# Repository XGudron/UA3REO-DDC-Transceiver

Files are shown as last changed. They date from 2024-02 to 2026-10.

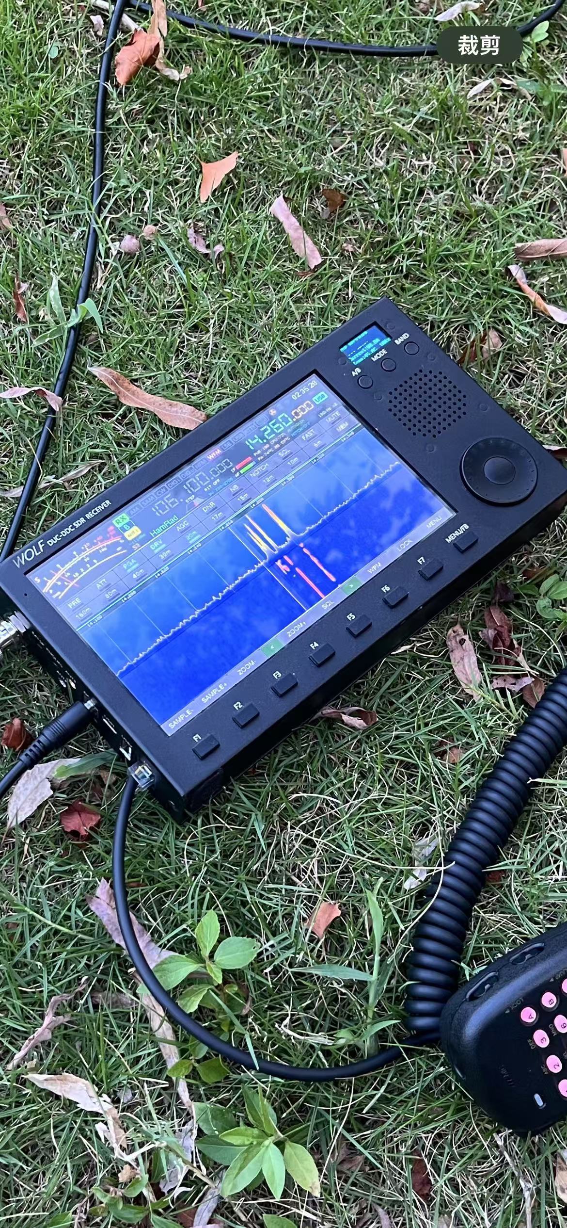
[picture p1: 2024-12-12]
Schematic/Wolf-DK102/Photos/20241206171248.jpg

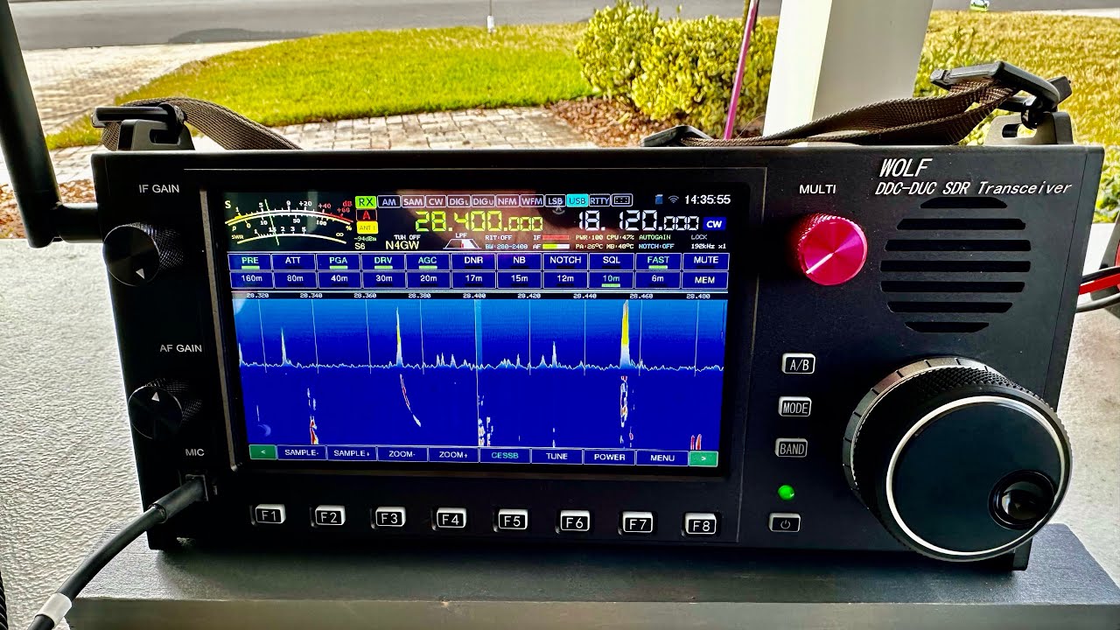
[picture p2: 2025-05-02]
Schematic/Wolf-BA7LJL/Photos/Wolf.jpg

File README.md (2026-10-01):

# Transceiver "Wolf"
DDC-DUC SDR Transceiver project https://ua3reo.ru/tag/transiver-ua3reo/

* Community telegram channel: https://t.me/TRX_Wolf
* На русском https://github.com/XGudron/UA3REO-DDC-Transceiver/blob/master/README.ru-RU.md

## Principle of operation

The RF signal is digitized by a high-speed ADC chip and fed to an FPGA processor. <br>
It performs DDC / DUC conversion (digital frequency shift down or up the spectrum) - by analogy with a direct conversion receiver. <br>
The I and Q quadrature signals from the conversions are fed to the STM32 microprocessor. <br>
It filters, (de) modulates and outputs audio to an audio codec / USB. It also handles the entire user interface. <br>
When transmitting, the process occurs in the opposite order, only at the end of the chain there is a DAC, which converts the digital signal back to analog RF. <br>

## Specifications TRX Wolf-2

* Receiving frequencies: 0 Mhz - 2700 Mhz, band filters for ham bands (23cm included)
* Transmission frequencies: 0 MHz - 2700 Mhz, amplifiers for ham bands (23cm included)
* TX power: 100W (HF), 50W+ (VHF/UHF), 15W+ (SHF)
* Two antenna inputs on HF, four for VHF/UHF/SHF/Wideband
* Automatic antenna tuner
* Modulation types (TX / RX): CW, LSB, USB, AM, FM, WFM, DIGI
* LNA, Preamplifier
* Adjustable attenuator 0-31dB
* Band pass filters
* ADC dynamic range (16 bit) ~100dB
* Supply voltage: 13.8V

## Specifications TRX Wolf-1

* Receiving frequencies: 0 MHz - 750 MHz with fading each 61.44 MHz (above 145 MHz - without input filters)
* Transmission frequencies: 0 MHz - 150 MHz with fading on 110 MHz
* TX power (QRP version): 7W+ (HF), 5W (VHF)
* TX power (QRP++ DB5AT version): 20W (HF), 7W (VHF)
* TX power (RU4PN/WF-100D version): 100W (HF), 50W+ (VHF)
* It is possible to install a VHF board from Wolf-2 to expand the VHF characteristics
* Two antenna inputs
* Modulation types (TX / RX): CW, LSB, USB, AM, FM, WFM, DIGI
* LNA, Preamplifier
* Adjustable attenuator 0-31dB
* Band pass filters
* ADC dynamic range (16 bit) ~100dB
* Supply voltage: 13.8V (overvoltage and polarity reversal protection)
* Consumption current when receiving: ~0.7A (3'2 QRP), 0.9A (7' BIG)
* Current consumption during transmission: ~2.5A+ (QRP), 15A+ (BIG)
* Support for different displays: RA8875/HX8357B/HX8357C/ST7789/ST7796S/ST7735S/ILI9341/ILI9481/ILI9486/ILI9488

## Transceiver Features

* Panorama (spectrum + waterfall) up to 384 kHz wide
* Panorama tweaks and themes
* Dual receiver (mixing A + B or A&B audio in stereo)
* Adjustable bandwidth: HPF from 0Hz to 2700Hz, LPF from 100Hz to 20kHz
* Integrated SWR/power meter
* SWR Graphs
* Spectrum analyzer
* Automatic and manual Notch filter
* Switchable AGC (AGC) with adjustable attack rate
* Range map, with the ability to automatically switch modes
* Digital Noise Reduction (DNR), Pulse Noise Reduction (NB)
* CAT virtual COM port (TS-2000 / FT-450 emulation, DTR - CW)
* USB operation (audio transmission, IQ, CAT, KEY, PTT)
* Self-control, CW gauss filter
* SSTV/RDS/CW decoder
* FT8/FT4/FT2 decoder/encoder
* RTTY/PSK31 decoder/encoder
* Sending a log of QSO and data to the log https://allqso.ru/ and https://www.wavelog.org/
* WSPR Beacon
* VOX / USB-VOX
* Equalizer TX/RX, reverber, various DSP compressors, etc.
* SSB/FM Scanner mode, fast switching between CW signals
* Support SDHC/SDSC/SDXC memory cards up to 16Gb
* WAV files radio recording and playback, broadcast recorded message
* AGC takes into account the characteristics of human hearing (K-Weighting)
* TCXO frequency stabilization (it is possible to use an external clock source, such as GPS)
* WiFi operation: Time synchronization, external WiFi services
* Tangent support Yaesu MH-48 and MH-36
* Hardware self-testing
* CTCSS subtones and 1750 kHz start tone for opening repeaters
* Assistance for visually impaired operators
* Digital Pre Distortion
* CW-trainer
* Support for external PTT-sequencer control via CAT and transceiver
* And other... (see menu)

### RF Parameters

Sensitivity at 10 dB SNR, LNA enabled:

* <150 MHz | -131 dBm | 63.0 nV
* 435 MHz | -121 dBm | 0.2 uV

Out-of-band emissions:

* 14 MHz -69 dBc
* 28 MHz -63 dBc
* 145 MHz -48 dBc -55 dBc

## Build

I ordered the boards in the Chinese service JLCPCB, they and their schemes are in the Scheme folder. <br>
After assembly, you need to flash FPGA and STM32 chips. <br>
If necessary, calibrate the transceiver through the appropriate menu <br>
WiFi module ESP-01 must have fresh firmware from Dropbox<br>

## Functional buttons

| Button | Short press | Long press |
|---|---|---|
| **A/B**, **XFC** | Select VFO A or B (XFC - while pressing) | Same |
| **A<>B**, **A / B** | Swap VFO A and B | Same |
| **B=A**, **A->B** | Copy active VFO to the other | Same |
| **SPLIT** | Toggle split | Same |
| **DOUBLE** | Toggle dual RX | Switch dual-RX mix: A&B stereo ↔ A+B |
| **POWER** | RF power window / menu | Toggle external PA mode |
| **CESSB** | Toggle CESSB | CESSB settings menu |
| **DPD** | Toggle digital pre-distortion | Same |
| **PRE** | Toggle LNA | Same |
| **ATT** | Toggle attenuator | Step ATT level (dB) |
| **NB** | Cycle NB: off → NB1 → NB2 → both | NB1/NB2 settings menu |
| **NOTCH** | Toggle auto notch | Manual notch |
| **DNR** | Cycle DNR type (0…3) | Same |
| **AGC** | Toggle AGC | Same |
| **FAST** | Toggle fast tuning | Same |
| **SQL** | Toggle squelch | Squelch level menu |
| **RIT** | Toggle RIT | XIT / Reset RIT |
| **XIT** | Toggle XIT | RIT / Reset XIT |
| **MONI** | Toggle self-hear | Self-hear settings for current mode |
| **VOX** | Toggle VOX | VOX settings |
| **SCAN** | Toggle scanner | Same |
| **AUTOGN** | Toggle auto RF gain | Same |
| **BANDMP** | Toggle band map | Same |
| **BAND− / BAND+** | Previous / next band | The same, but in reverse |
| **MODE− / MODE+** | Previous / next mode | The same, but in reverse |
| **FFT− / FFT+** | Narrower / wider panorama | Same |
| **HPF** | High-pass filter menu | Same |
| **BW** | RX filter bandwidth menu | Same |
| **LENS** | Toggle FFT zoom (lens) | Same |
| **FILT 1…3** | Load filter preset | Save current filters to preset |
| **BALANCE** | A/B audio balance menu | Same |
| **ANT** | Cycle TX/RX antenna | Same |
| **RXANT** | Toggle extra RX antenna (Wolf-2) | Same |
| **TUNE** | ATU enable | Tune / carrier |
| **ATU RST** | Reset ATU memory for band | Same |
| **SWR** | SWR analyzer for current band | Same |
| **REPIT** | Toggle repeater mode | Repeater offset menu |
| **BREAKIN** | Toggle CW break-in (key+PTT) | CW PTT type menu |
| **SNAP < / SNAP >** | Snap frequency to grid | Auto-snap on/off |
| **M>VFO / VFO>M** | Read memory channel (MEMO mode) | Same / write channel |
| **MEMORY** | Memory channels window | Same |
| **REC** | Start/stop SD recording | Same |
| **PLAY** | Play last recording | Transmit last recording on air |
| **FILES** | SD file manager | Same |
| **SERVICE** | Services menu | Save screenshot to SD |
| **MENU** | System menu | Close all / hidden menu |
| **LOCK** | Lock front panel | Same |
| **FT8** | FT8 service | Same |
| **WPM** | CW speed menu | Same |
| **PTT OFF** | Toggle TX inhibit | Same |
| **TX** | Soft PTT | Same |
| **ACCESS** | Speak frequency and mode (TTS) | Same |
| **EQ** | TX/RX equalizer window | Same |
| **SLEEP** | LCD sleep mode | Same |
| **DXCALL** | Correspondent / QSO info window | Same (touch models) |
| **CW KEYB** | CW/RTTY/PSK message broadcast window | Same |
| **MACROS 1…8** | Run CW/SSB/RTTY/PSK macro | Edit macro; long on Macro 1 — Auto CQ toggle |
| **NONE** | Not assigned | — |

Assignments are editable in *Settings → Front buttons*.

## Settings

### Operator

* **Accessibility** - Assistance to visually impaired operators, telegraphing current transceiver parameters into the speaker when switching
* **Callsign** - Operator callsign
* **Locator** - User QTH locator
* **Operator Name** - Operator name
* **QTH xxx** - Setting the Latitude\Longitude\Altitude of your location to calculate the passage of satellites
* **Timezone** - Time zone
* **Tropo Region** - Region for tropospheric forecast https://www.dxinfocentre.com/tropo.html 
* **URSI Code** - Ionogram URSI Code https://digisonde.com/index.html#stationmap-section

### TRX Settings

* **ANT type** - Select antenna type (TX/RX or RX only)
* **Band Map** - Band Map, automatically switches mode depending on the frequency
* **Beeper** - Beep on key press
* **Channel Mode** - Channel frequency mode (for LPD/PMR and etc.)
* **Custom Transverter** - Enable external transverter on non-ham band (just offset display frequency)
* **Debug Type** - Output of debug and service information to USB / UART ports
* **Debug Console** - Display console with system debug information (copy of what is sent to debug COM port)
* **Encoder Accelerate** - Accelerate encoder on fast rates
* **ENC2 Priority enbl** - Enables the encoder priority function, which is automatically switched to after 30 seconds of inactivity
* **ENC2 Priority** - Selection of the secondary encoder priority function
* **FAN Always on** - Forced activation of the fan (for heavy operating conditions)
* **Fine RIT Tune** - Fine or coarse tuning for RIT/XIT (encoder or resistor)
* **Freq Step xxx** - Frequency step by main encoder in each mode, Hz
* **FAST Step Multiplier** - Frequency step multiplier for FAST mode
* **ENC2 Step Mult** - Frequency step multiplier for ENC2 rotation (for CW/SSB)
* **Notch Step** - Frequency step of manual notch filter
* **Full Duplex** - Full duplex RX+TX mode
* **SPLIT type** - In DX mode - the TX frequency is controlled, in the CrossBand mode synchronously for two VFOs, for Free only the RX frequency changes
* **RIT Interval** - Offset range RIT (+ -)
* **XIT Interval** - Offset range XIT (+ -)
* **Lock in IQ Mode** - Lock TRX in IQ Mode for external program
* **Transverter XXcm** - Enable external ham band transverter support
* **Wolf Interface I2C** - Connect TRX to external I2C interface device (See STUFF folder for example)

### FILTERS Settings

* **Adaptive FM Filter** - Automatic adjustment of the width of the NFM filter relative to the strength of the received signal (VHF)
* **AM/FM/CW/SSB LPF Stages** - Adjusting the slopes of the LPF filters in different modes
* **CW LPF Pass** - LPF cutoff frequency when working in CW
* **CW Gauss filter** - Use a filter with a Gaussian distribution (for CW), accepts only the peak in the center of the BW
* **CW Gauss Q** - Quality of Gauss filter
* **DC Filter RX** - Enable DC corrector filter on receive path (cuts off the constant component and part of the low frequencies)
* **DC Filter TX** - Enable DC corrector filter on transmit path (cuts off the constant component and part of the low frequencies)
* **DeEmphasis FM, us** - Setting up a filter to reduce high-frequency noise when receiving NFM/WFM
* **DIGI LPF Pass** - LPF cutoff frequency when working in DIGI
* **FM LPF Pass** - LPF cutoff frequency when working in FM
* **SSB HPF Pass** - HPF cutoff frequency when operating in SSB
* **SSB LPF Pass** - LPF cutoff frequency when operating in SSB
* **NOTCH Filter width** - Cutting width of Manual Notch filter
* **RX Filter Margin** - Filter width relative to carrier signal frequencies

### RX Settings

* **ADC Dither** - Enable ADC dither for receiving weak signals
* **ADC Driver** - Turn on the preamplifier-ADC driver
* **ADC Preamp** - Turn on the preamplifier built into the ADC
* **ADC Randomizer** - Enables ADC digital line encryption
* **AGC Gain target, LKFS** - Maximum AGC gain (Maximum volume with AGC on)
* **AGC Threshold** - Enabling the AGC opening threshold
* **Att step, dB** - Attenuator tuning step
* **Attenuation, dB** - Current attenuation
* **Auto Snap** - Automatically track and snap to near signal frequency (CW mode)
* **AutoGainer** - Automatic ATT / PREAMP control depending on the signal level on the ADC
* **CODEC Gain** - Adjusting AF gain in audio codec
* **Dual RX** - Activating the dual receiver
* **Dual RX Balance** - Channels balance in dual RX modes
* **Dual RX Type** - Dual receiver signal mixing type: A+B, A&B, A Only, B Only
* **Dual RX IQ** - Specifies the source (VFO) of the IQ signal to send to the USB audio card in Dual RX mode
* **DNR xxx** - Digital squelch adjustment
* **Squelch** - Enable SSB/AM/CW/FM Squelch
* **FM Demodulator** - Algorithm of FM demodulator operation
* **FM Squelch level** - FM squelch level
* **IF Gain, dB** - IF gain
* **Noise Blanker** - Activating the Surge Suppressor
* **NB Threshold** - Threshold of Noise blanker
* **Free tune** - Allows you to move the reception frequency across the spectrum without changing the center frequency of the spectrum itself
* **Center After Idle** - Center the spectrum with Free Tune active after 20 seconds of inactivity
* **RX AUDIO Mode** - Audio lines control: Stereo\Left\Right
* **RX AGC Hold time** - Time before release of AGC gain in signal peaks, ms
* **RX AGC Hold limit** - Burst limit for AGC delay time
* **RX AGC Hold step up** - AGC Delay Time Step on Peaks
* **RX AGC Hold step down** - AGC Delay Falloff Step at Peaks
* **RX AGC Max gain** - Limit of AGC gain, dB
* **RX AGC Speed** - AGC (automatic signal level control) response speed for reception (more-faster)
* **TRX Samplerate** - Max FFT/samplerate on SSB/DIGI/etc modes
* **FM Samplerate** - Max FFT/samplerate on NFM/WFM mode
* **CW Samplerate** - Max FFT/samplerate on CW mode
* **VAD SQL Threshold** - VAD voice detector threshold (noise SQL for SSB mode and SCAN mode)
* **Volume step** - AF gain step by ENC2 (X1, Lite)
* **Volume** - AF gain
* **WFM Stereo** - select WFM stereo or mono decoder
* **WFM Stereo Modulation** - Stereo FM sub-carrier level

### TX Settings

* **ADC Shutdown** - Turn off the ADC while TX
* **AGC MaxGain** - Maximum AGC gain
* **AGC Speed** - TX compressor response speed for transmission (more-faster)
* **TX AGC Clipping** - Determines whether the AGC will sharply limit the signal gain during large amplitude spikes
* **TUNER Enabled** - Turning on the antenna tuner
* **TUNER Enbl per band** - Save tuner on/off state for each band independently
* **ATU Cap** - Tuner Capacitance Combination
* **ATU Enabled** - Turning on the automatic antenna tuner
* **ATU Ind** - Combination of tuner inductances
* **ATU T** - Tuner capacitive arm position
* **ATU Mem step, kHz** - Step of saving tuner values for frequencies into memory
* **ATU AutoRun** - Automatic ATU start at high SWR
* **CESSB** - Enable controlled-envelope single-sideband modulation
* **CESSB Compress, dB** - Signal pre-amplification level before compression in CESSB
* **CTCSS Frequency** - Transmit FM CTCSS sub-tone frequency
* **DRV Shutdown** - Turn off the DAC driver while RX
* **EXT PA mode** - Operating mode with external amplifier, separately installed RF Gain calibrations are used
* **EXT PTT in PA mode** - Send PTT signal to External connector only in "EXT PA mode"
* **INT ATU in PA mode** - Determines whether to enable the internal tuner in "EXT PA Mode"
* **EXT ATU in PA mode** - Determines whether to block the external PA while the external ATU is being tuned
* **Input Auto Switch** - Auto input switch (PTT - mix, CAT - USB)
* **Input Type** - Select audio input (microphone, line in, USB)
* **LINE Gain** - Line input codec gain
* **MIC Boost** - +20db hardware mic amplifier
* **MIC Gain** - Microphone gain
* **MIC DSP Type** - Type of DSP processing of the microphone path: None, Downward Expander, Upward/Downward Compressor, Limiter, Noise Gate
* **MIC DSP Threshold** - Threshold of selected microphone DSP processing
* **MIC DSP Ratio** - Level of slope for selected microphone DSP processing
* **MIC Reverber** - Microphone reverberator level
* **Power for each band** - Save power settings for each band individually
* **Power for each mode** - Save power settings for each mode individually
* **RF Power** - Transmission power, %
* **RF Power ENC3 step** - Power adjustment step by encoder (Wolf-2)
* **Pwr by main ENC** - Allow power change by main encoder in TX mode
* **Repeater Mode"** -  Operation mode via repeater
* **Repeater offset, kHz** -  Transmission frequency offset in repeater mode
* **Repeater tone** - Adds 1750Hz tone at the beginning of transmission to open the repeater (in FM mode)
* **SelfHear CW** - Self-control CW Gain
* **SelfHear on SSB** - Self-monitoring for SSB/AM modes, always active for DIGI/RTTY/LOOPBACK
* **SelfHear VOICE** - Self Hearing volume at voice modes relative to the overall transceiver volume
* **SelfHear DIGI** - Self Hearing volume at DIGI modes relative to the overall transceiver volume
* **SWR Hold Peaks** - Hold the power meter at signal power peaks
* **Tune Type** - TUNE operating mode (carrier, two signal tone, multi-tone, white noise)
* **TOT, min** - Protection of the transmitter from long-term operation, automatic shutdown after time has elapsed
* **TX Inhibit** - Prohibit switching to TX
* **Use Keyer for RTTY** - Enable use of CW key (or USB-COM line of keyer) for keying in RTTY mode
* **VOX** - TX Voice activation
* **VOX Threshold, dBFS** - VOX Threshold, dBFS
* **VOX Timeout, ms** - VOX transmission delay after silence, milliseconds
* **USB VOX** - Activating TX when transmitting sound to a USB audio card

### CW Settings

* **Adaptive Line Ench** - Adaptive Line Enhancer - extracts a weak CW tone out of noise; works in CW mode, most effective at low SNR
* **Auto CW Mode** - Automatic switching to CW mode when pressing the key, or only manipulation during transmission
* **DotToDash Rate** - Keyer dash to dot length rate
* **Debounce Rate** - The response threshold of the CW key anti-bounce system relative to the dot length
* **Edges smooth, ms** - Smoothing signal edges
* **Iambic Keyer** - Enable Iambic mode keyer
* **Iambic Type** - Type of Iambic keyer (A/B)
* **Key Invert** - Invert dash/dot on key
* **Key timeout** - Time before stopping the transmission mode after releasing the key
* **Keyer** - Automatic Key
* **Keyer Memory** - Keyer memory for one symbol for transmit
* **Keyer WPM** - Key Speed, WPM
* **Mode** - Sideband Type CW-LSB / CW-USB
* **CW PTT Type** - RX/TX switch type for CW: by key or external PTT (tangent, etc.)
* **Pitch** - Detuning the receiver generator from the transmit frequency
* **Stereo** - Splitting the CW bandwidth into headphone channels (audio panorama)
* **Self Hear** - Self-control CW (key press is heard)

### Macros

* **AutoCQ Macros 1** - Auto-call CQ macro CW/SSB/RTTY at specified interval
* **CW Macros x** - Setting up macros for CW transmission
* **CW Macros x name** - Setting the CW-macro name to be displayed in the interface
* **SSB Macros x name** - Setting the SSB-macro name to be displayed in the interface

Allowed insertions in macros:

* {MYCALL} - Operator callsign
* {DXCALL} - Correspondent callsign
* {MYNAME} - Operator name
* {MYLOC} - Operator locator
* {CLRDX} - Clear correspondent callsign

### Equalizer Settings

* **Add 2nd harmonics** - Artificial addition of 2nd order harmonics to the receiver's low-frequency signal to simulate the nonlinearity of the analog path
* **Add 3rd harmonics** - Artificial addition of 3rd order harmonics to the receiver's low-frequency signal to simulate the nonlinearity of the analog path
* **Add Asymmetry** - Artificial addition of asymmetry to the receiver's low-frequency signal to simulate the nonlinearity of the analog path
* **Pseudo stereo** - RX path pseudo-stereophony mode
* **RX EQ xxx** - Receiver equalizer levels
* **MIC EQ xxx** - Microphone equalizer levels
* **EQ Q xxx** - The quality factor of each equalizer channel

### SCREEN Settings

* **Language** - Select interface language
* **AF Monitor** - Display of the AF (audio) signal in frequency and time domains under the waterfall. Off - disabled, TX Only - during transmission, Always - continuously on RX and TX
* **AF Monitor Time** - Time-domain window length for AF Monitor
* **Bottom navi buttons** - Show bottom menu navigation buttons (for 7 inch displays)
* **Color Theme** - Select colors theme (0 - black, 1 - white, 2 - black with colored frequency)
* **Layout Theme** - Select interface theme (0 - default)
* **Dual FFT** - Splits the spectrum and waterfall into two windows: the top one shows VFO-A, the bottom one VFO-B (works with Dual RX enabled). Each window has its own BandMap, frequency labels and AGC indicator
* **FFT 3D Mode** - Enable FFT 3D mode (0 - disabled, 1 - lines, 2 - pixels)
* **FFT 3D Slides** - Number of 3D FFT slides to display spectrum history
* **FFT 3D X Offset** - Adjusting 3D FFT Perspective in X
* **FFT 3D Y Offset** - Adjusting 3D FFT Perspective in Y
* **FFT Automatic** - Automatic FFT scale
* **FFT Averaging** - FFT burst averaging level. Full - automatic selection of upper and lower boundaries, Half - auto lower and manual upper, No - manual setting of the range of spectrum levels. (Remember to select the correct FFT Scale Type so that your range will fit on the screen)
* **FFT BW Style** - FFT bandwidth style: high opacity, low opacity, lines
* **FFT BW Position** - Position of the receiving band on FFT/WTF (everywhere \ at the top \ at the top + lines \ top + bottom with time delay)
* **FFT Background** - Gradient FFT background
* **FFT Color** - FFT colors: 1(blue -> yellow -> red), 2(black -> yellow -> red), 3(black -> yellow -> green), 4(black -> red), 5(black -> green), 6(black -> blue), 7(black -> white)
* **FFT Compressor** - Enable FFT peak comressor
* **DX Cluster Type** - Selecting a Data Source for a DX Cluster (RBN, DXSummit, Telnet)
* **FFT DXCluster** - Show DXCluster info over FFT
* **FFT DXCluster Azimuth** - Add azimuth data to DX-cluster
* **FFT DXCluster Timeout** - Timeout of DX-cluster spots in minutes
* **TELNET Cluster Host** - Telnet server address for DX cluster
* **TELNET Cluster Port** - Telnet server port for DX cluster
* **Cluster Mask** - Cluster spot filtering by callsign mask: * - any count of characters, ? - any one character, numbers-letters - full match. For example "?A3R*"
* **WOLF Cluster** - Display Wolf TRX users on spectrum and send self data
* **WOLF Cluster Models** - Enables display of user transceiver models in the wolf cluster
* **FFT Enabled** - Enable waterfall and FFT
* **FFT Freq Grid** - FFT and waterfall grids: 1(no grid), 2(fft grid), 3(fft+wtf grids), 4(wtf grid)
* **FFT Height** - FFT and waterfall proportional height
* **FFT Hold Peaks** - Show peaks on FFT spectrum
* **FFT Lens** - Enable FFT lens mode (magnify center of spectrum)
* **FFT Manual Bottom, dBm** - Bottom FFT threshold in manual mode
* **FFT Manual Top, dBm** - Top FFT threshold in manual mode
* **FFT Measurements** - Display various spectrum measurements on the waterfall (noise spectral density, SNR, etc.)
* **FFT Scale Type** - Y-axis style on FFT between signal amplitude and dBm to fit more dynamic range on screen (Useful when manually adjusting FFT range).
* **FFT Sensitivity** - Top threshold of FFT sensitivity in automatic mode (30 - scale to strongest signal)
* **FFT Speed** - FFT and waterfall speed
* **FFT Style** - FFT style: 1(gradient), 2(fill), 3(dots), 4(contour), 5(gradient + contour)
* **FFT Window** - Select FFT window function
* **FFT dBm Grid** - FFT signal power grid
* **LCD Brightness** - Set LCD brightness (not all lcd support)
* **LCD Sleep Timeout** - Idle time before the screen brightness decreases, sec (0 - disabled)
* **S-Meter style** - Selecting layout of the analog S-Meter
* **S-Meter smooth** - Smoothing coefficient of the S-meter value
* **Show Sec VFO** - Show secondary VFO position on spectrum
* **WTF Color** - Waterfall colors: 1(blue -> yellow -> red), 2(black -> yellow -> red), 3(black -> yellow -> green), 4(black -> red), 5(black -> green), 6(black -> blue), 7(black -> white)
* **WTF Moving** - Mowe waterfall with frequency changing

### Decoders
* **CW Decoder** - Software CW receive decoder
* **CW Decoder Threshold** - CW receive decoder sensivity
* **CW Multi-Decoding** - Multiple signal decoding mode in the visible bandwidth
* **FTx Auto CQ** - Automatic transition to CQ mode after FT8/FT4/FT2 communication
* **FTx Auto Frequency** - When enabled (default), switches to the standard FT8/FT4/FT2 dial frequency for the current band on decoder start; when disabled, the decoder runs on the current transceiver frequency
* **FTx Freq** - Selected transmission frequency
* **FTx Correct time** - Allows you to adjust the time on the transceiver by calculating the average deviation from the FT8/FT4/FT2 decodes
* **PSK31 Freq** - Carrier center frequency for PSK decoder/encoder
* **RDS Decoder** - Enable RDS Decoder for WFM mode
* **RTTY Freq** - Central frequency of RTTY decoding
* **RTTY InvertBits** - RTTY invert 0 and 1 bits
* **RTTY Shift** - RTTY carrier shifts
* **RTTY Speed** - Speed of RTTY data
* **RTTY StopBits** - RTTY Stop bits
* **SSTV Decoder** - Launching SSTV decoder (PD 50/90/120/180, Scottie 1/2, Martin 1/2)

### WIFI Settings

* **WIFI Enabled** - Enable WiFi module (need restart after enable)
* **WIFI Network** - WiFi hotspot selection
* **WIFI Network Pass** - Set password for WiFi hotspot
* **WIFI NTP Server** - Selecting the NTP time synchronization server address
* **ALLQSO.RU Token/LogId** - Token and LogID from https://allqso.ru/ web-log
* **Wavelog** - Integration settings with https://www.wavelog.org/ web-log

### SD Card

* **File Manager** - Show SD Card file manager, support WAV playback and deleting files, listening and broadcasting recordings, as well as updating firmware from a memory card
* **Profile Names** - Custom profile labels (up to 3 characters) for export/import settings and calibration buttons
* **Export Settings** - Export settings and calibration data to SD card
* **Import Settings** - Import settings and calibration data from SD card
* **Format SD card** - Format media drive
* **Use FLASH as SD** - Use SPI FLASH as a small, slow SD card. Remember to format it before use. Not intended for audio recording.
* **USB SD Card Reader** - Enable USB SD Card reader

### Satellites

* **SAT Mode** - Enable satellite mode
* **Auto Doppler** - Automatically shifts the transceiver frequency based on the calculated Doppler effect
* **Calc Pass** - Calculate future satellite passes over QTH (Local time)
* **Download TLE** - Download current satellite data
* **EME Info** - Moon position and EME path parameters for your QTH (see [EME Info](#eme-info))
* **Select SAT** - Select a satellite from the downloaded TLE file

### EME Info

Information screen for Earth-Moon-Earth (EME) operation, similar to the Astronomical Data window in WSJT-X (but slightly simplified mathematically). Calculations use the current QTH coordinates (Operator settings) and the active VFO frequency; they do not depend on the satellite selected in **Select SAT**.

* **MoonAz** - Horizontal direction to the Moon at your location, in degrees
* **MoonEl** - Vertical angle of the Moon above the horizon at your location, in degrees
* **SelfDop (Self-Doppler Shift)** - Two-way Doppler shift of your own EME echo (TX → Moon → RX)
* **Width (Doppler Spread / Libration Fading)** - The spectral broadening (fuzziness) of your returned signal caused by lunar libration
* **Delay (Round-Trip Time)** - The exact time it took for your radio wave to travel from your antenna to the moon and back
* **Dec** - Topocentric declination of the moon, in degrees
* **SunAz** - Azimuth of the Sun at your location, in degrees
* **SunEl** - Elevation of the Sun above the horizon at your location, in degrees
* **Tsky** - Estimated sky background temperature in the direction of the moon, scaled to the operating frequency (shown from 5 MHz and above)
* **Dpol** - Spatial polarization offset, in degrees; difference between your station and the DX station when **DX Call** is set and recognized
* **Dist** - Topocentric distance from your station to the moon, in km
* **Dgrd** - Estimated signal degradation in dB relative to the best possible path (moon at perigee, cold sky)

The following fields are shown **only when DX Call is set** (correspondent callsign from the **DXCALL**):

* **DX Call** - Correspondent callsign used for DX path calculations
* **DX Loc** - Maidenhead locator derived from the DX station coordinates
* **DxAz** - Azimuth to the Moon at the DX station, in degrees
* **DxEl** - Elevation of the Moon at the DX station, in degrees
* **DxDop** - One-way Doppler shift at the DX station, in Hz
* **DxWid** - Limb-to-limb Doppler spread at the DX station, in Hz
* **MNR** - Maximum non-reciprocity of the EME path in dB due to spatial polarization

### Calibration [appears by long pressing the MENU button in the settings menu]

### Calibration Bands
* **ENABLE 2200m/60m/6m/4m/FM/2m/AIR/Marine Band/70cm** - Enable hidden bands
* **NOTX xxx** - Disable TX on selected bands

### Calibration Control
* **CAT Type** - Type of CAT subsystem (FT-450 / TS-2000)
* **CAT Transverters IF** - When using a transverter, send to CAT the IF frequency or the VFO frequency
* **COM CAT DTR/RTS** - Configuring the functions of the DTR/RTS control lines of the CAT port
* **Second COM Mode** - Select the operating mode of the secondary COM port (debugging, CAT, CW/RTTY DATA, ESP module brigde)
* **SEC COM DTR/RTS** - Configuring the functions of the DTR/RTS control lines of the Debug port
* **FAN Full start** - Temperature of the PA for starting the fan at full speed
* **FAN Medium start** - Temperature of the PA for starting the fan at medium speed
* **FAN Medium stop** - Temperature of the PA for stopping the fan
* **FAN MB ---** - STM32 Temperature fan enable settings
* **FAN Medium PWM** - Adjusting the duty cycle of a PWM fan in Medium mode
* **FAN Motherboard** - Starting the fan not only by the sensor, but also by the temperature of the STM32 processor
* **IF Gain MIN/MAX** - IF Gain adjusting limits
* **Inhibit VOX Button** - Disable the hardware VOX button
* **Min Voltage protect** - Minimum supply voltage threshold, below which the protection will be triggered and the transceiver will be switched off (INA226)
* **OTA Update** - Enable OTA firmware update over WiFi

### Calibration Hardware
* **RF-Unit Type** - RF-Unit Type (QRP / BIG)
* **ADC Driver Gain** - Setting the ADC driver gain (depending on the one installed on the board), dB
* **ADC Offset** - Additional virtual offset to ADC signal
* **ALC Port Enabled** - Activation of transceiver power control by an external amplifier via the ALC line: up to 1 volt - ALC is disabled and the power set in the transceiver is used. from 1.0v to 3.0v - power adjustment from 0 to 100%
* **ALC Inverted** - Invert ALC logic (3.0v - 0%, 1.0v - 100%)
* **BPF x** - Bandpass filter parameters
* **HPF START** - HPF filter parameters
* **LPF END** - LPF filter parameters
* **DAC Dither** - Adds TPDF dither noise (~±1 LSB) before the DAC quantizer, decorrelating quantization spurs into broadband noise
* **DAC Driver Mode** - DAC Driver OPA2673 bias mode (2 = 100% bias, 1 = 75% bias, 0 = 50% bias)
* **DAC Interpolation** - Using interpolation in the first DAC frequency zone (HF)
* **DAC Rounding** - Convergent (round-half-to-even) rounding of the DAC quantizer instead of truncation
* **EXT xxx** - External port control by band (EXT3, EXT2, EXT1, EXT0) - open drain
* **External ATT** - Connecting control for an external attenuator 3-6-12 dB (Wolf-2)
* **Encoder acceleration** - The encoder acceleration on faster rotation speeds
* **Encoder debounce** - Time of debouncing contacts of the main encoder
* **Encoder invert** - Invert the rotation of the main encoder
* **Encoder on falling** - The encoder is triggered only when level A falls
* **Encoder slow rate** - Deceleration rate of the main encoder
* **Encoder2 debounce** - Time of debouncing contacts of the additional encoder
* **Encoder2 invert** - Invert the rotation of the additional encoder
* **Encoder2 on fall** - Mode of operation of the secondary encoder (some encoders skip a step or make an extra one)
* **Flash GT911** - Starting the touchpad update procedure according to LCD screen resolution
* **INA226** - Activation and calibration of the INA226 voltage/current sensor on the I2C bus
* **Invert LCD PWM** - Inverting the PWM backlight of the RA8875 screen
* **KTY81 Calibration** - Calibration of the KTY81 sensor (setting the resistance of the divider arm)
* **LCD Rotate** - Rotate screen at 180 degrees
* **LPF Timeout** - Disable TX LPF after 3 minutes of switching to RX
* **MAX ChargePump, kHz** - Maximum PWM frequency for ChargePump circuit
* **Mute AF AMP on TX** - Turn off the transceiver's low frequency amplifier during transmission (if there is no self-monitoring)
* **RTC COARSE CALIBR** - Very coarse clock crystal calibration
* **RTC FINE CALIBR** - Clock crystal calibration, one division is 0.954 ppm
* **Sequencer support** - External sequencer support (output through line EXT_TUNE)
* **Swap AF & IF** - Swap AF Gain & IF Gain resistors
* **TCXO Frequency, kHz** - Frequency adjustment of the reference oscillator
* **VCXO Correction** - Correction for main generator frequency offset
* **Touchpad flip** - Flip the touchpad operation horizontally/vertically
* **Touchpad timeout** - Minimum time between taps (protection against false trigger), ms
* **Touchpad click threshold** - Minimum time for triggering a short click, ms
* **Touchpad click timeout** - Maximum time for triggering a short click, ms
* **Touchpad hold timeout** - Time before a long press is triggered, ms
* **Touchpad swipe threshold** - Minimum distance to trigger a swipe, px
* **Touchpad Offset X/Y** - Allows you to set an offset for the touchpad's click point (when working at an angle to the screen or due to hardware issues)
* **Tangent Type** - Select tangent type
* **Transverter Offset, MHz** - Offset frequency shown on the display (for custom transverters)
* **Transverter xxx IF, MHz** - Setting the IF frequency of the transverter
* **Transverter xxx RF, MHz** - Setting the RF frequency of the transceiver to match the IF
* **Transv only TX** - Use transverter only for TX
* **VBAT Rechargable** - Enable battery charging if installed instead of the non-rechargable battery
* **VHF Mixer Board** - Enable VHF board with RF mixer support
* **VHF Mixer IF, MHz** - Select IF frequency for VHF board mixer
* **VHF Mixer Current** - Selecting the mixer current level
* **VHF TCXO, kHz** - Select TCXO frequency for VHF board
* **VHF TCXO Correction** - Correction for VHF board TCXO generator frequency offset
* **VHF Path for HF Trsv"** - Enabling the VHF path on the motherboard when using transverters with HF IF (Wolf-2)

### Calibration RF Power
* **DAC Max Boost M1/2*** - Allows the DAC to reach maximum output power in two operating modes. Mode 2 is used in the 46-65 MHz range, Mode 1 in all other ranges. Use with caution and avoid overloading the W2 VHF board / HF drivers. Do not switch when in active TX
* **Power Control** - Specifies how the DAC signal level changes when adjusting the RF Power %: changing the power or changing the signal amplitude
* **Sigmoid coeff** - Slope of the power control curve in Power Control mode = Sigmoid
* **Use Power table** - Use the correction table to accurately set the % of the maximum amplifier power, taking into account its nonlinearity (table calibration is performed in the service menu "Auto calibration" -> "Calibrate PWR %")
* **MAX Power in TUNE** - Maximum RF power in Tune mode
* **SD TX Macros Level** - Signal gain coefficient when transmitting SSB macros (percent, 1 = 100%)
* **SD TX Record Level** - Signal gain coefficient when transmitting live recordings (percent, 1 = 100%)
* **SD Input Record Level** - The recording level of your own signal on the memory card during transmission / macros SSB recording (percent, 1 = 100%)
* **SSB Power addition** - Addition of RF power in SSB power, %
* **RF GAIN xxx** - Calibration of the maximum TX output power for each range (DAC Amplitude)
* **PA RF GAIN xxx** - Analogue of RF GAIN, but for operation with an external amplifier (EXT PA Mode)

### Calibration RX
* **ATT Compensation** - Compensates the S-meter value when the ATT is turned on
* **LNA Compensation** - Compensates the S-meter value when the LNA is turned on, dBm
* **CICCOMP Shift** - Bit shift after CIC compensator
* **S METER** - S-meter calibration  (LHF 160/80, MHF 40/30/20/17, HHF 15/12/10, 6M, VHF, SHF)
* **Swap USB IQ** - Swap USB IQ output

### Calibration TX
* **AM Modulation Index** - Set TX AM Modulation Scale
* **ATU Averaging** - The number of steps of averaging SWR values during measurements in the operation of an automatic tuner
* **FM Deviation Scale** - Set TX FM Deviation Scale
* **MAX PWR Meter** - Maximum RF power (for indication)
* **MAX RF Temp** - Maximum temperature of the PA before the protection operation
* **MAX SWR** - Maximum VSWR before protection operation
* **Max Current, Amp** - Current protection, turns off transmission when the threshold is reached
* **SWR FWD/BWD RATE** - Adjustment of the transformation ratio of the SWR meter (forward / return)
* **SWR ISO RATE** - Adjusting the compensation factor for poor isolation of a SWR meter when the forward wave leaks into the reverse
* **SWR Protector** - SWR protection mode selection: Off, low power, transmission off
* **TSignal Balance** - Sets the power balance between signals in Two signal tune mode
* **TX Start Delay** - Delay before the RF signal is applied (ms), so that the relay has time to trigger
* **TX End Delay** - Delay when switching from TX to RX (stopping the signal until the relay turns off)

### Calibration Reset
* **Settings reset** - Reset all settings to defaults
* **Calibrate reset** - Reset all calibrations to defaults
* **Personal reset** - Reset all personal and WiFi setitngs to defaults

### Memory Channels

* Changing names for transceiver memory channels

### Set Clock Time

* Clock setting

### DFU Mode

* Launch STM32 USB firmware update over DFU mode

### System info

* Show info about TRX

## Services

### Spectrum Analyzer

* **Spectrum START** - Start the spectrum analyzer
* **Begin, kHz** - Starting frequency of the analyzer with a step of 1 kHz
* **End, kHz** - End frequency of the analyzer in 1 kHz steps
* **Top, dBm** - Upper threshold of the graph
* **Bottom, dBm** - Lower threshold of the graph

### WSPR Beacon

* **WSPR Beacon START** - Start WSPR beacon
* **Freq offset** - Offset from center of WSPR band
* **WSPR Power, W** - Sets the target power
* **WSPR Skip Cycles** - Skipping cycles after each transmission session
* **WSPR Band xxx** - Select bands to WSPR beacon

### Efficiency

* **Cable Type** - Selecting the cable used in the antenna-feeder device
* **Cable Length** - Cable length from transceiver to antenna
* **Calc Efficiency** - Starting the efficiency calculation. To calculate, you need to turn off the tuner (to know the SWR of the antenna-feeder device) and apply the RF carrier

### DX Cluster 

* Show DX Cluster info by current band (from internet)

### WOLF Cluster 

Displays information about radio amateurs currently in the current band using "Wolf" transceivers (internet connection required)

### Propagation 

* **foF2** - Displaying the foF2 frequency map (from internet)
* **Propagation Data** - Show propagation statistics (from internet)
* **Tropo** - Show tropospheric forecast (from internet)
* **Ionogram** - * Displaying the ionogram for the selected URSI Code (from internet)
* **VOACAP Map** - HF propagation map for the current band and QTH (requires internet connection)

### DayNight Map 

* Displaying the day/night terminator on the map (from internet)

### SWR Analyzer

* Run SWR analyzer (Band SWR - on current band, HF SWR - on all HF bands, Custom SWR - in selected range)

### RDA Statistics 

* Print statistics from RDA award (from internet)

### FT2

* FT2 Receiver / transmitter (accelerated FT4, 3.75 s T/R)

### FT4

* FT4 Receiver / transmitter

### FT8

* FT8 Receiver / transmitter

### Locator Info

* Calculate distance and azimuth from QTH-locator

### Callsign Info

* Show callsign data

### Time Beacons

* List of beacons of the exact time (for adjusting the frequency of reception by carrier)

### Touchpad Test

* Touchpad test: Draws a canvas where you can test one- and two-finger taps

### Self Test

* Run hardware self diagnostic

### CW Trainer

* **Check sending skill** - Should transmission skills be checked after receiving each line?
* **CW Trainer Letters** - Letter reception training
* **CW Trainer Numbers** - Training in receiving numbers
* **CW Trainer Mixed** - Letter + number receiving training

### Auto calibration

* **Calibrate SWR** - Assistant in measuring SWR and power meter
* **Calibrate RF GAIN** - Assistant in adjusting RF Power output
* **Calibrate PWR %** - Assistant for setting up the correction table, for precise setting of the % output power taking into account the nonlinearity of the gain (for the Use Power table function/calibration)
* **ATU Runner** - Assistant for setting up an automatic tuner, runs through all enabled bands / sections and performs tuning
* **Pre-Distortion** - Digital pre-distortion settings

#### Pre-Distortion

* **DPD Enabled** - Activation of the digital pre-distortion system
* **DPD Calibration** - Starts DPD calibration for the current bend
* **DPD Reset** - Resets calibration coefficients for the current bend
* **Draw chart** - Display a graph of applied distortion in amplitude and phase

* The function is experimental, be sure to check your signal on the control receiver after calibration
* DPD is designed to create an artificially distorted signal that, after passing through the PA, compensates for its non-linearities. In this regard, the IMD3 and IMD5 of the final signal decrease.
* Calibration takes approximately 30 seconds
* Calibration can produce excellent results between attempts, it is always worth monitoring the result and repeating if the required parameters have not been achieved
* After resetting the coefficients, DPD has no effect, it is useful if you need to disable DPD for part of the bands, but not disable the entire system
* Do not allow high SWR and overload of the ADC during calibration. If necessary, use an attenuator and a feedback circuit from the PA output to the RX input
* If you change the PA settings (quiescent current, swing power), you must perform the calibration again
* Weak growth of IMD7 and higher orders is possible due to compensation of IMD3/5
* The result depends on the types of PA nonlinearity, on a high level of RF Gain calibrations, and on the quality of feedback (a 50db+ attenuator between the PA output and the RX input is preferable to capacitive coupling inside the transceiver)

### Web Skimmers 

* **Pskreporter** - View skimmers that have received your DIGI signal (requires internet connection)
* **ReverseBeacon** - View skimmers that have received your CW signal (requires internet connection)
* **WSPRnet** - View skimmers that have received your WSPR signal (requires internet connection)

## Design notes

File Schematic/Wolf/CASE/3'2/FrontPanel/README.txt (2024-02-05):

Original_by_BG6QBT.json - "оригинальный" файл для EasyEda от BG6QBT, с которого рисовалась панель. 
image.jpg - картинка с изображением панели
Остальные файлы, имена которых начинаются на Gerber - собственно, гербер-файлы для размещения заказов на изготовление.

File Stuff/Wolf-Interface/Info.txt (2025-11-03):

Интерфейс предназначен для создания пользовательских устройств,
имеющих высокую степень интеграции с трансивером "Волк" Интерфейс подключается к I2C шине трансивера вместо программатора STM32 (Линия SCK подключена к SWDIO, линия SDA к SWO)
В данном примере используется плата ESP32, подсоединенная к 21 ноге(сигнал SDA) и 22(сигнал SCK) со стороны ESP32

Со стороны трансивера требуется включение опции Menu->TRX Settings->Wolf Interface I2C

В данный момент поддерживается: 
1. Синхронизация основных параметров трансивера(частота, мода, TX / RX) 
2. Выполнение и получение ответа по любой поддерживаемой CAT комманде
3. Вывод сообщения на экран трансивера

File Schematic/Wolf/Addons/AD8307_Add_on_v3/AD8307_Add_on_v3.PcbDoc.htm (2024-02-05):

Altium Reporting Options

# File in Newer Format

Date | : | 04-Dec-20
Time | : | 18:56:06
Filename | : | C:\Tisho\MyProjects\SDR_Transciever\UA3REO-DDC\Tisho_Files\Boards\AD8307_Add_on_v2\AD8307_Add_on_v2.PcbDoc

Version | Warning
Release 10 | CAUTION - New Custom Grids and Guides were introduced. Be aware that your design might contain Custom Grids and Guides that cannot be read in previous versions.
Release 10 | CAUTION - New Structured Clusters were introduced. Be aware that your design might contain Structured Clusters that cannot be read in previous versions.
Release 10 | CAUTION - New PCB 3D Movie Manager was introduced. Be aware that your design might contain 3D PCB movie that cannot be read in previous versions.
Release 10 update 1 | CAUTION - New Clearance Rule subscopes targeting differential pairs were introduced. Be aware that your design might contain Clearance Rules using those subscopes that cannot be read in previous versions.
Release 10 update 15 | CAUTION - Support of Solder Mask and Paste Mask expansions for Tracks, Arcs, Fills and Regions was introduced. Be aware that your design might contain Solder Mask and Paste Mask expansions for these types of primitives that cannot be read in the version of Altium Designer you are currently using.
Release 12 | CAUTION - Air Gap Width previously controlled by Clearance rule is now controlled by Polygon Connect Style rule's newly introduced Air Gap Width (set to default value). Suggest reviewing each Polygon Connect Style rule's Air Gap Width attribute for correctness.
Release 13 | CAUTION - Silk To Solder Mask Clearance Rules are converted to Silkscreen Over Component Pads Rules.
Release 14 | CAUTION - The Differential Pairs Routing rule added support for control of the width. Be aware that these widths must be manually entered as Width rules in this version.
Release 15 | CAUTION - Support of separate solder masks for top & bottom of pads added.
Release 15.1 | CAUTION - Support Multi-line PCB Text added.
Release 16.0 | CAUTION - Pad/Via hole size tolerance value added.
Release 17.0 | CAUTION - Component parameters added.
Release 17.0 | CAUTION - Support of backdrilling
Release 17.1 | CAUTION - Support of waived violations
Release 17.1 | CAUTION - Support of object specific keepouts

This file was generated by a later version of the software

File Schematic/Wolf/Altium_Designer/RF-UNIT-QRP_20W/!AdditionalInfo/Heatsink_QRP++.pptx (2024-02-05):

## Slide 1

Used 2 heatsinks:
SK 81/100/SA (https://www.reichelt.de/kuehlkoerper-100-mm-alu-2-2-k-w-sk-81-100-sa-p227984.html?trstct=pos_0&nbc=1) – 100 x 100 mm, Alu, 2,2 K/W
SK 81/75/SA (https://www.reichelt.de/kuehlkoerper-75-mm-alu-2-5-k-w-sk-81-75-sa-p227987.html?&trstct=pos_0&nbc=1) – 100 x 75 mm, Alu, 2,5 K/W

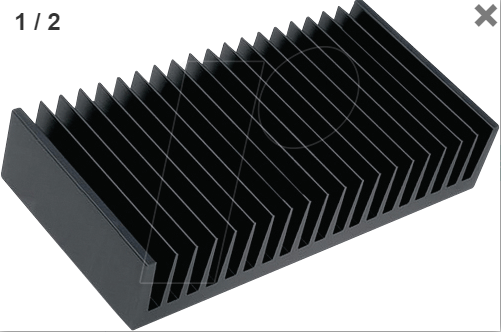
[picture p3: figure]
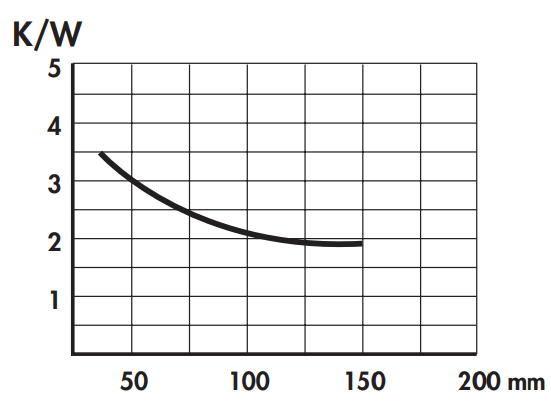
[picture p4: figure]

SK 81/100/SA drill dimensions

100

100

7x M3

9,5

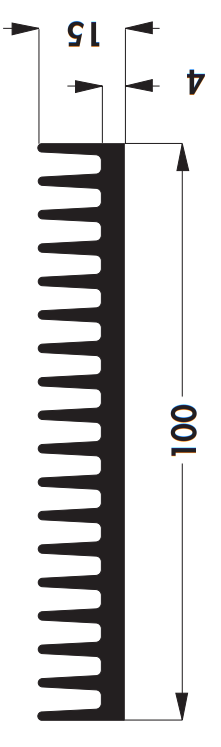
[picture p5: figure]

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
26,5

Dimensions 1

Dimensions 2

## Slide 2

SK 81/75/SA drill dimensions

75

9,5

10

10

100

9,5

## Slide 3

Bottom cover
(Dimensions 1)

11,1

17,6

17,6

103,2

11,1

97,6

117,6

190,2

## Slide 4

Bottom cover
(Dimensions 2)

115

103,2

9,5

62

190,2

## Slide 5

Copper block 1 (TIM)
- Size 39x30x10

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
2 x Ф 3,5

15,4

35

6,1

12

7

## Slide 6

Copper block 1 (TIM)
- Size 39x20x8

8

39

15,4

2 x Ф 3,5

35

6,1

20

12

7

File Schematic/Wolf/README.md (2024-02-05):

# Типы плат

* **MOTHERBOARD** - Универсальная материнская плата, под все вариации лицевой и ВЧ частей

* **FRONT-UNIT-7** - Основная версия 7 дюймовой платы TRX Wolf
* **FRONT-UNIT-7-RA9UCN** - Уменьшенная версия 7 дюймовой платы с кнопками "вниз"
* **FRONT-UNIT-4-IPS** - Версия для 4 дюймового дисплея
* **FRONT-UNIT-3.2, FRONT-UNIT-3.2-WIDE, FRONT-UNIT-3.5-RA9UCN, FRONT-UNIT-3.5** - Различные вариации под небольшой диплей, воспользуйтесь просмотрщиком Gerber файлов чтобы оценить размеры платы и расположение элементов управления

* **RF-UNIT-BIG-RU4PN+** - 100 ватт КВ + 80 ватт УКВ + Автоматический тюнер
* **RF-UNIT-QRP** - 7 ватт КВ + 5 ватт УКВ
* **RF-UNIT-QRP-RU4PN** - 15 ватт КВ + 7 ватт УКВ + Автоматический тюнер
* **RF-UNIT-QRP_20W** - 20 ватт КВ + 7 ватт УКВ
* **RF-UNIT-SPLIT** - Замена ВЧ платы, если хочется обеспечить комутацию своих УМ+ДПФ+ФНЧ+Тюнера, вместо предлагаемых. На Плате установлено МШУ, аттенюатор и коммутация

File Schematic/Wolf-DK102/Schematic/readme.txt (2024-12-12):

1、天调板还未设计，但是结构预留了空间
2、蓝牙板还未设计，但是主板预留了接口和空间

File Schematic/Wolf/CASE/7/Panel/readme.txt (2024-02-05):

Описание файлов:
верхняя планка волк7 - без разделения, для болього принтера (длина около 300 мм.)
верхняя планка волк7_1,2,3 - планка разделена на 3части для печати на маленьких принтерах(у меня 134х80)
аналогично:
рамка_низ_7 - целая рамка
рамка_низ_7_л - левая часть
рамка_низ_7_пр - правая часть

материал для печати: смола м58
Для установки панели в корпус Василия, необходимо вкорпусе спилить внутренние кромки 
слева, снизу, справа, примерно на 3 мм.

Основа панели - листовой алюминий 2 мм, программу для чпу с чертежами выложу позже.
Ось нижних кнопок - пруток 3мм (можно очищенный электрод)

Основной энкодер крепится штатно, на плату, тип штока - D

Высота кнопок передней панели должна быть 12 мм.

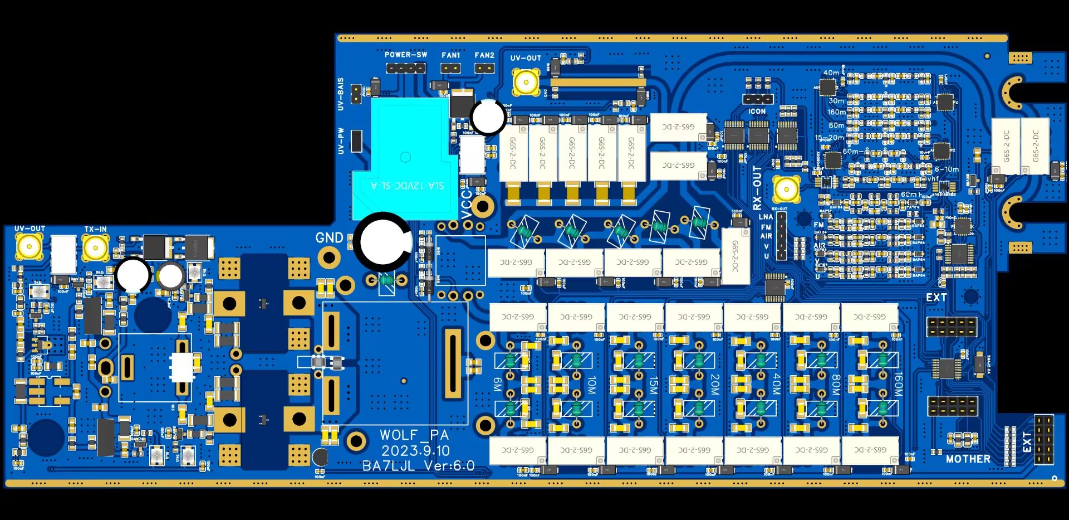
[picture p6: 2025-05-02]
Schematic/Wolf-BA7LJL/Photos/Wolf_Pa.jpg

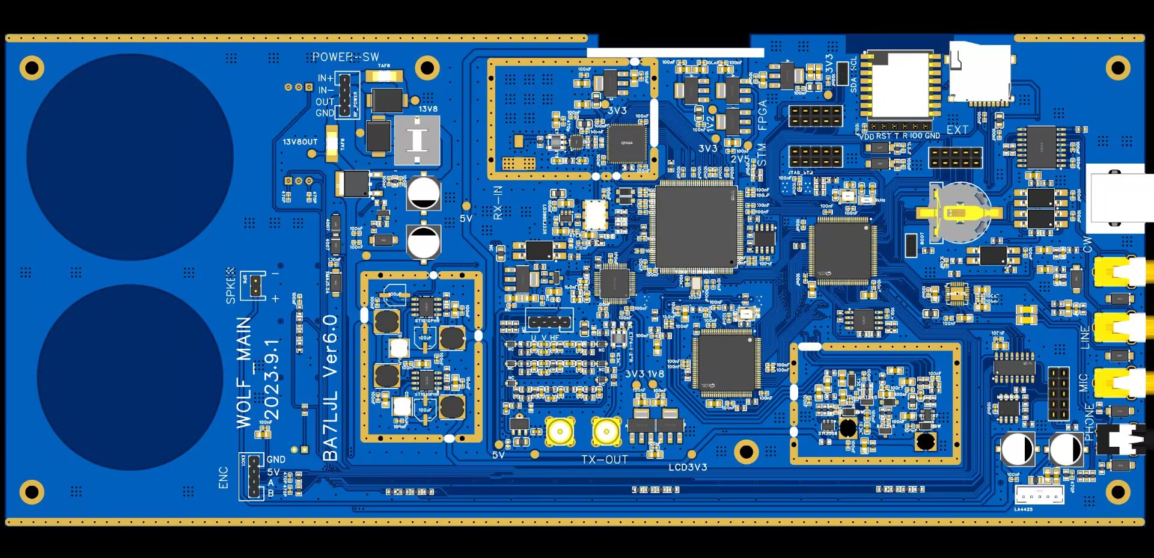
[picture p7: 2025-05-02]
Schematic/Wolf-BA7LJL/Photos/Wolf_Main.jpg

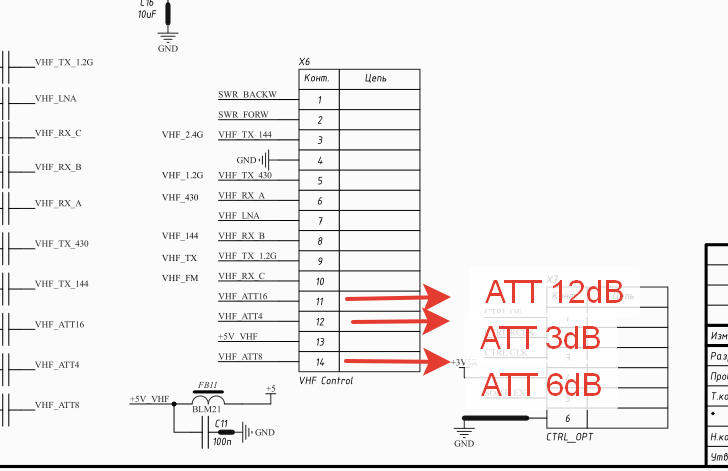
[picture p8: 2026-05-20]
Schematic/Wolf-2/Addons/ATT&Protector/wolf-2 connection.png

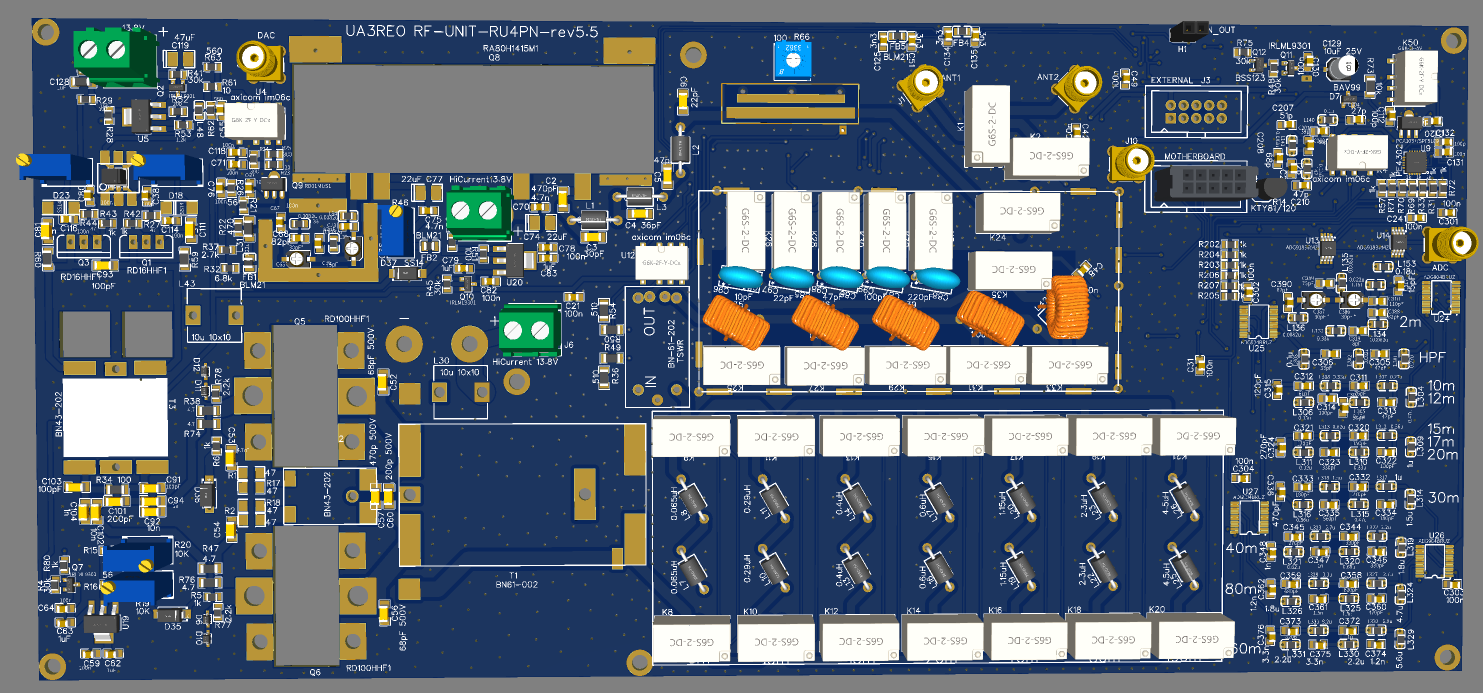
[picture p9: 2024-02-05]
Schematic/Wolf/Assembly/SCHEMATIC-RF-UNIT-BIG-RU4PN-rev5.5_UP.png

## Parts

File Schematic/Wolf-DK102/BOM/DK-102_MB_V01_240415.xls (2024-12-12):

序号 | 类型 | 型号/参数 | 位号 | 封装 | 单机数量
1 | 电容 | 100nF | C1,C3,C4,C5,C6,C7,C8,C9,C15,C16,C17,C21,C23,C26,C32,C33,C34,C38,C40,C44,C54,C55,C56,C57,C58,C59,C60,C108,C109,C110,C111,C112,C118,C121,C122,C123,C125,C127,C129,C139,C140,C149,C152,C157,C159,C161,C163,C167,C169,C170,C171,C173,C175,C177,C178,C179,C183,C190,C191,C193,C194,C195,C199,C201,C203,C204,C205,C207,C208,C209,C210,C211,C212,C233,C284,C285,C287,C291,C294,C295,C318,C320,C326,C329,C330,C331,C343,C345,C347,C348,C356,C357,C362,C363,C365,C961,C962,C969,C970 | C0603 | 99
2 | 电容 | 10uF/25V | C2,C10,C13,C14,C18,C19,C20,C22,C24,C27,C28,C29,C31,C41,C107,C116,C117,C124,C126,C128,C130,C138,C141,C151,C153,C154,C155,C156,C158,C160,C162,C164,C168,C172,C174,C176,C180,C181,C182,C188,C189,C192,C196,C213,C283,C288,C319,C321,C340,C346,C349,C353,C355,C360,C364,C366,C963,C964,C965,C966,C967,C968,C971,C344 | C0603 | 64
3 | 电容 | 220uF/16V | C11,C350,C361 | CASE-D | 3
4 | 电容 | 220uF | C35,C36 | CASE-B | 2
5 | 电容 | 100pF | C37,C39,C293 | C0603 | 3
6 | 电容 | 10nF | C42,C206,C341,C354 | C0603 | 4
7 | 电容 | 15pF | C113,C114,C115,C119,C120,C165,C166,C184,C185,C186,C187,C327,C328 | C0603 | 13
8 | 电容 | 1nF/16V | C150,C200,C202,C351,C352,C358,C359,C12 | C0603 | 8
9 | 电容 | 100uF/25V | C197,C286 | CASE-D | 2
10 | 电容 | 470pF | C292 | C0603 | 1
11 | 电容 | 3.3nF | C298,C317,C342 | C0603 | 3
12 | 电容 | NFM21PC104R1E3D | C316,C322,C323 | NFM21PC | 3
13 | 二极管 | 1N4148 | D1,D2,D9,D17,D18,D64,D65,D70,D76,D77 | SOD-523 | 10
14 | 二极管 | 1N5819 | D4,D10 | SOD-523 | 2
15 | 二极管 | BAT54S | D6,D7 | SOT23-3 | 2
16 | 二极管 | ST2045 | D72,D73,D74,D75,D78,D79,D80 | TO-277 | 7
17 | 稳压二极管 | 16V | D5 | SOD-123 | 1
18 | 稳压二极管 | 7.5V | D8 | SOD-123 | 1
19 | LED | LED,0603 | D23 | LED0603 | 1
20 | 保险丝 | S6125-F-10.0A | F1,F2 | S6125 | 2
21 | 保险丝 | BSMD1206-100-24V | F3 | 1206 | 1
22 | 连接器 | PJ-327A-5A | J4 | PJ-327A-D | 1
23 | 连接器 | PJ-242 | J8 | PJ-242 | 1
24 | 连接器 | 918-418K2023S40001 | J13 | TYPE_C | 1
25 | 连接器 | U.FL-R-SMT-1(80) | J14,J568,J569 | IPX | 3
26 | 连接器 | FPC，50PIN，0.5间距，抽屉式,上接 | J19 | FPC50X0_5-CT | 1
27 | 连接器 | FPC，6PIN，0.5间距，翻盖式，下接 | J20 | FPC6X0_5 | 1
28 | 连接器 | TF-115-BCP9 | J23 | TF-CARD | 1
29 | 电感 | 10uH/CXP0850-100-AG | L1 | CXP0850 | 1
30 | 电感 | SMMS0530-100M | L11,L12,L14,L16,L32,L34 | SMMS0530 | 6
31 | 电感 | SMMS0530-3R3M | L13,L15,L33 | SMMS0530 | 3
32 | 电感 | 10uH,4018 | L19 | 4018 | 1
33 | 电感 | 22uH,4018 | L21 | 4018 | 1
34 | 磁珠 | 100R@100MHz/2A | L9,L17,L18,L20,L22，L28,L31，L26,L27,L29,L30 | 603 | 11
35 | 三极管 | 2N3906 | Q1 | SOT23-3 | 1
36 | 三极管 | D882 | Q2 | SOT-89-3L | 1
37 | MOS | HSBB3115 | Q3,Q4,Q14 | PRPAK3X3 | 3
38 | MOS | 2N7002 | Q5,Q8,Q13,Q36,Q38,Q44,Q45,Q47 | SOT23-3 | 8
39 | MOS | FDN338P | Q7,Q37,Q39,Q46 | SOT23-3 | 4
40 | MOS | YJL3416A | Q9,Q10 | SOT23-3 | 2
41 | MOS | HSBB4052 | Q17,Q18,Q34,Q35 | PRPAK3X3 | 4
42 | 电阻 | 1k | R1,R2,R4,R6,R269,R271,R283,R10,R16,R29,R30,R31,R37,R85,R114,R115,R116,R117,R183,R321 | R0603 | 20
43 | 电阻 | 10K | R3,R8,R9,R15,R64,R66,R67,R68,R69,R71,R73,R76,R79,R80,R84,R90,R93,R102,R103,R278 | R0603 | 20
44 | 电阻 | 47K | R5,R26,R207,R213,R285,R286,R288,R289,R315,R316,R11,R13,R14,R17,R65,R107,R108,R109,R127,R132,R244,R245,R290,R291,R292,R296,R297,R307,R317,R318 | R0603 | 30
45 | 电阻 | 50.1K | R18,R266,R310 | R0603 | 3
46 | 电阻 | 18K | R19,R20,R89,R95,R308,R309 | R0603 | 6
47 | 电阻 | 0.01R/0.5W | R22,R282 | R0805 | 2
48 | 电阻 | 4.7K | R28,R81,R83,R87,R96,R105,R106,R110,R111,R112,R113,R123,R124,R125,R126,R128,R129,R135,R136,R137,R298,R299,R319,R320,R21 | R0603 | 25
49 | 电阻 | 22R | R32,R33,R34,R35,R249 | R0603 | 5
50 | 电阻 | 3M | R70,R82，R276 | R0603 | 3
51 | 电阻 | 39K | R74,R303,R311 | R0603 | 3
52 | 电阻 | 7.5K | R75,R312 | R0603 | 2
53 | 电阻 | 15K | R77,R94 | R0603 | 2
54 | 电阻 | 100K | R78,R88,R91,R97,R98,R99,R261,R262,R267,R268,R294,R295,R7 | R0603 | 13
55 | 电阻 | 2K | R86,R119,R120,R121,R122，R272 | R0603 | 6
56 | 电阻 | 200K | R92,R274,R284 | R0603 | 3
57 | 电阻 | 2R | R100,R101，R281 | R0603 | 3
58 | 电阻 | 0R | R118,R187,R188,R189,R211,R212,R215,R216,R217,R218,R23,R279,R280 | R0603 | 13
59 | 电阻 | 320K | R260,R293 | R0603 | 2
60 | 电阻 | 10M | R273 | R0603 | 1
61 | 电阻 | 86K | R313 | R0603 | 1
62 | 采样电阻 | HoLR2728D-4W-5mR-3% | R214,R275 | 2728D | 2
63 | 热敏电阻 | 47K-NTC | R208 | R0603 | 1
64 | 按键开关 | KEY_4P_6*6*10，贴片6*6按键，高10 | SW5,SW6,SW7,SW8,SW9,SW10,SW11,SW12 | 6X6-SMD-KEY | 8
65 | 滤波器 | ACM7060F-400F/SMD7060-400F | T4 | ACM7060F | 1
66 | IC | CM1041-DT | U1 | TSSOP16-4_4 | 1
67 | IC | IP6538AC | U2 | QFN32L_5X5 | 1
68 | IC | TPA626-VR-S | U3 | MSOP-10 | 1
69 | IC | WM8731 | U4 | SSOP-28-208MIL | 1
70 | IC | STM32F103C8T6 | U6 | LQFP48 | 1
71 | IC | RS2227XN | U8,U10,U222 | MSOP-10 | 3
72 | IC | ADUM4160 | U9 | SOIC-16-300MIL | 1
73 | IC | LM2940G-12V-AA3-R | U11 | SOT223 | 1
74 | IC | W25Q16 | U17 | SOIC8-208mil | 1
75 | IC | STM32H743VIT6 | U18 | TQFP100 | 1
76 | IC | ST1S10 | U19,U24,U220 | SOIC-8-EP | 3
77 | IC | MP1541 | U25 | SOT23-5 | 1
78 | IC | RA8875L3N | U26 | TQFP100 | 1
79 | IC | MP3202DJ | U27 | SOT23-6 | 1
80 | IC | MCP3008-I/SL | U30 | SO16 | 1
81 | IC | MCP6001UT-I/OT(MS) | U31,U32 | SOT23-5 | 2
82 | IC | 74LVC1G17GW-125 | U47,U216,U217,U221 | TSSOP-5 | 4
83 | IC | TPS82130SILR | U48,U50,U215 | TPS82130 | 3
84 | IC | NS4110B | U218,U219 | SOIC-8-EP | 2
85 | 晶体 | FC-135-32.768KHz | Y1 | FC-135 | 1
86 | 晶体 | 8MHz/SMD3225 | Y2,Y5 | SMD3225 | 2
87 | 晶体 | 20MHz/SMD3225 | Y3 | SMD3225 | 1
88 | 超级电容 | H414HGIV01E/3V | Y6 | H414HGIV01E | 1
89 | ESD器件 | ESD5B5CL | Z9,Z10,Z11,Z12,Z13,Z68,Z69,Z70,Z71,Z72,Z73,Z74,Z75,Z76,Z77,Z78,Z79,Z80 | SOD-523-ESD | 18
DIP
1 | 电容 | 220uF/35V | C960 | ECAP8X12 | 1
2 | 连接器 | 1251S-6P | J2,J17,J51,J58 | 1251S-6P | 4
3 | 连接器 | 1251S-4P | J3,J572,J573 | 1251S-4P | 3
4 | 驻极体话筒 | B4012AP422-003 | J6 | ZJT-D4 | 1
5 | 连接器 | 1251S-2P | J7,J10 | 1251S-2P | 2
6 | 连接器 | 1251S-10P | J12 | 1251S-10P | 1
7 | 连接器 | MCX-KWE | J15 | MCX-KWE | 1
8 | 连接器 | DC-042C-Z-2.5-A | J21 | DC-042C-Z-2.5-A | 1
9 | 连接器 | DS1133-S60BPX/RJ-12 | J22 | RJ-12 | 1
10 | 连接器 | USB-265-BRW | J47 | USB-265-BRW | 1
11 | 连接器 | 1251S-3P | J48 | 1251S-3P | 1
12 | 连接器 | SIP-3P | J50 | SIP-3P | 1
13 | 连接器 | XH-8A | J56 | SIP8X2_54 | 1
14 | 连接器 | 1251S-16P | J559 | 1251S-16P | 1
15 | 连接器 | PM127V-6P | J560,J561,J562,J563,J564,J565,J566,J570,J571 | PM127-6P | 9
16 | 热敏电阻 | 100k/ntc | R270 | SIP-2P | 1
17 | 按键开关 | TS-1093C-A145B3-D1，侧插，6*6*12 | SW13,SW14,SW15,SW24,SW26 | KEY6X6_M9.8x5.6 | 5
18 | 按键开关 | TS-1002-12026,KEY_4P_6*6*12 | SW22,SW23,SW25 | 260G-3 | 3
19 | 模块 | ESP-01 | U29 | ESP-01 | 1
20 | 液晶屏幕 | LCD_VS80480R70SS | U28 | LCD_VS80480R70SS | 1
21 | 屏蔽罩 | PB_24-15X21-25X3-4 | H9,H10 | PB_24-15X21-25X3-4 | 2
22 | 屏蔽罩 | PB_25-4X12-3X3-3 | H11 | PB_25-4X12-3X3-3 | 1
23 | 屏蔽罩 | PB_30-55X11-77X1-73 | H12 | PB_30-55X11-77X1-73 | 1

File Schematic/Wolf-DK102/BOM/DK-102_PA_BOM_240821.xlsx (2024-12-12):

序号 | 类型 | 型号/参数 | 位号 | 封装 | 单机数量
1 | 电容 | 10pF/200V | C40,C43 | C0603 | 2
2 | 电容 | 33pF/200V | C48,C77,C78 | C0603 | 3
3 | 电容 | 47pF/200V | C79,C80 | C0603 | 2
4 | 电容 | 68pF/200V | C75,C81,C82 | C0603 | 3
5 | 电容 | 100pF/200V | C50,C51,C54,C55,C83,C84 | C0603 | 6
6 | 电容 | 150pF/200V | C85,C86 | C0603 | 2
7 | 电容 | 180pF/200V | C58,C59 | C0603 | 2
8 | 电容 | 200pF/200V | C52,C56,C65 | C0603 | 3
9 | 电容 | 220pF/200V | C87,C88 | C0603 | 2
10 | 电容 | 390pF/200V | C60,C62,C63 | C0603 | 3
11 | 电容 | 680pF/200V | C64,C66,C67,C70,C71 | C0603 | 5
12 | 电容 | 1nF/200V | C68,C8,C89 | C0603 | 3
13 | 电容 | 2nF/200V | C72 | C0603 | 1
14 | 电容 | 10nF/25V | C2,C5,C76 | C0603 | 3
15 | 电容 | 100nF/200V | C1,C3,C6,C10,C4,C14,C17,C18,C20,C38,C39,C97,C9,C11,C12,C15,C16,C21,C22,C98 | C0603 | 20
16 | 电容 | 2.2uF/25V | C23,C90 | C0603 | 2
17 | 电容 | 22uF/16V | C13 | CASE-B | 1
18 | 电容 | 220uF/25V | C7,C37,C95,C96 | CASE-D | 4
19 | 二极管 | BAT46W | D1,D2,D4,D6,D7,D8,D9,D10,D11,D12,D13,D14,D71 | SOD-123 | 13
20 | 稳压二极管 | 8.3V | D15,D18 | SOD-123 | 2
21 | 稳压二极管 | 10V | D16,D17,D20 | SOD-123 | 3
22 | 稳压二极管 | 17V | D19 | SOD-123 | 1
23 | 二极管 | SS34 | D70 | SMA | 1
24 | 保险丝 | 1206-200/2A保险丝 | F3,F4 | 1206 | 2
25 | 连接器 | U.FL-R-SMT-1(80) | J5,J6,J14 | IPX | 3
26 | 继电器 | HFD4/12-SR | LS6,LS7,LS8,LS9,LS10,LS11,LS12,LS13 | G6K-2F-Y3VDC | 8
27 | 电感 | 39nH | L1,L3 | L0805 | 2
28 | 磁珠 | BEAD | L4,L5,L6,L7,L8 | L0603 | 5
29 | 电感 | 10nH | L30,L31 | L0805 | 2
30 | MOS | AFT09MS015NT1 | Q1,Q3 | AFT09MS015NT1 | 2
31 | MOS | RD01MUS1 | Q2,Q4 | SOT-89-3L | 2
32 | MOS | FDN338P | Q5 | SOT23-3 | 1
33 | MOS | HSBB3115 | Q14 | PRPAK3X3 | 1
34 | 三极管 | MMBT3904 | Q19 | SOT23-3 | 1
35 | MOS | 2N7002 | Q21,Q22 | SOT23-3 | 2
36 | 电阻 | 0R | R28,R30,R34 | R0603 | 3
37 | 电阻 | 20mR-1%/1W/1206 | R275 | 1206 | 1
38 | 电阻 | 4.7R/500mW | R4,R12 | R0805 | 2
39 | 电阻 | 10R | R6,R7,R13 | R0603 | 3
40 | 电阻 | 49.9R | R15,R18,R29,R33 | R0603 | 4
41 | 电阻 | 100R | R26 | R0603 | 1
42 | 电阻 | 220R/500mW | R2,R14,R81,R82 | R0805 | 4
43 | 电阻 | 560R | R9,R10,R31,R32 | R0603 | 4
44 | 电阻 | 620R | R27 | R0603 | 1
45 | 电阻 | 1K | R3,R11,R292 | R0603 | 3
46 | 电阻 | 2K | R1 | R0603 | 1
47 | 电阻 | 4.7K | R5,R8,R16,R19,R22,R288,R289,R290,R293,R295 | R0603 | 10
48 | 电阻 | 7.68K | R25,R87,R287 | R0603 | 3
49 | 电位器 | TC33X-2-502E | R84,R85,R86 | TC33X-2 | 3
50 | 巴伦 | TC1-1T+ | T6 | RF_TRANSFORMER | 1
51 | IC | LM1117S-ADJ | U2 | SOT223 | 1
52 | IC | MAX4373TEUA+ | U6 | MSOP-8 | 1
DIP
53 | 连接器 | BNC_DOSIN-801-0080 | ANT2 | BNC_DOSIN-801-0080 | 1
54 | 连接器 | 1251S-6P | J2 | 1251S-6P | 1
55 | 连接器 | 1251S-12P | J13 | 1251S-12P | 1
56 | 连接器 | MCX-KWE | J15 | MCX-KWE | 1
57 | 连接器 | MCX-KE | J16,J17 | MCX-KE | 2
58 | 磁环 | FT37-43/10uH | L2 | FT37-43_10uH | 1
59 | 空心电感 | 0.068uH | L15,L17 | T37-6_W | 2
60 | 磁环 | 0.3uH_T37-6 | L18,L19 | T37-6_W | 2
61 | 磁环 | 0.34uH_T37-6 | L20,L21 | T37-6_W | 2
62 | 磁环 | 0.5uH_T37-6 | L22,L23 | T37-6_W | 2
63 | 磁环 | 1.15uH_T37-6 | L24,L25 | T37-6_W | 2
64 | 磁环 | 2uH_T37-1 | L26,L27 | T37-6_W | 2
65 | 磁环 | 3.9uH_T37-2 | L28,L29 | T37-6_W | 2
66 | 磁芯 | BN43-202 | T3 | BN43-202 | 1
67 | 磁芯 | BN-61-202 | T5 | BN-61-202 | 1
68 | 磁芯 | BN43-2402/FT23-43 | T7 | BN43-2402 | 1
69 | 电位器 | 50K-16 | R79,R80 | B503-16 | 2
70 | IC | KTY81/120 | U1 | SOD-70-2 | 1

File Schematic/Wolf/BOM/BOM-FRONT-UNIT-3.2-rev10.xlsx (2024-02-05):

Comment | Description | Designator | Footprint | Quantity
0 | RES_0805 | R23, R24, R25 | RES_0805 | 3
1n | CAP_1206 | C5 | CAP_1206 | 1
1n4148w | Diode | D25, D27 | SOD3716X135N | 2
1uF | CAP_1206 | C3 | CAP_1206 | 1
3.3k | RES_0805 | R20, R21, R22 | RES_0805 | 3
4.7k | RES_0805 | R3, R4, R5, R6, R7, R8, R9, R10, R11, R12, R13, R14, R15, R16, R17, R18, R19, R29, R30, R31, R32, R33, R34, R35, R36 | RES_0805 | 25
8.2n | CAP_1206 | C11 | CAPC2013X94X50LL20T25 | 1
10n | CAP_0805 | C12, C13 | CAP_0805 | 2
22uF 10V | EEEFC_sizeB | C10 | EEEFC_sizeB | 1
30k | RES_0805 | R26, R27, R28 | RESC2013X60X40NL20T25 | 3
100n | CAP_0805 | C1, C2, C9 | CAP_0805 | 3
100n | CAP_1206 | C4 | CAP_1206 | 1
120p | CAP_1206 | C8 | CAP_1206 | 1
470p | CAP_1206 | C7 | CAP_1206 | 1
1000uF | CAP250RP | C6 | CAP250RP | 1
BNX016-01 | BNX016-01 | T1 | TRANSF_ICORE | 1
BSS123 | N-Channel Logic Level Enhancement Mode Field Effect Transistor, 1.7 V, -55 to 150 degC, 3-Pin SOT-23, RoHS, Tape and Reel | Q2 | FAIR-SOT23-3_V | 1
DM3AT-SF-PEJM5 | Connector | J2 | DM3ATSFPEJM5 | 1
ESP-01 ESP8266 | ESP-01 ESP8266 | ESP-8266 | ESP-01 ESP8266 | 1
FPC-45P-0.5mm | Connector | J7 | FH12S45S05SH60 | 1
ILI9481 480*320 3'2 | LCD-MODULE_3'2_480х320 | LCD-MODULE | LCD-MODULE-3.2-480-320 | 1
IRFR9024NPBF | IRFR9024NPBF, Транзистор, Р-канал 55В 11А | Q1 | ONSC-DPAK-3-369C-01_V | 1
JX2 | JX2 | ACCUM, IN, MOTHERBOARD, RF-UNIT | JX2 | 4
MCP3008-I/SL | MCP3008-I/SL | U1, U2, U3 | MCP3008-I/SL | 3
MF-MSMF110_16-2 | Fuse | F2 | FUSC4632X85N | 1
OPTICAL ENCODER | OPTICAL ENCODER | ENCODER_MAIN | 644456-4 | 1
PEC12 | PEC12 | ENC2 | PEC12 | 1
PJ-050B | PJ-050B | IN_2 | PJ-050B | 1
PTS645SK50LFS | PTS645SK50LFS | S1, S2, S3, S4, S5, S6, S7, S8, S9, S10, S11, S12, S13, S14, S15, S16, S17, S18, S19, S20, S21, S22, S23 | PTS645SK50LFS | 23
ptv09a-4225f-b102 | Adjustable Resistor PTV09 | R1, R2 | PTV09 | 2
RUEF400 | Fuse | F1 | RUEF400 | 1
SM6T15A | Diode | D28 | SMBJ36CATR | 1

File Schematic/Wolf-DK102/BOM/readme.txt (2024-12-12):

1、DK102_OLED_V01_240414板子比较简单，是手工焊接的，未出BOM表
2、DK-102_TUNING_V01_240414板子比较简单，是手工焊接的，未出BOM表

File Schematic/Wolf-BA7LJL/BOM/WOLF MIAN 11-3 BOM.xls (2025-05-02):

WOLF_MAIN BOM
 | 参数 | 封装 | 数量 | 备注
贴片电阻 | 0R | 0603 | 2
 | 2R2 |  | 1
 | 10R |  | 3
 | 22R |  | 4
 | 56R |  | 2
 | 100R |  | 11
 | 1K |  | 20
 | 2K2 |  | 4
 | 3K3 |  | 5
 | 4K7 |  | 9
 | 5K6 |  | 6
 | 6K8 |  | 1
 | 10K |  | 30
 | 15K |  | 1
 | 22K |  | 3
 | 47K |  | 6
 | 100K |  | 3
 | 10M |  | 1
贴片电容 | 104 | 0402 | 117
 | 104 | 0603 | 5
 | 6P | 0603 | 2
 | 10P | 0603 | 1
 | 22P | 0603 | 4
 | 470P | 0603 | 9
 | 272P | 0603 | 1
 | 103 | 0603 | 2
 | 1UF | 0603 | 4
 | 1UF | 0805 | 6
 | 22UF | 0805 | 40
 | 100UF | 5*5.4 | 1
 | 220UF | 8*8.3 | 4
贴片电感 | 330L | 0805 | 14
 | 10UH | CD43 | 2
 | 10UH | CD54 | 2
贴片二极管 | 4007 | 1206 | 2
 | 5819 | 1206 | 2
 | 7V5 | 1206 | 1
 | 16V | 1206 | 1
 | SS54 | SMB | 2
 | SMAJ5.0A | SMA | 9
晶振 | 8MHZ | 3225 | 1
 | 20MHZ | 3225 | 1
 | 19.2MHZ | 2510 | 1
 | 32.768K | 3215 | 1
 | 122.88MHZ | 7050 | 1
稳压 | 1117-1.2 | SOT223 | 1
 | 1117-1.8 | SOT223 | 1
 | 1117-2.5 | SOT223 | 1
 | 1117-3.3 | SOT223 | 4
 | LD3985M33 | SOT23-6 | 1
 | ST1S10 | SOP8 | 1
 | STI3508 | SOT23-6 | 1
 | STI9287 | SOT23-6 | 1
三极管 | J3Y | SOT23 | 1
 | BAT54 | SOT23 | 2
 | CMD100P30 | TO252 | 1
 | PC718 | SMD4 | 3
IC | ADUM4160 |  | 1
 | DAC5674 |  | 1
 | EP4CE22 |  | 1
 | LTC2208 |  | 1
 | LTC6400 |  | 1
 | M25P80 |  | 1
 | MCP3008 |  | 1
 | MCP6002 |  | 1
 | RA8875 |  | 1
 | STM32H743 |  | 1
 | W25Q16 |  | 1
 | WM8731 |  | 1
其他 | ESP07 | ESP8266 | 1
 | CR1220 | 纽扣电池 | 1
 | 1:4巴伦 |  | 2
 | 2410保险管座 |  | 2
 | TF-01 | 内存卡座 | 1
 | 0.5*50P | 下接 | 1
 | 0.5*6P | 上接 | 1
后焊 | 公针2P | 2.54 | 2 | 2,54MM
 | 公针6P | 2.54 | 1
 | 公针3P | 2.54 | 2
 | 牛角公座 | 2*5P | 3
 | 母针座2P |  | 1
 | 母针座4P |  | 2
 | 母弯座 | 2*5P | 1
 | MCX射频座 |  | 1
 | 贴片按键 | 6*6*8 | 12
 | 5MM绿灯 |  | 1
 | PJ3220 |  | 3
 | PJ3910 |  | 1
 | TYPE-B |  | 1
 | 编码器 | EC11 | 1
 | LA4425 |  | 1

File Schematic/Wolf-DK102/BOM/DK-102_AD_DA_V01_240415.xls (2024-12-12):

序号 | 类型 | 型号/参数 | 位号 | 封装 | 单机数量
1 | 电容 | 4.7uF | C3,C4,C46,C296,C297,C298,C312,C319,C320,C323,C325,C327,C329,C331,C333 | C0402 | 15
2 | 电容 | 100nF | C5,C6,C7,C9,C10,C16,C17,C18,C49,C51,C61,C63,C70,C77,C79,C81,C85,C86,C87,C88,C89,C90,C91,C92,C94,C95,C96,C97,C98,C99,C100,C101,C103,C104,C105,C106,C143,C147,C279,C280,C281,C282,C295,C299,C300,C301,C302,C303,C304,C305,C306,C307,C308,C309,C311,C318,C321,C324,C326,C328,C330,C332,C334 | C0402 | 63
3 | 电容 | 1uF | C8,C11,C12,C15,C48,C50,C52,C62,C64,C69,C71,C73,C78,C80,C84,C93,C102,C142,C144,C290,C317 | C0402 | 21
4 | 电容 | 100pF | C13,C66 | C0402 | 2
5 | 电容 | 470pF | C14,C76,C82,C289 | C0402 | 4
6 | 电容 | 8.2nF | C47 | C0402 | 1
7 | 电容 | 10nF | C53,C67,C68 | C0402 | 3
8 | 电容 | 680pF | C74,C83 | C0402 | 2
9 | 电容 | 7.5pF | C75 | C0402 | 1
10 | 电容 | 10uF/16V | C292,C293,C294 | C0603 | 3
11 | 电容 | 47nF | C313 | C0402 | 1
12 | 电容 | NFM21PC104R1E3D | C315,C316 | NFM21PC | 2
13 | 连接器 | U.FL-R-SMT-1(80) | J1,J15 | IPX | 2
14 | 连接器 | PJ-320A | J18 | PJ-320A | 1
15 | 磁珠 | 100R@100MHz/2A | L1,L6,L15,L17,L11,L12,L13,L14,L8,L10 | R0603 | 10
16 | 电感 | 47nH | L4,L5 | L0805 | 2
17 | 电阻 | 56R | R1 | R0402 | 1
18 | 电阻 | 1K | R2,R38,R47,R51,R55,R56 | R0402 | 6
19 | 电阻 | 47K | R21 | R0402 | 1
20 | 电阻 | 5.6K | R22 | R0402 | 1
21 | 电阻 | 100R | R23,R24,R26,R27,R39,R40 | R0402 | 6
22 | 电阻 | 330R | R41,R49 | R0402 | 2
23 | 电阻 | 22R | R42,R48,R50 | R0402 | 3
24 | 电阻 | 10K | R43,R44,R54,R57,R58,R59,R60,R61,R62,R63 | R0402 | 10
25 | 电阻 | 7.5K | R45,R52 | R0402 | 2
26 | 电阻 | 5.6R | R46,R53 | R0402 | 2
27 | 电阻 | 33R | R64,R65,R66,R67,R68 | R0402 | 5
28 | 电阻 | 3.3K | R69 | R0402 | 1
29 | 电阻 | 33.2K | R245,R246,R247,R248 | R0402 | 4
30 | 电阻 | 4.99R/0.5W | R250,R251 | 1210 | 2
31 | 巴伦 | CX2041NLT-1:1 | T6 | RF_TRANSFORMER | 1
32 | 巴伦 | CX2041NLT-1:2+2 | T7,T8 | RF_TRANSFORMER | 2
33 | IC | LTC2208CUP | U2 | QFN-64-EP_9X9 | 1
34 | IC | LTC6400IUD | U3 | QFN16_3X3 | 1
35 | 晶振 | TXCO_12.288Mhz,3.3V,单端输出 | U7 | SMD3225 | 1
36 | IC | DAC5674IPHP | U11 | HTQFP-48 | 1
37 | IC | ME6214C33M5G | U12,U6 | SOT-25 | 2
38 | IC | ME6214C18M5G | U13,U21 | SOT-25 | 2
39 | IC | OPA2673IRGVT | U14 | VQFN-16-EP | 1
40 | IC | W25Q16 | U15 | SOIC8-208mil | 1
41 | IC | EP4CE22E22C8N | U16 | TQFP-144 | 1
42 | IC | GM1200ARMZ-R7 | U22,U23,U24,U25 | MSOP10-EP | 4
43 | 晶振 | 122.88Mhz,3.3V,差分输出 | XG1 | SMD7050-6P | 1
44 | ESD | ESD5V | Z4,Z5,Z6,Z7,Z8,Z55,Z66 | E0603 | 7
DIP
1 | 连接器 | 1251S-16P | J8 | 1251S-16P | 1
2 | 连接器 | XH-8A | J9 | SIP8X2_54 | 1
3 | 连接器 | 1251S-6P | J16 | 1251S-6P | 1

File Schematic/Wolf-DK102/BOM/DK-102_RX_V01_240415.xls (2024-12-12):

序号 | 类型 | 型号/参数 | 位号 | 封装 | 单机数量
1 | 电容 | 8pF | C8,C11 | C0603 | 2
2 | 电容 | 12p | C70 | C0603 | 1
3 | 电容 | 15pF | C9 | C0603 | 1
4 | 电容 | 27p | C71 | C0603 | 1
5 | 电容 | 30pF | C6,C7 | C0603 | 2
6 | 电容 | 33pF | C16 | C0603 | 1
7 | 电容 | 39pF | C83,C68 | C0603 | 2
8 | 电容 | 47pF | C15,C21,C74 | C0603 | 3
9 | 电容 | 51p | C72 | C0603 | 1
10 | 电容 | 61pF | C19 | C0603 | 1
11 | 电容 | 68p | C69,C73 | C0603 | 2
12 | 电容 | 75pF | C13,C18 | C0603 | 2
13 | 电容 | 91pF | C12,C14 | C0603 | 2
14 | 电容 | 100pF | C22,C26,C54,C59,C62,C66 | C0603 | 6
15 | 电容 | 110p | C3,C5 | C0603 | 2
16 | 电容 | 120pF | C23,C25 | C0603 | 2
17 | 电容 | 150pF | C24 | C0603 | 1
18 | 电容 | 180pF | C30,C31 | C0603 | 2
19 | 电容 | 270pF | C28,C29,C35 | C0603 | 3
20 | 电容 | 330pF | C27,C34,C36 | C0603 | 3
21 | 电容 | 470pF | C33,C43 | C0603 | 2
22 | 电容 | 560pF | C32 | C0603 | 1
23 | 电容 | 680pF | C40 | C0603 | 1
24 | 电容 | 820pF | C42,C47 | C0603 | 2
25 | 电容 | 1nF | C37,C38,C46,C58 | C0603 | 4
26 | 电容 | 1.2nF | C45,C48 | C0603 | 2
27 | 电容 | 1.5nF | C44 | C0603 | 1
28 | 电容 | 3.3nF | C49,C50 | C0603 | 2
29 | 电容 | 10nF | C57,C82 | C0603 | 2
30 | 电容 | 100nF | C1,C2,C17,C20,C39,C41,C56,C60,C65,C84,C85,C86,C87,C88,C89 | C0603 | 15
31 | 电容 | 10uF/16V | C61 | C0603 | 1
32 | 二极管 | BAV99 | D1 | SOT23-3 | 1
33 | 二极管 | 1N4148 | D19,D20 | SOD-523 | 2
34 | 连接器 | U.FL-R-SMT-1(80) | J1,J7 | IPX | 2
35 | 继电器 | HFD4/12-SR | LS4,LS5 |  | 2
36 | 绕线电感 | 8.2nH | L8,L9,L10 | L0805 | 3
37 | 绕线电感 | 22nH | L1,L3 | L0805 | 2
38 | 绕线电感 | 82nH | L12,L46 | L0805 | 2
39 | 绕线电感 | 100nH | L13,L45 | L0805 | 2
40 | 绕线电感 | 150nH | L17,L18,L47 | L0805 | 3
41 | 绕线电感 | 180nH | L5 | L0805 | 1
42 | 绕线电感 | 220nH | L44 | L0805 | 1
43 | 绕线电感 | 270nH | L11,L14 | L0805 | 2
44 | 绕线电感 | 330nH | L4,L7,L15,L22,L23 | L0805 | 5
45 | 绕线电感 | 470nH | L16,L27 | L0805 | 2
46 | 绕线电感 | 560nH | L19,L28 | L0805 | 2
47 | 绕线电感 | 680nH | L32 | L0805 | 1
48 | 绕线电感 | 820nH | L20,L33 | L0805 | 2
49 | 绕线电感 | 1uH | L21,L24 | L0805 | 2
50 | 绕线电感 | 1.5uH | L25,L26,L37 | L0805 | 3
51 | 绕线电感 | 1.8uH | L31,L38 | L0805 | 2
52 | 绕线电感 | 2.2uH | L29,L42,L43 | L0805 | 3
53 | 绕线电感 | 2.7uH | L30,L34 | L0805 | 2
54 | 绕线电感 | 3.3uH | L35 | L0805 | 1
55 | 绕线电感 | 4.7uH | L36 | L0805 | 1
56 | 绕线电感 | 5.6uH | L41 | 1210 | 1
57 | 绕线电感 | 6.8uH | L39 | 1210 | 1
58 | 绕线电感 | 8.2uH | L40 | 1210 | 1
59 | MOS | FDN338P | Q2 | SOT23-3 | 1
60 | MOS | PGA-103+ | Q3 | SOT-89-3L | 1
61 | MOS | 2N7002 | Q4 | SOT23-3 | 1
62 | 电阻 | 10K | R1 | R0603 | 1
63 | 电阻 | 22R | R27 | R0603 | 1
64 | 电阻 | 30K | R28,R30 | R0603 | 2
65 | 电阻 | 1K | R31,R39,R40,R41,R42,R43,R44,R45 | R0603 | 8
66 | 电阻 | 8.2K | R32,R33,R34,R35,R36,R37,R38 | R0603 | 7
67 | 按键开关 | YTS1C0192ABG00 | SW2 | YTS1C0192ABG00 | 1
68 | IC | ADG918BRMZ | U1,U2 | MSOP8 | 2
69 | IC | ADG904BRUZ | U3,U4,U5,U6 | TSSOP-20 | 4
70 | IC | LM1117S-5.0 | U11 | SOT223 | 1
71 | IC | PE4302 | U15 | QFN20_4X4 | 1
72 | IC | STPIC6C595TTR | U17,U18,U19,U20,U21,U22 | TSSOP16-4_4 | 6
DIP
1 | 连接器 | 1251S-10P | J3 | 1251S-10P | 1
2 | 连接器 | 1251S-14P | J8 | 1251S-14P | 1
3 | 连接器 | 1251S-12P | J9 | 1251S-12P | 1

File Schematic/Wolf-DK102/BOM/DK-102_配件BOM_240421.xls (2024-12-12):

序号 | 品类 | 厂商 | 型号/描述 | 位号 | 单机数量
1 | 线缆 |  | 导线，5A,L= | MB板到PA板供电线 | 2
2 | 线缆 |  | 导线，5A,L= | 电池到MB板供电线缆 | 2
3 | 线缆 |  | 1.25间距，2PIN，单端，L=30 | MB板到扬声器 | 1
4 | 线缆 |  | 1.25间距，10PIN,两端反向，L=110 | MB板到RX板信号线缆 | 1
5 | 线缆 |  | 1.25间距，6PIN,两端反向,L=110 | MB板到PA板信号线缆 | 1
6 | 线缆 |  | 1.25间距，14PIN,两端反向，L=125 | RX板到TUNE板信号线 | 1
7 | 线缆 |  | 1.25间距，12PIN,两端反向，L=180 | RX板到PA板信号线缆 | 1
8 | 线缆 |  | 1.25间距，16PIN,两端反向，L=125 | MB板到ADC板信号线缆 | 1
9 | 线缆 |  | 1.25间距，4PIN，两端反向，L=40 | OLED板到MB板 | 1
10 | 线缆 |  | 1.25间距，4PIN，两端反向，L=40 | TUNING板到MB板 | 1
11 | 线缆 |  | 2.54间距，8PIN,两端反向，L=80 | MB板到ADC板电源线缆 | 1
12 | 线缆 |  | 6PIN，单端 | 调试线缆 | 1
13 | 线缆 |  | 两端MCX弯公头，RG174线，50欧，L=140 | PA板到TUNE板 | 2
14 | 线缆 |  | 两端IPEX插头1代，1.37线，50欧，L=85 | RX板到PA板射频信号线缆,发射 | 1
15 | 线缆 |  | 两端IPEX插头1代，1.37线，50欧，L=80 | ADC板到RX板射频信号线缆，解码 | 1
16 | 线缆 |  | 两端IPEX插头1代，1.37线，50欧，L=170 | PA板到RX板射频信号线缆，接收 | 1
17 | LCD屏幕 |  | VS80480R70,7寸，RGB，带电容触摸 |  | 1
18 | OLED屏幕 |  | 0.96寸，128*64,OLED |  | 1
19 | 电芯 |  | 18650，锂离子电池，3500mAh |  | 4
20 | 按键帽 |  | 硅胶，方形，尺寸5*9 |  | 13
21 | 按键帽 |  | 硅胶，圆形 |  | 3
22 | 扬声器 |  | 40厘米直径，2瓦 |  | 1
23 | 外壳 |  | 铝合金定制 |  | 1
24 | 螺丝 |  | M2，沉头，L=3 | 固定外壳 | 9
25 | 螺丝 |  | M2，沉头，L=3 | 固定PCB板 | 22
26 | 螺帽 |  | M2螺帽 | 固定喇叭、OLED亚克力板 | 10
27 | 铜柱 |  | M2，高3毫米 | 固定TUNING板,固定PA板,固定ADC板 | 11
28 | 胶水 |  | 卡夫特固态胶
29 | 双面胶 |  | 泡棉双面胶，宽：，厚：
30 | 充电器 |  | 16.8V/2A,CD Jack5525 |  | 1
31 | 手咪 |  |  |  | 1
32 | 编码器 |  |  |  | 1

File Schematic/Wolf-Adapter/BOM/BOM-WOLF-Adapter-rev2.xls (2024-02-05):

Comment | Description | Designator | Footprint | Quantity
"1.2Ghz" | RF | J8 | CON: SMA | 1
"5.6Ghz" | RF | J9 | CON: SMA | 1
"10Ghz" | RF | J10 | CON: SMA | 1
"144Mhz" | RF | J6 | CON: SMA | 1
"430Mhz" | RF | J7 | CON: SMA | 1
"OUTPUTS_1" |  | J3 | CON: PLD-10 | 1
"OUTPUTS_2" |  | J4 | CON: PLD-10 | 1
"PTT" |  | J5 | CON: PLD-10 | 1
"PTT" |  | X1 | CON: PLS-5 | 1
"TRX" |  | J1 | CON: PLD-10 | 1
"TRX_VHF" | RF | J2 | CON: SMA | 1
0.1u |  | C2, C4 | CH0805C | 2
1k |  | R1, R2, R3, R4 | CH0805R | 4
1N4148 |  | VD1, VD2, VD3, VD4, VD5, VD6, VD7, VD8, VD9, VD10, VD11, VD12, VD13, VD14, VD15, VD16, VD17, VD18, VD19, VD20 | 1N4148 | 20
10k |  | R6 | CH0805R | 1
10uF |  | C1, C3 | TANTAL_B | 2
30k |  | R5 | CH0805R | 1
74HC4514D |  | IC1 | 24-SOIC (W) | 1
100n |  | C5, C6, C7, C8, C9, C10, C11, C12, C13, C14 | CH0805C | 10
BSS123 |  | VT2 | SOT23_132 | 1
G6S-2-D?12 |  | K1, K2, K3, K4, K5, K6, K7, K8, K9, K10 | G6S-2-DC12 | 10
IRLML9301 |  | VT1 | SOT23_132 | 1
LM1117DT-5-5.0 |  | U1 | SOT223 | 1
ULN2803AFWG |  | IC2, IC3 | 18-SOIC (W) | 2

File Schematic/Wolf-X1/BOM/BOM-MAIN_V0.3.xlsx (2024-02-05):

Посадочное место | Номинал | Количество | Footprint
MicroSD1 | DM3AT-SF-PEJM5 | 1 | Micro SD - M
B1 батарейка | CR1220 | 1 | CR1220
C1 | 7.5p | 1 | CH0603C
C2, C3 | 22p | 2 | CH0603C
C4, C7, C30, C33, C38, C39, C40, C44, C45, C46, C47, C62, C63, C64, C66, C118, C154, C176, C177, C181, C182, C184, C190, C193 | 0.1u | 24 | CH0603C
C5, C6 | 2u2 | 2 | CH0603C
C8, C37, C85, C155, C157, C164 | 10u | 6 | CH0603C
C9, C10 | 6p | 2 | CH0603C
C11, C12, C13, C14, C15, C16, C17, C18, C19, C20, C21, C22, C23, C24, C25, C26, C27, C28, C29, C54, C55, C56, C67, C76, C79, C80, C82, C83, C84, C86, C88, C89, C90, C91, C92, C93, C94, C95, C96, C97, C98, C101, C102, C103, C105, C108, C110, C112, C114, C115, C116, C117, C120, C122, C123, C124, C125, C126, C127, C128, C129, C130, C131, C132, C133, C183, C187, C207, C208 | 0.1 | 69 | CH0603C
C31, C32, C178, C179, C180 | 10uF10V | 5 | TANTAL_A
C34, C36, C41, C42, C73, C74, C191, C195, C198 | 1u | 9 | CH0603C
C35, C77, C185, C189 | 470p | 4 | CH0603C
C43 | 10p | 1 | CH0603C
C48, C49, C99 | 1n | 3 | CH0603C
C50, C51, C52 | 1uF | 3 | CH0603C
C53, C57, C58 | 220uF | 3 | POLIMER-E
C59, C60, C61, C65 | 10uF10V | 4 | TANTAL_A
C68, C70, C71 | 1uF 10V | 3 | TANTAL_A
C69, C78 | 10n | 2 | CH0603C
C72, C140, C148 | 220p | 3 | CH0603C
C75 | 10uF 10V | 1 | TANTAL_A
C81, C111 | 8.2n | 2 | CH0603C
C87, C221 | 8p | 2 | CH0603C
C100, C107 | 10uF 10V | 2 | TANTAL_B
C104, C137, C153, C220 | 110p | 4 | CH0603C
C106, C212 | 15p | 2 | CH0603C
C109 | 4.7uF 47V | 1 | POLIMER-E
C113 | 22uF 10V | 1 | POLIMER-E
C119, C204 | 120p | 2 | CH0603C
C121, C145, C201, C211 | 100p | 4 | CH0603C
C134, C138, C142, C146, C150 | 180p | 5 | CH0603C
C135, C151 | 51p | 2 | CH0603C
C136, C152 | 390p | 2 | CH0603C
C139, C147 | 43p | 2 | CH0603C
C141, C149 | 91p | 2 | CH0603C
C143, C199 | 47p | 2 | CH0603C
C144 | 330p | 1 | CH0603C
C156, C165, C172, C202 | 33p | 4 | CH0603C
C158, C174 | 39p | 2 | CH0603C
C159, C168 | 20p | 2 | CH0603C
C160, C162, C166, C214 | 22uf | 4 | CH1206C
C161, C170 | 24p | 2 | CH0603C
C163 | 27p | 1 | CH0603C
C167, C169, C171 | 4.7uF | 3 | TANTAL_A
C173, C175, C192, C194 | 6.8n | 4 | CH0603C
C186 | 10n/none | 1 | CH0603C
C188 | 2.7n | 1 | CH0603C
C196, C197 | 680p | 2 | CH0603C
C200, C203 | 6.5-30pF | 2 | C_trimer
FB1, FB2, FB3 | Ferrite_Bead | 3 | CH0805L
FB4, FB5, L2 | BLM21 | 3 | CH0805L
J1 | BOOT | 1 | CON: PLS-2
J2, J4, J5 | PJ-307 | 3 | PJ-307
L1 | 22uH | 1 | 4020
L3, L44 | 330nH | 2 | L1210
L4, L43 | 22nH | 2 | L1210
L5 | 3.3uH | 1 | IND: CDRH74
L6 | 10uH | 1 | IND: CDRH74
L7, L11, L15 | 6.2uH | 3 | L1210
L8, L12, L16 | 2.2uH | 3 | L1210
L9, L13, L17 | 12uH | 3 | L1210
L10, L14, L18 | 3.3uH | 3 | L1210
L19, L24, L28 | 0.68uH | 3 | L1210
L20, L22, L23, L37 | 2.2uH | 4 | 4020
L21, L26, L30 | 1.2uH | 3 | L1210
L31 | 270nH | 1 | L1210
L32, L34, L36 | 8.2nH | 3 | L1210
L33 | 82nH | 1 | L1210
L35 | 100nH | 1 | L1210
L40, L42 | 180nH | 2 | L1210
L41 | 27nH | 1 | L1210
R1, R2, R3, R7, R11, R13, R14, R15, R16, R23, R24, R25, R33, R42, R65, R70, R73, R87, R88 | 10k | 19 | CH0603R
R4, R48 | 11k | 2 | CH0603R
R5, R6, R9, R51, R75, R77 | 22 | 6 | CH0603R
R8, R27, R28 | 3.3К | 3 | CH0603R
R10, R12, R32, R66, R67, R68, R69, R71, R74 | 1k | 9 | CH0603R
R17 | 1.5k | 1 | CH0603R
R18, R78 | 56 | 2 | CH0603R
R19, R20 | 10 | 2 | CH0603R
R21, R22, R54, R80, R81 | 100 | 5 | CH0603R
R26 | 680 | 1 | CH0603R
R29, R30, R31, R36, R55, R56 | 47K | 6 | CH0603R
R34, R35 | none | 2 | CH0603R
R37 | 5.6k | 1 | CH0603R
R38, R39 | 82 | 2 | CH0603R
R40, R41 | 130 | 2 | CH0603R
R43 | 120k +100k parallel | 1 | CH0603R
R44, R45, R46 | 30k | 3 | CH0603R
R47, R49 | 2K | 2 | CH0603R
R50, R53 | 0 | 2 | CH0603R
R52 | 18k | 1 | CH0603R
R57, R58 |  | 2 | CH0603R
R72 | 1k5 | 1 | CH0603R
R82, R83, R84 | 330 | 3 | CH0603R
R85, R86 | 5.6 | 2 | CH0603R
T1 | 1:4 ADT4-6T | 1 | TC4-1-ADT4-6
T2 | 1:1 T1-6T | 1 | TC4-1-ADT4-6
T3 | 1:1 ADT1-1 | 1 | TC4-1-ADT4-6
U1 | W25Q16 | 1 | SOIC-8-1
U2 | STM32H743 | 1 | 100-LQFP
U3 | M25P80 | 1 | SOIC-8-1
U4 | EP4CE22E22C8N | 1 | 144-QFN
U5, U13 | LM1085-3.3 | 2 | DPAK_132
U6 | LTC6400IUD | 1 | 16-QFN 3x3
U7 | LTC2208CUP | 1 | 64-QFN 9x9
U8 | PAM8406 | 1 | SOP-16
U9 | WM8731 | 1 | 28-SSOP
U10 | LD3985M33R | 1 | SOT23-5
U11 | ACS712-20 | 1 | 8-SOIC
U12, U18 | ADG918BRMZ | 2 | 8-MSOP (NO PAD)
U14 | ST1S10 | 1 | 8-SOIC (PAD)
U15, U16 | MCP6001UT | 2 | SOT23-5
U17 | USBLC6-2SC6 | 1 | SOT23-6-ASM
U19 | SC189CSKTRT | 1 | SOT23-5
U20 | PE4302 | 1 | 20-QFN (4x4)
U21, U22, U23, U24 | FST3253 | 4 | 16-SSOP
U25 | AMS1117-1.8 | 1 | SOT223
U26 | AMS1117-3.3 | 1 | SOT223
U27 | DAC5674IPHP | 1 | 48-TQFP
U28 | OPA2673IRGVT | 1 | 16-QFN 4x4 PAD17
U29, U30, U31 | SC189 | 3 | SOT23-5
D2 | BAV-99 | 1 | SOT23_132
VD1, VD2 | 1N4108 | 2 | 1N4148
VD3 | BZT52-C5V1 | 1 | SOD123
VT1 | BSS123 | 1 | SOT23_132
VT2 | IRFR9024NPBF | 1 | D2PAK_132
X1 | USB-B | 1 | CON: USB-B
X2 | PLS-5 | 1 | CON: PLS-5
X3, X4 | PLD-10 | 2 | CON: PLD-10
X5 | CWF-3 | 1 | CON: CWF-3
X6 | Разъем DC005 | 1 | CON: PJ-102AH
X7 | PLD-10 | 1 | CON: PLD-10
X9 | PLS-3 | 1 | CON: PLS-3
X10 | ENCODER_MAIN1 | 1 | CON: PLS-4
X12, X14 | U.FL-R-SMT U FL IPEX | 2 | CON: u.Fl
X13 | "PTT" | 1 | RJ25-6pin
XG1 | 12.288Mhz TCXO 3.3v TTL/CMOS (set other freq in fpga code) | 1 | OSC: 5032
XG2 | 122.88Mhz | 1 | OCS: GENA
Y1 | 8 мГц | 1 | OSC: Hz
Y2 | ABS 32.768khz | 1 | ABS-25

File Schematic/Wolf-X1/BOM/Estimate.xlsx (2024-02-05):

№ | Название | Количество | Цена | доставка | штук | Ссылка | Чип и дип | Общая цена | Доставка
MAIN |  |  |  |  |  |  |  | 346.32 | 39.12
 | DM3AT-SF-PEJM5 | 1 | 2.94 | 0.74 | 10 | Aliexpress (https://s.click.aliexpress.com/e/_9isgm1)
 | Индуктивность SMD 0630 3.3uH | 1 | 0.63 | 0.24 | 10 | Aliexpress (https://aliexpress.ru/item/4000557059726.html?item_id=4000557059726&sku_id=10000002922152209) |  | 385.44
 | Индуктивность SMD 0630 10uH | 1 | 0.63 | 0.24 | 10 | Aliexpress (https://aliexpress.ru/item/4000557059726.html?item_id=4000557059726&sku_id=10000002922152209)
 | Индуктивность SMD 0420 2,2uH | 4 | 1.60 | 1.29 | 10 | Aliexpress (https://aliexpress.ru/item/1005001648530241.html?spm=a2g2w.productlist.0.0.7b42d5be3thNsw) | ChipDip (https://www.chipdip.ru/product/ha72l-04202r2lftr?from=suggest_product)
 | Индуктивность SMD 0530 10uH | 1 | 0.70 | 0.18 | 10 | Aliexpress (https://aliexpress.ru/item/4001035691825.html?item_id=4001035691825&sku_id=10000013672787789)
 | SC189CSKTRT | 4 | 2.75 | 1.23 | 10 | Aliexpress (https://s.click.aliexpress.com/e/_97KRnB) | ChipDip (https://www.chipdip.ru/product0/8001051325?from=suggest_product)
 | LM1085-3.3 | 2 | 0.79 | 0.75 | 1 | Aliexpress (https://s.click.aliexpress.com/e/_A281Oz)
 | ST1S10PHR | 1 | 4.85 | 2.53 | 5 | Aliexpress (https://s.click.aliexpress.com/e/_9g82VX)
 | ACS712-20 | 1 | 4.36 | 2.53 | 5 | Aliexpress (https://s.click.aliexpress.com/e/_ADbq7F)
 | LD3985M33R | 1 | 0.94 |  | 10 | Aliexpress (https://s.click.aliexpress.com/e/_AMh9kh)
 | AMS1117-3.3 | 2 | 0.92 |  | 20 | Aliexpress (https://s.click.aliexpress.com/e/_AeJeaD)
 | AMS1117-1.8 | 1 | 1.18 |  | 20 | Aliexpress (https://s.click.aliexpress.com/e/_AeJeaD)
 | MCP6001UT | 2 | 1.96 |  | 10 | Aliexpress (https://s.click.aliexpress.com/e/_9ihxe9)
 | PE4302 | 1 | 2.31 | 0.65 | 5 | Aliexpress (https://s.click.aliexpress.com/e/_AfZ1iz)
 | NV7050SA 122.88Mhz | 1 | 5.00 | 3.79 | 1 | Aliexpress (https://s.click.aliexpress.com/e/_A5JA5P)
 | 12.288Mhz | 1 | 20.00 | 3.47 | 2 | Aliexpress (https://aliexpress.ru/item/4000577979227.html?sku_id=10000003324946109)
 | PAM8406DR | 1 | 3.00 | 0.74 | 10 | Aliexpress (https://s.click.aliexpress.com/e/_A8j981)
 | M25P80-VMW6G | 1 | 1.45 |  | 10 | Aliexpress (https://s.click.aliexpress.com/e/_A6hL4Z)
 | EP4CE22E22C8N | 1 | 59.85 | 2.11 | 1 | Aliexpress (https://s.click.aliexpress.com/e/_9iUwY9)
 | STM32H743VIT6 | 1 | 17.78 |  | 1 | Aliexpress (https://aliexpress.ru/item/1005003007981742.html?mp=1&sku_id=12000023197731242)
 | 25Q16BVSIG | 1 | 1.37 |  | 5 | Aliexpress (https://s.click.aliexpress.com/e/_AqCio9)
 | WM8731 | 1 | 4.68 | 2.53 | 2 | Aliexpress (https://s.click.aliexpress.com/e/_Akey6D)
 | LTC6400IUD | 1 | 2.85 | 1.24 | 1 | Aliexpress (https://s.click.aliexpress.com/e/_AseOOZ)
 | LTC2208CUP | 1 | 11.05 | 3.16 | 1 | Aliexpress (https://s.click.aliexpress.com/e/_ADIvIz)
 | OPA2673IRGVT | 1 | 4.95 |  | 5 | Aliexpress (https://s.click.aliexpress.com/e/_AAqwKp)
 | DAC5674IPHP | 1 | 14.00 | 3.04 | 1 | Aliexpress (https://s.click.aliexpress.com/e/_9y3KyN)
 | MC306 32,768 кГц | 1 | 1.08 | 0.41 | 10 | Aliexpress (https://aliexpress.ru/item/1994878414.html?sku_id=52635197667)
 | USBLC6-2SC6 | 1 | 1.01 |  | 10 | Aliexpress (https://s.click.aliexpress.com/e/_9xdO4z)
 | hc-49s 8 МГц | 1 | 1.14 | 0.20 | 20 | Aliexpress (https://s.click.aliexpress.com/e/_9QtdNT)
 | USB B типа «мама» | 1 | 1.01 | 0.37 | 10 | Aliexpress (https://s.click.aliexpress.com/e/_A1iVsh)
 | PJ-307 | 3 | 0.73 |  | 10 | Aliexpress (https://s.click.aliexpress.com/e/_AUoOZf)
 | ADG918BRMZ | 2 | 1.17 | 0.20 | 1 | Aliexpress (https://s.click.aliexpress.com/e/_989xMD)
 | FST3253MTCX | 4 | 1.68 |  | 5 | Aliexpress (https://s.click.aliexpress.com/e/_AFJSln)
 |  |  | 180.36 | 31.64
PA UNIT
 | STPIC6C595TTR | 1 | 2.42 | 0.74 | 5 | Aliexpress (https://aliexpress.ru/item/1005001359582377.html?sku_id=12000015804019376)
 | Реле | 4 | 2.73 |  | 5 | Aliexpress (https://aliexpress.ru/item/4000017778928.html?item_id=4000017778928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)
 | MCP3008-I/SL | 1 | 1.45 | 0.20 | 1 | Aliexpress (https://s.click.aliexpress.com/e/_9JQuQz)
 | RA08H1317M | 1 | 12.89 |  | 1 | Aliexpress (https://s.click.aliexpress.com/e/_A64gRR)
 | RJ12 6pin | 1 | 1.83 |  | 10 | Aliexpress (https://s.click.aliexpress.com/e/_AmN5bL)
 | PGA-103+ | 1 | 2.20 | 1.58 | 1 | Aliexpress (https://s.click.aliexpress.com/e/_9hNUwN)
 | AMS117-ADJ-8V | 1 | 0.99 |  | 20 | Aliexpress (https://s.click.aliexpress.com/e/_9x7Ew5)
 | AMS1117-5 | 1 | 0.99 |  | 20 | Aliexpress (https://s.click.aliexpress.com/e/_A60xMl)
 | Кнопки 4x4х3.5 мм | 7 | 1.67 | 0.74 | 50 | Aliexpress (https://s.click.aliexpress.com/e/_9HYNvf)
 | BN-43-302 | 1 | 0.80 |  | 1 | cqradio.ru (http://cqradio.ru/products/bn-43-302)
 | BN-43-202 | 1 | 0.94 |  | 1 | cqradio.ru (http://cqradio.ru/products/bn-43-202)
 | FT23-43 | 1 | 0.25 |  | 1 | cqradio.ru (http://cqradio.ru/products/ft-23-43)
 | T37-6 | 3 | 0.80 |  | 3 | cqradio.ru (http://cqradio.ru/products/t37-6)
 | RD16 | 2 | 8.00 |  | 2 | CihpDip (https://www.chipdip.ru/product/rd16hhf1-101?from=suggest_product)
 | RD01 | 2 | 1.95 |  | 5 | Aliexpress (https://s.click.aliexpress.com/e/_A4k9sN)
 |  |  | 39.91 | 3.26
Разное
 | Корпус | 1 | 10.38 |  | 1 | Aliexpress (https://s.click.aliexpress.com/e/_ADzTtP)
 | Динамики AIYIMA, 27 мм | 1 | 5.04 | 1.46 | 2 | Aliexpress (https://s.click.aliexpress.com/e/_A2uQWH)
 | Валкодер EC11 | 1 | 1.97 |  | 5 | Aliexpress (https://s.click.aliexpress.com/e/_A7EsjB)
 | Валкодер ENS1D-441-M00128 | 1 | 14.25 |  | 1 | Aliexpress (https://aliexpress.ru/item/1005003171237807.html?bizType=ProductDetail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)
 | Дисплей 1.8, 128x160 | 1 | 4.19 |  | 1 | Aliexpress (https://aliexpress.ru/item/32996979276.html?item_id=32996979276&sku_id=67278796295)
 | Тангента MH-48 | 1 | 10.15 |  | 1 | Aliexpress (https://aliexpress.ru/item/1005001706845338.html?sku_id=12000017235262329)
 | U.FL-R-SMT | 4 | 0.70 | 0.80 | 10 | Aliexpress (https://s.click.aliexpress.com/e/_AOLDKD)
 | Кабель 10см IPEX U.fl | 2 | 4.87 |  | 10 | Aliexpress (https://s.click.aliexpress.com/e/_ACJlXT)
 | UHF SO-239 | 1 | 0.48 | 0.63 | 1 | Aliexpress (https://s.click.aliexpress.com/e/_AUVL2p)
 | ESP8266 ESP-07 | 1 | 1.50 | 0.20 | 1 | Aliexpress (https://s.click.aliexpress.com/e/_A6cNcd)
 | Диоды LL4148 | 5 | 0.53 | 0.37 | 50 | Aliexpress (https://s.click.aliexpress.com/e/_AOTU3P)
 | Конденсаторы 100n |  | 15.71 |  | 4000 | Aliexpress (https://s.click.aliexpress.com/e/_A1oQBJ)
 | Диоды SS14 | 3 | 1.28 | 0.76 | 100 | Aliexpress (https://s.click.aliexpress.com/e/_9IueWH)
 | Набор плат + активация |  | 55.00 |  |  | Telegramm (https://t.me/Wolf_X1)
 |  |  | 126.05 | 4.22

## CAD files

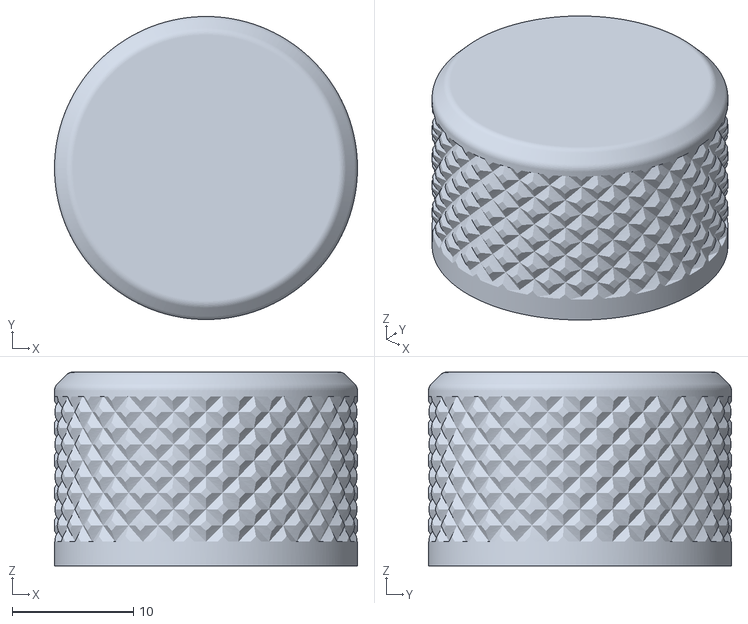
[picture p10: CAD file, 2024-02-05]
Schematic/Wolf-X1/Addons/20mm_Main_Encoder.stl
25.0 x 25.0 x 16.0

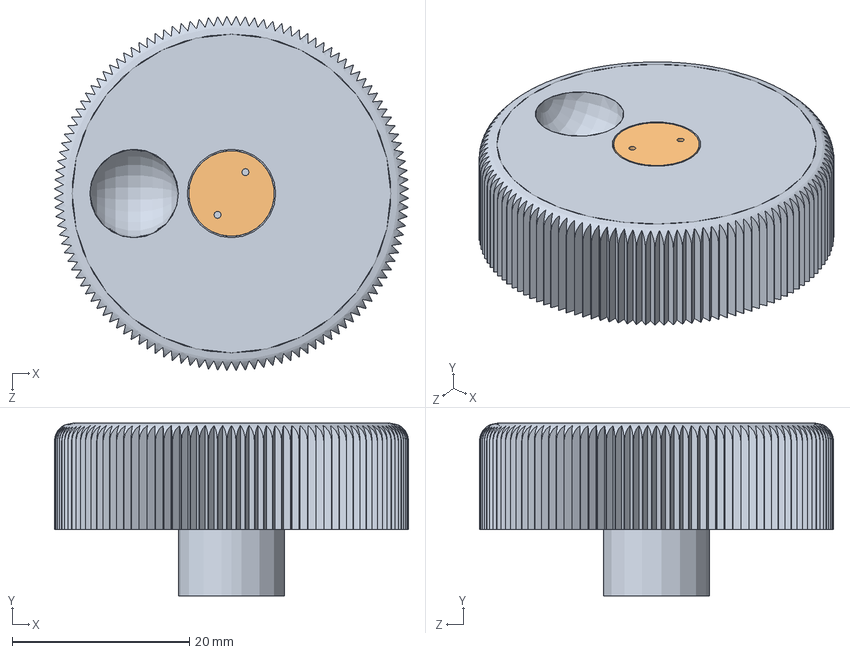
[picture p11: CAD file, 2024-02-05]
Schematic/Wolf/CASE/3'2/3DPrinter/case/shuttle_knob_construct.SLDASM
40.0 x 19.5 x 40.0 mm
shuttle_knob
shuttle_knob_cap

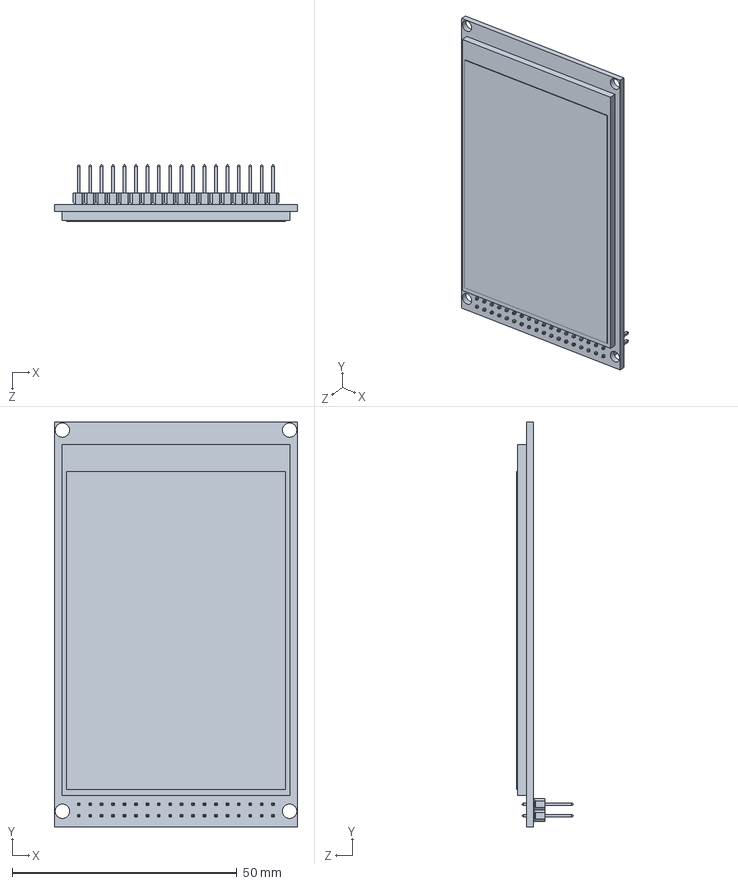
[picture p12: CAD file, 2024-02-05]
Schematic/Wolf/CASE/3'2/3DPrinter/Display480x320.SLDASM
54.1 x 90.0 x 12.6 mm

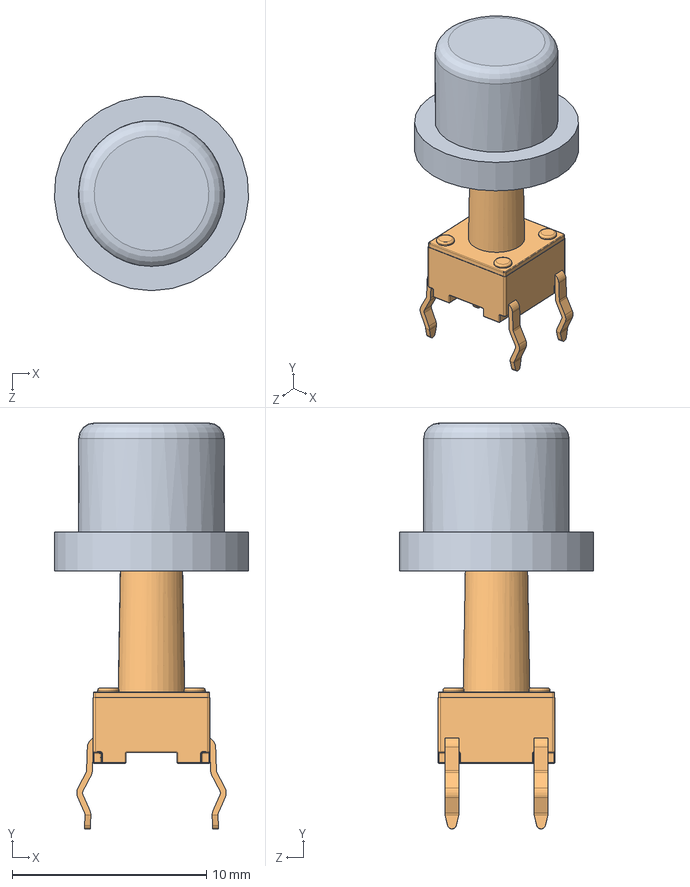
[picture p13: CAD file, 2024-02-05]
Schematic/Wolf/CASE/3'2/3DPrinter/case/button_construct.SLDASM
9.99 x 20.9 x 10.0 mm
button
tactileswitch-long

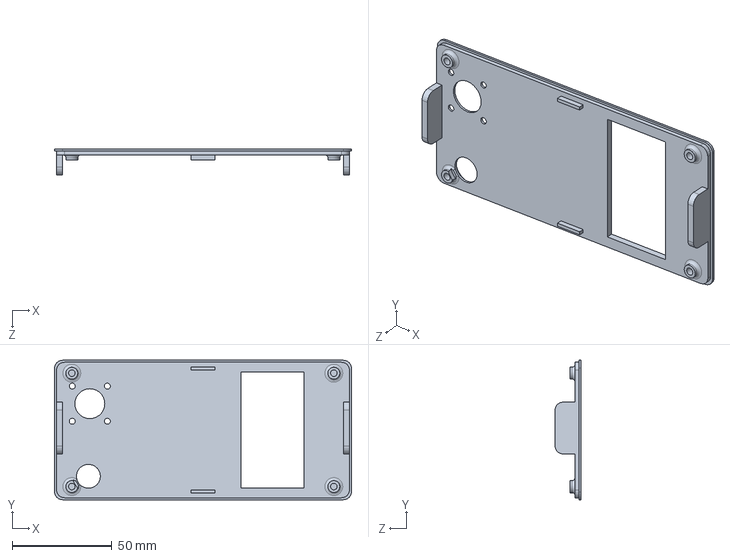
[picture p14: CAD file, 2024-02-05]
Schematic/Wolf-Lite/Case/Bot/BOT-LITE.SLDPRT
149.0 x 70.0 x 13.0 mm

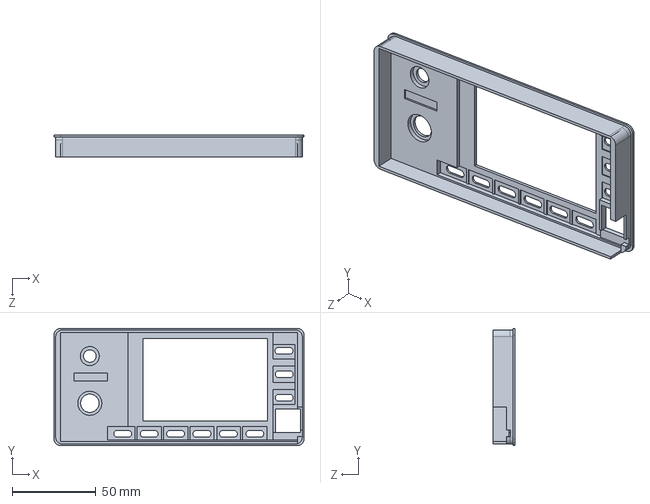
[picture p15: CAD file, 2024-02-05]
Schematic/Wolf-Lite/Case/Front/Front Lite V1.SLDPRT
149.0 x 70.0 x 13.0 mm

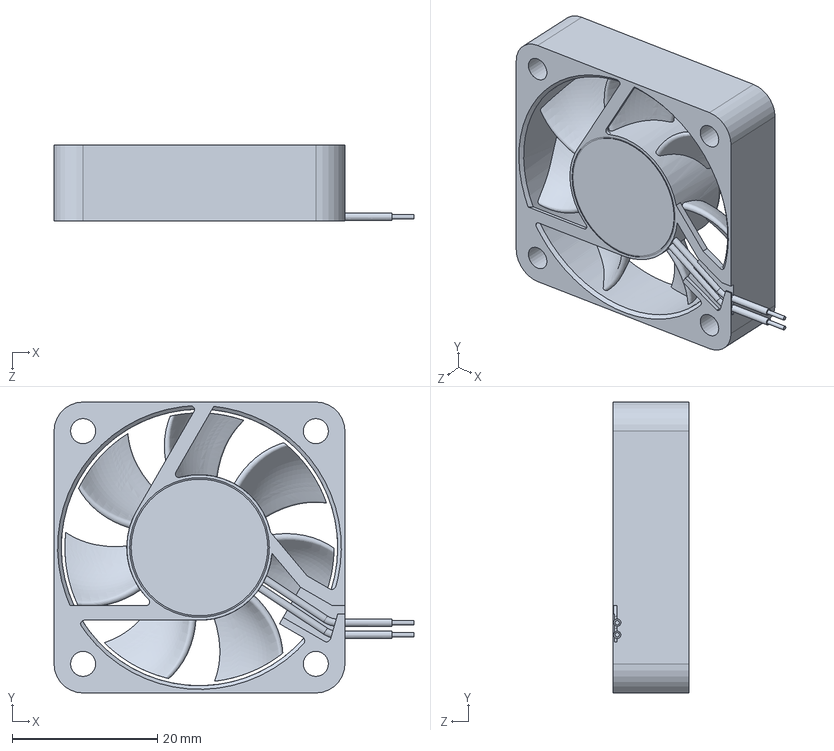
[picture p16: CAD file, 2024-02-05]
Schematic/Wolf/CASE/3'2/3DPrinter/40x40x10 DC Fan.SLDPRT
49.5 x 40.0 x 10.5 mm

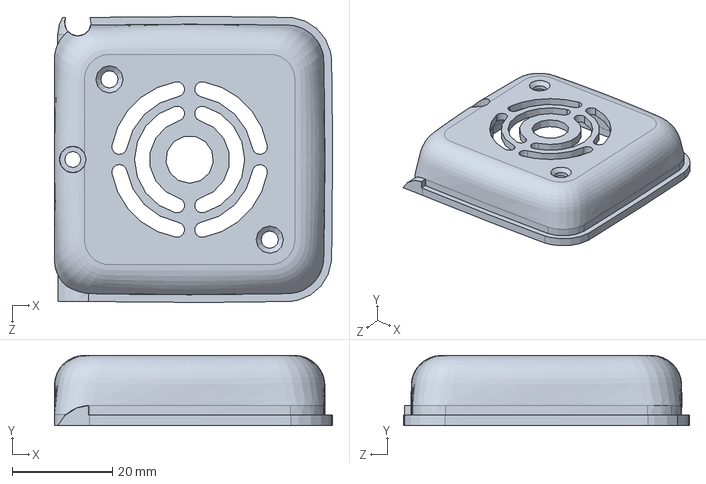
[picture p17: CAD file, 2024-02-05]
Schematic/Wolf/CASE/3'2/3DPrinter/case/case_cooller.SLDPRT
55.5 x 14.0 x 57.1 mm

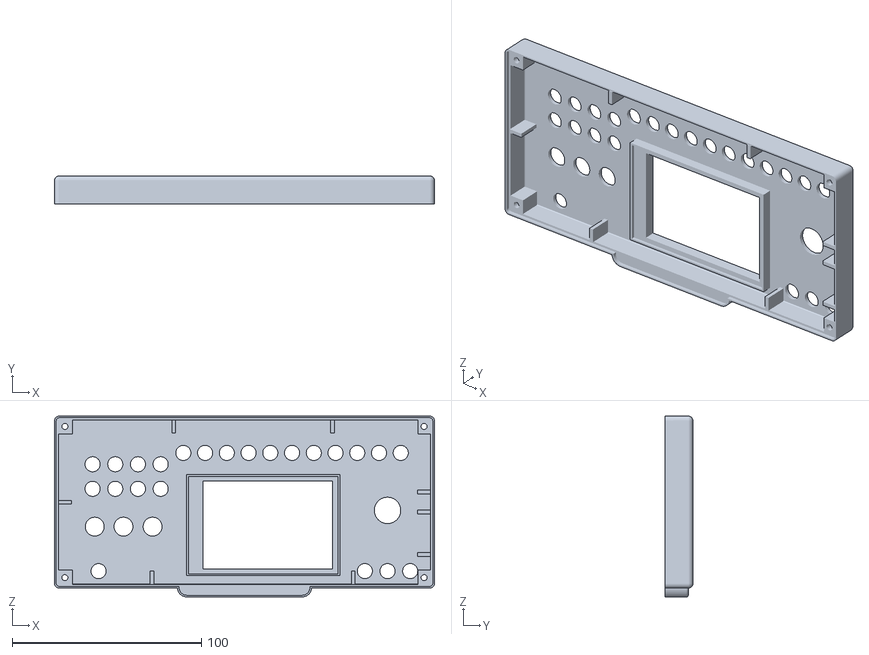
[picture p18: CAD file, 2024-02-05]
Schematic/Wolf/CASE/3'2/3DPrinter/STL/case_front.STL
201.0 x 14.8 x 95.7

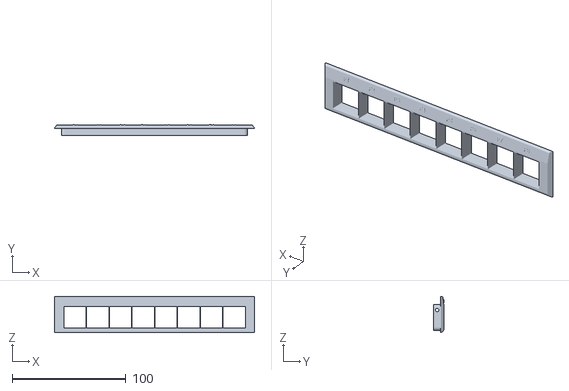
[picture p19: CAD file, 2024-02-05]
Schematic/Wolf/CASE/7/Panel/рамка_низ_7.stl
176.0 x 9.31 x 32.0

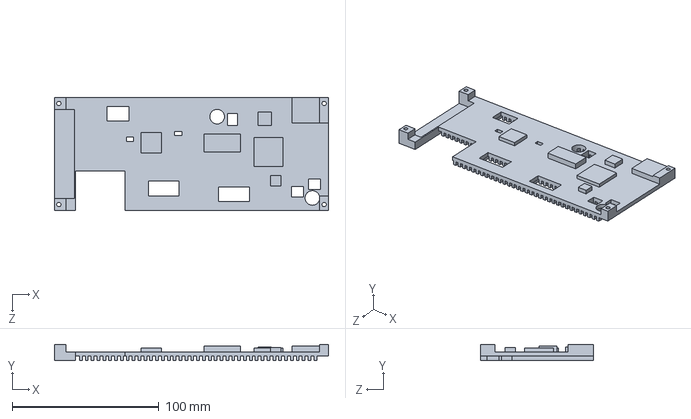
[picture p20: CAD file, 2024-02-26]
Schematic/Wolf/CASE/MotherboardHeatSink/HeatSink.SLDPRT
187.0 x 11.0 x 77.0 mm

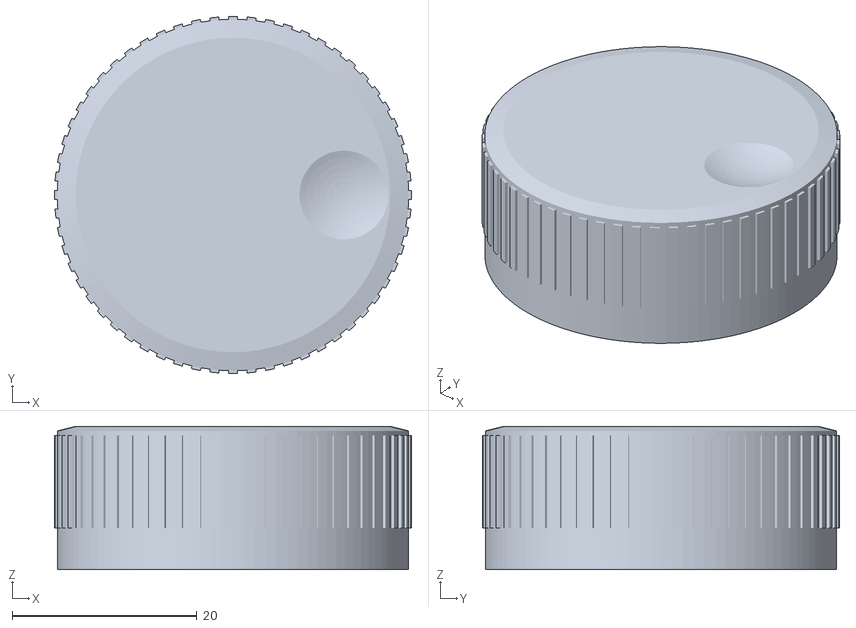
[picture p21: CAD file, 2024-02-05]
Schematic/Wolf/CASE/VFO/VFO_38mm.stl
38.6 x 38.6 x 15.5

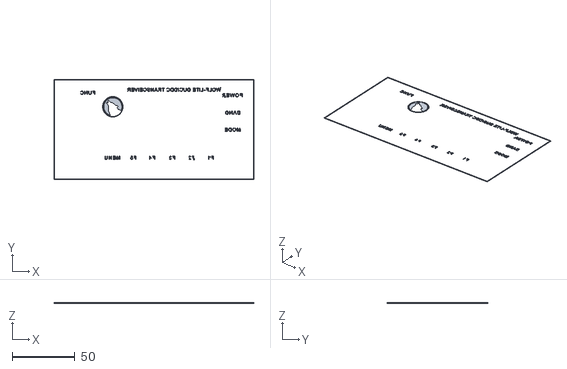
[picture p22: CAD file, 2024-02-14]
Schematic/Wolf-Lite/Case/Front3/Mirror_Wolf_txt_arial_2.9.stl
160.0 x 80.0 x 0.22

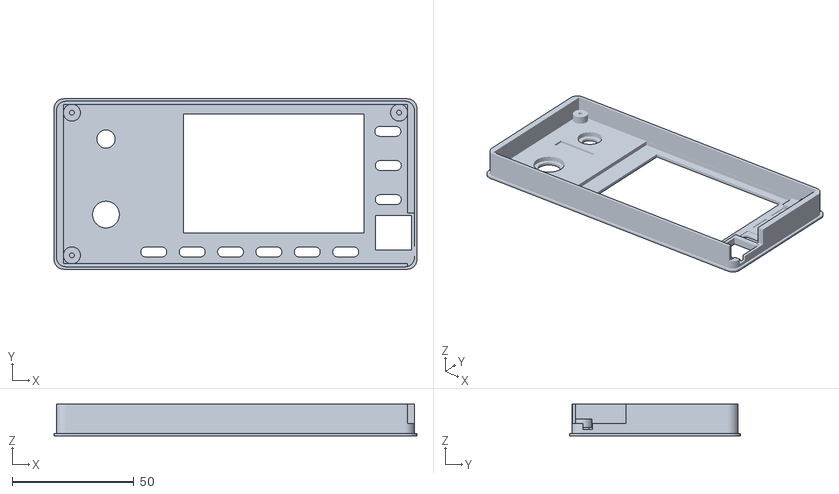
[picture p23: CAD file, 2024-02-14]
Schematic/Wolf-Lite/Case/Front4/Front Lite V1.1.STL
149.0 x 70.0 x 13.0

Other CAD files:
Schematic/Wolf/CASE/3'2/3DPrinter/KY-040 Rotary Encoder.SLDASM
Schematic/Wolf-Lite/Case/Front2/Front Lite V2.SLDPRT
Schematic/Wolf-Lite/Case/Front3/Front Lite V2.SLDPRT
Schematic/Wolf-Lite/Case/Front4/Front Lite V1.SLDPRT
Schematic/Wolf-Lite/Altium_Designer/Front-Unit/Wl-FRONT-EDM/16-SOIC_MCP3008-I_SL.x_t
Schematic/Wolf-Lite/Altium_Designer/Front-Unit/Wl-FRONT-EDM/BAT__CH224-2032_POWER_BAT.x_t
Schematic/Wolf-Lite/Altium_Designer/Front-Unit/Wl-FRONT-EDM/BUT__6x6_SMD_Tactile_switches.x_t
Schematic/Wolf-Lite/Altium_Designer/Front-Unit/Wl-FRONT-EDM/BUT__6x6_Tactile_switches.x_t
Schematic/Wolf-Lite/Altium_Designer/Front-Unit/Wl-FRONT-EDM/CH0805C_Capacitor.x_t
Schematic/Wolf-Lite/Altium_Designer/Front-Unit/Wl-FRONT-EDM/CH0805R_Resistor.x_t
Schematic/Wolf-Lite/Altium_Designer/Front-Unit/Wl-FRONT-EDM/CON__PLS-5_5-Connector.x_t
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

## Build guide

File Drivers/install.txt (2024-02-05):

This driver uses windows USB Virtual com port driver files
If it;s dont work, please update system drivers from https://my.st.com/content/my_st_com/en/products/development-tools/software-development-tools/stm32-software-development-tools/stm32-utilities/stsw-stm32102.html

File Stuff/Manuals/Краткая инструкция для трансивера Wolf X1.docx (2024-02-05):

# Краткая инструкция для трансивера Wolf X1

Телеграм канал сообщества: https://t.me/TRX_Wolf

Владельцы TRX Волк, разрешившие добавить себя на карту: https://www.google.com/maps/d/u/0/viewer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

## Принцип работы

ВЧ сигнал оцифровывается высокоскоростной микросхемой АЦП, и подаётся на FPGA процессор.

В нём происходит DDC/DUC преобразование (цифровое смещение частоты вниз или вверх по спектру) - по аналогии с приёмником прямого преобразования.

I и Q квадратурные сигналы, полученные в ходе преобразований, поступают на микропроцессор STM32.

В нём происходит фильтрация, (де)модуляция и вывод звука на аудио-кодек/USB. Также он обрабатывает весь пользовательский интерфейс.

При передаче процесс происходит в обратном порядке, только в конце цепочки стоит ЦАП, преобразующий цифровой сигнал обратно в аналоговый ВЧ.

## Технические характеристики

- Частоты приёма: 0 MHz - 750 MHz
- Частоты передачи: 0 MHz - 160 MHz
- Мощность TX: 15W (HF), 5-8W (VHF)
- Виды модуляции (TX/RX): CW, LSB, USB, AM, SAM, FM, WFM, DIGI
- МШУ(LNA) и Предусилитель
- Регулируемый аттенюатор на 0-31дБ
- Диапазонные полосовые фильтры
- Динамический диапазон АЦП (16 бит) ~100дБ
- Напряжение питания: 13.8в
- Потребляемый ток при приёме: ~0.5А
- Потребляемый ток при передаче: ~3.5А+

## Функции трансивера

- Панорама (спектр+водопад) шириной до 384 кГц
- Несколько видов оформления спектра
- Двойной приёмник (смешивание звука A+B или A&B в стерео)
- Регулируемая полоса пропускания: ФВЧ от 0гц до 600гц, ФНЧ от 100гц до 20кГц
- Встроенный КСВ/Power метр (КВ)
- Автоматический и ручной Notch фильтр
- Отключаемое АРУ (AGC) с регулируемой скоростью атаки
- Карта диапазонов, с возможностью автоматического переключения моды
- Цифровое уменьшение шумов (DNR), подавитель импульсных помех (NB)
- CAT виртуальный COM-порт (эмуляция FT-450)
- Работа по USB (передача звука, CAT, KEY, PTT)
- RDS/CW/RTTY декодер, самоконтроль, гаусс-фильтр
- Построение графиков КСВ по диапазонам
- Анализатор спектра
- Эквалайзер TX/RX, ревербератор
- SSB/FM Режим сканера
- Режим WSPR маяка
- Поддержка SDHC/SDSC/SDXC карт памяти до 16 Гб
- Цифровой магнитофон, проигрывание быстрого сообщения в эфир
- AGC учитывает особенности человеческого слуха (K-Weighting)
- TCXO стабилизация частоты
- Работа по WiFi: Синхронизация времени, виртуальный CAT-интерфейс (см. Scheme/WIFI-CAT-instruction.txt), WiFi сервисы
- Поддержка тангенты Yaesu MH-48
- Режим аппаратной самодиагностики
- Обновление прошивки по USB, SD, WiFi
- И другое (см. работу с меню)

## Органы управления

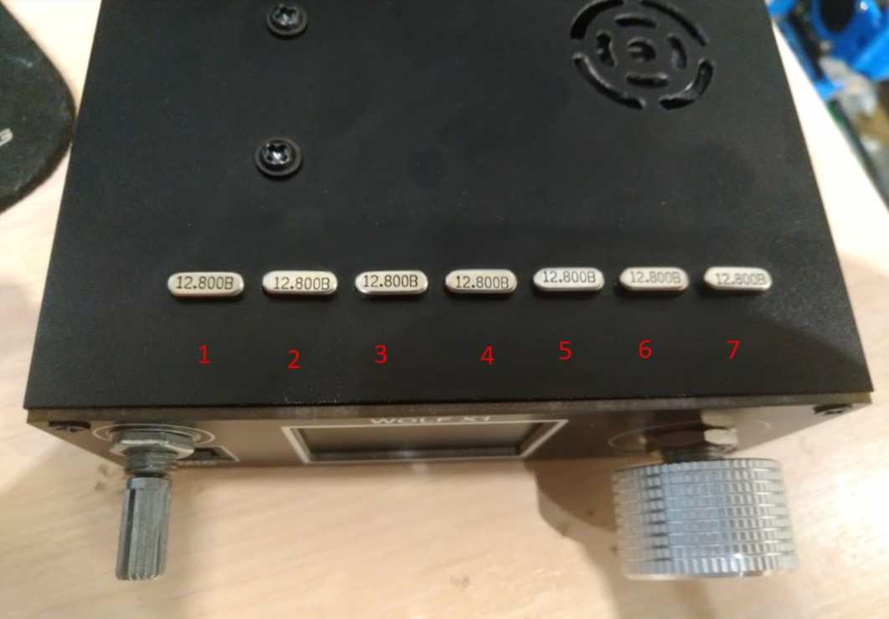
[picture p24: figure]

Назначение кнопок:

- 1 – включение/отключение
- 2,3,4,5 – функциональные кнопки, меняющие своё назначение в зависимости от режима
- 6 – PTT (на случай использования с внешней гарнитурой или при отсутствии тангенты)
- 7 – вход/выход в меню
- 1+2 (при включении) – переход в режим прошивки
- 1+7 (при включении) – сброс настроек на «по умолчанию»
- 1+5+7 (при включении) – сброс настроек и калибровки трансивера

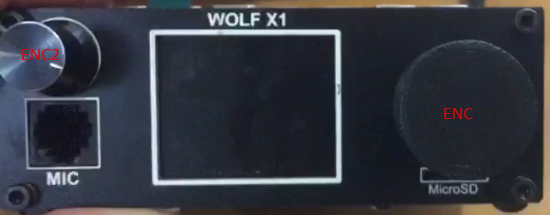
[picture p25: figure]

- MIC – разъём для тангенты Yaesu MH-48
- MicroSD – слот для SD карты
- ENC – основной энкодер для управления частотой трансивера
- ENC2 – второстепенный энкодер для выбора режима, регулировки параметров и навигации по меню.

Нажатие на энкодер меняет режим управления: выбор функциональных клавиш, быстрый переход по частоте, управление громкостью. Выбранный режим подсвечивается на экране, а дальнейшее вращение регулирует выбранный параметр или листает функциональные кнопки. Это основной орган управления параметрами трансивера.

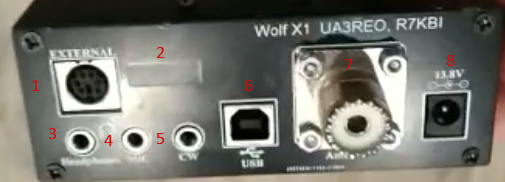
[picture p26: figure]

1. Разъём для управления периферией (УМ, ФНЧ, Тюнер)
2. Антенна WiFi (напечатана с обратной стороны)
3. Разъём для наушников
4. Разъём для микрофона
5. Разъём для телеграфного ключа
6. Разъём для подключения к компьютеру
7. Антенный разъём
8. Разъём питания

## Интерфейс трансивера

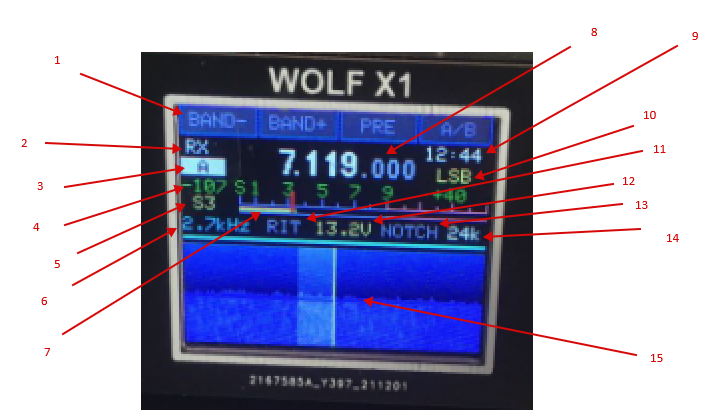
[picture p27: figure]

1. Выбранные функциональные клавиши и их статус (листаются с помощью ENC2)
2. Режим TX/RX
3. Текущий VFO (A или B), либо их смесь в режиме SO2R (A+B - оба VFO в двух звуковых каналах, A&B – VFO-A в левом наушнике, VFO-B в правом)
4. Уровень сигнала в dBm
5. Рапорт для оператора
6. Текущая полоса (раздельные для приёма и передачи)
7. S-метр уровня сигнала
8. Текущая частота
9. Текущее время (устанавливается вручную или синхронизируется по WiFi)
10. Текущая мода
11. Режимы RIT: CLAR – приём на текущем VFO, передача на втором SHIFT – отстройка приёмника (передатчик остаётся на выбранной частоте), при включении регулируется основным энкодером
12. Текущее напряжение/ток
13. Режим Notch-фильтра: выключен/авто/ручной
14. Выбранная ширина полосы
15. FFT(спектр) и водопад, над ним расположена цветовая линия, отображающая границы моды/диапазона

## Функциональные клавиши

Для выбора функциональных клавиш необходимо нажатием ENC2 добиться чтобы они зажглись, далее вращением ENC2 выбрать нужные функциональные кнопки. Их активация происходит нажатием на аппаратные кнопки сверху трансивера.

- BAND- - выбор бенда вниз
- BAND+ - выбор бенда вверх
- PRE – включение предусилителя для ВЧ бендов и УКВ
- A/B – переключение банков VFO
- MODE- - выбор группы моды (FM/SSB/CW и т.д.)
- MODE+ - выбор моды внутри группы (например NFM/WFM, LSB/USB)
- TUNE – режим настройки. В этом режиме выключена защита по КСВ и УМ отдаёт выставленную мощность, рекомендуется для запуска авто-тюнера. При обычной работе трансивер сбрасывает мощность при выходе за КСВ 3.
- POWER – выбор выходной мощности в %, не рекомендуется работа с постоянной несущей на полной мощности из-за перегрева элементов.
- NOTCH – короткое нажатие – включение автоматического нотч-фильтра, длинное - ручного
- ATT – включение аттенюатора
- DRV – включение драйвера АЦП по приёму (усилитель на +20дб)
- PGA – включение встроенного драйвера в АЦП
- AGC – включение АРУ
- IF – регулировка усиления по ПЧ (до АРУ, чтобы выставить шум на минимум, иначе АРУ начнёт его вытягивать)
- DNR1 – первый этап шумоподавителя, DNR2 – второй этап шумоподавителя (самый мощный, порог срабатывания регулируется в настройках, если переборщить – будет булькающий звук)
- FAST – режим ускоренной регулировки частоты основным ENC
- SQL – Squelch, отключение приёмника пока не появится голос или мощный сигнал
- BW – регулировка полосы приёма и передачи
- SCAN – сканирование диапазона в поисках сигнала
- SERV – переход в меню сервисов (описание ниже)
- WPM – регулировка скорости автоматического ключа
- SHIFT – короткое нажатие – включение расстройки по приёму, длительное – CLAR
- PLAY – воспроизведение записанного на SD карту CQ Message (записывается в сервисном меню)
- REC – запись эфира на SD карту
- SMPL- - уменьшение частоты семплирования и полосы обзора на водопаде
- SMPL+ - увеличение частоты семплирования и полосы обзора на водопаде
- ZOOM- - отдаление сигнала на водопаде
- ZOOM+ - приближение сигнала на водопаде ZOOM и SMPL можно использовать совместно. Для WFM не рекомендуется снижать частоту семплирования (полоса сигнала не будет попадать в приёмник полностью).
- VLT – переключение между отображением потребляемого напряжения/тока.
- AUTOGN – позволить трансиверу управлять ATT, DRV, PGA самому в зависимости от ситуации, блокирует управление этими функциями со стороны пользователя
- B=A – копирвоание информации в соседний VFO
- LOCK – блокировка управления трансивера

## Меню настроек

### TRX Settings

RF Power - Мощность передачи, %

Channel Mode - Канальный режим работы (для LPD/PMR и подобных)

Band Map - Карта диапазонов, автоматически переключает моду в зависимости от частоты

AutoGainer - Автоматическое управление ATT/PREAMP в зависимости от уровня сигнала на АЦП

RF Filters - Управление аппаратными фильтрами (LPF/HPF/BPF)

Two Signal tune - Двухсигнальный генератор в режиме TUNE (1+2кГц)

Shift Interval - Диапазон расстройки SHIFT (+-)

TRX Samplerate - Максимальная ширина панорамы в модах CW/SSB/NFM/DIGI и др.

FM Samplerate - Максимальная ширина панорамы в моде NFM/WFM

Freq Step - Шаг перестройки частоты основным энкодером

Freq Step FAST - Шаг перестройки частоты основным энкодером в режиме FAST

Freq Step ENC2 - Шаг перестройки частоты основным доп. энкодером

Freq Step ENC2 FAST - Шаг перестройки частоты основным доп. энкодером в режиме FAST

CW Freq Step divider - Делитель шага перестройки частоты для CW моды

Encoder Accelerate - Ускорение энкодера на больших оборотах

Att step, dB - Шаг перестройки аттенюатора

DEBUG Type - Вывод отладочной и служебной информации в USB/UART порты

Input Type - Выбор аудио входа (микрофон, линейный вход, USB)

Callsign - Позывной пользователя

Locator - QTH локатор пользователя

Transverter Enable - Включить управление внешним трансвертером

Transverter Offset, mHz - Смещение частоты внешнего трансвертера, мГц

### AUDIO Settings

IF Gain, dB - Усиление ПЧ

AGC Gain target, LKFS - Максимальное усиление AGC (максимальная громкость при включенном АРУ)

Mic Gain - Усиление микрофона

Mic Boost - +20db аппаратного усиления микрофона

DNR xxx - Подстройка цифрового шумоподавителя

SSB HPF Pass - Частота среза ФВЧ при работе в SSB

SSB LPF Pass - Частота среза ФНЧ при работе в SSB

CW LPF Pass - Частота среза ФНЧ при работе в CW

DIGI LPF Pass - Частота среза ФНЧ при работе в DIGI

FM LPF Pass - Частота среза ФНЧ при работе в FM

Squelch - SSB/FM Шумодав

FM Squelch level - Уровень шумодава FM

MIC EQ xxx - Уровни эквалайзера микрофона

MIC Reverber - Ревербератор микрофона

RX EQ xxx - Уровни эквалайзера приёмника

RX AGC Speed - Скорость срабатывания АРУ (автоматического регулятора уровня сигнала) на приём (больше-быстрее)

RX AGC Max gain - Максимальный уровень усиления при работе AРУ, дБ

RX AGC Hold time - Время перед отпусканием усиления АРУ в пиках сигнала, мс

TX Compressor Speed - Скорость срабатывания АРУ/компрессора на передачу (больше-быстрее)

TX Compressor MaxGain - Максимальное усиление для компрессора

Beeper - Звук нажатия клавиш

CTCSS Frequency - Частота передачи CTCSS субтона для FM

SelfHear Volume - Регулировка громкости самоконтроля относительно общей громкости трансивера

WFM Stereo - Выбор между моно и стерео декодером WFM

### CW Settings

CW Key timeout - Время до остановки режима передачи после отпускания ключа

CW Pitch - Отстройка генератора приёма от частоты передачи

CW Self Hear - Самоконтроль CW (слышно нажатие ключа)

CW Keyer - Автоматический ключ

CW Keyer WPM - Скорость ключа, WPM

CW Gauss filter - Использовать фильтр с распределением Гаусса (для CW), принимает только пик в центре полосы

CW DotToDash Rate - Соотношение длинны тире к точке

CW Iambic Keyer - Режим ямбического ключа

CW Key Invert - Инвертировать точку/тире на ключе

CW PTT Type - Режим перехода на передачу CW: от ключа или от сигнала PTT

### SCREEN Settings

FFT Zoom - Приближение спектра FFT

FFT Zoom CW - Приближение спектра FFT для CW моды

Color Theme - Выбор темы цветового оформления (0 - черная, 1 - белая, 2 - черная с цветными цифрами)

FFT Speed - Скорость отображения FFT и водопада

FFT Automatic - Автоматическая подстройка шкалы FFT

FFT Sensitivity - Верхний уровень чувствительности автоподстройки FFT (чем меньше - тем сигналы контрастней, 30 - выравнивание по сильнейшему сигналу)

FFT Manual Bottom, dBm - Нижний порог чувствительности FFT при ручной настройке

FFT Manual Top, dBm - Верхний порог чувствительности FFT при ручной настройке

FFT Height - Пропорциональная высота отображения FFT и водопада

FFT Style - Стиль FFT: 1(градиент), 2(заливка), 3(точки), 4(контур)

FFT Color - Цвета FFT и водопада: 1(синий -> желтый -> красный), 2(чёрный -> желтый -> красный), 3(чёрный -> желтый -> зеленый), 4(чёрный -> красный), 5(чёрный -> зеленый), 6(чёрный -> синий), 7(чёрный -> белый)

FFT Freq Grid - Сетка на FFT и водопаде: 1(нет сетки), 2(сетка на FFT), 3(сетка на FFT и водопаде), 4(сетка на водопаде)

FFT dBm Grid - Сетка мощности сигнала на FFT

FFT Background - Градиентный фон за спектром

FFT Lens - Режим линзы (увеличения центра спектра)

FFT Hold Peaks - Отображать пики сигнала на спектре

FFT 3D Mode - Режим 3D FFT 3D (0 - выкл, 1 - линии, 2 - пиксели)

FFT Enabled - Включение водопада и FFT

WTF Moving - Смещение водопада вместе с изменением частоты

FFT Compressor - Сжимать пики при перегрузке FFT

FFT Averaging - Уровень усреднения всплесков FFT

FFT Window - Выбор окна FFT (1-Dolph–Chebyshev 2-Blackman-Harris 3-Nutall 4-Blackman-Nutall 5-Hann 6-Hamming 7-No window)

FFT DXCluster - Отображать данные из кластера поверх спектра

FFT DXCluster Azimuth - Добавить данные об азимуте к DX-кластеру

FFT DXCluster Timeout - Таймаут отображаемых спотов из DX-кластера в минутах

Show Sec VFO - Отображать положение второго VFO на спектре

### Decoders

CW Decoder - Программный декодер CW приёма

RDS Decoder - Включить RDS декодер для WFM моды

RTTY Speed - Скорость данных для RTTY декодера

RTTY Shift - Разнос сигналов в полосе RTTY

RTTY Freq - Центральная частота декодирования RTTY

RTTY StopBits - RTTY стоп-биты

RTTY InvertBits - Инверсия битов RTTY

### ADC/DAC Settings

ADC Driver - Включение предусилителя-драйвера АЦП

ADC Preamp - Включение предусилителя, встроенного в АЦП

ADC Dither - Включение дизеринга АЦП для приёма слабых сигналов

ADC Randomizer - Включение шифрования цифровой линии АЦП

ADC Shutdown - Выключение АЦП

### WIFI Settings

WIFI Enabled - Включение WiFi модуля (нужен перезапуск)

WIFI Network - Выбор точки доступа WiFi

WIFI Network Pass - Установка пароля для точки доступа WiFi

WIFI Timezone - Временная зона (для обновления времени через интернет)

WIFI CAT Server - Сервер для приёма CAT команд по WIFI

WIFI Update ESP firmware - Запуск автообновления прошивки ESP-01 через интернет (если доступно)

### SD Card

USB SD Card Reader - Режим SD картридера по USB

Export Settings - Экспорт настроек и калибровок на SD карту

Import Settings - Импорт настроек и калибровок с SD карты

Format SD card - Форматирование SD карты

### Set Clock Time

Установка часов

### DFU Mode

Запуск DFU режима для обновления прошивки STM32 по USB

### OTA Update

Запуск обновления прошивка FPGA/STM32 через интернет

### System info

Вывод системной информации

## Сервисы (меню Services)

### Spectrum Analyzer

Spectrum START - Запуск спектрального анализатора

Begin, kHz - Стартовая частота анализатора с шагом в 1kHz

End, kHz - Конечная частота анализатора с шагом в 1kHz

Top, dBm - Верхний порог графика

Bottom, dBm - Нижний порог графика

### WSPR Beacon

WSPR Beacon START - Запуск маячка WSPR

Freq offset - Смещение относительно центра диапазона WSPR

WSPR Band xxx - Выбор диапазонов для работы маячка

### DX Cluster

Отображение данных по текущему диапазону из DX кластера (требуется подключение к интернету)

### SWR Analyser

Запуск анализатора КСВ (Band SWR - по диапазону, HF SWR - по всем КВ диапазонам, Custom SWR - в выбранных границах)

### RDA Statistics

Отображение статистики по диплому RDA (требуется подключение к интернету)

### File Manager

Запуск файлового менеджера по SD карте памяти, функции проигрывания и удаления файлов

### Record CQ message

Запись короткого сообщения для быстрой передачи в эфир кнопкой Play

### Self Test

Запуск системы аппаратной самодиагностики

## Calibration [появляется при долгом нажатии кнопки MENU в меню настроек]

Encoder invert - Инвертировать вращение основного энкодера

Encoder2 invert - Инвертировать вращение дополнительного энкодера

Encoder debounce - Время устранения дребезга контактов основного энкодера

Encoder2 debounce - Время устранения дребезга контактов дополнительного энкодера

Encoder slow rate - Коэффициент замедления основного энкодера

Encoder on falling - Энкодер срабатывает только на падение уровня A

Encoder acceleration - Ускорение энкодера при быстром вращении

RF-Unit Type - Тип RF-Unit платы (QRP / BIG)

Tangent Type - Выбор испольуземой тангенты

CICCOMP Shift - Битовое смещение после CIC компенсатора

TX CICCOMP Shift - Битовое смещение после TX CIC компенсатора

DAC Shift - Битовое смещение выхода на ЦАП

RF GAIN xxx - Калибровка максимальной выходной мощности на каждый диапазон. Калибровка RF GAIN 0-100% - 50% мощности драйвера, 101-200% - 75% мощности драйвера, 201-300% - 100% мощности драйвера.

S METER - Калибровка S-метра

ADC OFFSET - Калибровка смещения АЦП

LPF END - Параметры ФНЧ фильтра

BPF x - Параметры полосовых фильтров

HPF START - Параметры ФВЧ фильтра

MAX RF Power - Максимальная выходная мощность (для индикации)

SWR FWD/REF RATE - Подстройка коэффициента трансформации SWR-метра для падающей и отраженной волны

VCXO Correction - Подстройка частоты опорного генератора

FAN Medium start - Температура оконечного каскада для запуска вентилятора на средней скорости

FAN Medium stop - Температура оконечного каскада для остановки вентилятора

FAN Full start - Температура оконечного каскада для запуска вентилятора на полной скорости

MAX RF Temp - Максимальная температура оконечного каскада перед срабатыванием защиты

MAX SWR - Максимальное КСВ перед срабатыванием защиты

FM Deviation Scale - Усиление девиации в TX FM режиме

SSB Power addition - Прибавка к выходной мощности в режиме SSB, %

AM Modulation Index - Глубина модуляции TX AM

TUNE Max Power - Максимальная мощность в режиме настройки

RTC COARSE CALIBR - Грубая калибровка часового кварца, при больших отклонениях

RTC FINE CALIBR - Калибровка часового кварца, одно деление равняется 0.954 ppm

EXT xxx - Управление комбинациями порта External в зависмости от диапазона (EXT3, EXT2, EXT1, EXT0) - открытый коллектор

NOTX xxx - Запрет передачи на выбранных бендах

ENABLE xxx Band - Включение скрытых бендов

OTA Update - Включение обновления прошивки через WiFi

TX Start Delay - Задержка при переходе на TX для срабатывания реле

LCD Rotate - Повернуть экран на 180 градусов

# Пример настроек для компьютера

### Включение аудио-устройства

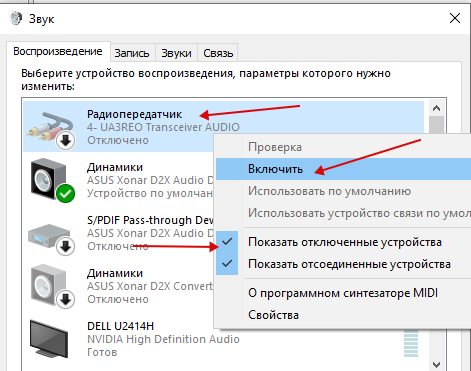
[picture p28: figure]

### N1MM

### JTDX

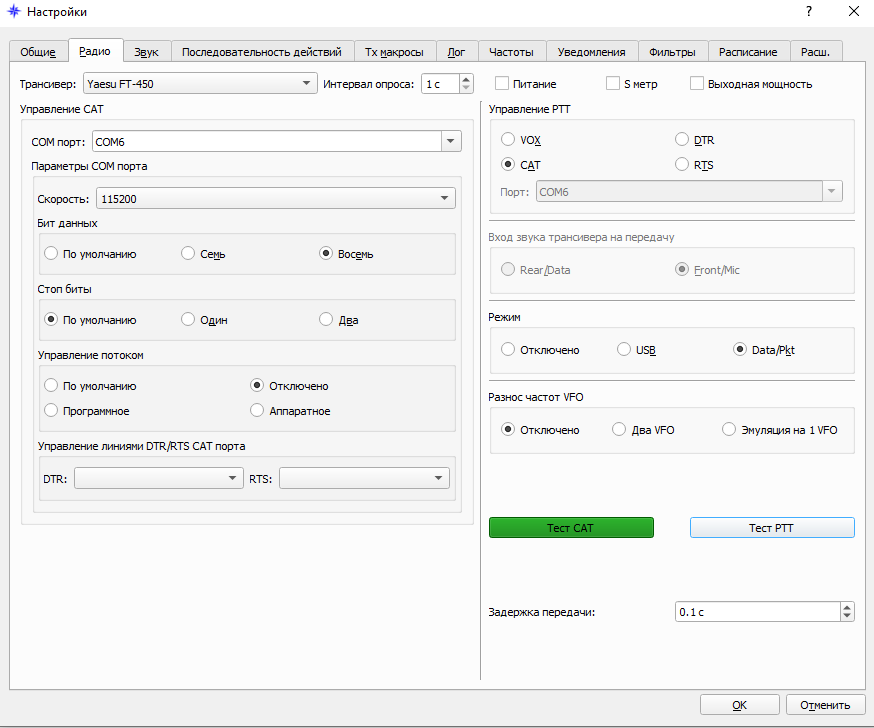
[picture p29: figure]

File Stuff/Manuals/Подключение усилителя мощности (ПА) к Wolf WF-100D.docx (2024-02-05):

Подключение усилителя мощности (ПА) к Wolf WF-100D

Для того чтобы усилитель мощности мог автоматически переключать выходные фильтры с изменением полосы в trx, требуется информация о выбранной в данный момент полосе. В WF-100D можно реализовать интерфейс, совместимый с trx YAESU (полоса представляет собой 4-битный BCD-код) - на разъеме X16 есть четыре сигнала (BAND1-BAND4), указывающих в коде BCD выбранный в данный момент диапазон. Кроме того, можно определить состояния каждого из этих сигналов в меню WF-100D.

Фрагмент диаграммы ОСНОВНОЙ платы, к которому относится описание, выглядит следующим образом:

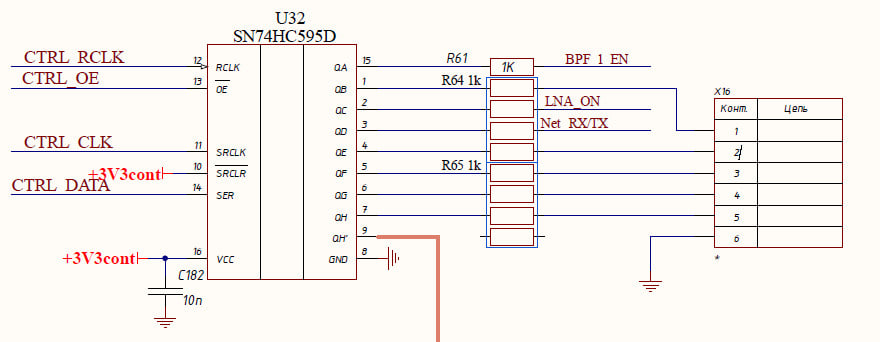
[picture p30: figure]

Сигналы BAND1-BAND4 на нем не описаны, но подаются на контакты 2-5 разъема X16.

К сожалению, после проверки выяснилось, что диаграмма не полностью соответствует компоновке треков на моей версии MAIN BOARD (WOLF-MAIN rev. 1.2). Эта схема выглядит следующим образом:

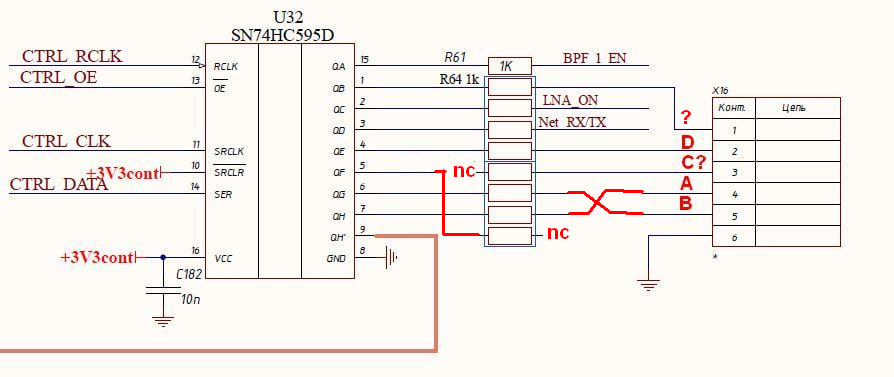
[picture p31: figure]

Сигнал C подключен к массиву резисторов, но другой конец резистора нигде не подключен. Сигнал от контакта 5 чипа U32 подается на последний резистор, другой конец которого нигде не подключен. Простейшим устранением этой ошибки является подключение подвесного контакта последнего резистора к контакту резистора, подключенному к контакту 3 разъема X16:

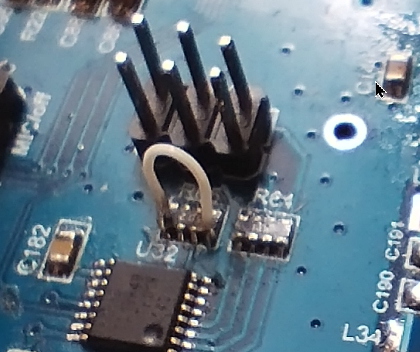
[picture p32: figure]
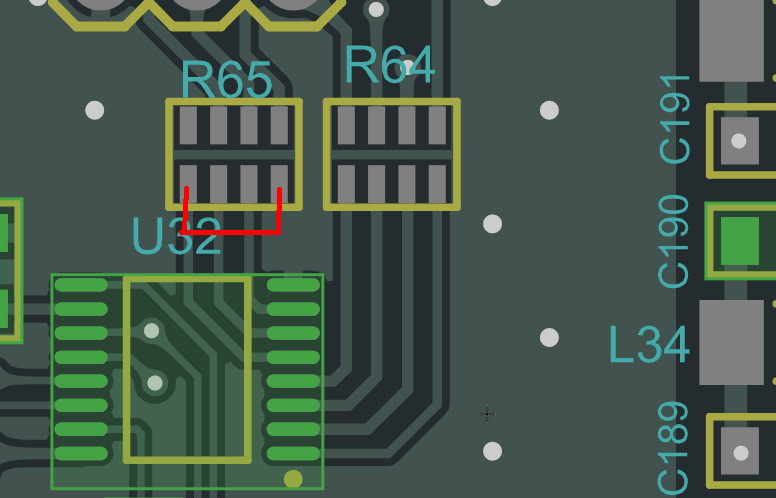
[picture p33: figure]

Для включения вещания усилителю мощности требуется сигнал PTT. Проще всего использовать сигнал PTT COM от платы IN/OUT, подключив дополнительный кабель к контактам реле:

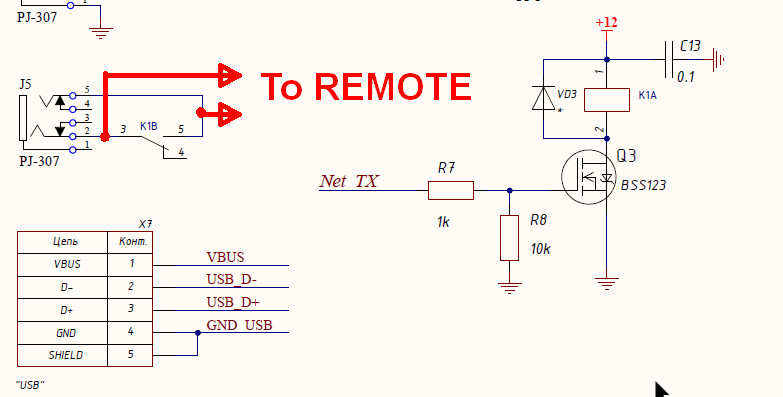
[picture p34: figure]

Опционально сигнал ALC может быть подключен к ПА для управления выходной мощностью.

Этот сигнал берется с пластины ПА. Вместо разъема X5 (EXTERNAL) только 2-контактный разъем припаян к разъему X5 в положении 9-10 (MB ALC и GND).

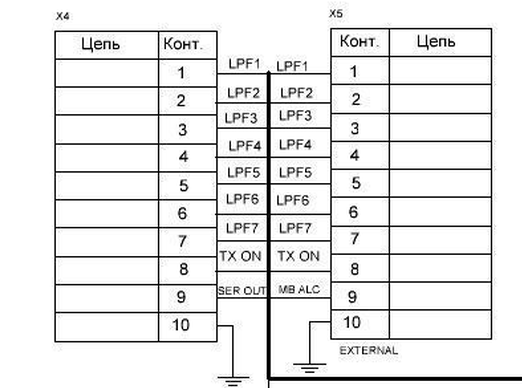
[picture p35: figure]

Эти 6 сигналов (BCD, ALC и PTT) подаются на плату REMOTE. Есть разъемы и четыре NPN-транзистора, потому что выходы BAND1-BAND4 должны быть выходами OC (Open Collector).

Схема платы REMOTE выглядит следующим образом:

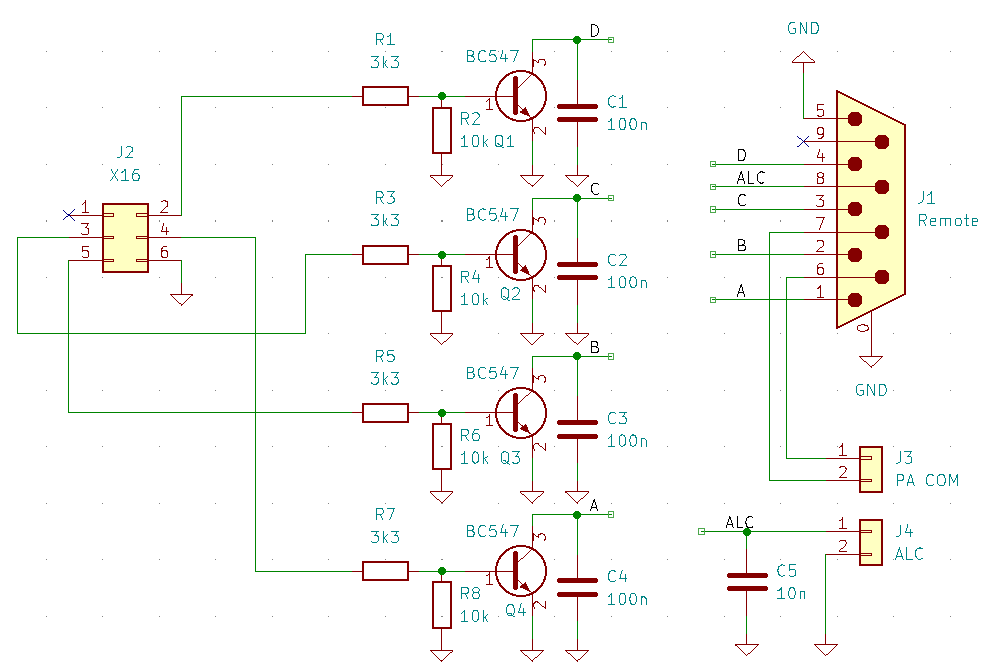
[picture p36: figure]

Разъем J2 X16 должен быть подключен к разъему X16 на основной плате, разъем J4 ALC к разъему X5 (контакты 9 и 10) на плате PA и разъему J3 PA COM к контактам реле K1 на плате IN/OUT.

Гнездо DB-9 привинчивается к задней стенке WF-100D.

ПХД выглядит следующим образом:

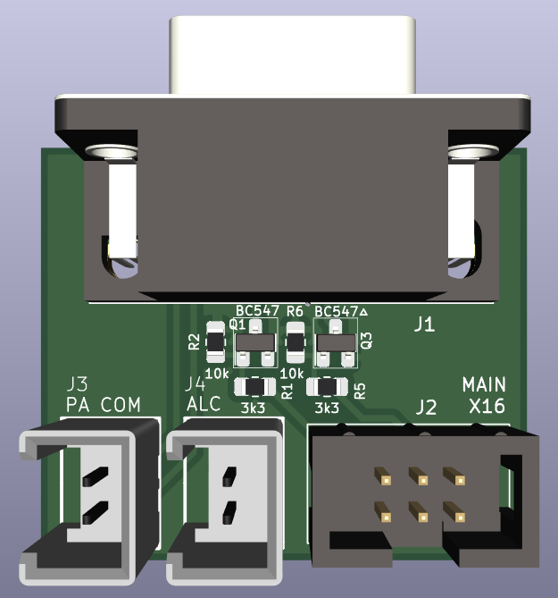
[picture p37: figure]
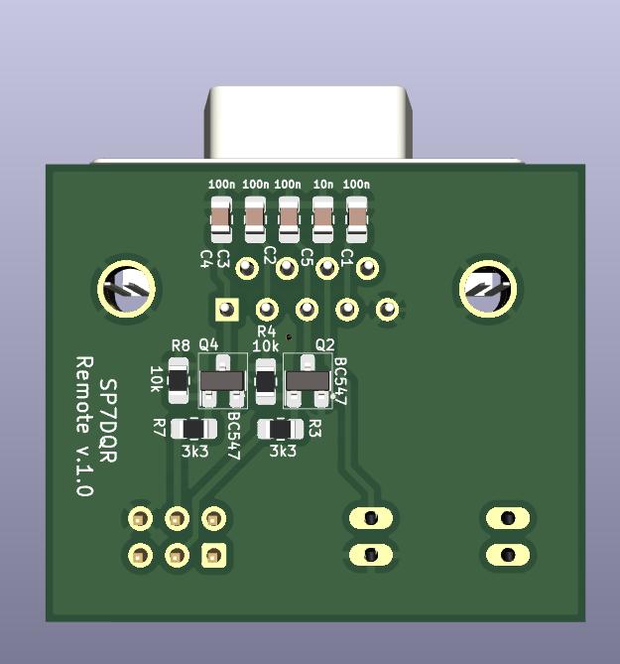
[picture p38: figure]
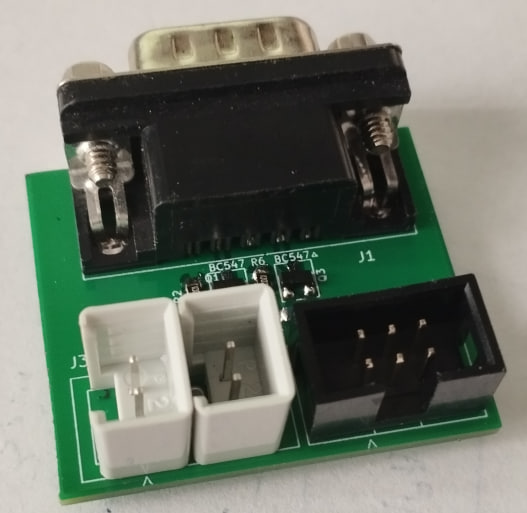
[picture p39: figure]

Файлы GERBER/PDF доступны бесплатно от автора – e-mail: sp7dqr@wp.pl.

Поскольку транзисторы в интерфейсе переворачивают сигнал для получения правильных выходных сигналов BCD, состояния каждой полосы должны быть переопределены в меню WF-100D, вводя их как отрицаемые состояния кодов YAESU (коды неиспользуемых полос не были изменены):

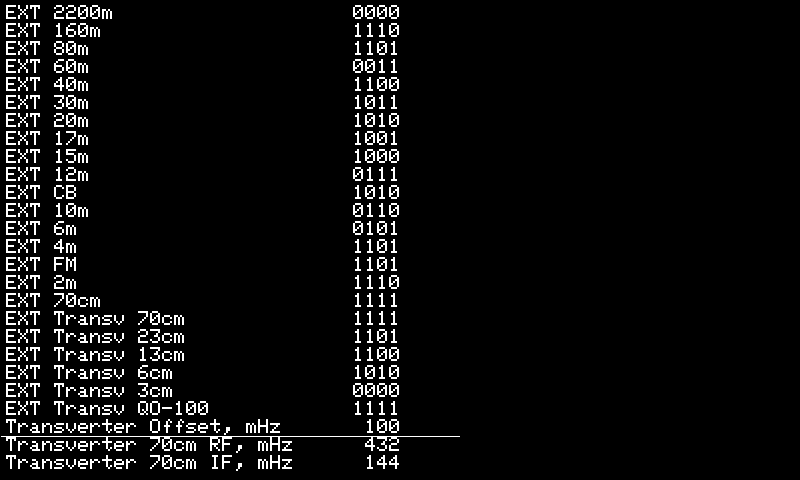
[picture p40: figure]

73, Marek SP7DQR (sp7dqr@wp.pl)

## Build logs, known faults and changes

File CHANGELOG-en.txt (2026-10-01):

----Version 16.2.0----
+FPGA: Accelerated STM-FPGA data bus
+FPGA: Added experimental DAC modes "DAC Dither" and "DAC Rounding" for spectrum measurements in different modes.
+STM32: Fixed an issue in the FM modulator, Tnx RA9YON
+STM32: Fixed DXCluster FFT operation in 3D FFT mode, Tnx RV9CT
+STM32: Wolf-2: Added "VHF Path for HF Trsv" calibration, allowing transverters with an HF IF to be connected to the motherboard's VHF signal path, Tnx RA3WSA
+STM32: Added NB buffer reset when changing bands, Tnx Andrey
+STM32: Added reset of AFMonitor buffers when starting a macro with disabled Break-In, Tnx SP7MFR
+STM32: CW Keyboard now works correctly with Break-In disabled, Tnx Vitaly
+STM32: Reset BandMap stop flag when changing VFO via A/B function key, Tnx Rudi
+STM32: Corrections in the operation of adjusting menu items on the main screen via ENC2, Tnx RC3RF
+STM32: Removed personal data from Settings export
+STM32: CW Keyboard can now operate in RTTY and PSK31 mode
+STM32: Repeater Mode automatically disables when changing mode, Tnx E72X
+STM32: The names and descriptions of calibrations that adjust recording and playback levels from an SD card have been tidied up, Tnx YC1SEI
+STM32: CW decoder improvements
+STM32: CW multidecoder improvements: decoder markers are retained and continue to operate when frequency tuning
+STM32: "DAC DRV Shutdown" is now enabled by default, the operating logic has been changed: the driver is turned on before the relay and quiescent currents are turned on (to minimize the surge in the antenna/amplifier)
+STM32: Optimization of CPU load during frequency tuning
+STM32: Updated "Screens of Death" to display more useful information for finding the causes of software errors
+STM32: VHF-Board: Eliminated LO leakage in TX path during reception
+STM32: Reduced hold latency on power meter peaks, Tnx Evgeniy
+STM32: Updated the logic for long pressing the "SQL" button, in FM + active noise suppression it switches ENC2 to SQL mode, in others it opens the FM/VAD Squelch adjustment in the menu, Tnx R1CDZ
+STM32: Improvements to the "CW Keyboard" feature, added the ability to send a message without closing the window, Tnx BI4JWL
+STM32: Removed "DRV" menu, replaced with "QUICK" menu with quick access to various useful functions, Tnx R3TKS
+STM32: AFMonitor always works when the equalizer window is open, Tnx R7KBI
+STM32: Decoder line active during CW Keyboard operation
+STM32: Added a new type of DNR for CW mode Adaptive Line Enhancer (ALE), helps to improve signal strength at low SNR
+STM32: Enabling USB SD Card Reader no longer blocks the transceiver (but blocks the SD card from the firmware)
+STM32: N1MM when working in RRTY does not switch the transceiver to DIGI if it is already in RTTY mode, Tnx RM0A
+STM32: Added the ability to log ADIF communication on the SD card and network log to the "DX Call" window, Tnx RX3PX,R6UA
+STM32: Added the ability to use SPI FLASH as a small slow SD card, Tnx UT8EU
+STM32: Added "Dual FFT" mode - with Dual RX active, the spectrum and waterfall are split into two windows with independent display of VFO-A and VFO-B. Experimental, may be unstable
+STM32: Fixed issues with closing the SWR analyzer, Tnx RK6ZH

----Version 16.1.0----
+STM32: Added "DC Filter RX" and "DC Filter TX" settings to the Filters menu - enable/disable the DC corrector (cuts off the constant component and part of the low frequencies), Tnx YC1SEI
+STM32: Pressing the "Files" function button again closes the file manager, Tnx SP7MFR
+STM32: Correction of ATU operation at borderline C/I values
+STM32: Added "FTx Auto Frequency" setting, which allows you to control the FT8 decoder mode - automatically switch to a standard frequency or stay on the selected one, Tnx EA5GSA
+STM32: Improved RDS decoder performance, Tnx DL1EGQ
+STM32: Fixed marker display on FFT, Tnx SP7MFR
+STM32: CAT subsystem improvements, Tnx DJ7NT
+STM32: Slightly faster settings import
+STM32: Wolf-2/Mini: When in the menu, once an item is active, you can long-press the "F" button on the front panel. This will allow you to adjust the parameter using ENC2 directly from the main screen. Tnx R7KBI, RC3RF
+STM32: New customizable "CW KEYB" function key, allowing you to quickly type and transmit any text message via telegraph without using macros
+STM32: AF Monitor now continues to display the signal during SD recording playback (PLAY), Tnx Vitaly

----Version 16.0.1----
+STM32: Rollback of problematic SD card optimizations
+STM32: Fix for character truncation issues on FFT markers, Tnx SP7MFR
+STM32: Fixed IF Gain adjustment when Fine RIT is disabled, Tnx R3TKS
+STM32: When the Secondary COM Mode is set to ESP, Mute is enabled and the tooltip is displayed, Tnx RV9CT

----Version 16.0.0----
+STM32: AF Monitor performance improvements and optimizations
+STM32: RDS decoder improvements
+STM32: FTx decoder speed optimization
+STM32: Improved AF Monitor frequency spectrum smoothing
+STM32: AF Monitor can now be enabled when 3D FFT is active, Tnx RV9CT
+STM32: Added "AF Monitor Time" setting - sets the length of the AF Monitor time domain window, Tnx EA5GSA
+STM32: Improved Doppler shift correction when working in "Sat Mode"
+STM32: Secondary encoder mode is stored in memory channels, Tnx Oleksandr
+STM32: Added "Inhibit VOX Button" calibration - disables the hardware VOX button, Tnx RZ3RZ
+STM32: Added experimental support for FT2 mode, requires very precise timing settings to work, Tnx WC1J
+STM32: Added a customizable "PLAY" function button that enables playback or transmission (long press) of the last recorded file on air, Tnx R7KBI, YC1SEI
+STM32: Experimental DPD enabled for lower end transceiver models (be sure to use an external attenuator for calibration)
+STM32: README files describe all types of functional buttons of the transceiver
+STM32: Experimental improvements to the CESSB algorithm
+STM32: Wolf-2PRO: Inverted Mute signal, Tnx SP5TAA
+STM32: Screenshots are now saved in JPG format instead of BMP (minor loss of quality but smaller file size)
+STM32: A JPEG file viewer (for screenshots and some other regular photos) has been added to FileManager.
+STM32: Accelerated downloading and display of images in WiFi services (DayNight/Propagation)
+STM32: Various optimizations in SD card operation
+STM32: A/B button is blocked when FTx decoder is running, Tnx A L
+STM32: Minor AGC fixes in Dual RX mode
+STM32: Bug fixes, Tnx YC1SEI
+STM32: Added submenu SD Card -> Profile Names - custom names of profiles for exporting/importing settings from SD, Tnx UT8EU
+STM32: CAT subsystem improvements, Tnx UT8EU
+STM32: Experimental mode for adjusting RIT/XIT by encoder: now the step is tied to the step of the main encoder / FAST mode, Tnx SP7MFR
+STM32: Wolf-1 with "Fine RIT Tune" turned off, IF adjustment does not begin immediately after RIT is turned off, but only after rotation starts, Tnx R3TKS
+STM32: Improved formatting of the "Sattelites" -> "Calc pass" window output
+STM32: Added menu item "EME Info" displaying basic information on lunar communications + extended information when DXCall is specified
+STM32: Added "VOACAP Map" propagation calculation service, which draws a map of probable signal levels (where you can be heard) for the current frequency/time
+STM32: Wolf-2PRO: Initial support for FSC-BT1035 via SC16IS750 converter (prototype only)
+ESP: More accurate NTP clock sync (new ESP FW required)
+ESP: Fixed intermittent data loss when downloading large amounts of data (day/night and other maps), Tnx WC1J

----Version 15.5.2----
+STM32: The S-meter/SWR calibration range of 6-20 MHz is divided into two sub-ranges: 6-12 and 12-20 MHz
+STM32: Fixed problem with turning on Split DX when VFO-B is active, Tnx SP7MFR
+STM32: Fixed an issue with AF Monitor freezing on some themes with high FFT Height, Tnx DL1EGQ
+STM32: Minor bug fixes, Tnx SP7MFR, Oleksandr

----Version 15.5.1----
+STM32: Fixed issues with NB2, Tnx SP7MFR
+STM32: Fixed issues with exiting the menu via function keys, Tnx UB4RGZ
+STM32: AF Monitor disables if it doesn't fit in the waterfall (large FFT Height), Tnx R5ZX

----Version 15.5.0----
+STM32: Major improvements to the DNR3 noise suppressor, by DL2FW
+STM32: Various CAT fixes, by DJ7NT
+STM32: Wolf-2-PRO: Improved hardware support for the front, interface, motherboard, and DFT boards (currently in debug)
+STM32: Wolf-110D: Improved hardware support for the HF amplifier board (currently in debug)
+STM32: Wolf-Mini: Added support for boards with dual encoders
+STM32: Experimental code optimizations and fixes
+STM32: Minor WFM/SWFM/RDS optimizations, Tnx Oleksandr, SP7MFR
+STM32: Fixed issue with exiting RTTY/PSK mode (frequency offset remained), Tnx Andrey
+STM32: Increased the default "RX AGC CW Speed" value, Tnx UT8EU
+STM32: Fixed frequency display in the FT8 decoder on VHF bands, Tnx SP7MFR
+STM32: DX Split no longer disables when cursor goes out of range, Tnx SP7MFR
+STM32: Added active VOX indication
+STM32: Added "Invert LCD PWM" calibration for inverting the screen PWM operation (necessary for some types of backlight drivers), Tnx BI4JWL
+STM32: Improved AutoCQ performance with Break-In disabled, Tnx SP7MFR
+STM32: Improved distance calculation system to a correspondent in FT8, Tnx BI4JWL
+STM32: Improved CW decoder performance in QSB conditions
+STM32: Wolf-2: Experimental improvement of peak power detector in SSB in normal mode and with "SWR Hold Peaks" active
+STM32: The keywords "CQ", "599", "5NN" are highlighted in the CW multidecoder screen output, Tnx E72X
+STM32: Added prototype of the "AF Monitor" function: display of the low-frequency signal in the frequency and time domain, Tnx R3TKS
+STM32: Improved sensitivity of RTTY decoder, as well as operation in QSB conditions
+STM32: Updated default settings for Noise Blanker + experimental improvements to lightning suppression algorithms

----Version 15.4.0----
+STM32: Fixed clicking sounds when using NB / DOUBLE, Tnx SP7MFR, RV9CT
+STM32: Improved CW decoder performance during transmission and in the simulator, Tnx R3XG
+STM32: Optimized CPU load from the multi-decoder CW
+STM32: Wolf-2: Improved SWR meter performance in transverter mode with Wideband RX / 144 TX on the VHF board
+STM32: Disabled simultaneous use of Snap and FFT Lens, Tnx SP7MFR
+STM32: Improved screen font smoothing
+STM32: Minor CW decoder improvements
+STM32: Callsign database fixes, Tnx SP7MFR
+STM32: Improved self-testing when "Auto CW Mode" is active, Tnx SP7MFR

----Version 15.3.0----
+STM32: Corrections + updates in the callsign prefix database, Tnx Oleksandr
+STM32: SNAP function improvements, Tnx SP7MFR, Anatoly
+STM32: Decoder improvements, Tnx Anatoly, RT3W
+STM32: VHF board wideband switching improvements, Tnx Vitaly
+STM32: FPGA bus stability improvements
+STM32: During FT8 decoding, the codec and AF amplifier are muted, Tnx RT3W
+STM32: When the transceiver is turned on, the active filter preset is correctly highlighted, Tnx EA5GSA
+STM32: The "Mute AF AMP on TX" function additionally mute the codec, not just the power amplifier, Tnx R3TKS
+STM32: Corrections to the names of some menu items

----Version 15.2.0----
+HARDW: Added Wolf-1-5D front panel schematics, board author RA6UAC
+HARDW: VHF board updated to v4.1, taking into account minor improvements after the launch of v4.0, author R7KBI
+STM32: The DAC has been set to maximum output power on all bands (with maximum RF Gain). The input attenuator on the W2 VHF board has been updated to prevent accidental damage, Tnx PY2MDA
+STM32: Added 70cm and 23cm bands to the SWR/Power autocalibration + minor interface fixes
+STM32: Added "Use Power Table" function/calibration, allowing the use of a correction table to accurately set the % of maximum power, taking into account gain nonlinearity.
+STM32: Added "Auto calibration" -> "Calibrate PWR %" service function for calibrating the correction table when adjusting the % power (for "Use Power Table" functionality)
+STM32: FT4 saving to log should work, Tnx UB4RGZ
+STM32: Improved Snap / Auto Snap functionality, Tnx Anatoly
+STM32: Fixed rare issue with opening pop-up windows with hardware buttons, Tnx SP7MFR
+STM32: On VHF bands (without a transverter with HF IF) TUN OFF is always displayed on the display, Tnx SP7MFR
+STM32: Added backup storage of calibrations in SPI FLASH, so that, if compatible, it would be possible to update to subsequent versions without resetting them
+STM32: The screen displays the error "PLL" when the RFFC2071 PLL loses synchronization
+STM32: Added a small visual highlighting of the current CW-LSB / CW-USB mode on the receive bandwidth, Tnx BD6MM
+STM32: Long press on the BreakIn button opens the CW PTT Type menu, Tnx SP7MFR
+STM32: Added "ATU Runner" service - an assistant in setting up an automatic tuner, runs through all enabled bands / sections and performs tuning

----Version 15.1.0----
+FPGA: Fixed signal loss on 384kHz without an antenna/driver, Tnx SP7MFR
+STM32: Added protection against loss of PLL lock in RFFC2071 during operation
+STM32: Tuner enable prohibition takes into account enabled transverter and Ext PA Mode, Tnx Dispatcher, R1CDZ
+STM32: Fixes in FT8 interface, Tnx R9HCZ

----Version 15.0.0----
+FPGA: Experimental DDC/DUC changes aimed at improving overload performance, reducing internal noise, and stabilizing bus timings
+FPGA: During the experiment, the STM32 will work with both FPGA versions 14 and 15, but the S-meter will need to be recalibrated
+HARDW: Wolf-2: A schematic for an external attenuator and input stage protection, Tnx RM0A, has been published in the repository folder "Schematic/Wolf-2/Addons/ATT&Protector"
+HARDW: Updated the values on the W2-VHF V4 board schematic, added setup instructions
+STM32: Added support for the 5-inch version of the Wolf-1 front panel from RA6UAC
+STM32: Improved support for the WF-110D from R6WAM
+STM32: Wolf-2: Added "External" calibration ATT", allowing you to connect an external 3-6-12dB attenuator to the vacated control connector of the old VHF board, Tnx RM0A
+STM32: Added PSK31 decoder/encoder, by DJ7NT
+STM32: Added integration with Wavelog via WiFi, by DJ7NT
+STM32: If there is a QSO in the Wavelog, the cluster spot is highlighted in color, by DJ7NT
+STM32: Improvements and fixes to the CAT and WiFi subsystems, by DJ7NT
+STM32: Fixed a bug where FT4 was mistakenly written as FT4 instead of MFSK/FT4, by DJ7NT
+STM32: Wolf-1/Mini: Added secondary encoder function for fast output power adjustment, Author DJ7NT
+STM32: Start of work on experimental DNR3 (not yet completed), by DL2FW
+STM32: Added "Mute AF AMP on TX" calibration for forced disabling of the low frequency amplifier during transmission (if self-test is not active), Tnx R7KBI
+STM32: Improvements to the shutdown process: now the ADC/low frequency amplifier/screen/drivers/codec/WiFi/etc are disabled until the power is turned off
+STM32: RIT/XIT/SPLIT are disabled when the transceiver is powered off, Tnx R7KBI
+STM32: Fixed the setup behavior "NOTX 23cm", Tnx Vitaly
+STM32: Shifted the "SelfHear DIGI" adjustment range
+STM32: Increased the thickness of the AGC indicator on the FFT, Tnx RD3ZE
+STM32: The menu no longer closes when tapping an area of the screen free of buttons, Tnx Dimazavr
+STM32: If space allows on the CN+ theme, the "CB" band is displayed in the band line, Tnx Dimazavr
+STM32: Added an experimental "Sigmoid" mode for the "Power Control" calibration (and the "Sigmoid coeff" item for adjusting for PA nonlinearity), Tnx DL9VS
+STM32: The tuner mute button is inactive on VHF bands, Tnx Vitaly
+STM32: Improved error correction for measurements via MCP3008
+STM32: Fixed incorrect font anti-aliasing in CW Trainer, Tnx R4PHD
+STM32: In auto-calibration mode, SWR/Power values are reset when switching bands, Tnx R1CDZ
+STM32: Minor optimization of settings import/export code
+STM32: Improvements to the "FFT dBm Grid" function, Tnx R1BLT
+STM32: Added VFO-B, RTTY, PSK markers to the 3D FFT, Tnx Dire Wolf
+STM32: Added "FFT 3D Slides", "FFT 3D X Offset", and "FFT 3D Y Offset" settings to control the 3D FFT appearance
+STM32: The currently active filter settings preset is highlighted in color in the lower function panel, Tnx EA5GSA
+STM32: The audio response to IF Gain changes has been softened.
+STM32: Fixed occasional errors during communication between the FPGA and STM32.
+STM32: If the SWR becomes 3 or more during WSPR beacon operation, the ATU is automatically enabled (the transmit slot is skipped). Tnx Vitaly
+STM32: Added the "WOLF Cluster Models" setting, which enables the display of user transceiver models in the wolf cluster. Tnx RV9CT
+STM32: Swiping on the screen with Free Tune mode enabled moves the sweep band, not the receive band (as with pressing). Tnx EA5GSA
+STM32: The "SWR Analyzer" service draws a graph of the measured power in addition to the SWR (the service uses power calibration in Tune mode). Tnx UT8EU
+STM32: When playing a CW macro with When Break-In is disabled, a TX Start Delay is emulated to avoid character loss, Tnx SP7MFR
+STM32: In FT8/FT4, the country and approximate distance to the correspondent are displayed, Tnx PY2MDA, Vitaly
+STM32: Added the "Touchpad Test" service to check touchpad operation
+STM32: Added "Touchpad Offset X" / "Touchpad Offset Y" calibrations, allowing you to set the offset for the touchpad click point (when working at an angle to the screen or due to hardware issues)
+STM32: Added the ability to reset the settings/calibration parameter to the default value; only user-changed values are highlighted
+STM32: Added "DeEmphasis NFM, us" and "DeEmphasis WFM, us" settings for adjusting filters that reduce high-frequency noise in NFM/WFM
+STM32: Fixed an issue with jittery markers Callsigns on the spectrum, Tnx R3TKS
+STM32: Fixes for interrupting the AutoCQ cycle with PTT, Tnx EA5GSA
+STM32: All transceiver operator settings have been moved to a separate menu
+STM32: Improved compatibility with 5MContest, Tnx R3YA
+STM32: To prevent accidental pressing, the TUN button is inverted: a short power supply turns off the tuner, a long one turns on the tuning
+STM32: Wolf-Mini: Microwave gigahertz digit moved to the left, Tnx R6DLC
+STM32: SelfHear function button renamed to MONI, Tnx RM0A
+STM32: Slightly improved FT8 performance with non-standard callsigns requiring hashed transmission, Tnx R4PHD
+STM32: Wolf-2: Added "FAN Always on HF" / "FAN Always on VHF" settings to force fan operation (for heavy operating conditions)

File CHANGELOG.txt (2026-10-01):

----Version 16.2.0----
+FPGA: Ускоренная шина обмена STM-FPGA
+FPGA: Добавлены экспериментальные режимы ЦАП "DAC Dither", "DAC Rounding" для замеров спектра в разных режимах
+STM32: Исправлена проблема в FM-модуляторе, Tnx RA9YON
+STM32: Исправлена работа FFT DXCluster в 3D FFT, Tnx RV9CT
+STM32: Wolf-2: Добавлена калибровка "VHF Path for HF Trsv", позволяющие включать трансвертеры с КВ ПЧ в УКВ тракт материнской платы, Tnx RA3WSA
+STM32: Добавлен сброс буферов NB при смене диапазона, Tnx Андрей
+STM32: Добавлен сброс буферов AFMonitor при старте макроса с отключенным Break-In, Tnx SP7MFR
+STM32: CW Keyboard теперь корректно работает с отключенным Break-In, Tnx Vitaly
+STM32: Сброс флага остановки работы BandMap при смене VFO через функциональную кнопку A/B, Tnx Rudi
+STM32: Исправления в работе регулировки пунктов меню на главном экране через ENC2, Tnx RC3RF
+STM32: Убраны персональные данные/настройки из экспорта Settings
+STM32: CW Keyboard теперь может работать в режиме RTTY и PSK31
+STM32: Repeater Mode автоматически отключается при смене моды, Tnx E72X
+STM32: Приведены в порядок названия и описания калибровок, настраивающих уровни записи и воспроизведения с SD карты, Tnx YC1SEI
+STM32: Доработки CW-декодера
+STM32: Доработки CW-мультидекодера: при перестройке частоты маркеры декодов сохраняются и продолжают работу
+STM32: "DAC DRV Shutdown" теперь включен по умолчанию, изменена логика работы: драйвер включается до включения реле и токов покоя (для минимизации выброса в антенну/УМ)
+STM32: Оптимизации нагрузки на CPU при перестройке частоты
+STM32: Обновлены "Экраны смерти", теперь выводится больше полезной информации для поиска причин ошибок ПО
+STM32: VHF-Board: Устранена утечка LO в TX тракт во время приёма
+STM32: Уменьшена задержка на пиках мощемера, Tnx Евгений
+STM32: Обновлена логика долгого нажатия на кнопку "SQL", в FM + активном шумоподавителе переводит ENC2 в режим SQL, в остальных открывает регулировку FM/VAD Squelch в меню, Tnx R1CDZ
+STM32: Доработки "CW Keyboard", добавлена возможность отправки сообщения без закрытия окна, Tnx BI4JWL
+STM32: Удалено меню "DRV", вместо него добавлено меню "QUICK" с быстрым доступом до разных полезных функций, Tnx R3TKS
+STM32: AFMonitor всегда работает при открытии окна эквалайзера, Tnx R7KBI
+STM32: Строка декодера активна во время работы CW Keyboard
+STM32: Добавлен новый вид DNR для CW моды Adaptive Line Enhancer (ALE), позволяет помочь вытянуть сигнал при низком SNR
+STM32: Включение USB SD Card Reader теперь не блокирует работу трансивера (но блокирует работу с SD картой из прошивки)
+STM32: N1MM при работе в RRTY не переключает трансивер в DIGI, если он уже на RTTY моде, Tnx RM0A
+STM32: В окно "DX Call" добавлена возможность залогировать связь в ADIF на SD карте и сетевой лог, Tnx RX3PX, R6UA
+STM32: Добавлена возможность использовать SPI FLASH как небольшую медленную SD-карту, Tnx UT8EU
+STM32: Добавлен режим "Dual FFT" - при активном Dual RX спектр и водопад разделяются на два окна с независимым отображением VFO-A и VFO-B. Экспериментальный, может работать нестабильно
+STM32: Исправлены проблемы с закрытием SWR-анализатора, Tnx RK6ZH

----Version 16.1.0----
+STM32: Добавлены настройки "DC Filter RX" и "DC Filter TX" в меню Filters — включение/отключение DC-корректора (срезают постоянную составляющую и часть НЧ частот), Tnx YC1SEI
+STM32: Повторное нажатие на функциональную кнопку ""Files" закрывает файл-менеджер, Tnx SP7MFR
+STM32: Исправление работы ATU на пограничных значениях C/I
+STM32: Добавлена настройка "FTx Auto Frequency", позволяющая управлять режимом FT8 декодера - автоматически переходить на стандартную частоту или оставаться на выбранной, Tnx EA5GSA
+STM32: Улучшена работа RDS-декодера, Tnx DL1EGQ
+STM32: Исправление отображения маркеров на FFT, Tnx SP7MFR
+STM32: Доработки CAT подсистемы, Tnx DJ7NT
+STM32: Небольшое ускорение импорта настроек
+STM32: Wolf-2/Mini: При нахождении в меню, выбрав активным какой-то пункт, можно долго нажать кнопку "F" на лицевой панели. После этого будет доступна регулировка параметра с помощью ENC2 прямо из главного экрана, Tnx R7KBI, RC3RF
+STM32: Новая настраиваемая функциональная кнопка "CW KEYB", позволяющая оперативно набрать и передать любое текстовое сообщение телеграфом без использования макросов
+STM32: AF Monitor продолжает отображать сигнал при воспроизведении записи с SD (PLAY), Tnx Vitaly

----Version 16.0.1----
+STM32: Откат проблемных оптимизаций работы SD карты
+STM32: Исправление проблем с обрезанием символов на маркерах FFT, Tnx SP7MFR
+STM32: Исправлена регулировка IF Gain при отключенном Fine RIT, Tnx R3TKS
+STM32: При активном Secondary COM Mode равным ESP, включается Mute и отображается тултип, Tnx RV9CT

----Version 16.0.0----
+STM32: Доработки и оптимизация скорости работы AF Monitor
+STM32: Доработки RDS декодера
+STM32: Оптимизация скорости работы FTx декодера
+STM32: Доработка сглаживания частотного спектра AF Monitor
+STM32: AF Monitor теперь можно включить при активном 3D FFT, Tnx RV9CT
+STM32: Добавлена настройка "AF Monitor Time" - устанавливается длина окна временной области AF Monitor, Tnx EA5GSA
+STM32: Улучшена работа коррекции Допплеровского сдвига при работе в "Sat Mode"
+STM32: Режим вторичного энкодера сохраняется в каналах памяти, Tnx Oleksandr
+STM32: Добавлена калибровка "Inhibit VOX Button" - полностью отключает аппаратную кнопку VOX, Tnx RZ3RZ
+STM32: Добавлена экспериментальная поддержка моды FT2, требует очень точную настройку времени для работы, Tnx WC1J
+STM32: Добавлена настраиваемая функциональная кнопка "PLAY", включающая воспроизведение или передачу (долгое нажатие) последнего записанного файла в эфир, Tnx R7KBI, YC1SEI
+STM32: Экспериментальный DPD включен для младших моделей трансивера (обязательно используйте внешний аттенюатор для калибровки)
+STM32: В README файлах описаны все виды функциональных кнопок трансивера
+STM32: Экспериментальные доработки алгоритма CESSB
+STM32: Wolf-2PRO: Инвертирован сигнал Mute, Tnx SP5TAA
+STM32: Скриншоты теперь сохраняются в JPG, а не BMP формат (небольшая потеря качества, но меньше размер)
+STM32: В FileManager добавлен просмоторщик JPEG файлов (скриншотов и некоторых других обычных фото)
+STM32: Ускорено скачивание и отображение изображений в WiFi-сервисах (DayNight/Propagation)
+STM32: Различные оптимизации в работе SD карты
+STM32: Заблокирована кнопка A/B при работающем FTx декодере, Tnx А L
+STM32: Небольшие исправления AGC в режиме Dual RX
+STM32: Исправление ошибок, Tnx YC1SEI
+STM32: Добавлено подменю SD Card -> Profile Names — пользовательские имена профилей экспорта/импорта настроек с SD, Tnx UT8EU
+STM32: Доработки CAT подсистемы, Tnx UT8EU
+STM32: Экспериментальный режим регулировки RIT/XIT энкодером: теперь шаг привязан к шагу основного экодера / режима FAST, Tnx SP7MFR
+STM32: Wolf-1 при выключенном "Fine RIT Tune" регулировка ПЧ начинается не сразу после отключения RIT, а только после начала вращения, Tnx R3TKS
+STM32: Улучшено форматирование вывода "Sattelites" -> "Calc pass" окна
+STM32: Добавлен пункт меню "EME Info", отображающий базовую информацию по лунной связи + расширенная информация при заданном DXCall
+STM32: Добавлен сервис расчёта прохождения "VOACAP Map", рисующий карту вероятных уровней сигнала (где вас слышат) для текущей частоты/времени
+STM32: Wolf-2PRO: Начальная поддержка FSC-BT1035 через SC16IS750 преобразователь (пока прототип)
+ESP: Более точная синхронизация часов по NTP (требуется перепрошивка ESP)
+ESP: Исправлена плавающая потеря данных при скачивании больших объёмов данных (day/night и др. карты), Tnx WC1J

----Version 15.5.2----
+STM32: Диапазон калибровки S-метра/КСВ 6-20 МГц разделён на два поддиапазона: 6-12 и 12-20 МГц 
+STM32: Исправлена проблема с включением Split DX при активном VFO-B, Tnx SP7MFR
+STM32: Исправлена проблема с зависанием AF Monitor на некоторых темах оформления с высоким FFT Height, Tnx DL1EGQ
+STM32: Исправление мелких ошибок и проблем, Tnx SP7MFR, Oleksandr

----Version 15.5.1----
+STM32: Исправление проблем с NB2, Tnx SP7MFR
+STM32: Исправление проблем с выходом из меню через функциональные кнопки, Tnx UB4RGZ
+STM32: AF Monitor отключается, если не умещается на водопаде (большой FFT Height), Tnx R5ZX

----Version 15.5.0----
+STM32: Большие доработки шумоподавителя DNR3, Автор DL2FW
+STM32: Различные исправления работы CAT, Автор DJ7NT
+STM32: Wolf-2-PRO: Улучшена аппаратная поддержка лицевой, интерфейсной, материнской и ДПФ плат (пока на стадии отладки)
+STM32: Wolf-110D: Улучшена аппаратная поддержка платы КВ усилителя (пока на стадии отладки)
+STM32: Wolf-Mini: Добавлена поддержка плат с двойными энкодерами
+STM32: Экспериментальные оптимизации и исправления кода
+STM32: Небольшие оптимизации WFM/SWFM/RDS, Tnx Oleksandr, SP7MFR
+STM32: Исправлена проблема с выходом из RTTY/PSK моды (оставалось смещение по частоте), Tnx Андрей
+STM32: Увеличено значение "RX AGC CW Speed" по умолчанию, Tnx UT8EU
+STM32: Исправлено отображение частоты в FT8-декодере на УКВ бендах, Tnx SP7MFR
+STM32: DX Split больше не отключается при выходе курсора за границы диапазона, Tnx SP7MFR
+STM32: Добавлена индикация активного VOX
+STM32: Добавлена калибровка "Invert LCD PWM" для инвертирования работы ШИМ экрана (необходимо для некоторых видов драйверов подсветки), Tnx BI4JWL
+STM32: Улучшена работа AutoCQ с отключенным Break-In, Tnx SP7MFR
+STM32: Улучшена система расчёта дистанции до корреспондента в FT8, Tnx BI4JWL
+STM32: Улучшена работа CW-декодера в условиях QSB
+STM32: Wolf-2: Экспериментальное улучшение пик-детектора мощности в SSB в обычном режиме и при активном "SWR Hold Peaks"
+STM32: В экранном выводе CW мультидекодера подсвечиваются ключевые слова "CQ", "599", "5NN", Tnx E72X
+STM32: Добавлен прототип функции "AF Monitor": отображение НЧ сигнала в частотной и временной области, Tnx R3TKS
+STM32: Улучшение чувствительности RTTY декодера, а также работы в условиях QSB
+STM32: Обновлены настройки по умолчанию для Noise Blanker + экспериментальные улучшения алгоритмов для подавления грозовых разрядов

----Version 15.4.0----
+STM32: Исправлены щелчки при работе NB / DOUBLE, Tnx SP7MFR, RV9CT
+STM32: Улучшена работа декодера CW при передаче и в тренажере, Tnx R3XG
+STM32: Оптимизация нагрузки на CPU от мульти-декодера CW
+STM32: Wolf-2: Улучшена работа КСВ-метра в трансвертерном режиме при Wideband RX / 144 TX на УКВ плате
+STM32: Запрещено одновременное использование Snap и FFT Lens, Tnx SP7MFR
+STM32: Улучшено сглаживание экранных шрифтов
+STM32: Небольшие доработки CW декодера
+STM32: Исправления в базе данных позывных, Tnx SP7MFR
+STM32: Улучшение работы самоконтроля при активном "Auto CW Mode", Tnx SP7MFR

----Version 15.3.0----
+STM32: Исправления + обновления базы данных префиксов позывных, Tnx Oleksandr
+STM32: Доработки функции SNAP, Tnx SP7MFR, Анатолий
+STM32: Доработки декодеров, Tnx Анатолий, RT3W
+STM32: Улучшение Wideband коммутации УКВ платы, Tnx Vitaly
+STM32: Улучшение стабильности работы шины FPGA
+STM32: Во время декода FT8 кодек и УНЧ отключаются, Tnx RT3W
+STM32: При включении трансивера правильно подсвечивается активный пресет фильтра, Tnx EA5GSA
+STM32: Функция "Mute AF AMP on TX" дополнительно глушит кодек, а не только УНЧ, Tnx R3TKS
+STM32: Исправления названий некоторых пунктов меню

----Version 15.2.0----
+HARDW: Добавлены схемы лицевой панели Wolf-1-5D, автор плат RA6UAC
+HARDW: Обновлена УКВ плата до версии v4.1, учтены небольшие доработки после запуска v4.0, автор R7KBI
+STM32: ЦАП выведен в режим максимальной выходной мощности (при максимальном RF Gain). Обновлено значение аттенюатора по входу на W2 VHF плате чтобы случайно не сжечь, Tnx PY2MDA
+STM32: В автокалибровку КСВ/Мощности добавлены диапазоны 70см и 23см + небольшие исправления интерфейса
+STM32: Добавлена функция/калибровка "Use Power table", позволяющая использовать таблицу поправок для точной установки % от максимальной мощности с учётом нелинейности усиления
+STM32: Добавлена функция сервиса "Auto calibration" -> "Calibrate PWR %" для калибровки таблицы поправок при регулировке % мощности (для работы "Use Power table")
+STM32: Должно заработать корректное сохранение FT4 в лог, Tnx UB4RGZ
+STM32: Улучшена работа функции Snap / Auto Snap, Tnx Анатолий
+STM32: Исправлена редкая проблема при открытии всплывающих окон аппаратными кнопками, Tnx SP7MFR
+STM32: На УКВ бендах (без трансвертера c КВ ПЧ) всегда отображается TUN OFF На дисплее, Tnx SP7MFR
+STM32: Добавлено резервное хранение калибровок в SPI FLASH, чтобы по возможности и совместимости можно было обновляться на последующие версии без их сброса
+STM32: На экране отображается ошибка "PLL" при потери синхронизации ФАПЧ RFFC2071
+STM32: Добавлено небольшое визуальное выделение текущего режима CW-LSB / CW-USB на полосе приёма, Tnx BD6MM
+STM32: Долгое нажатие на кнопку BreakIn открывает меню CW PTT Type, Tnx SP7MFR
+STM32: Добавлен сервис "ATU Runner" - помощник в настройке автоматического тюнера, пробегает по всем включенным бендам / участкам и производит настройку

----Version 15.1.0----
+FPGA: Исправлено пропадание сигнала на обзоре 384кгц без антенны, Tnx SP7MFR
+STM32: Добавлена защита от потери захвата ФАПЧ в RFFC2071 в ходе работы
+STM32: В запрете включения тюнера учитывается включенный трансвертер и Ext PA Mode, Tnx Dispatcher, R1CDZ
+STM32: Исправления в интерфейсе FT8, Tnx R9HCZ

----Version 15.0.0----
+FPGA: Экспериментальные изменения DDC/DUC, направленные на улучшение работы при перегрузках, уменьшения внутренних шумов, стабилизации таймингов шин
+FPGA: На время эксперимента STM32 будет работать и с 14 и с 15 версиями FPGA, но потребуется перекалибровка S-метра
+HARDW: Wolf-2: В папку репозитория "Schematic/Wolf-2/Addons/ATT&Protector" опубликована схема внешнего аттенюатора и защиты входного каскада, Tnx RM0A
+HARDW: Обновлены номиналы на схеме W2-VHF V4 платы, добавлена инструкция по настройке
+STM32: Добавлена поддержка 5 дюймовой версии лицевой панели Wolf-1 от RA6UAC
+STM32: Доработки поддержки WF-110D от R6WAM
+STM32: Wolf-2: Добавлена калибровка "External ATT", позволяющая подключить внешний аттенюатор 3-6-12дБ в освободившийся разъём управления старой УКВ платы, Tnx RM0A
+STM32: Добавлен PSK31 декодер/энкодер, автор DJ7NT
+STM32: Добавлена интеграция с Wavelog по WiFi, автор DJ7NT
+STM32: Если есть связь в логе Wavelog, то спот кластера подсвечивается цветом, автор DJ7NT
+STM32: Доработки и исправления CAT и WiFi-подсистем, автор DJ7NT
+STM32: Исправлена ошибка, из-за которой FT4 ошибочно записывался как FT4 вместо MFSK/FT4, Автор DJ7NT
+STM32: Wolf-1/Mini: добавлена функция вторичного энкодера для быстрой регулировки выходной мощности, Автор DJ7NT
+STM32: Начало работ над экспериментальным DNR3 (пока не завершен), Автор DL2FW
+STM32: Добавлена калибровка "Mute AF AMP on TX" для принудительного отключения УНЧ во время передачи (если не активен самоконтроль), Tnx R7KBI
+STM32: Доработки процесса выключения, теперь АЦП/УНЧ/экран/драйверы/кодек/WiFi/etc отключаются до выключения питания
+STM32: RIT/XIT/SPLIT отключаются при выключении питания трансивера, Tnx R7KBI
+STM32: Исправлена работа настройки "NOTX 23cm", Tnx Vitaly
+STM32: Сдвинут диапазон регулировки "SelfHear DIGI"
+STM32: Увеличена толщина индикатора АРУ на FFT, Tnx RD3ZE
+STM32: Меню больше не закрывается по тапу на свободную от кнопок область экрана, Tnx Dimazavr
+STM32: Если позволяет место на CN+ теме, то выводится "CB" бенд в строчке с диапазонами, Tnx Dimazavr
+STM32: Добавлен экспериментальный режим "Sigmoid" для калибровки "Power Control" (и пункт "Sigmoid coeff" для подстройки под нелинейность PA), Tnx DL9VS
+STM32: Кнопка отключения тюнера не активна на УКВ бендах, Tnx Vitaly
+STM32: Улучшена коррекция ошибок при измерениях через MCP3008
+STM32: Исправлено некорректное сглаживание шрифта в CW Trainer, Tnx R4PHD
+STM32: В режима автокалибровки мощности, значения SWR/Power/Питания сбрасываются при переключении диапазонов, Tnx R1CDZ
+STM32: Небольшая оптимизация кода импорта/экспорта настроек
+STM32: Доработки функции "FFT dBm Grid", Tnx R1BLT
+STM32: На 3D FFT добавлены маркеры VFO-B, RTTY, PSK, Tnx Dire Wolf
+STM32: Добавлены настройки "FFT 3D Slides", "FFT 3D X Offset" и "FFT 3D Y Offset" для управления внешним видом 3D FFT
+STM32: Текущий активный пресет настроек фильтров подсвечивается цветом в нижней функциональной панели, Tnx EA5GSA
+STM32: Звуковая реакция на изменение IF Gain стала более мягкой
+STM32: Устранены периодические ошибки при обмене между FPGA и STM32
+STM32: Если во время работы WSPR маяка КСВ становится 3 и более, то автоматически включается ATU (слот передачи пропускается), Tnx Vitaly
+STM32: Добавлена настройка "WOLF Cluster Models", включающая отображение моделей трансиверов пользователей в волк-кластере, Tnx RV9CT
+STM32: Свайп по экрану при включенном режиме Free Tune перемещает полосу обзора, а не полосу приёма (как при нажатии), Tnx EA5GSA
+STM32: Сервис "SWR Analyzer" рисует график измеренной мощности в дополнение к КСВ (для работы сервиса используется калибровка мощности в режиме Tune), Tnx UT8EU
+STM32: При проигрывании CW макроса с отключенным Break-In эмулируется задержка TX Start Delay чтобы не терять символы, Tnx SP7MFR
+STM32: В FT8/FT4 отображается страна и примерное расстояние до корреспондента, Tnx PY2MDA, Vitaly
+STM32: Добавлен сервис "Touchpad Test" для проверки работы тачпада
+STM32: Добавлены калибровки "Touchpad Offset X" / "Touchpad Offset Y", позволяющие задать смещение для точки нажатия на тачпад (при работе под углом к экрану или аппаратными проблемами)
+STM32: Добавлена возможность сброса параметра настроек/калибровок до значения по умолчанию, подсвечиваются только изменённые пользователем значения
+STM32: Добавлены настройки "DeEmphasis NFM, us" и "DeEmphasis WFM, us" для настройки фильтров, которые уменьшают уровень высокочастотных шумов в NFM/WFM
+STM32: Исправления проблемы с дрожащими маркерами позывных на спектре, Tnx R3TKS
+STM32: Исправления прерывания цикла AutoCQ с помощью PTT, Tnx EA5GSA
+STM32: Все настройки касающиеся оператора трансивера, вынесены в отдельное меню
+STM32: Улучшена совместимость с 5MContest, Tnx R3YA
+STM32: Для предотвращения случайных нажатий кнопка TUNE инвертирована: короткое питание выключает тюнер, долгое - включение настройки
+STM32: Wolf-Mini: Разряд гигагерц СВЧ диапазонов перенесён влево, Tnx R6DLC
+STM32: Функциональная кнопка SelfHear переименована в MONI, Tnx RM0A
+STM32: Немного улучшена работа FT8 с нестандартными позывными, требующими передачи в хешированном виде, Tnx R4PHD
+STM32: Wolf-2: Добавлены настройки "FAN Always on HF" / "FAN Always on VHF" для принудительной активации работы вентилятора (для тяжелых условий работы)

----Version 14.7.3----
+STM32: Исправлено зависание после импорта настроек, Tnx Евгений

----Version 14.7.2----
+STM32: Wolf-1: Значение сопротивления шунта INA226 по умолчанию выставлено в 2.5 мОм, Tnx RV9CT
+STM32: Wolf-Mini: Добавлен выбор DAC Driver Mode как в старших моделях
+STM32: Оптимизация кода отключения трансивера
+STM32: Исправления в CN переводе калибровок, Tnx BI3TYE
+STM32: Исправлена работа 3D FFT, Tnx RV9CT

----Version 14.7.1----
+STM32: Улучшен процесс инициализации VHF платы
+STM32: Исправлена работа 3D FFT, Tnx RV9CT

----Version 14.7.0----
+STM32: Исправление работы функции "EXT ATU in PA mode", Tnx SP7MFR
+STM32: Wolf-Mini: EXT PTT сигнал теперь корректно работает с "EXT PA Mode"
+STM32: Wolf-2: Теперь корректно работает отключение бендов 2м, 70см и 23см через калибровки, Tnx Oleksandr
+STM32: Добавлен новый тип отладки "ADC", в котором в консоль выводятся сырые данные с периферийных АЦП трансивера, Tnx R3TLI
+STM32: Небольшие оптимизации скорости работы
+STM32: Доработки ямбического режима B, Tnx Dire Wolf, R5ZX, RC3KR
+STM32: Активные CW/RTTY макросы отмечаются цветом в нижней панели кнопок, аналогично отмечается AutoCQ макрос при активации, Tnx EA5GSA, SP7MFR
+STM32: Максимальный интервал между AutoCQ макросов увеличен до 10 секунд, Tnx EA5GSA
+STM32: В CW-тренажер интегрирован вывод CW-декодера с отключенным Break-In (работает после окончания передачи тренировочных символов), Tnx R4PHD
+STM32: В CW-тренажер интегрирован режим "Check sending skill", позволяющий проверять навыки передачи у оператора после каждой строки, Tnx R4PHD
+STM32: Wolf-Mini: Обновлено нижнее меню чтобы лучше соответствовать расположению кнопок на лицевой панели, Tnx RN9RQ
+STM32: Добавлена настройка "VBAT Rechargable", позволяющая установить аккумулятор ML1220 / ML2032 вместо батарейки (в версиях, где подключение происходит напрямую к STM32, а не через диоды), Tnx R7KBI
+STM32: Улучшена защита от дребезга CW

----Version 14.6.0----
+HARDW: VHF-Board-v4: Реле заменены на высокочастотные UM1-12W-K и V23079, Автор R7KBI
+HARDW: VHF-Board-v4: Новые направленные ответвители, Автор R7KBI
+HARDW: VHF-Board-v4: GPIO расширитель PCF8575 заменён на PCA9555 и обновлены подтяжки его выходов, чтобы избежать ложных активаций УКВ цепей при включении трансивера (изменения без обратной совместимости), Автор R7KBI
+HARDW: VHF-Board-v4: Обновлены подстроечные резисторы для избежания автогенерации, Автор R7KBI
+HARDW: VHF-Board-v4: Добавлен разъём для подключения минуса питания, Автор R7KBI
+HARDW: VHF-Board-v4: Добавлена возможность установки ПАВ фильтра на вход УМ 144MHz модуля, Автор R7KBI
+STM32: Обновления для RU перевода, Tnx R3XG
+STM32: Исправления в CN теме оформления, Tnx SP7MFR
+STM32: Wolf-2: Теперь TX AMP сигнал блокируется в зависимости от EXT PA Mode аналогично линии EXT PTT, Tnx R1CDZ
+STM32: Wolf-2: Добавлено меню и интерфейс для отладки экспериментального Digital Pre Distortion (подробнее в Readme файле)
+STM32: Добавлена настройка "FTx Correct time", позволяющая корректировать время на трансивере за счёт расчёта среднего отклонения от декодов FT8
+STM32: Обновлены правила расчёта временных слотов FT4
+STM32: Мощность в "EXT PA Mode" и без него запоминается отдельно, Tnx R3TJL
+STM32: Настройка "VAD Threshold" переименована в "VAD SQL Threshold" для уменьшения разночтений функции
+STM32: Добавлена возможность фильтрации спотов кластера по маске позывного, Tnx RT3W
+STM32: Настройки ATU для "EXT PA Mode" разделены на Internal и External ATU. Первый блокирует внутренний тюнер в режиме PA, второй блокирует внешний PA во время настройки внешнего ATU, Tnx SP7MFR
+STM32: Wolf-2: Улучшен механизм прошивки ESP через USB порт трансивера без использования USB-TTL, обновлена инструкция, Tnx UT8EU
+STM32: Wolf-2: Обновлён механизм опроса нажатий кнопок лицевой панели
+STM32: Добавлена индикация активности на втором приёмнике, если включены режимы Double + SQL, то при появлении сигнала подсвечивается активный VFO, Tnx RV9XG

----Version 14.5.0----
+STM32: Добавлена поддержка TCXO 12.880 и 5.000 MHz, Tnx Roman, RU1QX
+STM32: Улучшена работа выхода SPKOUT на платах с кодеками NAU8822, Tnx R7KBI
+STM32: При выходе из FT8 возвращается первоначальное состояние SQL, Tnx R4PHD
+STM32: Исправлена работа СВЧ трансвертеров при установке ПЧ в 50мгц и ниже диапазоне, Tnx RA6KE
+STM32: Оптимизация работы CW мульти-декодера, Tnx RA6KE
+STM32: Вернул настройку порога срабатывания анти-дребезга CW ключа "Debounce Rate"
+STM32: Запись своего голоса во время передачи теперь корректно работает в AM/FM, Tnx RA6KE
+STM32: Исправления ошибок в теме Large, CN, Tnx Александр, SP7MFR
+STM32: Для СВЧ диапазонов выделена отдельная калибровка предела шкалы измерителя мощности, Tnx RT5D
+STM32: Wolf-100D: Добавлена настраиваемая функциональная кнопка TUNE, Tnx Евгений
+STM32: Линия EXT-Tune блокируется если включен PA Mode, но выключен ATU in PA mode, Tnx SP7MFR
+STM32: Добавлена функция "USB VOX", переводящая трансивер в TX при передаче аудио в USB-аудио карту, Tnx RA9YON
+STM32: Запуск авто-калибровки мощности по диапазонам происходит по нажатию на ENC2, а не сразу при перелистывании, Tnx R1CDZ
+STM32: В строке статуса репитерного режима отображается текущее смещение, а при нажатии тачпадом он отключается, Tnx E72X
+STM32: В FT8/FT4 заблокирован нижний ряд кнопок, Tnx R3TJL
+STM32: В FT8 добавлена кнопка "Log", записывающая текущую связь в лог и останавливающая обмен, Tnx WC1J
+STM32: Улучшения работы интерфейса File Manager во время записи/воспроизведения, Tnx EA5GSA

----Version 14.4.0----
+STM32: Добавлены настройки "Add 2nd harmonics", "Add 3rd harmonics", "Add Asymmetry" для добавления различных гармонических искажений в НЧ сигнал динамика (эмуляция аналоговых трактов)
+STM32: Обновление RU перевода, Tnx R3XG
+STM32: Обновление CN перевода, Tnx BH7FFB
+STM32: Уменьшен интервал обновления AllQSO спота до 10 секунд, Tnx R4PHD
+STM32: Серьёзно переработана работа CW-ключа, Tnx R5ZX
+STM32: Добавлен режим отладки "CW" для отслеживания проблем с электронным ключом, Tnx R5ZX
+STM32: Улучшена поддержка Logger32 в режиме эмуляции FT-450, Tnx SP7MFR
+STM32: Если версия FPGA не корректна, она подсвечивается красным в System Info, Tnx BD6MM
+STM32: Добавлена CAT-команда #[text] для ввода текста с клавиатуры в пунктах меню и меню корреспондента, Tnx R3TLI
+STM32: Доработки CAT-команд DN UP PB, Tnx R3TLI
+STM32: Исправлена проблема с сигналом EXT_Tune при передаче в FT8, Tnx Harry Weinfurt
+STM32: Из интерфейса FT8 убрана отладочная информация про "Beacon State", Tnx WC1J
+STM32: Добавлена память ключа в режиме Iambic, Tnx R5ZX
+STM32: Добавлена настройка "WSPR Skip Cycles", позволяющая задать пропуск циклов после окончания каждого сеанса передачи WSPR маяка, Tnx ES1RCG
+STM32: Добавлен скроллинг для экранной консоли отладки (для 7 дюймовых версий)
+STM32: Добавлена поддержка TCXO на 41.600МГц, Tnx Сергей Нефёдов
+STM32: Улучшение работы DNR (обновите Threshold / IF Gain настройки под себя для лучшего эффекта), Tnx WC1J
+STM32: При выключенном BreakIn работает CW-декодер ключа оператора, Tnx R4PHD
+STM32: Добавлена настройка "TX Inhibit" и настраиваемая функциональная кнопка "PTT OFF" для включения запрета перехода на передачу, Tnx RA9YON
+STM32: Доработка функции "CAT Transverters IF", Tnx R6DLC

----Version 14.3.0----
+STM32: Работы по Русификации интерфейса, Tnx RA3XCS
+STM32: Новый шрифт для CN перевода, Tnx @buwv7
+STM32: Обновления для CAT в режиме эмуляции FT-450, Tnx Serg
+STM32: Mute теперь не влияет на AUDIO-выход USB, Tnx RU3KV
+STM32: Исправлена работа CW Multi-декодера во время передачи, Tnx BI4JWL
+STM32: Wolf-100D: Исправлена работа сигнала EXT PTT для режима EXT PA Mode, Tnx SP7MFR
+STM32: Настройка "TX AGC Clipping" разделена на SSB и AMFM группы, Tnx UR5MBQ
+STM32: Для Large темы оформления выведен статус ATU, Tnx SP7MFR
+STM32: Добавлена калибровка "CAT Transverters IF", позволяющая передавать по CAT частоту ПЧ трансвертера, а не частоту VFO, Tnx R6DLC
+STM32: Долгое нажатие на функциональную кнопку "REPIT" открывает меню настройки смещения, Tnx E72X
+STM32: При активном репитерном режиме отображается статус и направление смещения на главном экране, Tnx E72X
+STM32: Добавлена калибровка "SD TX Record level", регулирующая уровень записи собственного сигнала на карту памяти во время передачи / записи макроса, Tnx R6DLC
+STM32: Wolf-2: Исправлена ошибка Self Test тюнера, если выбран УКВ диапазон, Tnx RT5D
+OTHER: Написан dll-модуль WolfIntf.dll, для связки трансивера Волк с ПО Afreet CW(RTTY) Skimmer Server (48кГц IQ + CAT через OmniRig)

----Version 14.2.0----
+STM32: Включение небольшой индуктивности ATU по умолчанию на 24/28МГц пока ограничена только версией прошивки для Wolf-2
+STM32: Уровень самопрослушки DIGI теперь можно убрать до нуля, Tnx RC3RF, R3TJL
+STM32: Пункты меню FFT Automatic и FFT Manual перемещены в зону одного листа экрана настройки, Tnx R5ZX
+STM32: Добавлен экспериментальный режим "CW Multi-Decoding", позволяющий декодировать до 10 сигналов CW в полосе обзора одновременно
+STM32: Добавлена возможность выбора адреса NTP-сервера, Tnx R3TKS
+STM32: В FT8 выводится сокращенный локатор, а не полный, Tnx R3TJL
+STM32: Пункты "Repeater offset" изменяются с шагом 10кГц вторичным энкодером и с шагом 1кГц основным
+STM32: Выбранный "Repeater offset" сохраняется в каналы памяти, Tnx PY2MDA
+STM32: Добавлена укрупнённая тема оформления "Large" для людей с плохим зрением, Tnx RU3RQ
+STM32: Начало работы над локализацией текстов на разные языки, добавлены Русские шрифты и частичный перевод
+STM32: Добавлен перевод на Китайский язык, Tnx BH7FFB, BD6MM
+STM32: В WSPR маяке используются антенны, сохранённые для диапазонов, Tnx RU4PN
+STM32: Улучшен алгоритм включения обхода ATU, Tnx R7KBI

----Version 14.1.0----
+FPGA: Исправление ошибок, Tnx WC1J
+STM32: Wolf-2: Долгое нажатие на кнопку ANT включает дополнительную приёмную антенну RXANT, Tnx RM0A
+STM32: Добавлена настройка "ATU AutoRun", позволяющая автоматически включать ATU при КСВ > 1.5, Tnx UA3RU
+STM32: Настройка "Input Auto Switch" теперь может работать совместно с "Sequencer support", Tnx RU3RQ
+STM32: Доработки Wolf Interface, Tnx R3TLI
+STM32: Подключение Wolf Interface теперь осуществляется через разъём программатора STM32. Линия SCL подключена к SWDIO, линия SDA к SWO, Tnx R3TLI
+STM32: Исправлена проблема с самоконтролем CW при активном CW-декодере
+STM32: При включении PA Mode подсвечивается текущая мощность и режим, Tnx R1CDZ
+STM32: Поправка показаний УКВ С-метра в баллах теперь работает от 30Мгц, а не от 60Мгц, Tnx R1CDZ
+STM32: Wolf-2: На вывод микросхемы U2-Drain 7 выведен сигнал активности тюнера для реализации обхода ATU, Tnx R3TAR
+STM32: Уровень самопрослушивания DIGI и VOICE отвязан от текущего общего уровня громкости по аналогии с CW-самоконтролем, Tnx RM0A
+STM32: По умолчанию, на диапазонах >24Мгц включается небольшая индуктивность для компенсации реактивности тюнера. Для применения требуется выполнить полный сброс, Tnx R3TJL, Dire Wolf
+STM32: Улучшено сохранение пресетов фильтров через функциональные кнопки, Tnx R3TJL
+STM32: Калибровка "Linear Pwr Control" переименована в "Power Control" с выбором вариантов управления уровнем сигнала с ЦАП: регулировка мощности или амплитуды
+STM32: Разделены RX эквалайзеры SSB, AM и NFM, Tnx Dispatcher
+STM32: Статус AGC теперь сохраняется по модам, а не по бендам, Tnx RN9RQ

----Version 14.0.0----
+FPGA: Устранён ВЧ выброс после завершения передачи, Tnx Oleksandr, BH7FFB
+STM32: Исправлена периодическая проблема расчёта координат при переключении спутников
+STM32: Доработки алгоритмов ATU для улучшения работы в НЧ бендах, Tnx R3RM, RY7Z
+STM32: Во время настройки ATU показания мощности ограничены значением "Max Power Tune" из-за некорректных измерений на больших КСВ, Tnx R3TAR
+STM32: При возможности ATU первым делом пытается подстроить текущие значения, а не начинать цикл с нуля
+STM32: Secondary COM RTS линия в калибровках отключена по умолчанию
+STM32: Добавлены калибровки, позволяющие скомпенсировать плохую изоляцию КСВ-метра, приводящую к затеканию прямой волны в датчик обратной волны
+STM32: Добавлена настройка "SWR Hold Peaks", позволяющая задерживать измеритель мощности на максимальных значениях, Tnx Oleksandr
+STM32: Wolf-1: Доработки для "Transverter only TX" режима, Tnx R9MDA
+STM32: Добавлена возможность отключать любой КВ диапазон через калибровки, Tnx RA6KE
+STM32: Ускорено нарастание мощности Tune-несущей при активном EXT PA Mode и калибровках RF Gain, значительно меньших чем без PA mode, Tnx SP7MFR
+STM32: Добавлена настройка "RTTY Filter Margin", регулирующая ширину RX фильтра в RTTY моде относительно частот несущих, Tnx RM0A
+STM32: Устранён щелчок в динамике при переходе TX->RX в CW, Tnx R3TJL
+STM32: "CW Memory debounce" уменьшен до 80мс по умолчанию, не забываем об установке конденсаторов на линии ключа если их нет на материнской плате, Tnx R3TJL
+STM32: Исправлено сохранение калибровок при закрытии меню через долгое нажатие кнопки, Tnx R8QBE
+STM32: На экраны меню калибровки мощности/КСВ выведены плитки с текущими показаниями датчиков, Tnx R3TLI
+STM32: Кнопка "EQ" не подсвечивается в модах, где эквалайзер не применяется
+STM32: Исправлена работа функциональной кнопки "Balance", Tnx SP7MFR

----Version 13.7.1----
+STM32: Исправление ошибок с зеркальным приёмом и BreakIn, Tnx SP7MFR

----Version 13.7.0----
+STM32: RX эквалайзер теперь не участвует в формировании звука самоконтроля с отключенным Break-In, Tnx SP7MFR
+STM32: Wolf-1: вернул функцию NONE для настраиваемых кнопок, Tnx PY2MDA
+STM32: Увеличено количество точек доступа WiFi, доступных для выбора в меню, Tnx SP7MFR
+STM32: Добавлена настройка "Use Keyer for RTTY", позволяющая ключевать RTTY из MMTTY и подобных программ через CW COM-порт без участия аудио-входа, Tnx RM0A
+STM32: Добавлен самоконтроль в FM моде, Tnx UR5MBQ
+STM32: Управление Dual RX продублировано в главное меню
+STM32: Добавлены режимы "A Only" и "B Only" для Dual RX Type, которые позволяют слышать только один VFO, но не останавливать двойной приёмник
+STM32: Добавлена настройка "Dual RX IQ", указывающая источник (VFO) IQ сигнала для отправки в USB аудио-карту в режиме Dual RX. Позволяет настроить мониторинг IQ на фиксированной частоте, не перестраиваясь от основного VFO, Tnx RU3RQ
+STM32: Улучшена проверка контрольной суммы в сохраненных настройках, что могло приводить к ошибкам чтения
+STM32: Добавлены кнопки отключения NR/NB в диалоговые окна, старые кнопки теперь только включают, но не отключают
+STM32: Небольшие диалоговые окна открываются прямо в месте нажатия
+STM32: Wolf-Mini: Убраны дублирующие кнопки SMPL из списка преднастроенных функциональных кнопок
+STM32: Частота передачи FT8/FT4 теперь сохраняется в настройках и может быть изменена в меню (а не только во время работы декодера), Tnx BI2QDM
+STM32: Калибровки по умолчанию для EXT-порта приведены в соответствие с Band-Data, Tnx RM0A
+STM32: На кнопке закрытия в меню отображается название текущего подраздела, Tnx RM0A

----Version 13.6.1----
+STM32: Добавлен экспорт настройки Tropo Region на SD-карту, Tnx I2NOY
+STM32: Удалён сброс RIT/XIT при отключении, сброс на долгое нажатие кнопки остался, Tnx SP7MFR
+STM32: Добавлена настройка "Enbl ATU in PA mode", определяющая, включать ли тюнер в режиме "EXT PA Mode", Tnx SP7MFR
+STM32: Wolf-Mini: Добавлена настраиваемая функциональная клавиша "Double" и возможность включения второго приёмника (для 22K FPGA), Tnx Dispatcher
+STM32: Исправление мелких ошибок

----Version 13.6.0----
+FPGA: Улучшен процесс инициализации RX цепей
+STM32: Снижен ток на шине FPGA-STM для уменьшения внутренних помех
+STM32: Удалены малоэффективные оконные функции FFT
+STM32: Wolf-1-RU4PN-Board: Выведен сигнал EXT_PTT на микросхему U3-Drain6 (для корректной работы в паре с "EXT PTT in PA mode"), Tnx R3DID
+STM32: Функциональная кнопка "Power" подсвечивается зеленым при активном "EXT PA Mode", долгое нажатие переключает режимы, Tnx SP7MFR
+STM32: Wolf-1: При выключении RIX/XIT значение расстройки сбрасывается в ноль, Tnx RZ6HHF

----Version 13.5.0----
+FPGA: Обновлена прошивка до 13.4.0-7, исправлены ошибки, Tnx SP7MFR
+STM32: Улучшения в работе WiFi, Tnx SP7MFR
+STM32: Обновлено окно выбора NB, Tnx SP7MFR
+STM32: Добавлено окно выбора DNR, Tnx SP7MFR
+STM32: Калибровка ВЧ мощности вынесена в отдельное подменю
+STM32: Добавлена настройка "EXT PA mode" - включает режим работы с внешним усилителем, в этом режиме применяется другой комплект калибровок RF Gain, Tnx RV9CT, SP7MFR
+STM32: Добавлена настройка "EXT PTT in PA mode" при активации сигнал EXT PTT подаётся только при включении "EXT PA mode"
+STM32: Управление "EXT PA mode" добавлено на окно выбора мощности
+STM32: В сервис автоматической калибровки мощности добавлено отображение последнего КСВ, напряжения, тока (при наличии INA226), Tnx R1CDZ
+STM32: В настройку "DX Cluster Type" добавлен тип "TELNET" для соединения с внешним или локальным DX-кластером для отображения спотов, Tnx RU3RQ
+STM32: Улучшено округление частоты при активной акселерации энкодера, Tnx Oleksandr
+STM32: Улучшена работа FT8 с корреспондентами, имеющими длинные позывные и постфиксы /P или подобные, Tnx DG3VG, R3TAR
+STM32: Исправлено обновление S-метра при закрытии окон в интерфейсе, Tnx UR5MBQ
+STM32: Wolf-Mini: Добавлены часы в интерфейс главного экрана, Tnx UR5VLC
+STM32: Wolf-Mini: Исправлено переключение на Line вход кодека, Tnx Dispatcher
+STM32: Разделены настройки микрофонного эквалайзера для AM и для FM, Tnx Dispatcher
+STM32: Добавлена индикация активного CAT соединения, Tnx RM0A
+STM32: Добавлена настройка "Accessibility" для операторов с нарушением зрения, включается телеграфирование текущего бенда и моды в динамик при переключении, Tnx Oleksandr
+STM32: Wolf-2/Mini: При активной "Accessibility" нажатие на аппаратную кнопку Func запускает телеграфирование текущей частоты и моды в динамик
+STM32: Wolf-1: Добавлена настраиваемая функциональная кнопка "ACCESS", которая запускает телеграфирование текущей частоты и моды в динамик

----Version 13.4.0----
+FPGA: Улучшена линейность АЧХ передачи в полосе сигнала
+FPGA: Различные оптимизации кода
+STM32: Для калибровки "Second COM Mode" добавлен новый режим "ESP", который транслирует обмен между COM портом и ESP модулем. В этом режиме возможна прошивка ESP без USB-TTL (не забываем замыкать Flash перемычку на ESP), Tnx Linoob
+STM32: Переход на новую версию прошивки WiFi ESP модуля с поддержкой TLS (Обновлена инструкция в Dropbox)
+STM32: Небольшая оптимизация скорости загрузки изображений в сервисах WiFi
+STM32: Самопрослушивание CW без перехода на передачу теперь работает на оба звуковых канала, Tnx SP7MFR
+STM32: Добавлен новый раздел сервисов "Web Skimmers", где будут находиться сервисы онлайн отслеживания скиммеров, принявших сигнал оператора, Tnx RT3W
+STM32: Добавлен сервис отображения спотов оператора от скиммеров с WSPRnet
+STM32: Добавлен сервис отображения спотов оператора от скиммеров с RBN (ReverseBeacon)
+STM32: Добавлен сервис отображения спотов оператора от скиммеров с Pskreporter
+STM32: Удалён NB1, вместо него остались NB2 и NB3 (названы 1 и 2 соответственно). Обновлены пороги срабатывания по умолчанию, Tnx SP7MFR
+STM32: Для управления Noise Blanker сделано отдельно окно
+STM32: Реализовано затенение иконок моды на неактивном VFO в CN темах, Tnx Oleksandr
+STM32: После приёма SSTV изображения оно автоматически сохраняется на SD карту
+STM32: Улучшения в RDS декодере
+STM32: Устранение мелких ошибок

----Version 13.3.0----
+STM32: Wolf-1: Добавлена программная поддержка платы W2-VHF для работы на VHF/UHF/SHF диапазонах с первой версии трансивера. Подключается к I2C шине (J8) и J11 (ENX)
+STM32: Различные оптимизации кода
+STM32: Wolf-2: Оптимизация инициализации RFFC2071, Tnx UT8EU
+STM32: Добавлен экспериментальный подавитель импульсных помех NB3, нужно опробовать с разными типами помех и разными настройками Threshold
+STM32: Уменьшены переходные процессы TX/RX на FFT при Scale Type dBm, Tnx Юрий
+STM32: Отключение BreakIn теперь корректно работает совместно с Auto CW Mode, Tnx SP7MFR
+STM32: Добавлена настройка "Pwr by main ENC", позволяющая регулировать мощность ВЧ основным энкодером во время передачи, Tnx R3TKS
+STM32: Настройка "Second COM Mode" вернулась назад в калибровки, Tnx UT8EU
+STM32: Кнопки выбора моды неактивного VFO затенена (кроме CN тем), Tnx Oleksandr
+STM32: Для улучшения динамики, ADC PGA отключен по умолчанию и в AutoGainer, Tnx R1BLT
+STM32: Улучшено подавление приёма шпуров от мощных внеполосных сигналов на спектре шириной менее 48кГц
+STM32: Добавлена настройка "ENC2 Priority enbl", управляющая автоматическим переключением режима функционального энкодера по таймауту, Tnx R1BFJ
+STM32: Исправлен сброс S-метра при нажатии на кнопку DRV, Tnx R1CDZ

----Version 13.2.0----
+STM32: Wolf-1: Добавлена поддержка кнопок тангенты MH48, Автор RA3RBE
+STM32: Добавлены CW настройки "Memory size" и "Memory debounce, ms" для регулировки памяти электронного ключа
+STM32: Оптимизация производительности WFM на 384кГц полосе
+STM32: Исправления в отображении Self Test, Tnx SP7MFR
+STM32: Wolf-1: Исправления в работе ENC2 в окне EQ, Tnx Oleksandr
+STM32: VOX теперь не срабатывает в CW, Tnx UZ5DM
+STM32: Wolf-2: Энкодер регулировки фильтра автоматически переключается в режим LPF, если регулировку HPF не позволяет мода, Tnx UZ5DM
+STM32: Self Test тюнера корректно отрабатывает, даже если он изначально выключен, Tnx R1CDZ
+STM32: Исправлено восстановление настроек при выходе из SSTV декодера, Tnx SP7MFR
+STM32: Увеличена точность и количество попыток настройки ATU, Tnx UZ5DM
+STM32: Добавлена калибровка "ADC Driver Gain", позволяющая выбрать тип установленного драйвера АЦП для компенсации S-метра (фактическое усиление), Tnx RM0A
+STM32: При нулевом "ADC Driver Gain" (работа без драйвера) кнопка DRV заменяется на управление PGA, Tnx RM0A
+STM32: Увеличен шрифт КСВ и мощности на теме оформления "7 segment", Tnx RM0A
+STM32: Воспроизведение CW останавливается при начале ручной манипуляции ключом или через CAT, Tnx UX2CT
+STM32: Долгое нажатие на "SelfHR" открывает различные настройки в зависимости от моды, Tnx UZ5DM
+STM32: В настраиваемые функциональные кнопки добавлена функция A/B как альтернатива XFC, Tnx UR5MBQ
+STM32: Wolf-1: Регулировка мощности основным энкодером теперь возможна только в режиме Tune, Tnx PA3CMP
+STM32: Уменьшена полоса и скорость отклика ФАПЧ демодулятора SAM, Tnx RU4PN
+STM32: Улучшен обмен аудио данными TX по USB
+STM32: Wolf-2: Исправлено отключение УКВ PLL Lock светодиода после перехода на передачу
+STM32: Регулировка мощности WSPR маяка вынесена в отдельную настройку, Tnx Vitaly
+STM32: Добавлена настройка "LPF Timeout", управляющая отключением ФНЧ спустя время после перехода TX->RX, Tnx Dire Wolf
+STM32: Долгое нажатие на экранную кнопку DRV открывает окно управления ADC DRV, ADC PGA и AutoGainer
+STM32: В окно выбора моды добавлены кнопки вызова WSPR и окно ввода корреспондента макросов
+STM32: Добавлена настройка "ENC2 Priority" для выбора приоритетной функции вторичного энкодера, на которую происходит автоматическое переключение после 30сек бездействия, Tnx RV9CT
+STM32: При ключевании CW без перехода в TX (без Keyer PTT) происходит самоконтроль ключа в режиме RX
+STM32: Добавлена настраиваемая функциональная кнопка "Break In", которая переключает тип настройки CW PTT Type, Tnx R5ZX
+STM32: Добавлена настройка "FFT Measurements", отображающая на водопаде различные измерения спектра (спектральная плотность шума, SNR и прочее)

----Version 13.1.0----
+STM32: Улучшения в работе FFT Lens
+STM32: Улучшение работы RDS при 384кГц обзоре
+STM32: Добавлена настройка "AutoCQ Macros 1", позволяющая настроить авто-вызов CQ макроса CW/SSB/RTTY с заданным интервалом долгим нажатием на кнопку, Tnx UZ5DM, R4PCB
+STM32: Устранено подвисание при возникновении ошибки импорта с SD карты, Tnx R1BLT
+STM32: Увеличена максимальная длина имени макросов, Tnx SP7MFR
+STM32: Добавлена возможность управления аттенюатором с помощью функционального энкодера (при неактивном AutoGainer, шаг задаётся настройкой Att step), Tnx R1BLT
+STM32: Wolf-2: Включен светодиод Lock для RFFC2071, Tnx RU4PN
+STM32: При включении SSTV декодера автоматически отключается DNR и NB, Tnx SP7MFR
+STM32: Исправление разных ошибок

----Version 13.0.0----
+STM32: WOLF-2-Pro: Поддержка регуляции подсветки кнопок и экрана
+STM32: Небольшие доработки CW декодера
+STM32: Доработки импорта макросов из файла настроек
+STM32: При входе во встроенные FT4/FT8 автоматически отключаются DNR/NB/SQL/Notch, Tnx SP7MFR
+STM32: Добавлен выбор активной полосы в окне эквалайзера с помощью функционального энкодера, Tnx Oleksandr
+STM32: Autogainer автоматически отключает ADC PGA на мощных сигналах, Tnx UR5MBQ
+STM32: Исправлен порядок значений в настройке Freq Step FM, Tnx SP7MFR
+STM32: Исправлена регулировка параметра "Transv 6cm IF kHz", Tnx RA6KE
+STM32: Исправлена отображение ошибки при некорректной версии прошивки ESP, Tnx BD6MM
+STM32: Wolf-Mini: Открыта настройка "Transv only TX" из старших версий (не проверялась), Tnx R6DLC
+STM32: Уменьшен передаваемый рапорт во встроенном FT8, Tnx RX3PX
+STM32: Доработки микрофонного АРУ
+STM32: Wolf-1: Кнопка XFC реализована по аналогии с Wolf-2, Tnx R3RM
+STM32: Улучшения в работе FFT Lens, Tnx Oleksandr
+STM32: При выходе из SSTV декодера трансивер возвращается в ранее выбранную моду, Tnx SP7MFR
+STM32: Добавлен быстрый запуск FT4/FT8/SSTV декодеров через окно выбора моды, Tnx DL1EGQ
+STM32: Wolf-2: Добавлена калибровка уровня тока смесителей УКВ платы, Tnx OE1BKP, Sergey Klimov
+STM32: Долгое нажатие на VOX и CESSB теперь открывает их настройки, Tnx SP7MFR
+STM32: Функция Mute теперь не влияет на встроенный FT8/FT4 декодер, Tnx RA6UAC
+STM32: Автоматическая подстановка позывного корреспондента в RTTY по шаблонам декода CQ -call- -call- и TEST -call- call- (аналогично CW)
+STM32: Wolf-Mini: Убраны пункты меню "ANT 1/2 Type", Tnx R7KBI
+STM32: Чуть лучше распределены цвета на водопаде FT8
+STM32: Wolf-Mini: Исправлена ошибка в подаче тока покоя на КВ усилитель во время работы на УКВ, Tnx 4K6Z
+STM32: Увеличен масштаб оси Y в SWR анализаторе, Tnx R1CDZ
+STM32: Добавлена настройка "Repeater tone", добавляющая тон 1750Гц в начало FM передачи для открытия репитера, Tnx F5IWR
+STM32: Калибровка "Second COM Mode" перенесена в настройки для быстрого доступа
+STM32: Добавлен новый режим работы "Second COM Mode" "DATA", выводящий в COM-порт результат декода CW и RTTY
+STM32: При отправке текста в DATA COM-порт в модах CW и RTTY происходит передача его в эфир
+STM32: Добавлена возможность подстройки по частоте во время декодирования SSTV, Tnx DL1EGQ

----Version 12.5.1----
+STM32: Обновлены настройки по умолчанию
+STM32: Меню установки времени теперь работает от вторичного энкодера
+STM32: Исправлена проблема с отображением маркеров частот на спектре, Tnx SP7MFR
+STM32: Исправлена проблема c Stereo FM, Tnx SP7MFR
+STM32: Уменьшено предусиление FT8 декодера
+STM32: Исправлена работа FT8 энкодера при работе с хешированными позывными, Tnx RX3PX
+STM32: Исправления в процессе импорта настроек, Tnx Papandupolo
+STM32: Улучшения работы макросов
+STM32: Улучшена работа VOX, Tnx R9OAD

----Version 12.5.0----
+HARDW: Wolf-BA7LJL: Добавлены схемы и фотографии трансивера модификации BA7LJL
+HARDW: Wolf-DK102: Добавлена инструкция по сборке платы антенного тюнера, Tnx BH7FFB
+STM32: WOLF-100D: Возвращена настраиваемая функциональная кнопка "BANDMP", Tnx SP7MFR
+STM32: WOLF-Mini: Исправлено отображение герц а СВЧ бендах, Tnx RT5D
+STM32: WOLF-Mini: Исправлена проблема, когда RDS могло прикрывать функциональные кнопки, Tnx UR5VLC
+STM32: Исправлена работа DNR, когда включен режим Double на одинаковых бендах, Tnx SP7MFR
+STM32: Исправлена работа при переключении VFO с активным DX Split, Tnx SP7MFR
+STM32: Исправлено сохранение выбранного спутника, Tnx RT3W
+STM32: Добавлен RTTY энкодер, работает на макросах CW по тем же кнопкам

----Version 12.4.0----
+STM32: Переделано окно получения информации о позывном корреспондента (короткое нажатие по позывному на главном экране)
+STM32: Добавлена функциональная кнопка "DXCALL" для ввода позывного корреспондента
+STM32: Маркер введённого корреспондента отображается на спектре
+STM32: Персональная информация (Callsign, QTH, WiFi, Макросы) вынесена в отдельную область EEPROM и будет реже сбрасываться при дальнейшем обновлении прошивок
+STM32: Максимальное количество знаков в CW макросах увеличено до 100 символов
+STM32: Количество макросов CW/SSB расширено до 8
+STM32: Обновлены CW макросы по умолчанию, Tnx RM0A
+STM32: Обновлен алгоритм ввода текста с экранной клавиатуры в текстовых пунктах меню
+STM32: Добавлена настройка для ввода имени оператора
+STM32: Добавлена возможность использовать вставки в CW-макросах, куда подставляется позывной оператора, корреспондента и т.п. подробности о видах вставок в README
+STM32: CW декодер может распознавать последовательности CQ -call- -call- и TEST -call- call-, автоматически подставляя позывной корреспондента
+STM32: Смещена позиция надписи "Stereo FM" при активном dBm Grid отображении спектра, Tnx EA7HOG
+STM32: Split DX автоматически отключается при смене бенда
+STM32: Добавлена калибровка "Swap AF & IF", позволяющая поменять ручки регулировки AF/IF местами, Tnx RU4PN
+STM32: Wolf-Mini: Исправления в оформлении FT8, Tnx RA6UAC
+STM32: Добавлен экспериментальный декодер FT4 + обновления в FT8
+STM32: Точность настройки трансвертеров расширена до kHz, Tnx Andrey Nikolaev
+STM32: Wolf-2: Добавлена настраиваемая функциональная кнопка "RXANT", позволяющая подключить дополнительную приёмную антенну с управлением от сигнала U23-7 регистра, Tnx RM0A
+STM32: Немного сглажены переходные процессы звука при переключении RX/TX, Tnx RM0A
+STM32: Увеличена чувствительность SSTV декодера, добавлена автокорректировка частоты в небольших пределах
+STM32: Обновлены встроенные Amateur Radio Country Files
+STM32: Расширен список поддерживаемых SD карт, Tnx RM0A
+STM32: Добавлен вывод герц частоты VFO-A на СВЧ бендах (CN темы и Wolf-Mini), Tnx RT5D

----Version 12.3.0----
+STM32: Исправление подгрузки TLE файла, Tnx RT3W
+STM32: Исправление ошибки выхода из FT8 с активным Free Tune, Tnx UZ5DM
+STM32: Исправление ошибок сохранения в EEPROM, Tnx SP7MFR
+STM32: Добавлен SSTV-декодер для мод PD 50/90/120/180, Scottie 1/2, Martin 1/2 (пока без сохранения на SD)
+STM32: Wolf-2: Bluetooth модуль не отключается при отключении Mute, Tnx R9FDL
+STM32: Wolf-Mini: Кнопка Band теперь не активна в меню, Tnx Dispatcher
+STM32: Увеличен порядок полосового фильтра для WFM моды на 384кГц полосе, Tnx Dispatcher
+STM32: Добавлено отображение КСВ/Мощности по CAT, Tnx R5ZX
+STM32: Добавлен тип отладки "SD" для поиска проблем в работе карт памяти
+STM32: Wolf-Mini: Исправлена работа с трансвертерами, Tnx RT5D
+STM32: Wolf-DK102: Обновление настроек и калибровок по умолчанию
+STM32: Wolf-DK102: Обновлена инструкция по сборке и эксплуатации на Русском языке, Tnx BH7FFB
+STM32: Добавлена функция "Lock in IQ Mode" для блокировки трансивера на IQ моде (для работы с HDSDR и подобным ПО), Tnx SP7MFR
+STM32: Добавлена возможность переключения CW-L/CW-U аппаратной кнопкой моды, Tnx UZ5DM
+STM32: Добавлены иконки мод AM-L/AM-U в CN тему оформления, Tnx SP7MFR
+STM32: Улучшена память электронного CW ключа
+STM32: Wolf-2: Добавлена возможность регулировки шага перестройки мощности энкодером на лицевой панели, Tnx RM0A
+STM32: Wolf-2: Аппаратная кнопка A/B теперь работает как A<>B (свап частот между VFO), Tnx RM0A

----Version 12.2.0----
+HARDW: Wolf-2-VHF-v3f: Исправления в схеме: изменены драйверы усилителей, питание 1.2G, номиналы фильтров 433MHz. Плата осталась прежней, Thx UN7JMM, Sergey Klimov
+HARDW: Wolf-DK102: Добавлена инструкция по сборке, Tnx BH7FFB
+STM32: Wolf-DK102: Добавлена отдельная прошивка с предустановленными настройками, улучшена инициализация аудио-кодека
+STM32: Добавлена возможность отображения названий станций на водопаде из файла на SD карте. Пример файла station_names.txt размещён в папке Stuff. Автор BD6MM
+STM32: Wolf-2: Улучшен процесс инициализации УКВ платы
+STM32: Wolf-2: Запрещен переход по диапазонам во время передачи с помощью кнопок на лицевой панели, Tnx RM0A
+STM32: Коэффициент сглаживания значений с-метра вынесен в настройку "S-Meter smooth", Tnx R1BLT
+STM32: DNR Threshold снижен по умолчанию
+STM32: Wolf-Mini: В настраиваемые функциональные кнопки добавлен Autograiner, Tnx R3TKS
+STM32: Улучшена отзывчивость второстепенных энкодеров, увеличен Debounce по умолчанию
+STM32: Добавлены калибровки "SD Recording power" и "SD Macros power" для регулировки коэффициента мощности воспроизведения с SD карты в эфир
+STM32: Исправлено переключение диапазонов при активной FFT Lens
+STM32: FT8 логи сохраняются раздельно по указанному в настройках позывному, Tnx UN7LAS
+STM32: Добавлена калибровка "Min Voltage protect", экстренно выключающая трансивер при низком значении питающего напряжения на INA226, Tnx p m
+STM32: Улучшена поддержка CAT команд и работа Ham Radio Deluxe
+STM32: Консоль отладки перемещена в меню TRX, рядом с выбором типа отладочной информации
+STM32: Добавлена пагинация для выборка спутника по TLE файлу
+STM32: Добавлена возможность запретить передачу на одну из антенн, выбрав её исключительно для RX, Tnx RM0A

----Version 12.1.0----
+STM32: Исправлена проблема с CAT PTT в JTDX и подобных программах, Tnx Сергей
+STM32: Исправлена проблема при использовании Free Tune + Split DX, Tnx SP7MFR
+STM32: Исправлена проблема при использовании Split DX за пределами диапазонов (не срабатывала блокировка передачи), Tnx SP7MFR
+STM32: Исправлено отображение полоски сигнала АЦП после перехода с трансвертерного диапазона, Tnx RT3W
+STM32: Улучшена работа сдвиговых регистров, Tnx R1CDZ
+STM32: W-Mini: оптимизировано обновление экрана при работе AutoGainer, Tnx RV9CT
+STM32: W-Mini: исправлено сохранение IF Gain по бендам, Tnx Dispatcher

----Version 12.0.0----
+FPGA: Попытка устранить периодические проблемы с фантомными сигналами (пока только 22к версия, временно будет работать и 11.1.0 в случае проблем)
+FPGA: В System Info теперь отображаются MIN/MAX значения на входе ЦАП во время передачи, Tnx R6DLC
+STM32: Добавлена экспериментальная поддержка внешнего интерфейсного устройства на базе ESP32, программируемого под нужды пользователя (см папку Stuff для информации)
+STM32: При отключенном Autogainer отображается уровень сигнала на входе АЦП (CN темы), Tnx Dire Wolf
+STM32: Улучшение алгоритма импорта настроек, Tnx SP7MFR
+STM32: Увеличен порядок фильтров IQ потока для 384кГц обзора, Tnx SP7MFR
+STM32: Добавлен DC-фильтр для SAM демодулятора, Tnx Jaz
+STM32: Доработки FM демодулятора "Diff" типа
+STM32: Wolf-1: В настраиваемые функциональные кнопки добавлена функция "TX", Tnx UT8EU
+STM32: Перемещена кнопка "EQ" на главной панели, Tnx R1BLT
+STM32: Улучшена работа CW макросов при задержке передачи, Tnx SP7MFR
+STM32: Wolf-Lite: Остановлено развитие кодовой базы из-за закончившейся ROM, далее только выпуск баг-фиксов к стабильному релизу
+STM32: Новый алгоритм шумоподавления DNR, в настройках задаются 2 порога срабатывания под предпочтения пользователя для быстрого переключения между режимами
+STM32: Экранные диапазонные кнопки в CN темах теперь работают аналогично аппаратным (короткое нажатие прыгает по ячейкам памяти, долгое - записывает в память), Tnx RT3W
+STM32: Ячейки памяти диапазонов сохраняют не только частоту, но и моду, Tnx UT8EU
+STM32: Добавлены предзаписанные пары ячеек памяти для основных диапазонов (SSB+CW)
+STM32: Wolf-Mini: Удалена опция "FUNC" с вторичного энкодера, Tnx R7KBI
+STM32: Wolf-Mini: Во время регулировки SSB HPF вторичным энкодером отображается текущее значение полосы фильтра, Tnx R7KBI
+STM32: Wolf-Mini: Улучшена система синхронизации параметров кодека NAU8822 по I2C, Tnx R7KBI
+STM32: Улучшен механизм определения перегрузки АЦП
+STM32: Усилена вычисляемая контрольная сумма, которая защищает настройки и калибровки от случайного повреждения
+STM32: Добавлена поддержка формата моно-16 бит для USB аудио-устройства, Tnx RN3KK, R3TLI
+STM32: Улучшение поддержки части CAT-команд, Tnx RN3KK
+STM32: В списке WiFi сетей выводится RSSI сигнала каждой из точек доступа, Tnx R7KBI
+STM32: Реализована поддержка удалёнки через Bi4Remote, https://t.me/bi4remote_team https://habr.com/ru/articles/797625/ , Tnx RN3KK, R3TLI
+STM32: Улучшена работа TOT в CW, Tnx SP7MFR
+STM32: Макросы выделены в отдельное меню
+STM32: Долгое нажатие на макрос в нижнем меню открывает страницу его редактирования
+STM32: Добавлено 5 макросов SSB, активируется на те же кнопки, что и макросы CW но в голосовых модах, им можно прописать свои имена на кнопках, Tnx RT3W
+STM32: Увеличено ускорение перестройки частоты при быстром вращении энкодера и активной настройке "TRX Settings -> Encoder Accelerate" (само ускорение настраивается в калибровках под энкодер), Tnx R1BLT

----Version 11.5.0----
+STM32: Улучшение работы связки CAT+CW+Секвенсор
+STM32: Улучшение работы CW самоконтроля, Tnx UT8EU
+STM32: Обновлено название классической 7 дюймовой версии первого волка на странице System Info, Tnx Андрей
+STM32: Вращение энкодера не портит изображение в консоли отладки, Tnx R8CDB
+STM32: Исправлена проверка Self Test -> FPGA Clocks во время передачи, Tnx R5ZX

----Version 11.4.0----
+STM32: Исправлено звучание WFM при активном стерео-режиме, но отсутствии приёма стерео дорожки, Tnx SP7MFR, UA9YHI, R1BFJ, PY2MDA
+STM32: В AM-демодулятор добавлен DC фильтр для предотвращения перегрузки, Tnx Jaz, R3TKS
+STM32: DX-кластер корректно возвращает пустой список, если запрашивается информация по бенду, который кластер не поддерживает (например 70см с RBN), Tnx RT3W
+STM32: Уменьшены переходные щелчки звука при переключении TX-RX, Tnx Геннадий
+STM32: Для экспериментов возвращена калибровка "ADC Offset", Tnx Геннадий
+STM32: Уменьшены артефакты на спектре при переключении TX-RX, Tnx SP7MFR
+STM32: Self Test теперь проводится на текущем выбранном диапазоне, а не только 14\144мГц, Tnx RU3KV
+STM32: Обновлены цвета отладочной консоли, Tnx RU3KV
+STM32: Добавлено напоминание о необходимости точной калибровки по приборам после проведения авто-калибровки
+STM32: Увеличено время отображения тултипа о доступном обновлении прошивки, Tnx UN7LAS, R8CDB
+STM32: В сервис "Self Test" добавлена страница проверки тюнера, Tnx DG3VG

----Version 11.3.2----
+STM32: Wolf-2: Улучшена работа УКВ смесителя в QO-100, Tnx E72W
+STM32: Wolf-2: На УКВ плате отключаются неиспользуемые смесители при переходе RX/TX что должно немного уменьшить лишний шум
+STM32: Улучшена работа ключа в режиме поддержки внешнего секвенсора
+STM32: Wolf-1: добавлена поддержка калибровки "TX End Delay", Tnx R6TW

----Version 11.3.1----
+STM32: Переставлены пункты в меню TX, чтобы КСВ было рядом с настройками тюнера, Tnx SP7MFR
+STM32: Исправлена работа АРУ и передача в Wolf-Lite, Tnx RL6MR, Андрей

----Version 11.3.0----
+STM32: Исправление работы CW и макросов в режиме поддержки внешнего секвенсора, Tnx RT3W
+STM32: На странице System Info теперь отображается ревизия процессора
+STM32: В калибровках названия LHF/MHF/HHF заменены на границы в мегагерцах, Tnx R1BLT
+STM32: При регулировке пункта калибровок "Tr QO100 RX If kHz" вторичным энкодером, шаг регулировки становится по 1 МГц, Tnx RT3W
+STM32: В меню добавлена регулировка добротности каждого из каналов эквалайзера
+STM32: Добавлена настройка "TX AGC Clipping", определяющая, будет ли АРУ резко ограничивать усиление сигнала при больших всплесках амплитуды
+STM32: В CN темах долгое нажатие на иконку CW моды главного VFO приводит к переключению режимов CW-LSB/CW-USB, Tnx SP7MFR
+STM32: Улучшена работа FFT Lens, Tnx SP7MFR
+STM32: Добавлено отображение статуса использования трансвертера, Tnx RT3W
+STM32: Добавлена функциональная кнопка "Sleep", переключающая режим отключения экрана по таймауту, Tnx SP7MFR
+STM32: В меню сервисов добавлен пункт "Debug Console", который отображает отладочную информацию на экран (копия того, что выводится в отладочный COM-порт), Tnx RU4PN
+STM32: Долгое нажатие на кнопку MENU полностью закрывает меню независимо от открытого подменю, Tnx SP7MFR
+STM32: Обновлены параметры Autogainer
+STM32: Устранены паразитные моргания фона водопада
+STM32: Исправлена работа встроенного FT8 с включенной поддержкой секвенсора
+STM32: Исправлен выход из FT8 во время передачи, Tnx RT3W
+STM32: При отключении Channel Mode автоматически отключается Split (включается для каналов с разносом частот), Tnx R9FDL
+STM32: В моде RTTY частота VFO отображается по частоте верхней несущей сигнала (RTTY Freq + половина RTTY Shift), Tnx UT8EU
+STM32: Устранена проблема с TOT Time в макросах, Tnx RT3W, R3YA, UA9YHI
+STM32: Добавлена калибровка "TX End Delay", позволяющая задать задержку между переходом TX->RX и переключением реле, Tnx R6TW
+STM32: Добавлен сервис "Efficiency", позволяющий примерно рассчитать эффективность антенно-фидерного устройства и каскадов TX, Tnx R4HID, R7KBI

----Version 11.2.2----
+STM32: Исправления работы SD карты

----Version 11.2.1----
+STM32: Исправлены отсутствующие знаки * на пользователях волк-кластера, Tnx SP7MFR
+STM32: Чтобы предотвратить зависания, WFM Stereo активируется только на частоте дискретизации 192кГц, Tnx RT3W

----Version 11.2.0----
+HARDW: Wolf-2: Добавлена блок-диаграмма лицевой панели, автор OH2GZK
+HARDW: Wolf-2-VHF-v3e: добавлены дополнительные фильтрующие конденсаторы по питанию модулей и изменены номиналы текущих
+STM32: Настройка ADC Randomizer включена по умолчанию
+STM32: В настройки добавлен режим псевдо-стерефонии в наушниках (не активен в DIGI модах). Для Wolf-Lite реализована упрощённая версия
+STM32: Добавлена возможность указать, какой отчёт о используемой мощности передатчика отправит WSPR маяк, Tnx ES1RCG
+STM32: Wolf-7Inch: Долгое нажатие на функциональные клавиши XIT, RIT отклонение сбрасывается до нуля, Tnx SP7MFR
+STM32: Исправление ошибки с сохранением частоты на бенде, Tnx SP7MFR
+STM32: После отключения от WiFi точки удаляются имя сети и IP из меню, Tnx And
+STM32: Исправлено воспроизведение файлов в эфир при выключенной SSB AGC, Tnx UZ5DM
+STM32: Добавлена функция "CW Mode",  позволяющая выбрать тип боковой полосы LSB/USB при прослушивании телеграфа
+STM32: Добавлена функция "CW Stereo", позволяющая разделить полосу пропускания телеграфа по каналам наушников (аудио-панорама)
+STM32: На бендмапе отмечается 5 последних частот, на которых пользователь провёл более 30 секунд времени (для упрощения отслеживания сработанных станций)

----Version 11.1.1----
+STM32: Wolf-Lite: Исправлена ошибка в SelfTest "RF Gain ERROR", Tnx RA3RBE
+STM32: Добавлен выход из FT8 по функциональной кнопке, Tnx R3WCU
+STM32: Wolf-2: Для УКВ платы обновлено ПЧ по умолчанию, проведено ускорение расчёта частоты гетеродина
+STM32: Wolf-Lite: Добавлен расчет контрольной суммы EEPROM, BKPSRAM и WiFi для Lite, Tnx RA3RBE
+STM32: Wolf-KT100S: Обновление конфигурации ФНЧ
+STM32: Исправление мелких ошибок в CAT, WiFi, защитах

----Version 11.1.0----
+FPGA: Улучшено качество сигнала на передачу, Tnx R6DLC
+FPGA: Wolf-Mini: EP4CE10 не вмещает в себя последние изменения, реализована урезанная версия, рекомендуется обновление до CE22
+STM32: Увеличена максимальная цифровая раскачка для полной реализации ДД ЦАП, обновлены калибровки по умолчанию, требуется перекалибровка RF Gain.
+STM32: В самопроверку добавлен пункт "RF Gain", показывает ошибку, если в калибровках по основным диапазонам установлены RF Gain <30 или >90, что ухудшает ДД ЦАП из-за снижения разрядности. Рекомендуется гасить мощность снижая усиление в драйвере УМ.
+STM32: Исправление включения 1.25м бенда, Tnx RA3RBE
+STM32: Улучшена отрисовка стрелок на аналоговом с-метре, улучшено сглаживание и устранены моргания
+STM32: RTTY InvertBits по умолчанию установлен в YES, Tnx UZ5DM
+STM32: Обновлены системные библиотеки
+STM32: Доработки пагинации файл-менеджера
+STM32: Добавлен вывод спектра в LCD Test, Tnx RA3RBE
+STM32: Wolf-Lite: Улучшена цветопередача за счет цветовой коррекции,  Tnx RA3RBE
+STM32: Wolf-Lite: Улучшен протокол работы с ESP32, устранение обрывов связи с WiFi,  Tnx RA3RBE
+STM32: Wolf-Lite: Начиная в версии 11.1 и дальше для работы с модулем WiFi требуется прошивка ESP32 vers 2.0, (см. DropBox)  Tnx RA3RBE
+STM32: Расширены границы регулировок MIC Gain и DotToDash Rate
+STM32: Тип Iambic Type по умолчанию установлен в режим "B"
+STM32: Wolf-Mini: В меню RX добавлено управление выходом SPKOUT кодека NAU8822, Tnx R7KBI
+STM32: Исправлено отображение даты при расчёте прохождений спутников, Tnx UA9YHI
+STM32: Для меню QTH Lon/Lat/Alt по умолчанию выбрана строчная раскладка клавиатуры, Tnx UA9YHI
+STM32: В DIGI модах разрешено включение Noise Blanker
+STM32: Wolf-Mini: На кнопку тангенты "*" выведена функция запуска передачи CQ Message в эфир, Tnx R3TKS
+STM32: В окне эквалайзера теперь отображается тип эквалайзера из меню, а не текущая мода
+STM32: Оптимизация шины обмена с FPGA
+STM32: Для моды CW выделен отдельный RX эквалайзер
+STM32: Wolf-7Inch: Увеличено усреднение показателя dBm, Tnx R1BLT

----Version 11.0.1----
+HARDW: В GitHub добавлена инструкция по удаленному управлению трансивером через сеть
+STM32: Перемещены пункты в меню TX, чтобы индикация SWR была на том же экране, что и тюнер, Tnx UT8EU

----Version 11.0.0----
+HARDW: Опубликована техническая информация по проекту Wolf-DK102 (ультратонкий, 7 дюймовый), Автор BH7FFB
+STM32: Исправлены периодические щелчки по приёму, Tnx UZ5DM
+STM32: Улучшения алгоритмов Digital Pre-Distortion (требует дополнительного тестирования и спрятана в настраиваемые функциональные кнопки)
+STM32: Уменьшены переходные процессы на FFT при переходе RX/TX c настройкой FFT Averaging > 10, Tnx UZ5DM
+STM32: Параметр TX Settings -> ADC Shutdown теперь по умолчанию NO, это уменьшает проблемы при переходе RX/TX (включайте обратно при работе от аккумулятора и сохранении энергии)
+STM32: Разрешена работа Notch-фильтра в SAM модах
+STM32: Улучшена работа FFT Lens при совместном использовании с Free Tune, Tnx SP7MFR
+STM32: Исправления тача XFC в меню, Tnx R3RM, R8QAM
+STM32: В автокалибровку добавлена настройка LHF/HHF КСВ-метра и поддержка встроенного секвенсора
+STM32: Улучшена авто-калибровка на версиях с малой мощностью, Tnx RX3PX
+STM32: В настраиваемые функциональные кнопки добавлено управление FFT Lens и окно EQ, Tnx SP7MFR
+STM32: Добавлена регулировка выбранной полосы в окне EQ с помощью основного энкодера, Tnx R4HID
+STM32: Добавлено несколько типов FM-демодуляторов на выбор в меню, Tnx E72W
+STM32: Добавлена возможность выбора, сохранять включение тюнера для каждого бенда независимо или единым выключателем, Tnx SP7MFR
+STM32: Текущий режим вторичного энкодера запоминается для каждой моды отдельно (CW/FM/остальные), Tnx UZ5DM
+STM32: Wolf-Lite: доработки WiFi, Tnx RA3RBE

----Version 10.3.0----
+STM32: Улучшено подавление боковой полосы при передаче (SSB)
+STM32: Более точно отградуирован аналоговый S-метр
+STM32: Улучшено переключение и сохранение истории режимов функционального энкодера, Tnx RA3RBE
+STM32: Wolf-2-Pro: Реализована регулировка подсветки клавиш передней панели
+STM32: Длительное нажатие на SELFHR открывает установку уровня самопрослушивания, Tnx RA9YON
+STM32: Добавлен второй банк настроек эквалайзера RX/TX для возможности быстрого переключения, Tnx E72X, RA9YON
+STM32: Wolf-2: Добавлена функциональная кнопка XFC для оперативного переключения VFO A/B на время нажатия кнопки, Tnx R3RM
+STM32: В 7 дюймовых версиях добавлено окно управления эквалайзером с тачпад управлением
+STM32: Параметры смещения частоты в репитерном режиме разделены по диапазонам 10м/2м/1.25м/70см+, Tnx E72X
+STM32: Значение IF Gain теперь не влияет на уровни сырого USB-IQ потока
+STM32: Настройка TX AGC разделена на модам AM+FM и SSB
+STM32: Wolf-Mini: в интерфейсе выведена температура CPU, Tnx DL1EGQ
+STM32: Wolf-Mini: добавлена индикация записи эфира на SD карту, Tnx DL1EGQ
+STM32: Wolf-Mini: улучшено отображение файл-менеджера
+STM32: В Loop моде теперь можно настраивать телеграфный ключ без выхода на передачу, а не только проверять микрофон, Tnx Vladimir
+STM32: Wolf-Lite: Добавлены функции WiFi - время, DX и WOLF кластеры (с модулем ESP32-C3)
+STM32: Добавлена возможность настройки полосы обзора спектра для DIGI мод отдельно от SSB, Tnx UZ5DM
+STM32: Исправление ошибок, Tnx UZ5DM, SP7MFR, R7KBI, BD6MM, RA9YON, R1BFJ

----Version 10.2.2----
+STM32: Доработка анти-алиазинга экранных шрифтов
+STM32: Добавлены значения по умолчанию для эквалайзера TX
+STM32: Исправление различных ошибок

----Version 10.2.0----
+STM32: Добавлен CW Trainer. UA3REO/RA3RBE (in collaboration)
+STM32: Добавлены CAT TS-2000 команды BU (BND UP), BD (BND DWN), IC (CPU ID), GC (AGС control), Tnx RA3RBE, UZ5DM
+STM32: Добавлены CAT TS-2000 команды TX0, TX1, RA, SM, RM1, RM4, RG(чтение), AG(чтение), Tnx UZ5DM
+STM32: Исправления в README файлах, Tnx rmdlv
+STM32: Переработан механизм обмена данными с FPGA, снижена нагрузка на CPU
+STM32: Запрет включения Double + 384кГц полосы одновременно
+STM32: Остановка поддержки 3'5 версий трансивера и проекта Wolf-X1
+STM32: Для Wolf-1 ВЧ плата по умолчанию выставлена на тип RU4PN
+STM32: Предел регулировки SSB LPF фильтра увеличен до 9кГц (в меню), Tnx YC1SEI
+STM32: При выходе из FT8 не возвращаемся в меню, а закрываем его полностью, Tnx RA6UAC
+STM32: В меню "System info" отображается аппаратная версия трансивера, Tnx DJ0AK
+STM32: Wolf-2: Короткое нажатие на энкодер "Power" устанавливает мощность на 100%, длительное - на 0%
+STM32: Разделены настройки включения обдува при повышении температуры УМ и STM32
+STM32: Добавлена регулировка добротности фильтра Гаусса (CW), Tnx R1BLT
+STM32: Параметры SampleRate (полоса обзора) сохраняются по бендам, Tnx R6DLC
+STM32: Включение тюнера сохраняется по бендам, Tnx UZ5DM
+STM32: Звук самоконтроля дополнительно отправляется в USB, Tnx UA3RF
+STM32: Скорректирована скорость работы электронного ключа, Tnx UZ5DM
+STM32: Доработка логики работы кнопки Backspace на экранной клавиатуре
+STM32: Настройки эквалайзера вынесены в отдельное меню
+STM32: W-Lite: Добавление "FUNC" в меню второго енкодера, Tnx RA3RBE
+STM32: Эквалайзеры переделаны на 10 полосные, изменились частоты регулировки, Tnx YC1SEI
+STM32: При нажатии на Tune при отключенной выходной мощности (0%), включается перебор тюнера (ATU) исходя из громкости приёма, Tnx R6WAM
+STM32: Исправление ошибок, Tnx R4HID, R8OAE, UT8EU

----Version 10.1.0----
+STM32: Доработки функции TOT для DIGI/CAT PTT/COM PTT, Tnx SP7MFR, R6DWD
+STM32: Исправление проблемы при переключении бенда в SPLIT, Tnx SP7MFR
+STM32: WF-100D: В режиме УКВ + "Transv only TX" активен УКВ усилитель независимо от частоты ПЧ (не проверено), Tnx R6DLC
+STM32: Разделена регулировка громкости самоконтроля Голосовых и DIGI мод, Tnx SP7MFR
+STM32: Пункты сброса в калибровках спрятаны в подменю, Tnx R6DLC
+STM32: В меню калибровок добавлена функция сброса сохраненных значений настройки авто-тюнера
+STM32: В настраиваемые функциональные кнопки добавлена возможность включения самоконтроля SSB, Tnx SP7MFR
+STM32: Обновлен цвет стрелки КСВ на шкале R3TKS, Tnx UZ5DM
+STM32: Добавлены CAT TS-2000 команды KS и KY для установки WPM ключа и ключевания сообщений по CAT, Tnx RU4PN
+STM32: Добавлены CAT TS-2000 команды FS(Fast Step), LK(Lock), SC(Sсan), AN(Antenna), PC(RF Power), AC(Tune), MT(Mute), Tnx RA3RBE
+STM32: Добавлена калибровка компенсации LNA по КВ бендам (LHF/MHF/HHF), Tnx R1BLT
+STM32: Добавлена возможность включения DSP обработки тракта микрофона: Downward Expander, Upward/Downward Compressor, Limiter, Noise Gate, Tnx E72X
+STM32: Цвета маркеров на водопаде привязаны к выбранной теме оформления, Tnx E72X
+STM32: Небольшие доработки качества звучания CESSB, также параметр CESSB Compress теперь может принимать отрицательные значения
+STM32: Увеличена глубина модуляции "по умолчанию" для AM моды
+STM32: На 3дБ снижена базовая прибавка к усилению ПЧ в CW, Tnx SP7MFR
+STM32: Wolf-1/KT-100S: При зажатой F2 трансивер входит в DFU при включении
+STM32: Убраны раздельные регулировки SampleRate / Zoom, теперь просто единые кнопки регулировки ширины спектра FFT- FFT+ от 3кГц до 384кГц
+STM32: Добавлена мода DSB, использует настройки от моды AM, но не передаёт несущую
+STM32: Объединены настройки Auto CW Mode и CW In SSB в единый пункт
+STM32: Исправлена ошибка при большом количестве спотов кластера на спектре, Tnx R8OAE
+STM32: Wolf-2: Расширен список поддерживаемых TCXO генераторов УКВ платы
+STM32: Wolf-Mini: Поддержка Mute линии для УНЧ, Tnx R7KBI

----Version 10.0.0----
+FPGA: Измерения тракта и борьба с внеполосными излучениями, Tnx R6WAM, UR8IP, R1BLT
+STM32: Если позволяет обзор, то в режиме Split DX и FreeTune полоса передачи будет отрисована в том же месте, где маркер, Tnx UR7CQ
+STM32: Mic Noise Gate теперь может работать с отключенным TX AGC
+STM32: Доработки обработки RDS/SFM
+STM32: Добавлена настройка "TOT", защищающая от длительной передачи, Tnx SP7MFR
+STM32: Добавлена калибровка "SWR Protector", выбор режима защиты усилителя по КСВ: выключена, сброс мощности, отключение передачи
+STM32: Wolf-Mini: Доработан код инициализации кодека NAU8822
+STM32: Реализована многоуровневого подменю с корректным возвратом в предыдущее меню
+STM32: Меню калибровок разделено на несколько подменю, Tnx UT8EU
+STM32: Wolf-2/100D/7Inch: Добавлена калибровка "Transv only TX", при которой трансвертер используется только на передачу (пока не проверено), Tnx R6DLC
+STM32: Добавлена поддержка CAT-команды "FR", Tnx SP3JDZ
+STM32: В сервис "Self Test" добавлена проверка на межконтактное замыкание линий АЦП (красный цвет - не проверено\нет сигнала, желтый - есть сигнал, но пока не прошла проверка на замыкание с соседями, зеленый - всё ок)
+STM32: Увеличен размер EP0 пакетов USB-CDC до 64 байт (STM32H743 версии), Tnx UA1ARN
+STM32: Добавлена настройка "S-Meter style" для выбора внешнего вида аналогового S-метра, а также новый стиль, Tnx R3TKS
+STM32: Калибровка DAC Driver Mode теперь по умолчанию "0" (50% тока покоя драйвера ЦАП)
+STM32: Добавлена калибровка "DAC Interpolation", позволяющая отключить интерполяцию в ЦАП для КВ диапазона
+STM32: Добавлена настройка "SelfHear SSB", позволяющая вывести на кодек сформированный сигнал TX в ходе работы в SSB/AM моде (аналогично моде Loopback)
+STM32: Исправление проблем со звуком в WFM при большом количестве отладочной информации в COM-порте, Tnx SP7MFR
+STM32: Исправление проблемы с переходом на частоту через окно "MEM" в режиме Free Tune, Tnx UZ5DM
+STM32: Добавлена калибровка "Max Current, Amp" - защита по току, отключает передачу по достижению порога (на версиях где есть датчик INA226)
+STM32: CESSB выключен по умолчанию
+STM32: Добавлены настраиваемые функциональные кнопки "Filt", которые позволяют оперативно сохранять и загружать предустановленные настройки фильтров, Tnx R3TJL

----Version 9.9.0----
+STM32: Реализация поддержки трансивера WF-110D, Автор R6WAM
+STM32: Исправлено отображение даты в Sat Calc pass
+STM32: Доработки АРУ (рекомендуется сбросить настройки на по-умолчанию), Tnx RU4PN
+STM32: Удален WiFi CAT Server, AGC Spectral
+STM32: Переименованы USB аудио устройства Audio/IQ (требуется удалить старые устройства Windows для обновления), Tnx UT8EU
+STM32: Доработки CW декодера, Автор RA3RBE
+STM32: Если WFM RDS передает данные о поддержке Stereo FM режима, то выводится соответствующая надпись
+STM32: Добавлено окно выбора антенны RX/TX
+STM32: Добавлена настраиваемая функциональная кнопка "Balance", открывающая настройку "A/B Balance", Tnx SP7MFR
+STM32: Добавлена поддержка CAT команды "PB" для передачи\остановки CQ Message, Tnx RU3RQ
+STM32: Добавлена настраиваемая функциональная кнопка "ATU RST", сбрасывающая параметры ATU для текущей частоты, Tnx R7KBI, SP7MFR
+STM32: Добавлен дополнительный проход ATU в случае, если антенна не согласовалась в первом
+STM32: Добавлена калибровка "SEC COM Mode" для выбора режима работы вторичного COM-порта (отладка или второй CAT порт)
+STM32: Для калибровки "FAN Medium PWM" разрешено значение в 100% (отключает ШИМ если идут помехи на НЧ)
+STM32: Добавлена поддержка 1.25м бенда и трансвертеров (не рекомендуется импорт старых настроек\калибровок из-за смещения сетки бендов)
+STM32: Отображение статуса, если WiFi занят другим процессом во время открытия сервисов
+STM32: W-Mini: уменьшено усиление в режиме Mic Boost, Tnx R7KBI
+STM32: W-Mini: Добавлена настраиваемая функциональная кнопка "PTT", переводящая трансивер на передачу без использования тангенты, Tnx R7KBI
+STM32: Исправление бага с тачпадом в меню "Set Clock Time", Tnx awesome possum
+STM32: Калибровка КСВ метра HF поделена на 3 поддиапазона (LHF 160/80, MHF 40/30/20/17, HHF 15/12/10) по аналогии с S-метром, Tnx UT8EU
+STM32: Wolf-2: Если в настройках отключены все УКВ беды, трансвертеры и УКВ плата, то кнопка лицевой панели "VHF" переходит на 6м диапазон, Tnx UR7CQ

----Version 9.8.0----
+STM32: Добавлена настройка "DRV Shutdown", позволяющая (не)отключать драйвер ЦАП по время приёма, устраняет всплеск мощности при переходе на передачу
+STM32: Исправлено сохранение моды по бендам, Tnx SP7MFR
+STM32: Переход на частоту из кластера меняет моду даже с выключенным BandMap, Tnx SP7MFR
+STM32: Защита по КСВ не отключается в режиме Tune для УКВ бендов
+STM32: Указана поддержка дисплеев ILI9488, Tnx RX3QVC
+STM32: Значок "REC" моргает во время записи, Tnx R2AJI
+STM32: Уменьшено моргание даты во время ошибок, Tnx R2AJI
+STM32: Увеличена частота PLL RA8875
+STM32: В режиме FreeTune + DX-Split полосы RX и TX стараются уместиться на экране, сдвигая центр спектра, Tnx SP7MFR
+STM32: Вернул калибровку "ATU Averaging" для снижения скорости перебора тюнера, Tnx RC3RF
+STM32: Добавлена возможность точной коррекции частоты TCXO генератора УКВ платы
+STM32: Добавлена настройка "CW Samplerate" для выбора частоты дискретизации спектра для CW моды, Tnx Mr Wheatmushi
+STM32: Добавлен сервис отображения карты foF2 частот, Tnx EA7HOG
+STM32: Добавлена возможность расчёта времени предстоящих прохождений выбранного спутника
+STM32: Для "SAT Mode" добавлена возможность отслеживания положения солнца и луны
+STM32: В режиме "SAT Mode" выводится расчетный доплеровский сдвиг (кроме луны)
+STM32: Wolf-2: Улучшена стабильность установки частоты на новой УКВ плате + теперь она включена в калибровках по умолчанию
+STM32: Добавлена функция "Auto Doppler", автоматически смещающая частоту трансивера исходя из расcчитанного эффекта Доплера
+STM32: Добавлена инструкция по сопряжению TRX Wolf и CW Skimmer + DXLog

----Version 9.7.0----
+HARDW: Wolf-2: Релиз новой УКВ платы 85-2700МГц, Tnx R7KBI, RU4PN
+STM32: Wolf-2: Доработка поддержки новой УКВ платы, обновлено описание в Readme файле
+STM32: W-Lite, W-Mini: Включение полной клавиатуры тангенты.  Автор RA3RBE 
+STM32: W-X1: Включение полной клавиатуры тангенты. Автор RA3RBE. Tnx RV9CT
+STM32: W-X1: По умолчанию режим второго энкодера - регулировка громкости. Автор RA3RBE
+STM32: Wolf-2: Добавлена поддержка внешнего секвенсора для управления МШУ\УМ. Сигнал Ext-Tune в этом режиме активирует секвенсор. Активируется калибровкой "Sequencer support"
+STM32: Для Wolf-1 и Wolf-2 отключена возможность прошивки STM32 с SD карты, чтобы позволить дальше увеличивать функционал и ресурсы прошивки до размера в 2Мб
+STM32: W-Mini: Исправление ошибки в инициализации кодека, включен правый канал УНЧ. Включена подсветка клавиши NOTCH в карусели, увеличена скорость перестройки валкодером по-умолчанию. Автор RA3RBE
+STM32: W-Lite: Исправление ошибки в выводе цветовых схем.  Автор RA3RBE 
+STM32: Калибровка S-метра разделена на Low-HF, Mid-HF, High-HF, 6M, FM, 2M, 70cm, 23cm бенды
+STM32: Добавлена калибровка КСВ метра 70см,23см,6см,3см,1.2см
+STM32: W-Mini: Доработка меню, чтобы выбор Bluetooth срабатывал сразу, без перезагрузки трансивера. Автор RA3RBE
+STM32: Добавлена поддержка тангенты Kenwood MC-43S
+STM32: W-Mini: Вывод на экран цифровой информации в SWR Analyser. Автор RA3RBE
+STM32: Настройка TX Settings -> ADC Shutdown отключает АЦП во время передачи (по умолчанию), если не отключать то уменьшаются щелчки и перегрузка АРУ при переходе RX/TX
+STM32: Настройка CW Settings -> Key timeout теперь регулируется от нулевого значения, менее 20мс и без отключенного ADC Shutdown использовать не рекомендуется. Tnx R7GP
+STM32: Самоконтроль проигрываемого CQ Message в моде NFM выводится в кодек до модулятора\обработки, Tnx R3TJL
+STM32: В настраиваемые функциональные кнопки добавлен вариант "Band SWR", при нажатии вызывающий соответствующий сервис из меню
+STM32: Подменю Services -> DX/Wolf Cluster теперь позволяет переходить к выбранному в списке споту. Автор RA3RBE, Tnx SP7SP, R7KBI
+STM32: Сохранение скриншотов теперь корректно работает при открытых окнах (бенда, памяти и т.п.), Tnx R2AJI
+STM32: Исправлено отображение спотов из Wolf-кластера при включенном отображении азимута к споту
+STM32: Исправлена работа WFM на СВЧ бендах
+STM32: Добавлен адаптивный NFM фильтр, который автоматически регулирует полосу относительно силы принимаемого сигнала (УКВ), Tnx R6DLC
+STM32: Добавлен 9кГц шаг для АМ моды, Tnx R1BLT

----Version 9.6.0----
+HARDW: В github добавлен чертеж радиатора на всю материнскую плату TRX Wolf. Он предназначен для станка с ЧПУ. Конструктор чертежа Максим Мельников, Tnx RX3PX
+STM32: Доработки CAT подсистемы, Автор DD8BA
+STM32: W-Lite, W-Mini: Добавлена индикация аварийной батарейки на экран. Автор RA3RBE
+STM32: W-Mini: По умолчанию режим второго энкодера - регулировка громкости. Автор RA3RBE
+STM32: W-Mini: При нажатии на второй энкодер включается режим MUTE. Автор RA3RBE
+STM32: Исправлена работа MIC Noise Gate, Tnx R6DLC
+STM32: Во время передачи на индикаторе АРУ (на спектре) отображается текущий уровень микрофонного сигнала относительно максимального уровня (с учётом MIC Gain / Boost)
+STM32: Стрелка аналогового S-метра в CW моде возвращается медленней, чем поднимается, Tnx UR7CQ
+STM32: Исправления в работе FFT Lens, Tnx Sergo K, SP7MFR
+STM32: Упростил алгоритм работы меню записи CQ сообщений, Tnx Vitaliy, R2DUS
+STM32: В меню пропадает пункт OTA, если он выключен в калибровках, Tnx R3TJL
+STM32: Увеличена точность подстройки ATU
+STM32: Tune в режиме одиночной несущей больше не ограничен уровнем текущей мощности, ограничен только калибровкой "MAX Power in TUNE" (кроме 0% мощности - это полный запрет), Tnx SP7MFR
+STM32: W-Mini: Исправлена прошивка STM32 с SD карты, Tnx RA3RBE, RV9CT
+STM32: В режимы генератора сигналов (Tune Type) добавлен двухтональный режим 0.7кГц + 3.8кГц, и однотональный 1кГц
+STM32: Скорректирована работа с-метра а модах AM/FM, Tnx R1BLT
+STM32: Исправлено сохранение настройки "ATU Mem step, kHz" на SD карту, Tnx SP7MFR
+STM32: Исправление отображения низких мощностей TX на аналоговом с-метре, Tnx UZ5DM
+STM32: Нижний ряд кнопок на 7 дюймовых версиях увеличен на 10 пикселей в высоту, Tnx Евгений
+STM32: При ответе на FT8 CQ вызов проигрывается звуковой сигнал, Tnx UN7LAS

----Version 9.5.0----
+HARDW: W-Lite: Выложены новые 3D модели лицевой панели. Автор RA3RBE, UA3RAW
+STM32: W-Lite: Откорректированы значения матрицы напряжений тангенты. Автор RA3RBE, Tnx UN7FHS
+STM32: Разнос по умолчанию для DX Split в CW моде установлен в 1кГц, Tnx SP7MFR
+STM32: Исправление свайпа по водопаду в режиме DX Split и отключенном Free Tune, Tnx SP7MFR
+STM32: Для Wolf-2 и ВЧ платы RU4PN добавлена возможность переключения 6м фильтра под другой бенд: 30м, 17м, 12м, CB, Tnx RX3PX
+STM32: Добавлена автоматическая синхронизация моды и частоты трансивера с онлайн-журналом allqso.ru (если включен в настройках), Tnx RU4PN
+STM32: Доработки S-метра в моде AM, Tnx R1BLT
+STM32: Исправление проблемы с пропаданием звука в WFM, Tnx Adi
+STM32: AutoGainer отключает PGA при больших уровнях сигнала, Tnx UR7CQ
+STM32: Wolf-2: Энкодер регулировки полосы фильтра переключается между LPF/HPF по нажатию, а не удержанием
+STM32: Wolf-2: Добавлен выбор частоты TCXO генератора УКВ платы
+STM32: Доработка АРУ передающего тракта, Tnx RU4PN
+STM32: W-Mini: Добавлена матричная обработка клавиш тангенты. Автор RA3RBE
+STM32: Настройка "MAX PWR on Meter" разделена на КВ и УКВ, Tnx RV6AMF
+STM32: Кнопка "Files" выходит из меню файлов при повторном нажатии, Tnx SP7MFR
+STM32: Доработки автотюнера, Tnx RU4PN, R7KBI
+STM32: Смена частот двухтонального генератора на 700 + 1700, Tnx RX3PX, R1BLT, Dire Wolf
+STM32: Добавлен режим генератора белого шума, переключение режимов Tune происходит настройкой параметра "Tune Type", Tnx Dire Wolf
+STM32: Исправлена работы функции "CW In SSB" совместно с "SPLIT", Tnx SP7MFR

----Version 9.4.0----
+HARDW: Стандартизирована распиновка разъёма External для всех версий TRX, схема подключения находится в файле Stuff/Manuals/External.png. Автор R3TJL
+STM32: Добавлена регулировка громкости самопрослушивания в CW. Автор RA3RBE, Tnx SP7MFR
+STM32: Удалена опция отключения самопрослушивания в связи с возможностью плавной регулировки громкости.  Автор RA3RBE
+STM32: Изменен порядок регулировок в меню CW. Автор RA3RBE
+STM32: Исправление вывода даты в меню настроек. Автор RA3RBE
+STM32: Добавлено выключение режима MUTE вращение регулятора громкости. Выключение этого режима клавишей не отменяется. Автор RA3RBE, Tnx UR7CQ
+STM32: Wolf-2: Добавлена поддержка новой экспериментальной УКВ платы 85-2700МГц (Включается калибровкой VHF Mixer Board, ПЧ выбирается через VHF Mixer IF)
+STM32: Вернул свайп по водопаду в режиме Center, но инвертировал в Free Tune, Tnx R3TJL
+STM32: Wolf-2: Кнопка VHF переключает активные УКВ бенды, а не только 2м, Tnx Adi
+STM32: Исправлена проблема с зашкаливанием S-метра, Tnx SP7MFR
+STM32: W-Lite: Добавлена матричная обработка клавиш тангенты. Автор RA3RBE
+STM32: В режиме Double всегда отображается второй VFO на водопаде (без необходимости активации Show Sec VFO), Tnx SP7MFR
+STM32: На спектре отображаются границы Manual Notch фильтра, Tnx EA7HOG
+STM32: Обновлён шаг по умолчанию для WFM
+STM32: Добавлена калибровка "FAN Motherboard", включающая вентилятор не только на превышение температуры RF-платы, но и на температуру STM32, Tnx SP7MFR
+STM32: Настройка "Bottom navi buttons" теперь выбирает позицию расположения навигационных кнопок (выкл\центр\по краям), Tnx R3TJL
+STM32: Новая настройка "SPLIT type", в режиме DX - идёт управление частотой DX, в режиме CrossBand синхронно для двух VFO, для Free меняется только частота RX, Tnx UR7CQ
+STM32: Исправлена работа CW макросов при выключенном CW Keyer, Tnx SP7MFR
+STM32: Добавлена кнопка выхода в FT8 декодере, Tnx EA5GSA
+STM32: W-Lite: Добавлен антидребезг в клавиши тангенты.  Автор RA3RBE

----Version 9.3.1----
+HARDW: W-Lite: Исправление типов диодов в схеме MotherBoard. Автор R7KBI
+STM32: W-Lite: Исправлена регулировка скорости водопада. Автор RA3RBE
+STM32: Для CW моды добавил дополнительное предусиление в ПЧ, Tnx RU4PN
+STM32: Обдув в режиме Full теперь работает до установленной температуры, а не до Medium stop, Tnx RU4PN
+STM32: Частота по умолчанию для 2м бенда установлена в 145.500, Tnx R7KBI
+STM32: При активном Free Tune, переключение Zoom/Samples перемещает спектр в центр полосы приёма, Tnx UR7CQ
+STM32: W-Mini: добавлены дополнительные настраиваемые функциональные кнопки (FT8/VOX/...), Tnx R6DLC
+STM32: Исправлена работа функциональной кнопки MEMORY, Tnx SP7MFR
+STM32: Добавлена настройка "Center After Idle", центрирующая спектр Free Tune во время бездействия более 20 секунд, Tnx R7KBI
+STM32: Изменение положения навигационных кнопок на 8-ми кнопочной версии, Tnx SP7MFR
+STM32: В сервис Self Test добавлена палитра для проверки подключения шины LCD панелей
+STM32: Устранение различных ошибок
+STM32: W-Lite: Добавлена настройка экрана (Mirror) при первом старте программы. Автор RA3RBE
+STM32: Обновлены системные библиотеки

----Version 9.3.0----
+HARDW: Wolf-Motherboard-rev34: Исправления в посадочных местах, переход на USB Type-C, разъём для подключения I2C периферии и прочие исправления. Автор R7KBI
+HARDW: Wolf-Front-Unit-7-rev6: Исправления в посадочных местах. Автор R7KBI
+OTA: Сервер обновлений и сервисов переведён в Нидерланды
+STM32: W-Mini: Добавлена поддержка УКВ платы, Tnx R7KBI
+STM32: W-Mini: Автоматический выбор соответствующей функциональной страницы кнопок при активации режима MEMO / моды CW, Tnx R7KBI
+STM32: Добавлена регулировка ручного Notch-фильтра, Tnx EA7HOG
+STM32: Добавлена поддержка бенда 630м и трансвертеров 1.2см
+STM32: Вывод текущей даты на 7 дюймовых дисплеях, Tnx R1BLT
+STM32: Добавлена "запятая" в окно ручного ввода частоты, Tnx R4HID
+STM32: Устранение ошибок, Tnx R1BLT
+STM32: W-Lite: Включено декодирование CW сигнала
+STM32: W-Lite: Включены настройки трансвертеров
+STM32: При активации SPLIT принудительно отображается второй VFO на водопаде, Tnx UR7CQ, UT8EU
+STM32: При активации SPLIT свайп\тап по водопаду перемещает вторичный VFO, а не основной, Tnx UR7CQ
+STM32: Функция MEMORY добавлена в нижний ряд настраиваемых кнопок (через меню), Tnx SP7MFR

----Version 9.2.1----
+STM32: Устранение ошибок, Tnx Martin AD, SP7MFR

----Version 9.2.0----
+HARDW: Wolf-2: Обновлена плата УКВ, Автор RU4PN
+HARDW: W-Lite: Исправлена шелкография у стабилизаторов на материнской плате, Tnx Андрей Сергеев
+STM32: Долгое нажатие на водопад переключает режимы Free Tune / Center Tune. Автор BD6MM
+STM32: Улучшена поддержка некоторых видов SD карт, Tnx UN7LAS
+STM32: Обновлены параметры "Repeater offset, kHz" по умолчанию, Tnx SP7MFR
+STM32: Уменьшен уровень передачи записанного WAV файла, Tnx UZ5DM
+STM32: Доработки процесса OTA и прошивки с SD, Tnx RV9CT, SQ7BCN
+STM32: FFT Automatic теперь принимает 3 значения: Full - автоматический выбор верхней и нижней границ, Half - авто нижний и ручной верхний, No - ручное выставление диапазона уровней спектра. (Не забывайте выбрать нужный FFT Scale Type, чтобы диапазон уместился на экране). Tnx R1BLT
+STM32: ENC2 теперь корректно работает на AM/NFM/WFM модах, обновлены настройки по умолчанию, Tnx R3TKS
+STM32: Прописаны моды по умолчанию за границами бендов, Tnx RU4PN
+STM32: W-Lite: Добавлено управление 6м ФНЧ, Tnx UN7FHS
+STM32: Для 9-ти кнопочных версий (WF-100D / Wolf-2) перемещены кнопки пролистывания к центральной, чтобы надписи соответствовали расположению кнопок, Tnx SP7MFR
+STM32: Устранение ошибок, Tnx R4FZ, SP7MFR, R4HID, RU4PN

----Version 9.1.0----
+HARDW: Motherboard: Обновлён номинал резистора R10 в обвязке аудио-кодека, выбирается по необходимому усилению микрофона, Tnx R3TKS
+STM32: W-Mini: Перестроен интерфейс главного экрана. Иконки режимов работы выстроены в один ряд, увеличено место под основную частоту. Автор RA3RBE
+STM32: W-Mini: Ниже основной частоты выведена частота второго VFO. Автор RA3RBE
+STM32: W-Mini: Добавлен режим каналов. В меню установлены 20 каналов, можно менять им имена, не более 6 букв. Автор RA3RBE
+STM32: W-Mini: Изменен режим SCAN. В режиме MEMO сканирование идет по заполненным каналам памяти. Автор RA3RBE
+STM32: W-Mini: Добавлена иконка работы WiFi. Автор RA3RBE
+STM32: W-Mini: Множество мелких изменений. Автор RA3RBE
+STM32: W-Lite: Открыта регулировка RF GAIN на 6 м. Автор RA3RBE
+STM32: Обновлены настройки АРУ по умолчанию (аккуратней с импортом старых), Tnx R3RM, RU4PN
+STM32: Разделены настройки "AGC Gain target" для CW и SSB, Tnx R3RM
+STM32: Добавлена настройка HPF фильтра для DIGI мод, Tnx SP3JDZ
+STM32: Repiter mode теперь сохраняется в память частот, Tnx SP7MFR
+STM32: Переработаны настройки шага перестройки частоты: Для каждой моды выставляется свой базовый шаг, и настраивается множитель для FAST и ENC2 шагов
+STM32: Добавлена возможность настроить индивидуальный шаг перестройки для DIGI мод, Tnx SP7MFR
+STM32: Устранение ошибок, Tnx Serg, R4HID

----Version 9.0.1----
+STM32: Исправлена ошибка "Line length error", Tnx SP7MFR
+STM32: Добавлен кГц разряд при сохранении в память частоты >100МГц, Tnx SP7MFR
+STM32: Добавлена настройка "ATU Mem step, kHz", регулирующая шаг ячеек памяти автотюнера, Tnx R7KBI
+STM32: Исправлена ошибка с полным пропадаем звука в WFM

----Version 9.0.0----
+FPGA: W-Mini: Добавлены прошивки с поддержкой новых плат
+STM32: W-Lite: Добавлены команды САТ интерфейса DN,UP. Автор RA3RBE
+STM32: Начало разработки Satellite Mode (режима работы через спутники). Реализовано скачивание TLE, выбор спутника и отображение элевации\азимута для текущего QTH
+STM32: Исправлена работа команды САТ интерфейса NR, Thanks Кшисек SP7MFR. Автор RA3RBE
+STM32: Оптимизация скорости работы математических функций
+STM32: В режиме FT8 добавлена регулировка мощности основным энкодером при ТХ, Tnx RU4PN
+STM32: Wolf-2: Увеличена точность определения нажатия на кнопки лицевой панели
+STM32: Wolf-2: Добавлена возможность регулировки полосы фильтра в модах DIGI отдельным энкодером
+STM32: Ручной ввод частоты вынесен в отдельную кнопку
+STM32: По умолчанию, при сохранении частоты в память, в название канала пишется частота, далее можно отредактировать имя через меню
+STM32: Wolf-Mini: Добавлена регулировка IF Gain второстепенным энкодером
+STM32: Для каждого канала памяти индивидуально сохраняется настройка CTCSS, Tnx SP7MFR+SP7GRV
+STM32: Вернул старый CW декодер, но с исправлениями проблем, Tnx BD6MM
+STM32: Улучшена защита от проглатывания первой точки в CW, Tnx BD6MM, Serg
+STM32: Переработан код электронного ключа для более точной генерации символов, Tnx BD6MM
+STM32: Добавлена настройка CW "Edges smooth, ms", отвечающая за сглаживание фронтов сигнала
+STM32: При выходе из FT8 декодера трансивер возвращается в предыдущую частоту\моду, Tnx UN7LAS
+STM32: Устранение ошибок, Tnx UZ5DM, R1BLT, EA7HOG, BD6MM

----Version 8.6.4----
+STM32: W-Lite: Добавлены команды САТ интерфейса NB,NR,NT,PA,RA. Автор RA3RBE
+STM32: W-Lite: Расширена область приема АМ вниз до 100кгц, Автор RA3RBE
+STM32: Вернули настройку Encoder2 on fall, настраивающую режим работы ENC2
+STM32: Переделан механизм анти-дребезга энкодера (аккуратнее с импортом старых калибровок ENC2, могут не подойти)
+STM32: Вернул регулировку уровня предусиления перед сжатием сигнала "CESSB Compress"
+STM32: Добавлена поддержка трансвертеров на 144мгц, Tnx R6DLC
+STM32: Устранение ошибок, Tnx R6DLC, RA9N

----Version 8.6.3----
+STM32: W-Lite: Подвинул индикатор полосы пропускания и подпись под ним, Автор RA3RBE
+STM32: Устранение ошибок, Tnx R3RM, R7KBI

----Version 8.6.0----
+STM32: W-Lite: Расширил место под АТТ, Автор RA3RBE
+STM32: W-Lite: Перестановки в карусели, Автор RA3RBE
+STM32: W-Lite: Убрал клавишу IF и вместо нее сделал CESSB, Автор RA3RBE
+STM32: W-Lite: Ограничил перестройку "по кругу" IF GAIN, Автор RA3RBE
+STM32: W-Lite: Вернул в карусель клавиши BAND+, BAND- и NB, Автор RA3RBE
+STM32: W-Lite: на спектре выводятся маркеры сохраненных частот, маяков, смещение от несущей в SAM
+STM32: W-Mini: Добавлен "пиксель" в правой части экрана, отображающий статус WiFi соединения, Tnx R7KBI
+STM32: W-Mini: управление NB выведено в нижнюю карусель функциональных кнопок, Tnx R7KBI
+STM32: Переработка Noise Blanker, Tnx R3RM, RA3RBE
+STM32: Переделаны функции-обработчики сигналов с энкодеров, Tnx RA3RBE
+STM32: Добавлена настройка VCXO Correction для точной подстройки отклонения частоты генератора от эталонного
+STM32: Добавлена поддержка 12.8МГц TCXO, Tnx R1BLT
+STM32: Разделены настройки Mic Gain для AM и FM
+STM32: На спектре выводятся маркеры сохраненных в память частот, Tnx Martin AD
+STM32: Добавлена настройка "FFT BW Position" для регулировки положения отрисовки полосы приёма на FFT\WTF
+STM32: Добавлен режим "Delay" для "FFT BW Position" (отрисовка с временной задержкой), Tnx R1BLT
+STM32: ATU теперь хранит настройки с шагом в 50кГц для каждой антенны, Tnx UT8EU
+STM32: Увеличено количество каналов памяти на 7 дюймовках, Tnx SP7MFR
+STM32: Оптимизация работы CW декодера
+STM32: Добавлена настройка "A/B Balance", регулирующая баланс каналов в режимах двойного приёмника A+B и A&B, Tnx SP7MFR
+STM32: Если режим вторичного энкодера переключен на "MEM", и есть сохранённые частоты в память, то функция SCAN ведётся по ним, Tnx EA7HOG
+STM32: Отключена компрессия в CESSB, оставил только контроль огибающей квадратуры
+STM32: Устранение ошибок, Tnx RV9CT, UN7FHS, SP7MFR, UZ5DM, BD6MM, R7KBI, Adi, Vit

----Version 8.5.1----
+STM32: Устранение ошибок

----Version 8.5.0----
+HARDW: Доработки по плате тюнера Wolf-2, Tnx RU4PN
+STM32: Доработки по работе основного энкодера в системном меню, Tnx RA3RBE
+STM32: Уменьшен шаг калибровки шунта INA226, Tnx R5ZX
+STM32: Добавлена поддержка плат с 4 антенными выходами, Tnx R2AJI
+STM32: Изменён цвет подсветки при отображении второго VFO на спектре, Tnx SP7MFR
+STM32: Добавлены узкополосные SSB фильтры, Tnx SP7MFR
+STM32: Для RTTY декодера устанавливается узкая полоса фильтра, Tnx EA7HOG
+STM32: Добавлено меню редактирования названий каналов памяти, Tnx Martin AD
+STM32: Записи эфира складываются в отдельную директорию Recordings, Tnx Martin AD
+STM32: W-Lite: Убраны квадраты вокруг индикаторов режимов как не несущие полезной нагрузки, только загромождающие экран, Автор RA3RBE
+STM32: W-Lite: Индикаторы распределены равномерно по сторонам экрана визуально разгружая центр экрана, Автор RA3RBE
+STM32: W-Lite: Выведена на экран частота второго VFO, Автор RA3RBE
+STM32: W-Lite: Режимы второго энкодера выделены на экране белой рамочкой, Автор RA3RBE
+STM32: W-Lite: Удалена клавиша "LOCK", блокировка трансивера осуществляется нажатием на кнопку второго энкодера, Автор RA3RBE
+STM32: W-Lite: Скорость работы основного энкодера уменьшается в 10 раз при переходе в меню. Это удобно при наборе имени и прочего, Автор RA3RBE
+STM32: W-Lite: Добавлены 20 ячеек памяти. Можно запоминать в них текущую частоту, читать частоту из памяти и присваивать ее основной частоте, Автор RA3RBE
+STM32: W-Lite: Можно стирать содержимое ячейки, если повторно записать в нее ту же самую частоту, Автор RA3RBE
+STM32: W-Lite: Режим работы с памятью выбирается нажатием на кнопку второго энкодера до появления надписи "Memory". Перебирать каналы можно вращением второго энкодера. Запись в память и извлечение из нее осуществляется кнопками в нижней прокрутке "Mem->Fr" и "Fr->Mem", Автор RA3RBE
+STM32: W-Lite: Добавлен индикатор “SPLIT” в режиме SPLIT, при смене диапазона режим SPLIT выключается, Автор RA3RBE
+STM32: W-Lite: Добавлен индикатор “MUTE” при долгом нажатии на клавишу MUTE, Автор RA3RBE
+STM32: W-Lite: При длительном нажатии на клавишу AGC сделан переход в пункт меню AGC MAX GAIN, Автор RA3RBE
+STM32: W-Lite: Уточнены константы работы с тангентой MH-48, Автор RA3RBE
+STM32: Добавлен режим "CW In SSB", позволяющий на передачу работать телеграфом, возвращаясь обратно в SSB на приём, Tnx SP7MFR
+STM32: Режимы SAM-LSB и SAM-USB вынесены в отдельные моды, Tnx R1BLT
+STM32: Устранение ошибок, Tnx RA3RBE, R3TKS, UR8IP, SP7MFR, Papandupolo, UR5VLC, Виталий

----Version 8.4.2----
+STM32: Устранение ошибок, Tnx R3RM, SP7MFR, RA3RBE, R7KBI

----Version 8.4.0----
+STM32: В калибровках реализован выбор сопротивления шунта цепи INA226 датчика
+STM32: Поддержка нескольких наборов калибровок для импорта\экспорта, Tnx UT8EU
+STM32: AGC Threshold отключается при активном DNR
+STM32: Разнесены настройки Mic Gain для AM/FM и SSB мод, Tnx R6DLC
+STM32: В калибровки добавлена RF-плата "NONE", выбранная по умолчанию, Tnx Vit
+STM32: Добавлена калибровка скорости вентилятора в Medium режиме, Tnx RU4PN
+STM32: Добавлено отображение других пользователей трансивера Волк на спектре через WiFi. Настройка называется "Wolf Cluster", Tnx RV9XG
+STM32: Добавлена калибровка для компенсации аттенюатора на с-метре, Tnx R1BLT
+STM32: Добавлена настройка шага регулировки ручного Notch-фильтра, Tnx EA7HOG
+STM32: Добавлен режим Free Tune, позволяющий перемещать полосу приёма по спектру не меняя центральную частоту самого спектра, Tnx R7KBI
+STM32: При отключении тюнера отображается соответствующая надпись на CN/CN+ темах, Tnx SP7MFR
+STM32: Добавлен выбор режима работы SAM демодулятора: Stereo\LSB\USB, Tnx R1BLT
+STM32: Добавлена возможность переименовывания названий CW макросов на функциональных кнопках, Tnx UZ5DM
+STM32: На CN/CN+ темах выводится текущий WPM в CW моде, Tnx R9IT
+STM32: На CN/CN+ добавлена возможность открыть окно выбора моды VFO-A, Tnx F4EXB
+STM32: Доработки оформления системного меню, Tnx BD6MM
+STM32: Во время записи\воспроизведения файла в файл-менеджере отображается время, Tnx BD6MM
+STM32: Добавлена функция Auto CW, переключающая моду на CW при работе ключом, Tnx SP7MFR
+STM32: Разделены настройки фильтров VFO-A и VFO-B, Tnx SP7MFR
+STM32: Wolf-Lite: Поддержка стилей FFT контур и градиент+контур, Tnx RA3RBE
+STM32: Wolf-Lite: Различные оптимизации, Tnx RA3RBE
+STM32: Устранение ошибок, Tnx RC3RF, R1BLT, R3RM, RA3RBE, Alex, Гена, R7KBI

----Version 8.3.1----
+STM32: Бенды 6м\FM\2м теперь отключаемы через калибровки
+STM32: Wolf-2 Кнопка TX переключает между TX/RX, а не включает TX только во время нажатия, Tnx UT8EU
+STM32: Добавлена настройка "RX AUDIO Mode", позволяет управлять линиями аудио: стерео, только левый канал, только правый, Tnx RU4PN
+STM32: Добавлена калибровка датчика INA226 по напряжению, Tnx RU4PN
+STM32: Добавлена калибровка переворота тачпада по вертикали, Tnx UT8EU
+STM32: Добавлена настройка "AGC Threshold", включающая порог открытия АРУ, Tnx R7KBI
+STM32: Устранение ошибок, Tnx RU4PN, Дмитрий, R5ZX, Alex
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

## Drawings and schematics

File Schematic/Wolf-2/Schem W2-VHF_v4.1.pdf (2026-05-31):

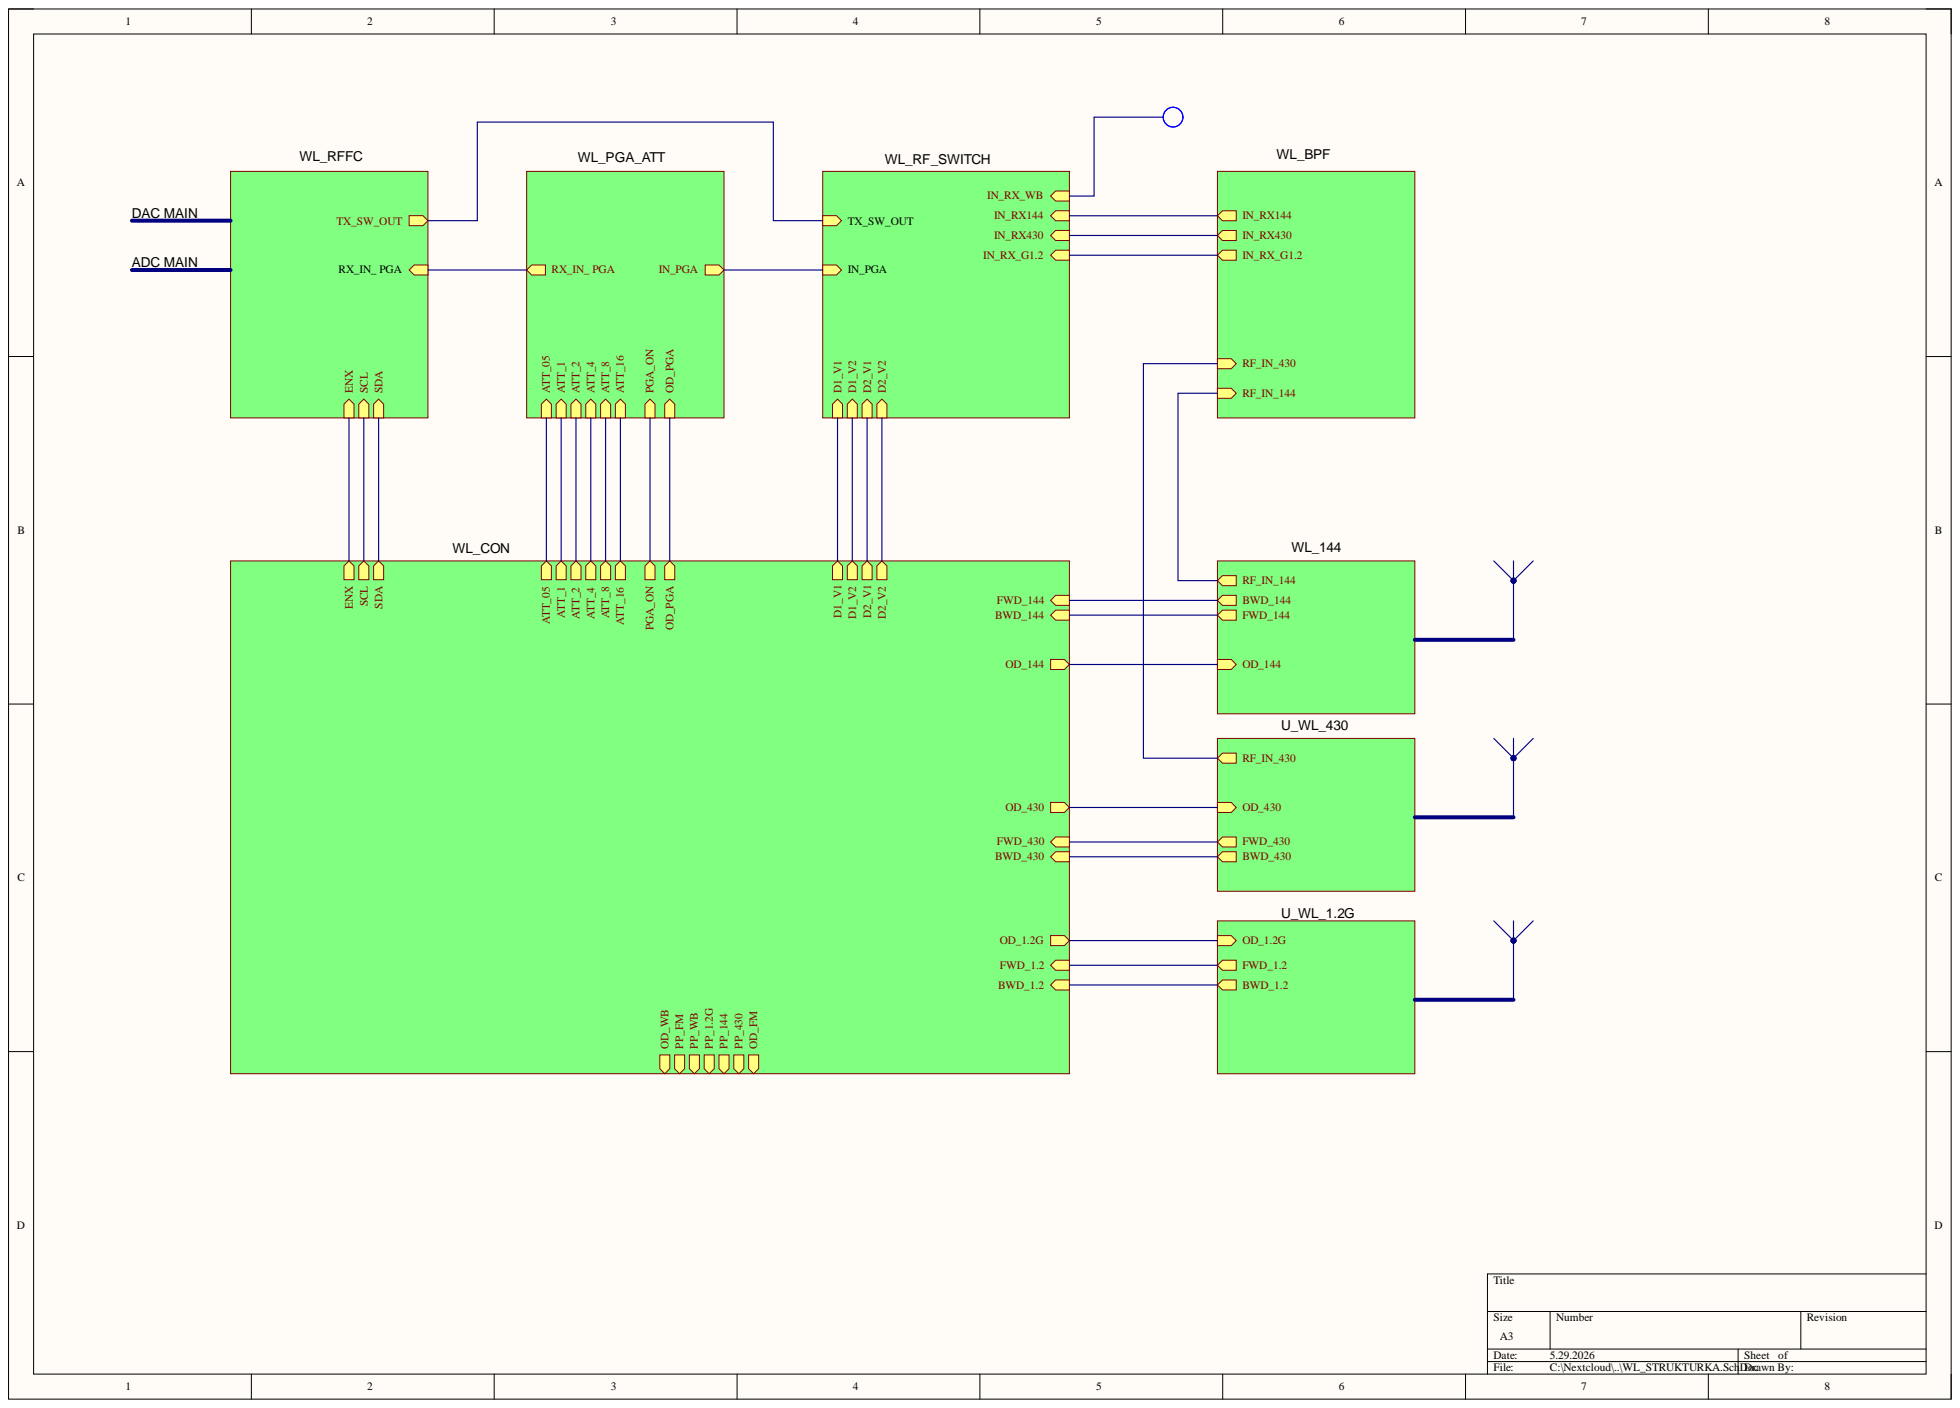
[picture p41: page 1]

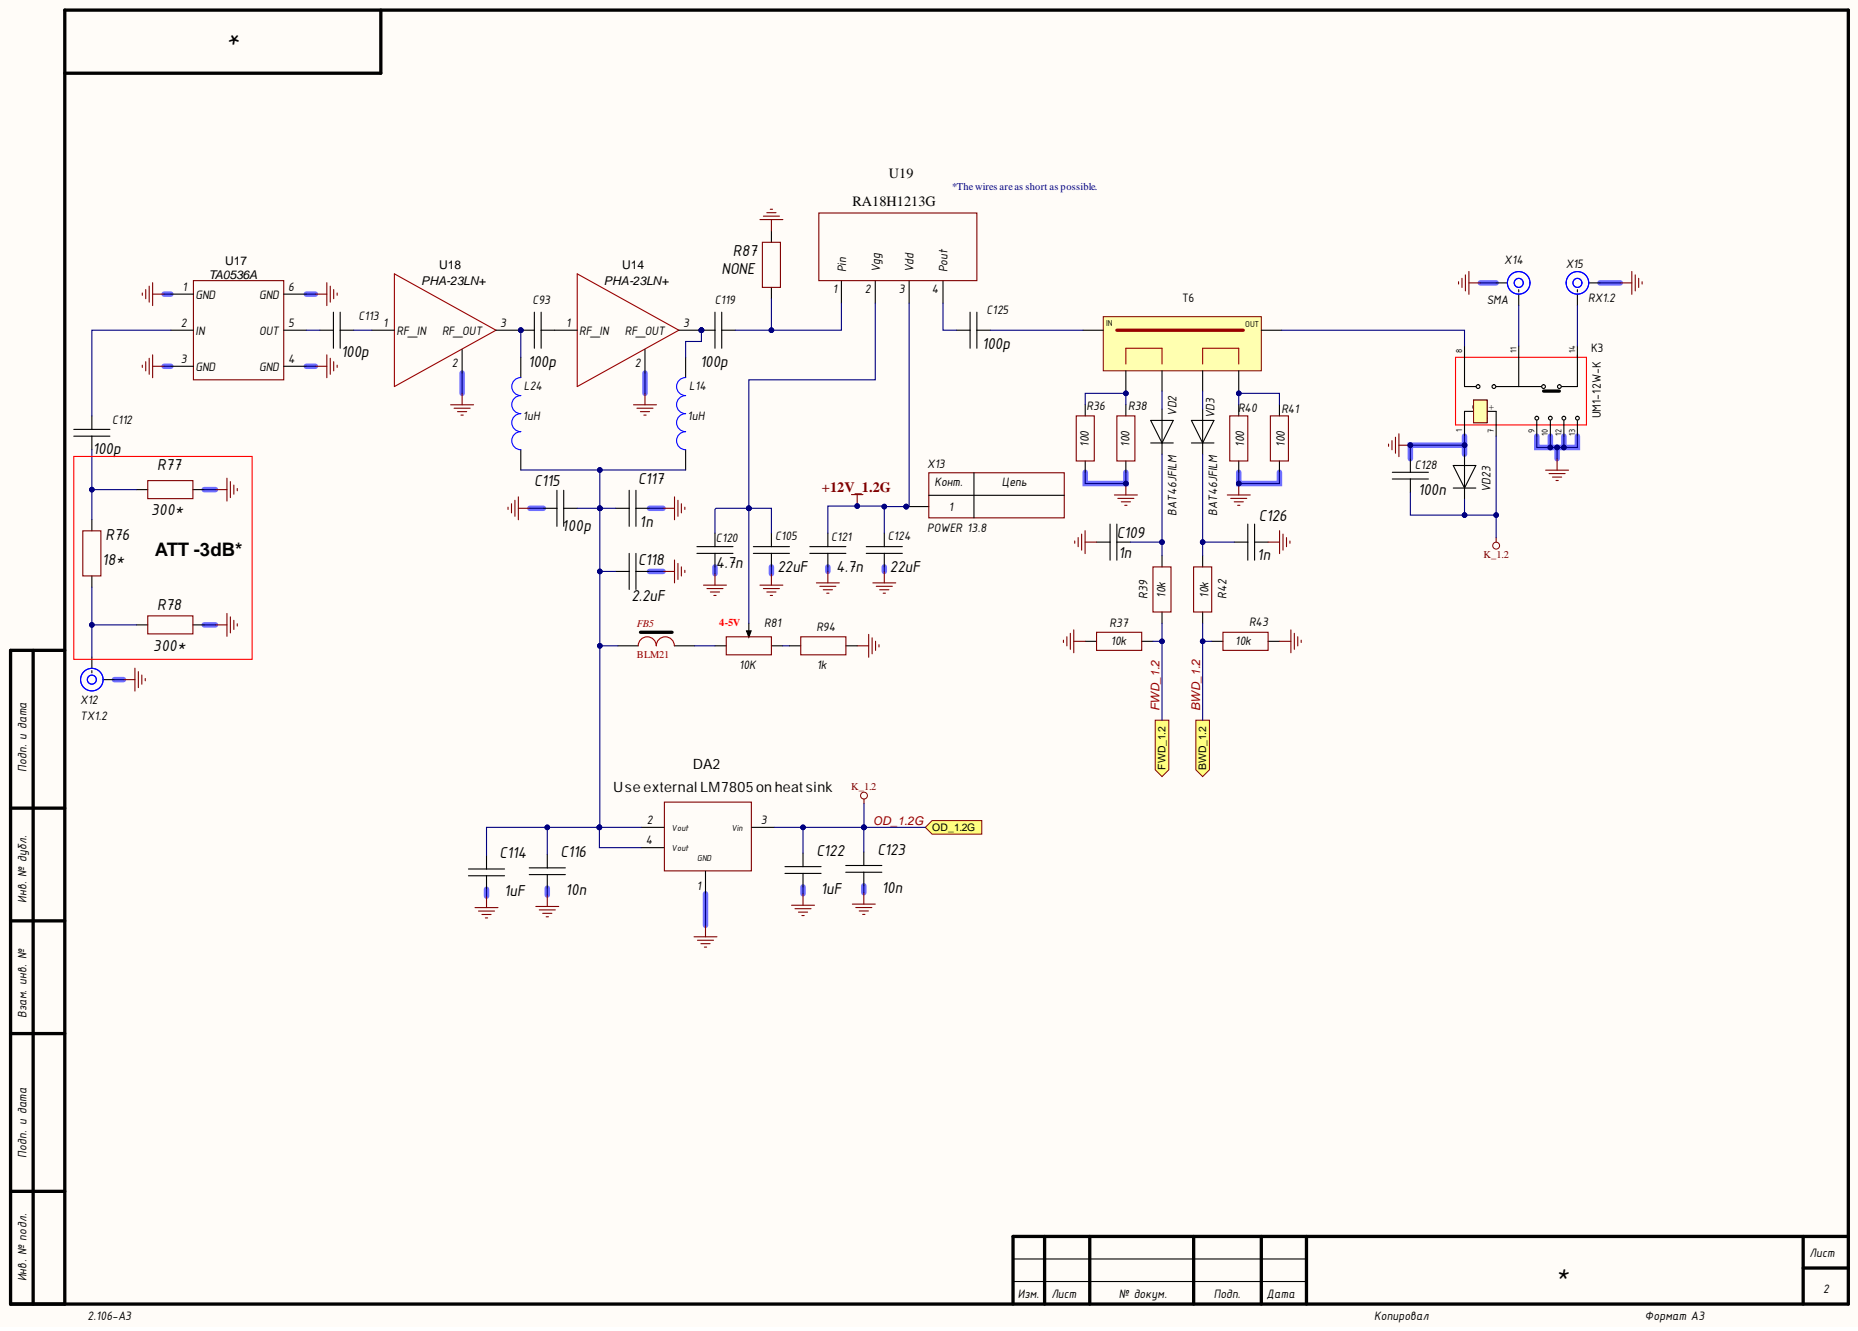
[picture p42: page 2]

*Thewires are asshort as possible.

Инв. № подл. Инв. № дубл. Подп. и дата Взам. инв. № Подп. и дата

Use external LM7805 on heat sink

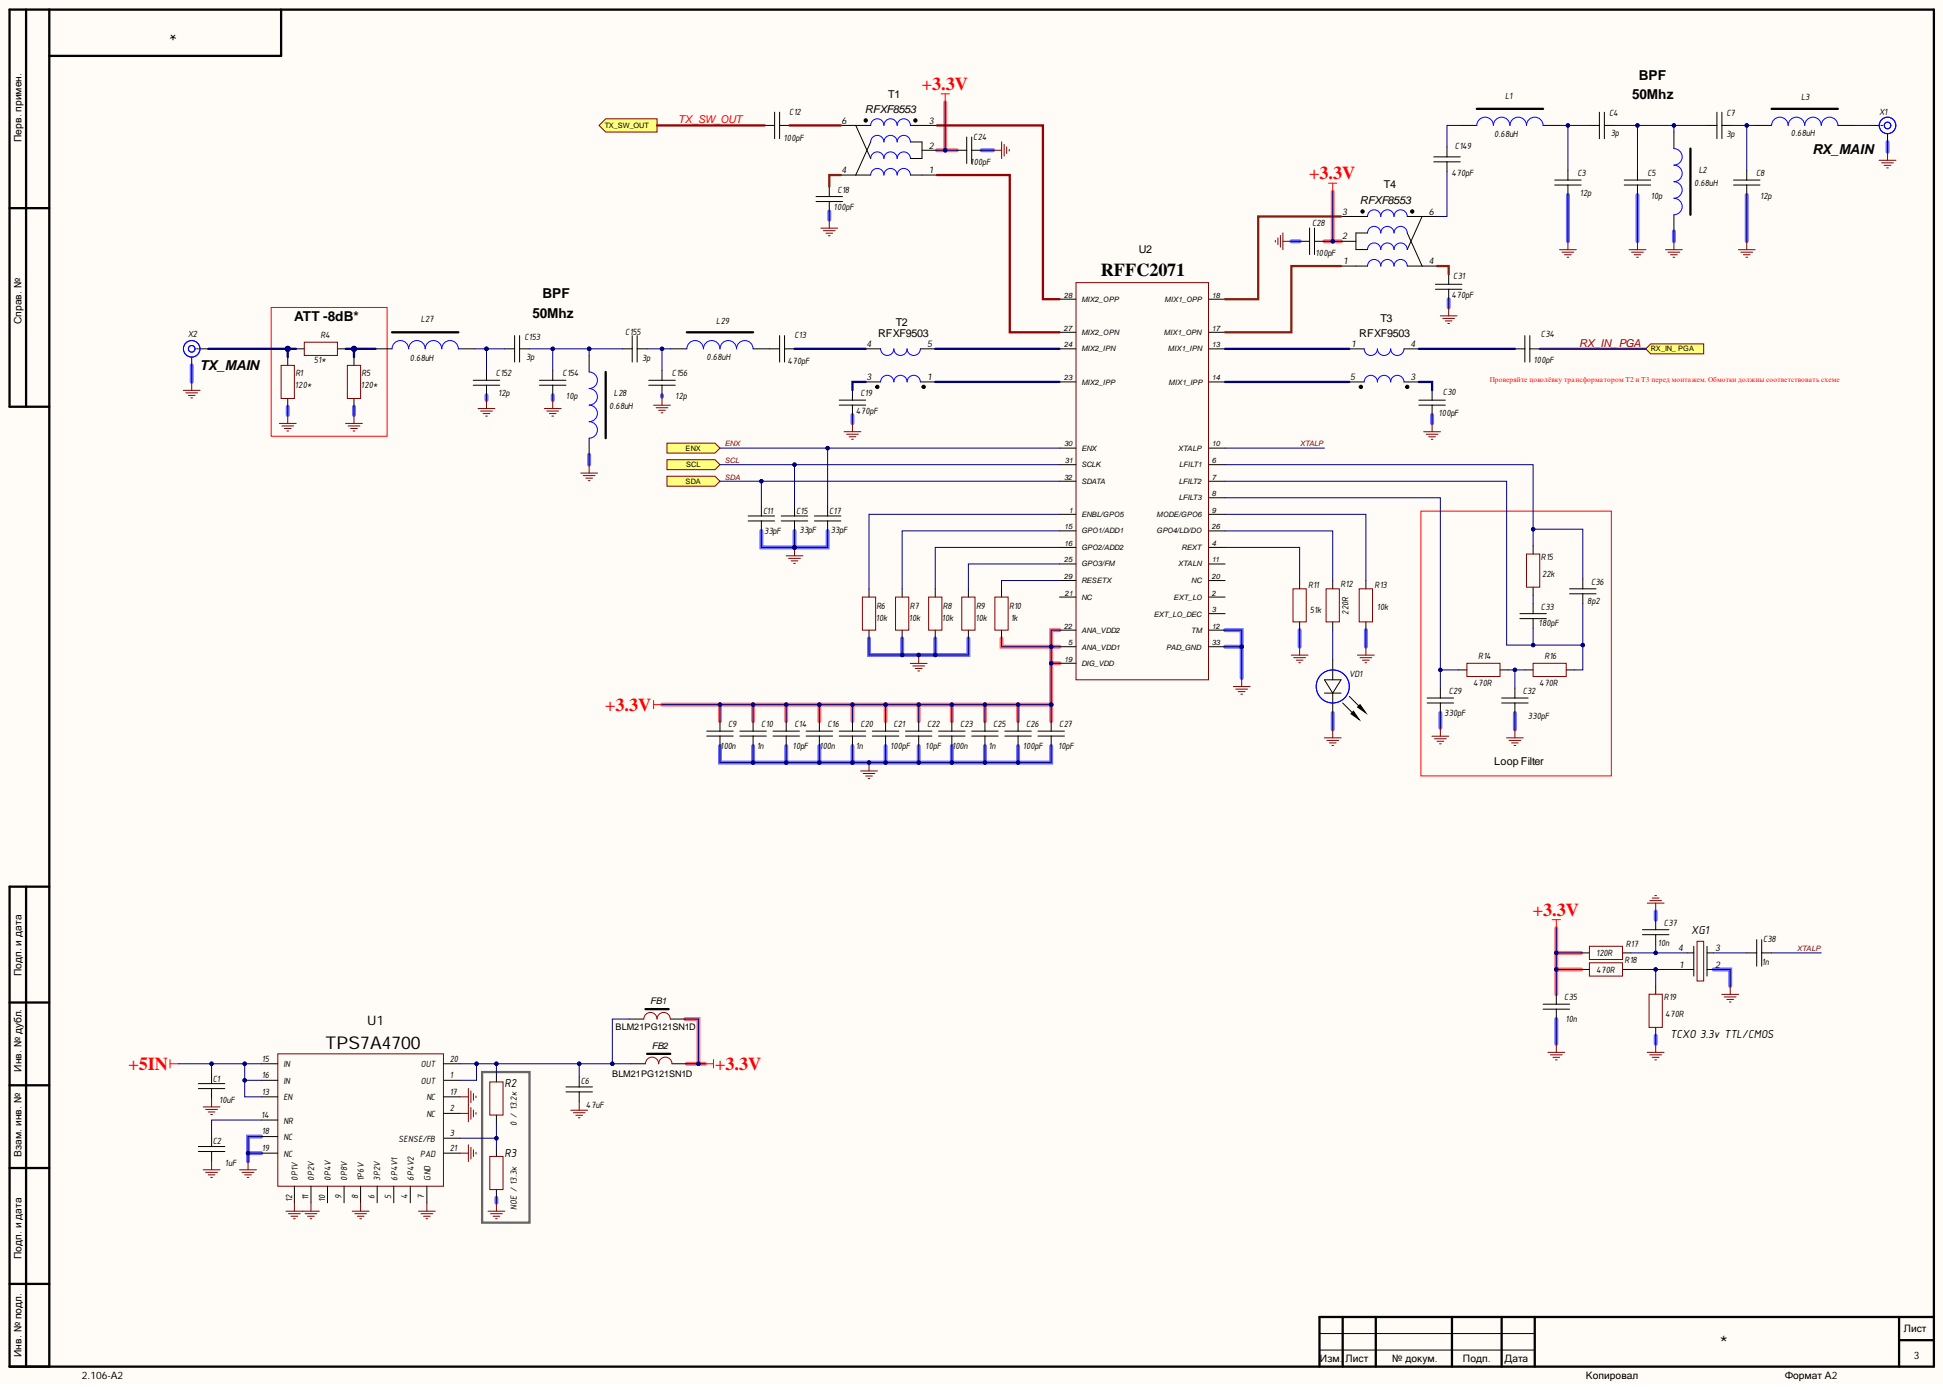
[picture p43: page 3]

Инв. № подл. Инв. № дубл. Подп. и дата Взам. инв. № Подп. и дата Перв. примен. Справ. №

Проверяйте цоколёвку трансформатором T2 и T3 перед монтажем. Обмотки должны соответствовать схеме

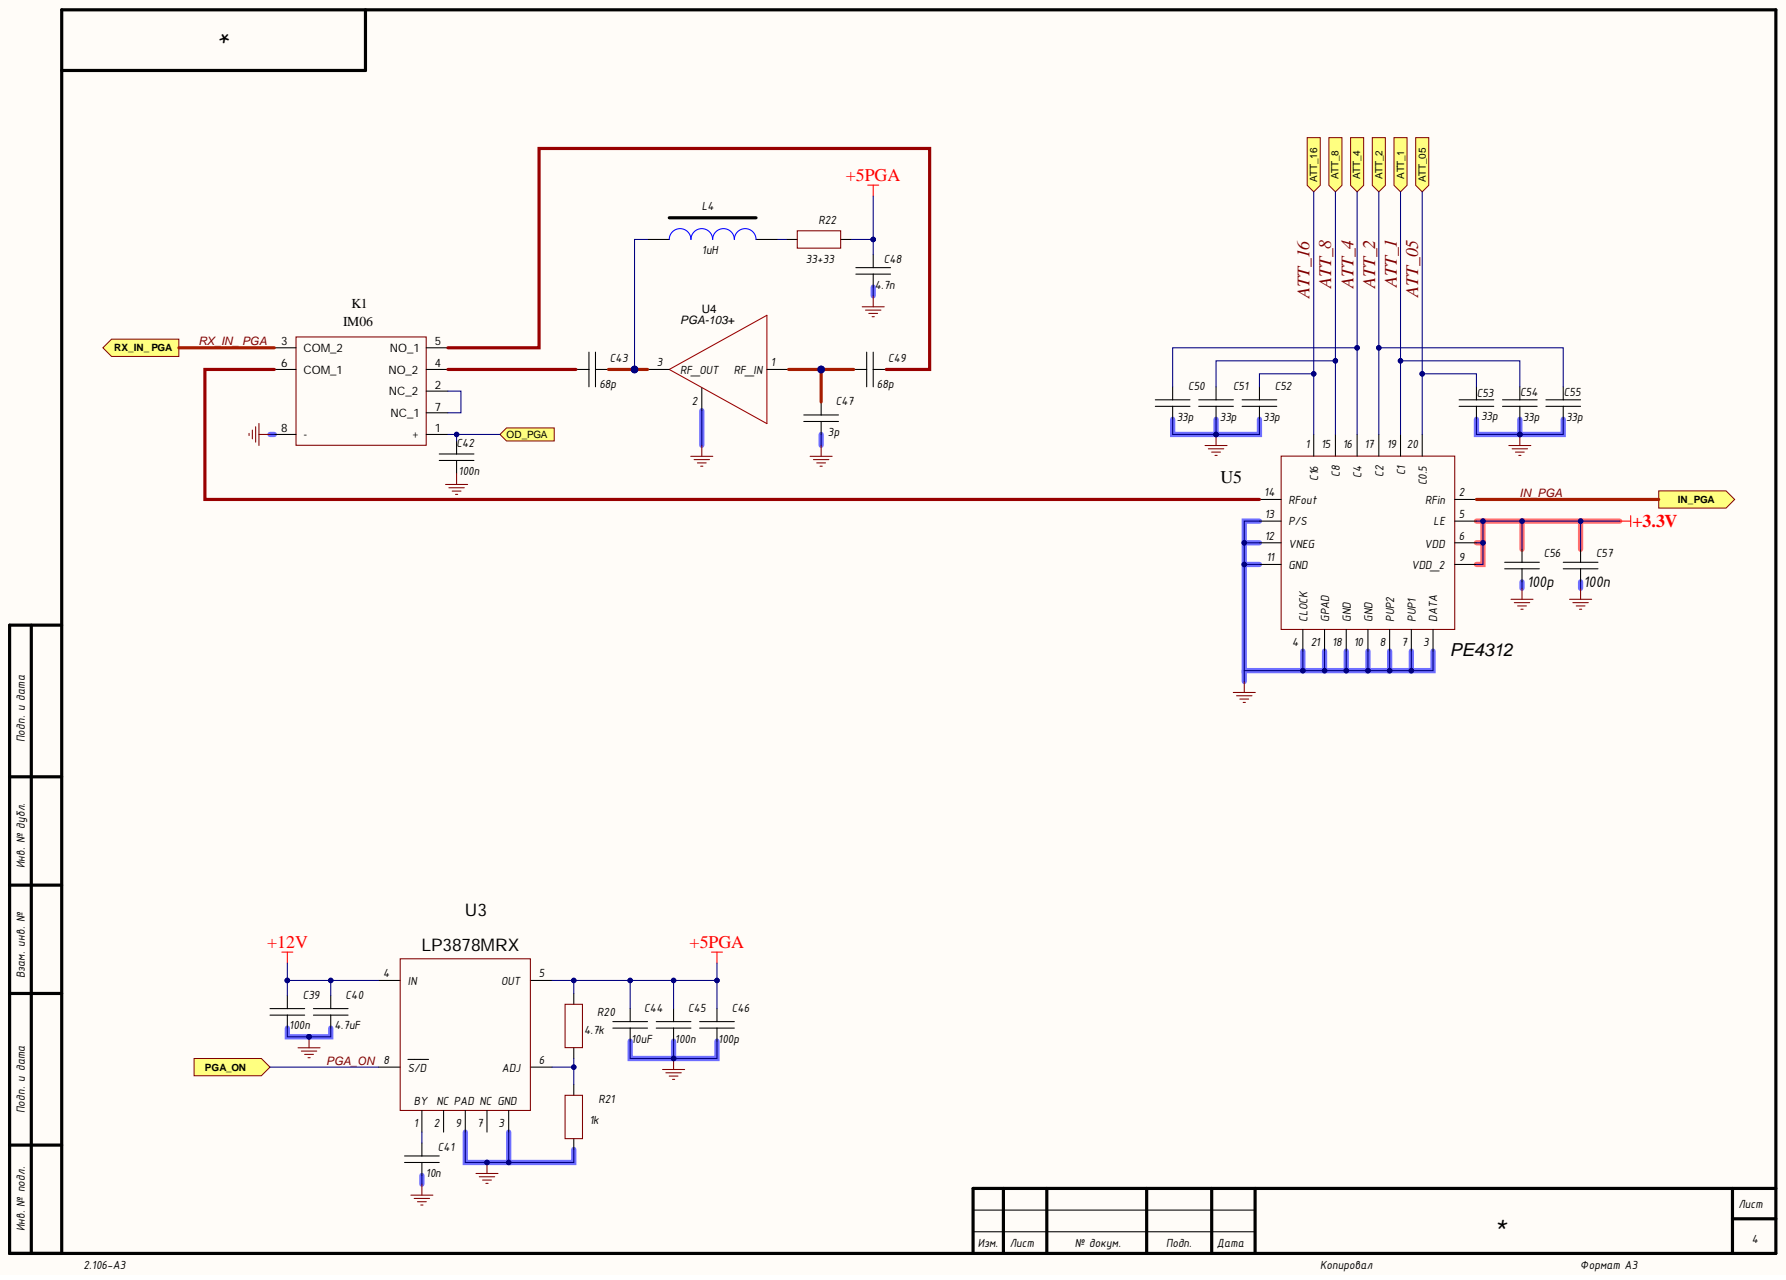
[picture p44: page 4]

Инв. № подл. Инв. № дубл. Подп. и дата Взам. инв. № Подп. и дата

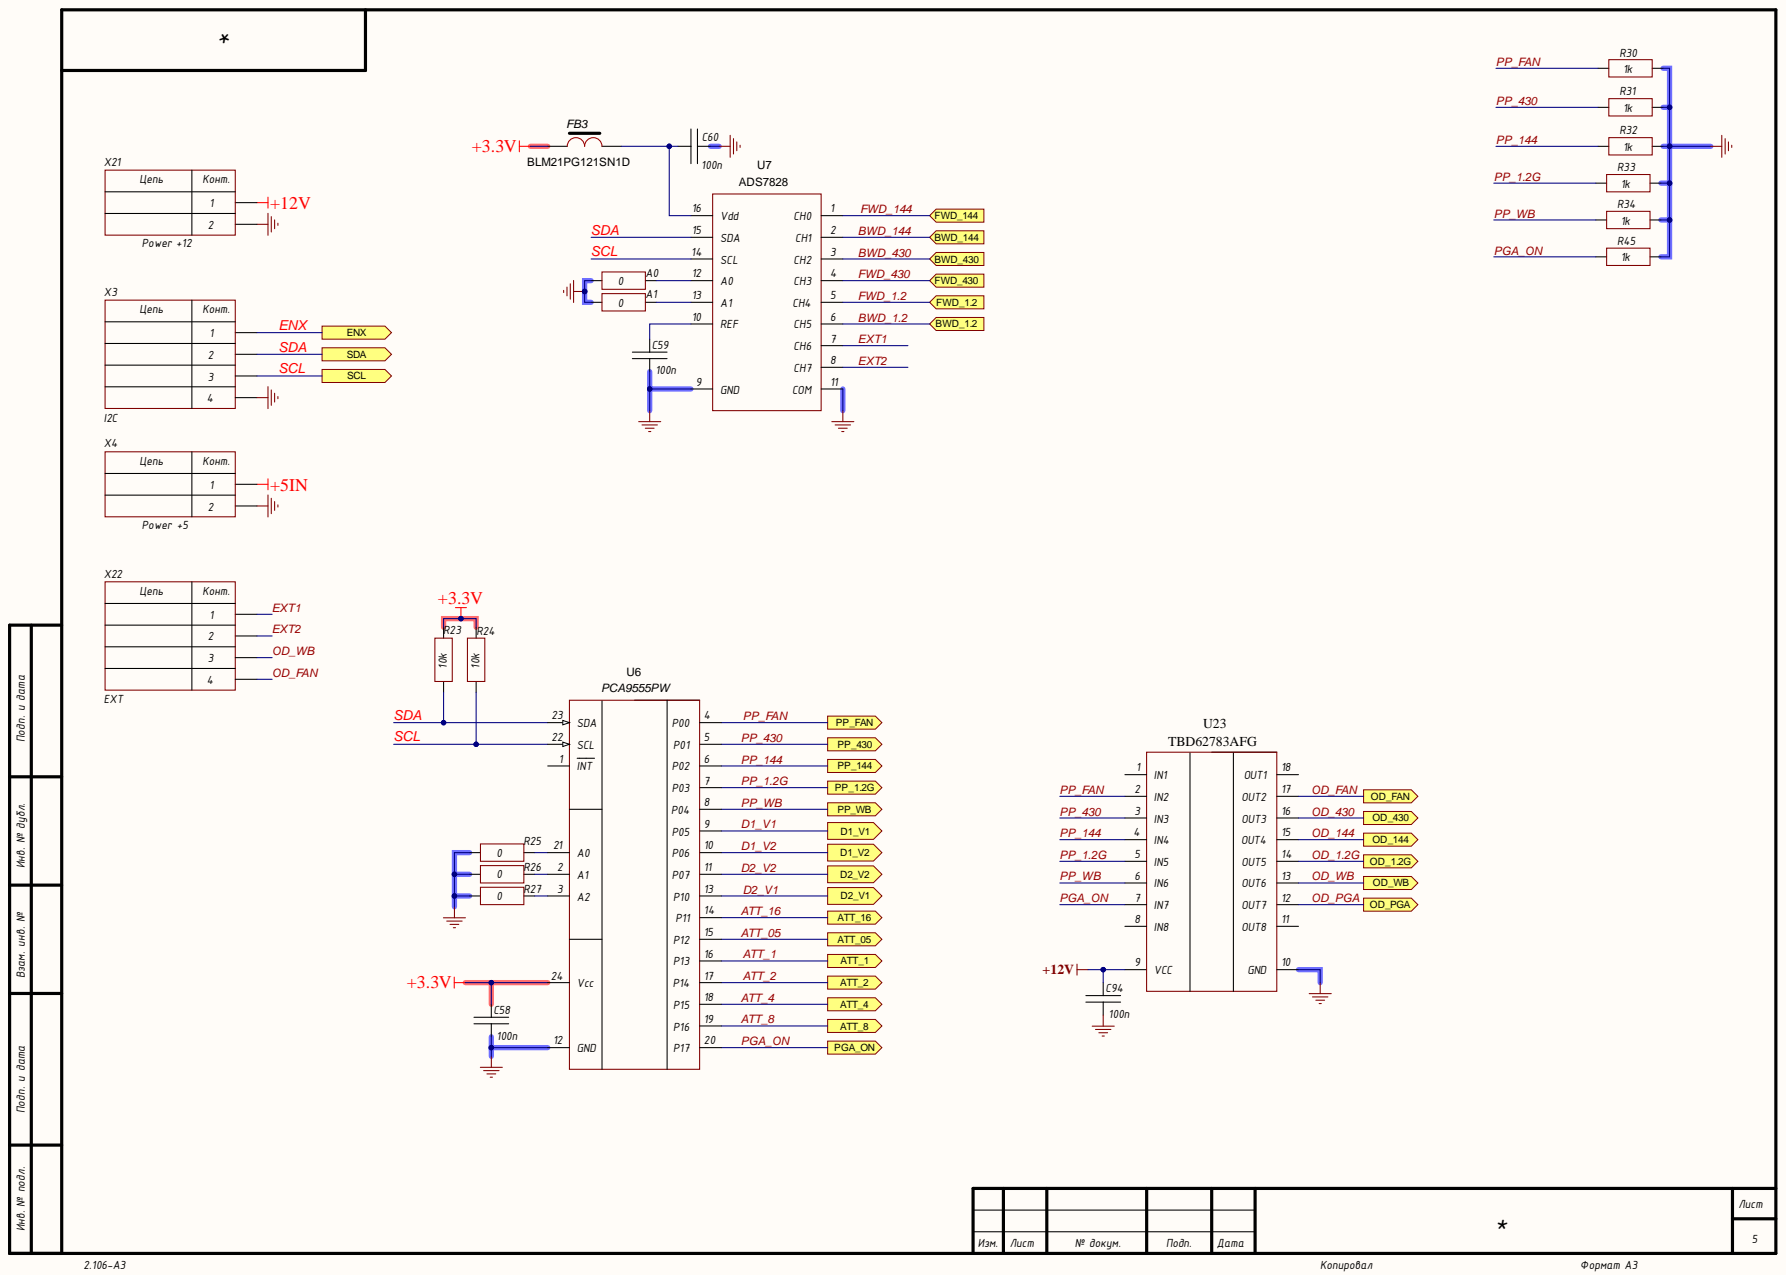
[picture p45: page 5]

Цеп ь | Конт .

Инв. № подл. Инв. № дубл. Подп. и дата Взам. инв. № Подп. и дата

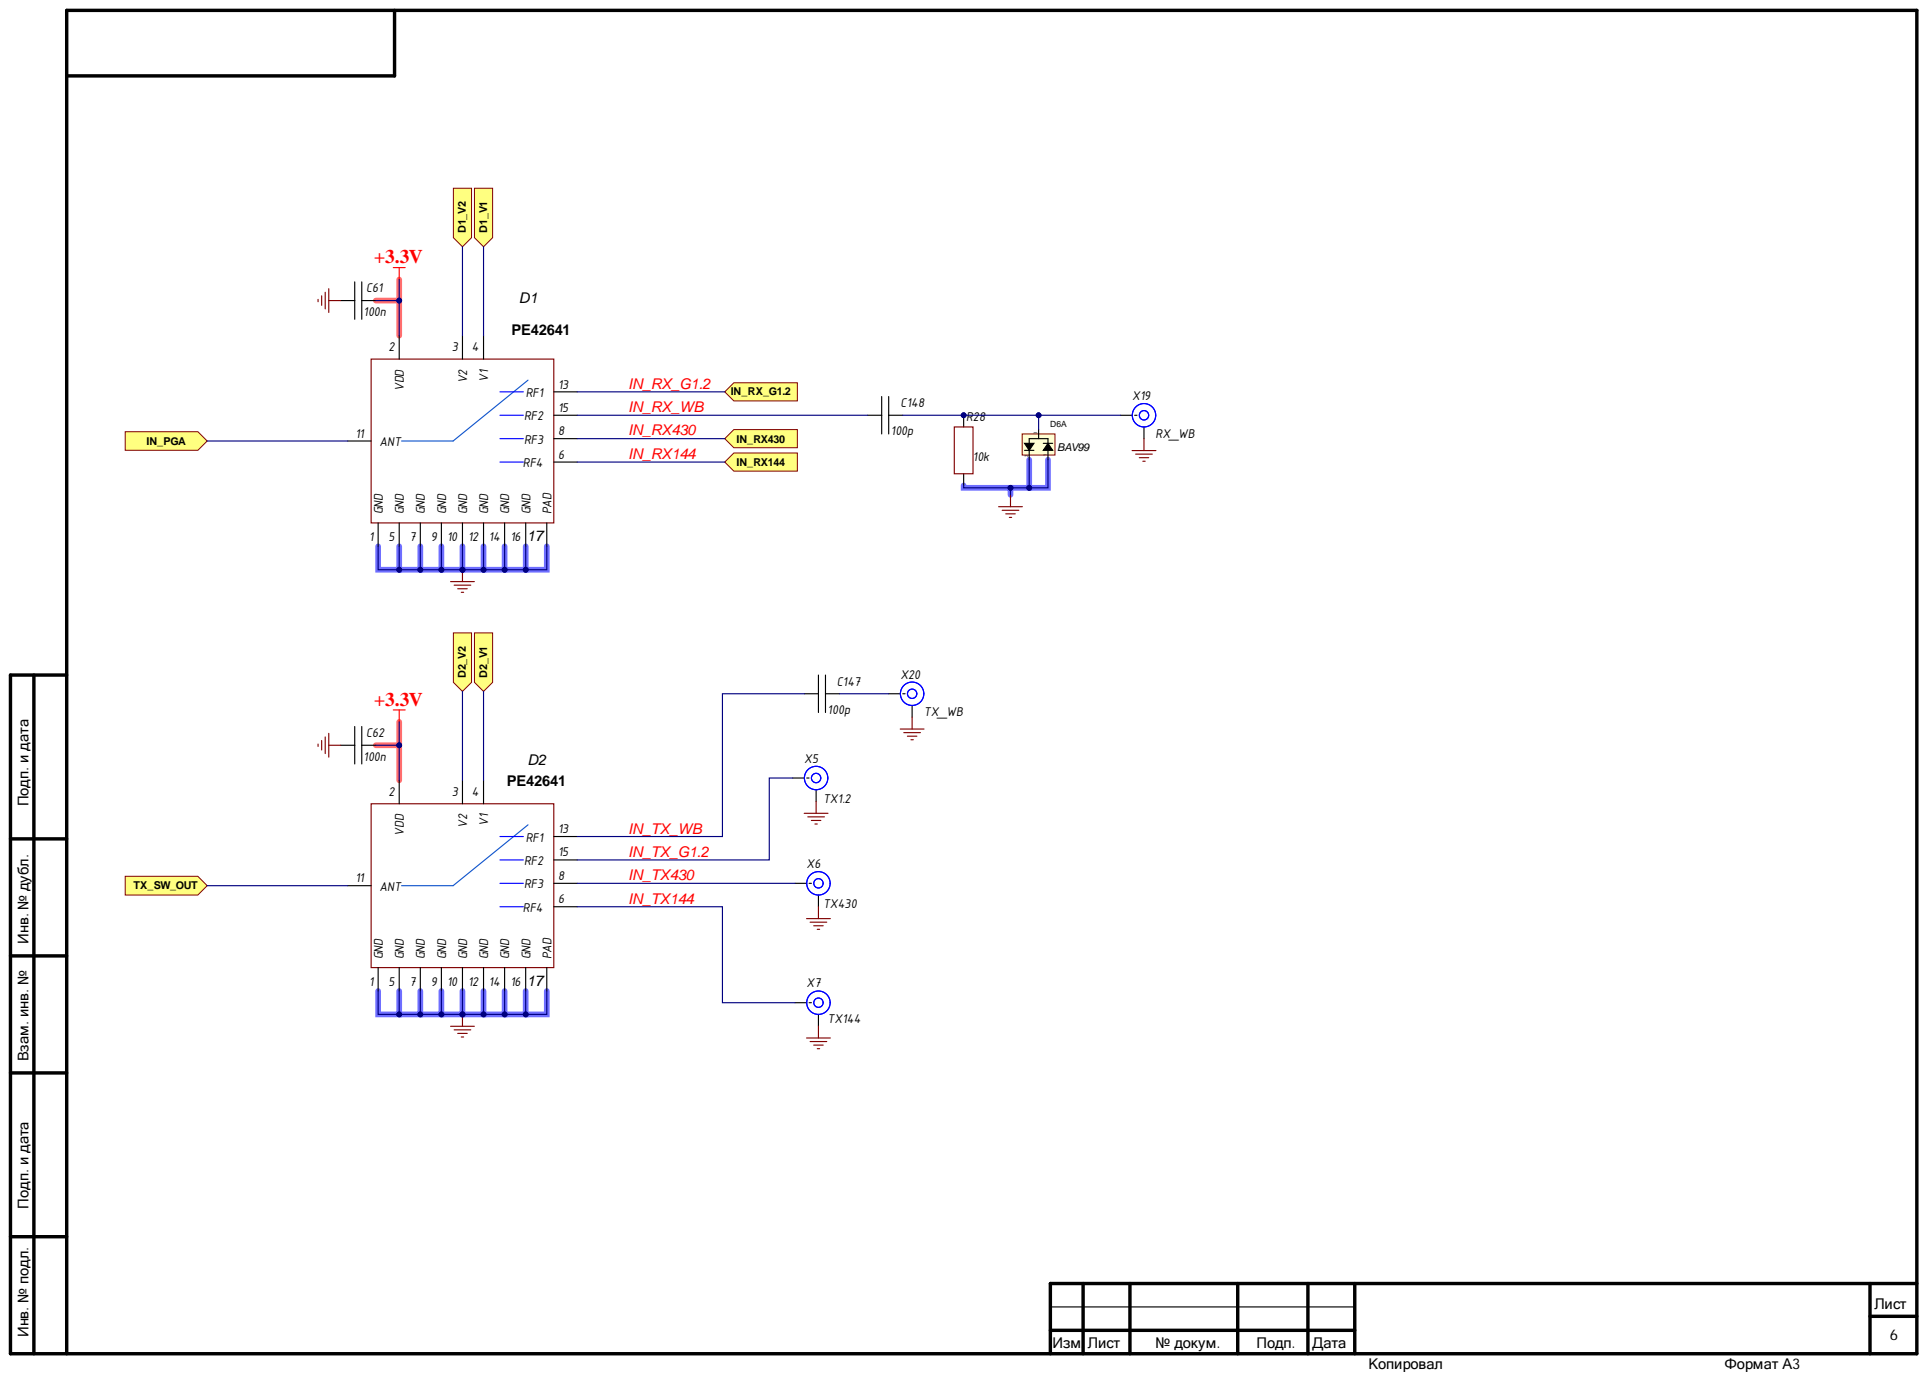
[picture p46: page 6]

Инв. № подл. Подп. и дата Инв. № дубл. Подп. и дата Взам. инв. №

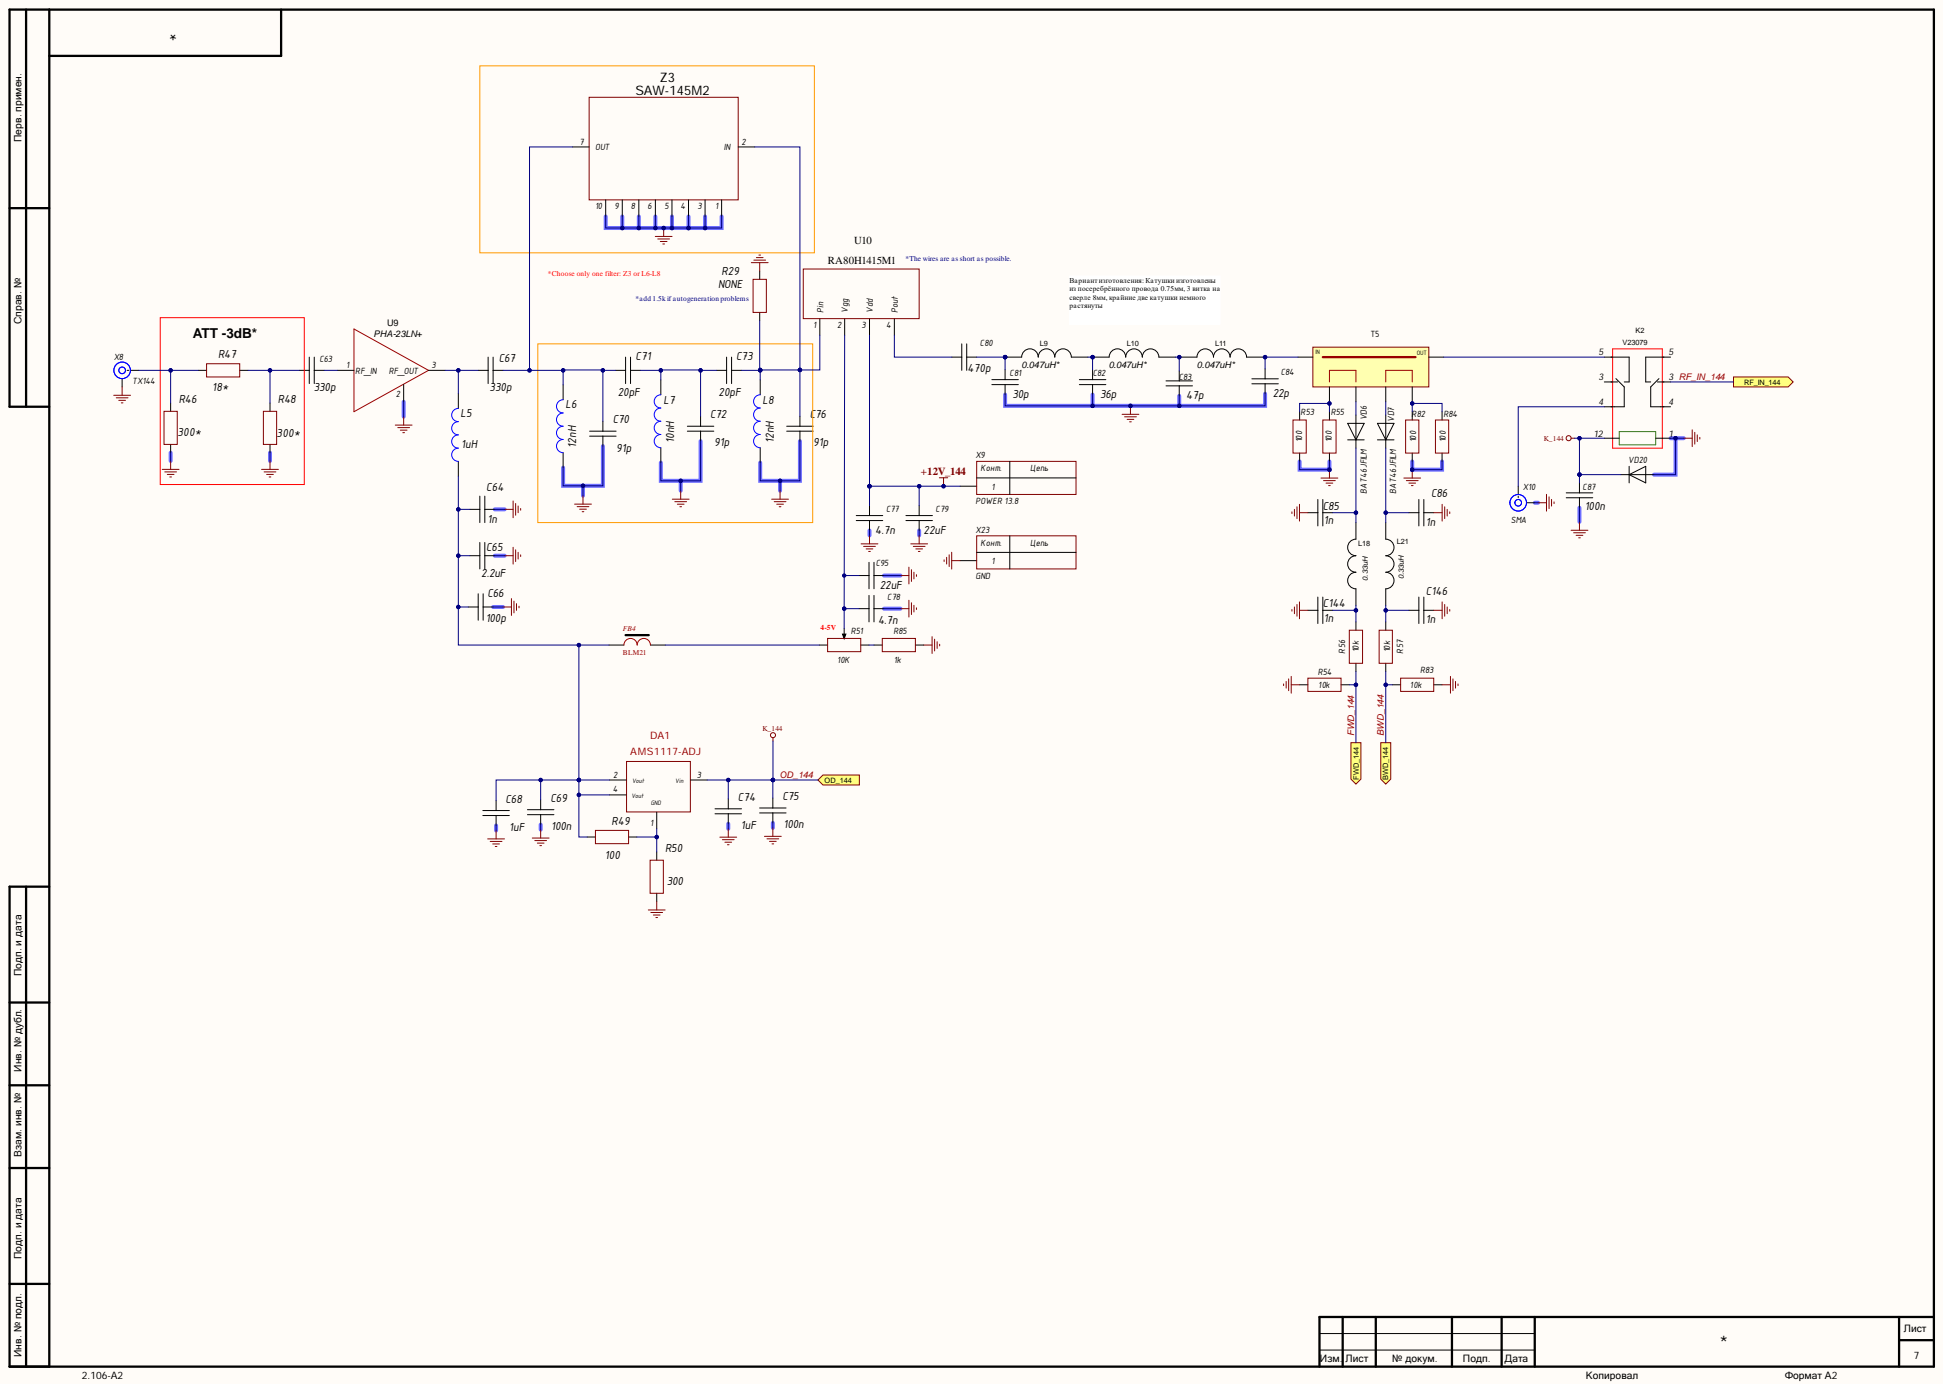
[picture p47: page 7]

Инв. № подл. Инв. № дубл. Подп. и дата Взам. инв. № Подп. и дата Перв. примен. Справ. №

*The wires are as short as possible.

*add 1.5k if autogeneration problems

из посеребрённого провода 0.75мм, 3 витка на
сверле 8мм, крайние две катушки немного
растянуты

Конт. | Цепь

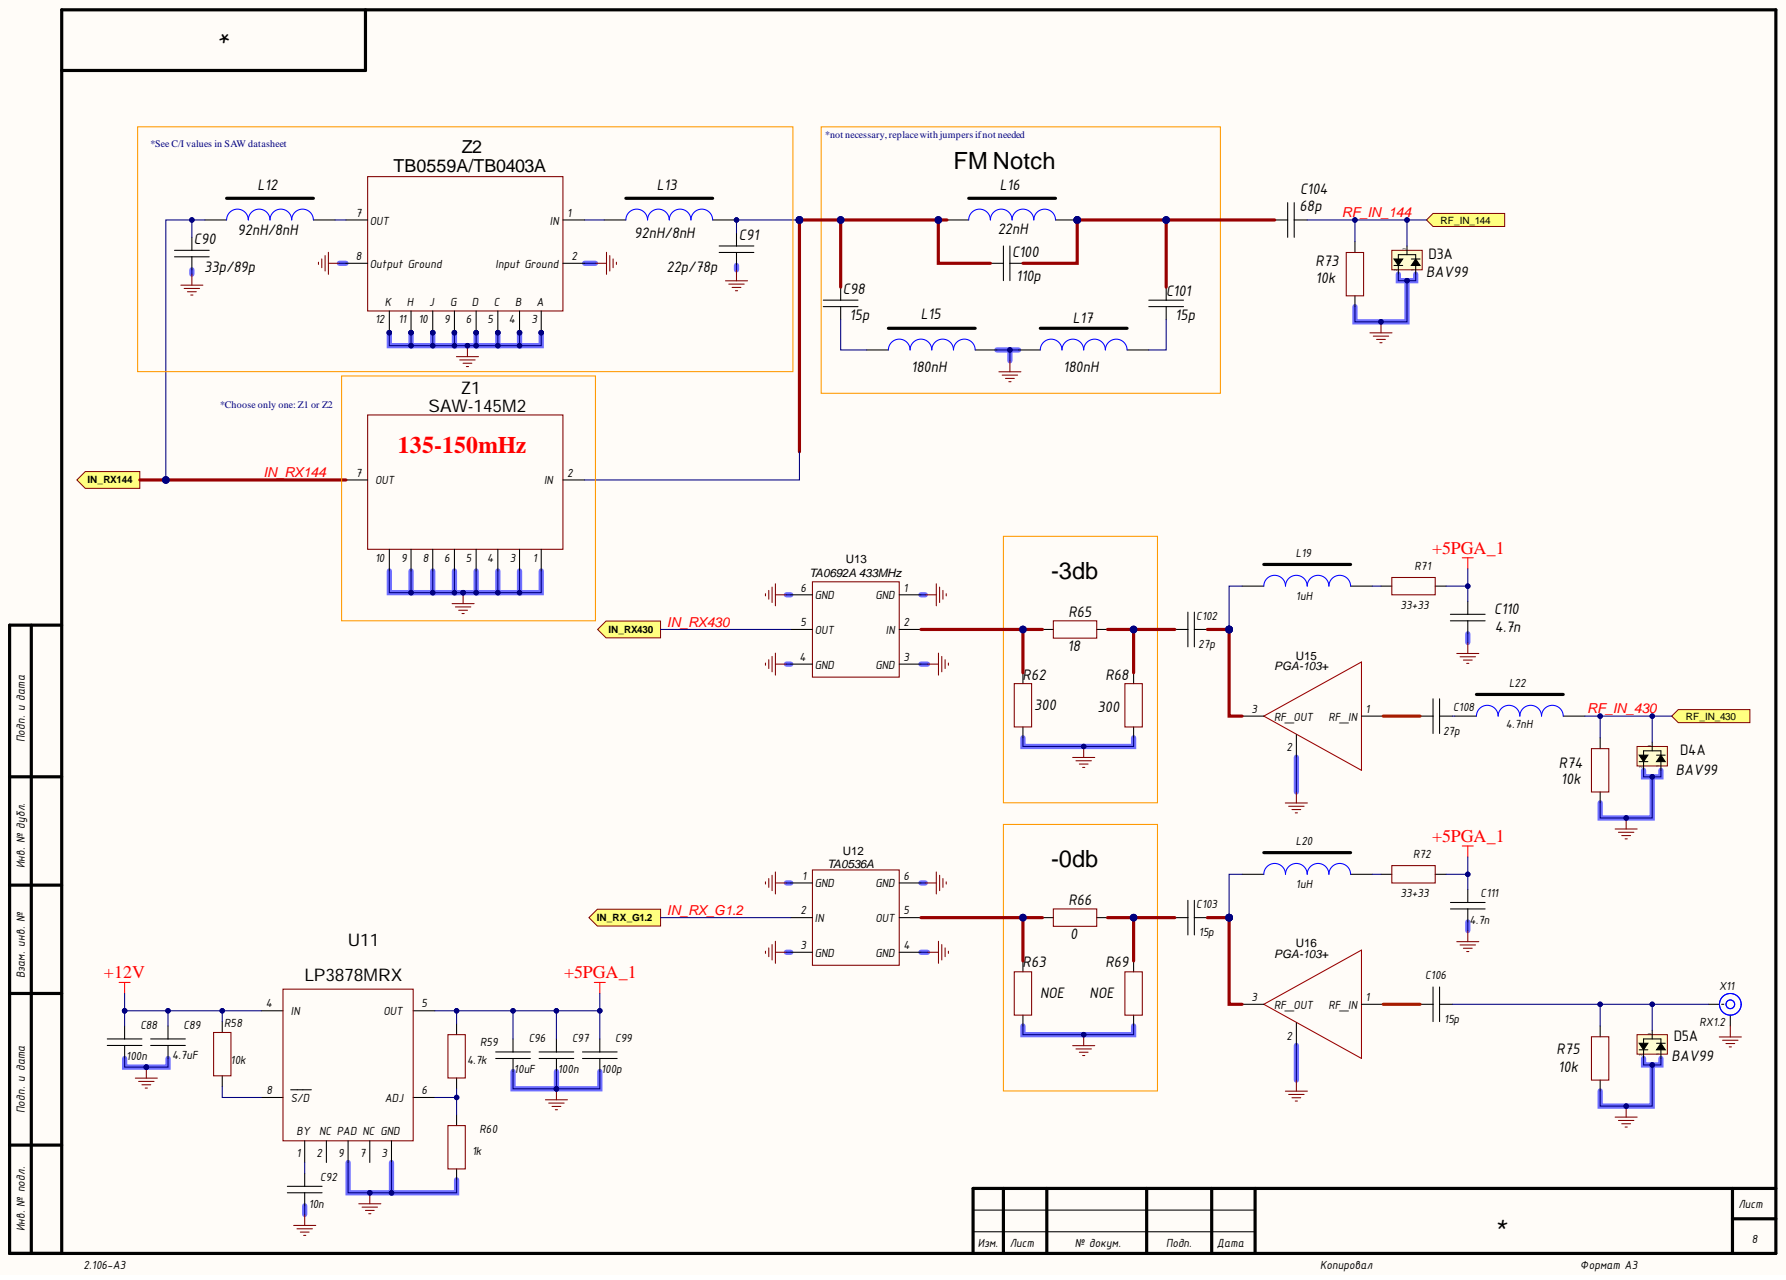
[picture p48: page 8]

*Choose only one: Z1 or Z2

Инв. № подл. Инв. № дубл. Подп. и дата Взам. инв. № Подп. и дата

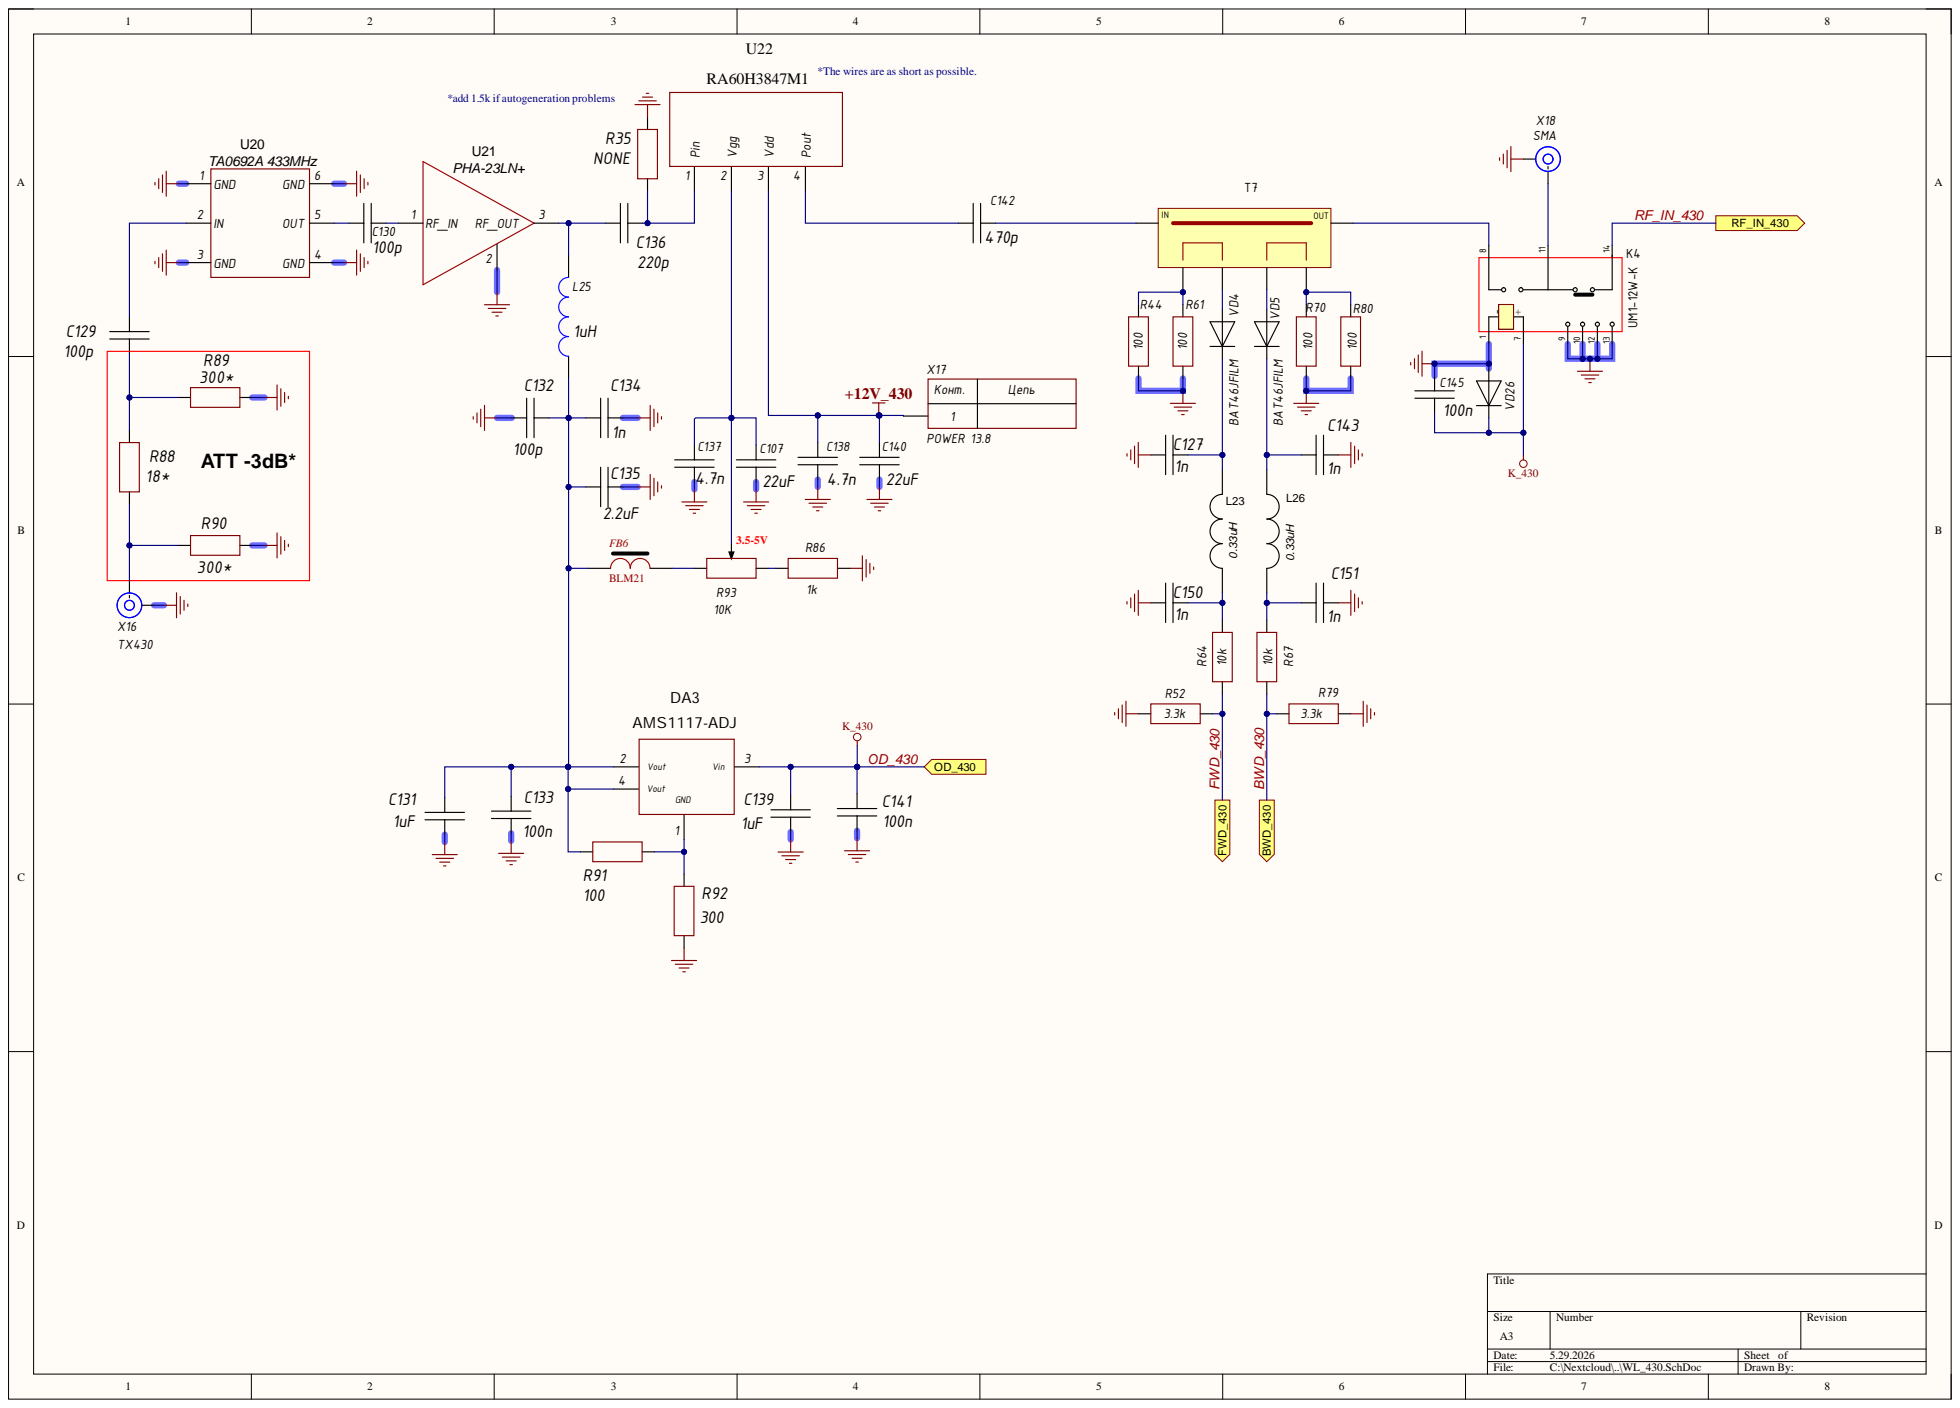
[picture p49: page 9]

*The wires are as short as possible.

*add 1.5k if autogeneration problems

Конт. | Цепь

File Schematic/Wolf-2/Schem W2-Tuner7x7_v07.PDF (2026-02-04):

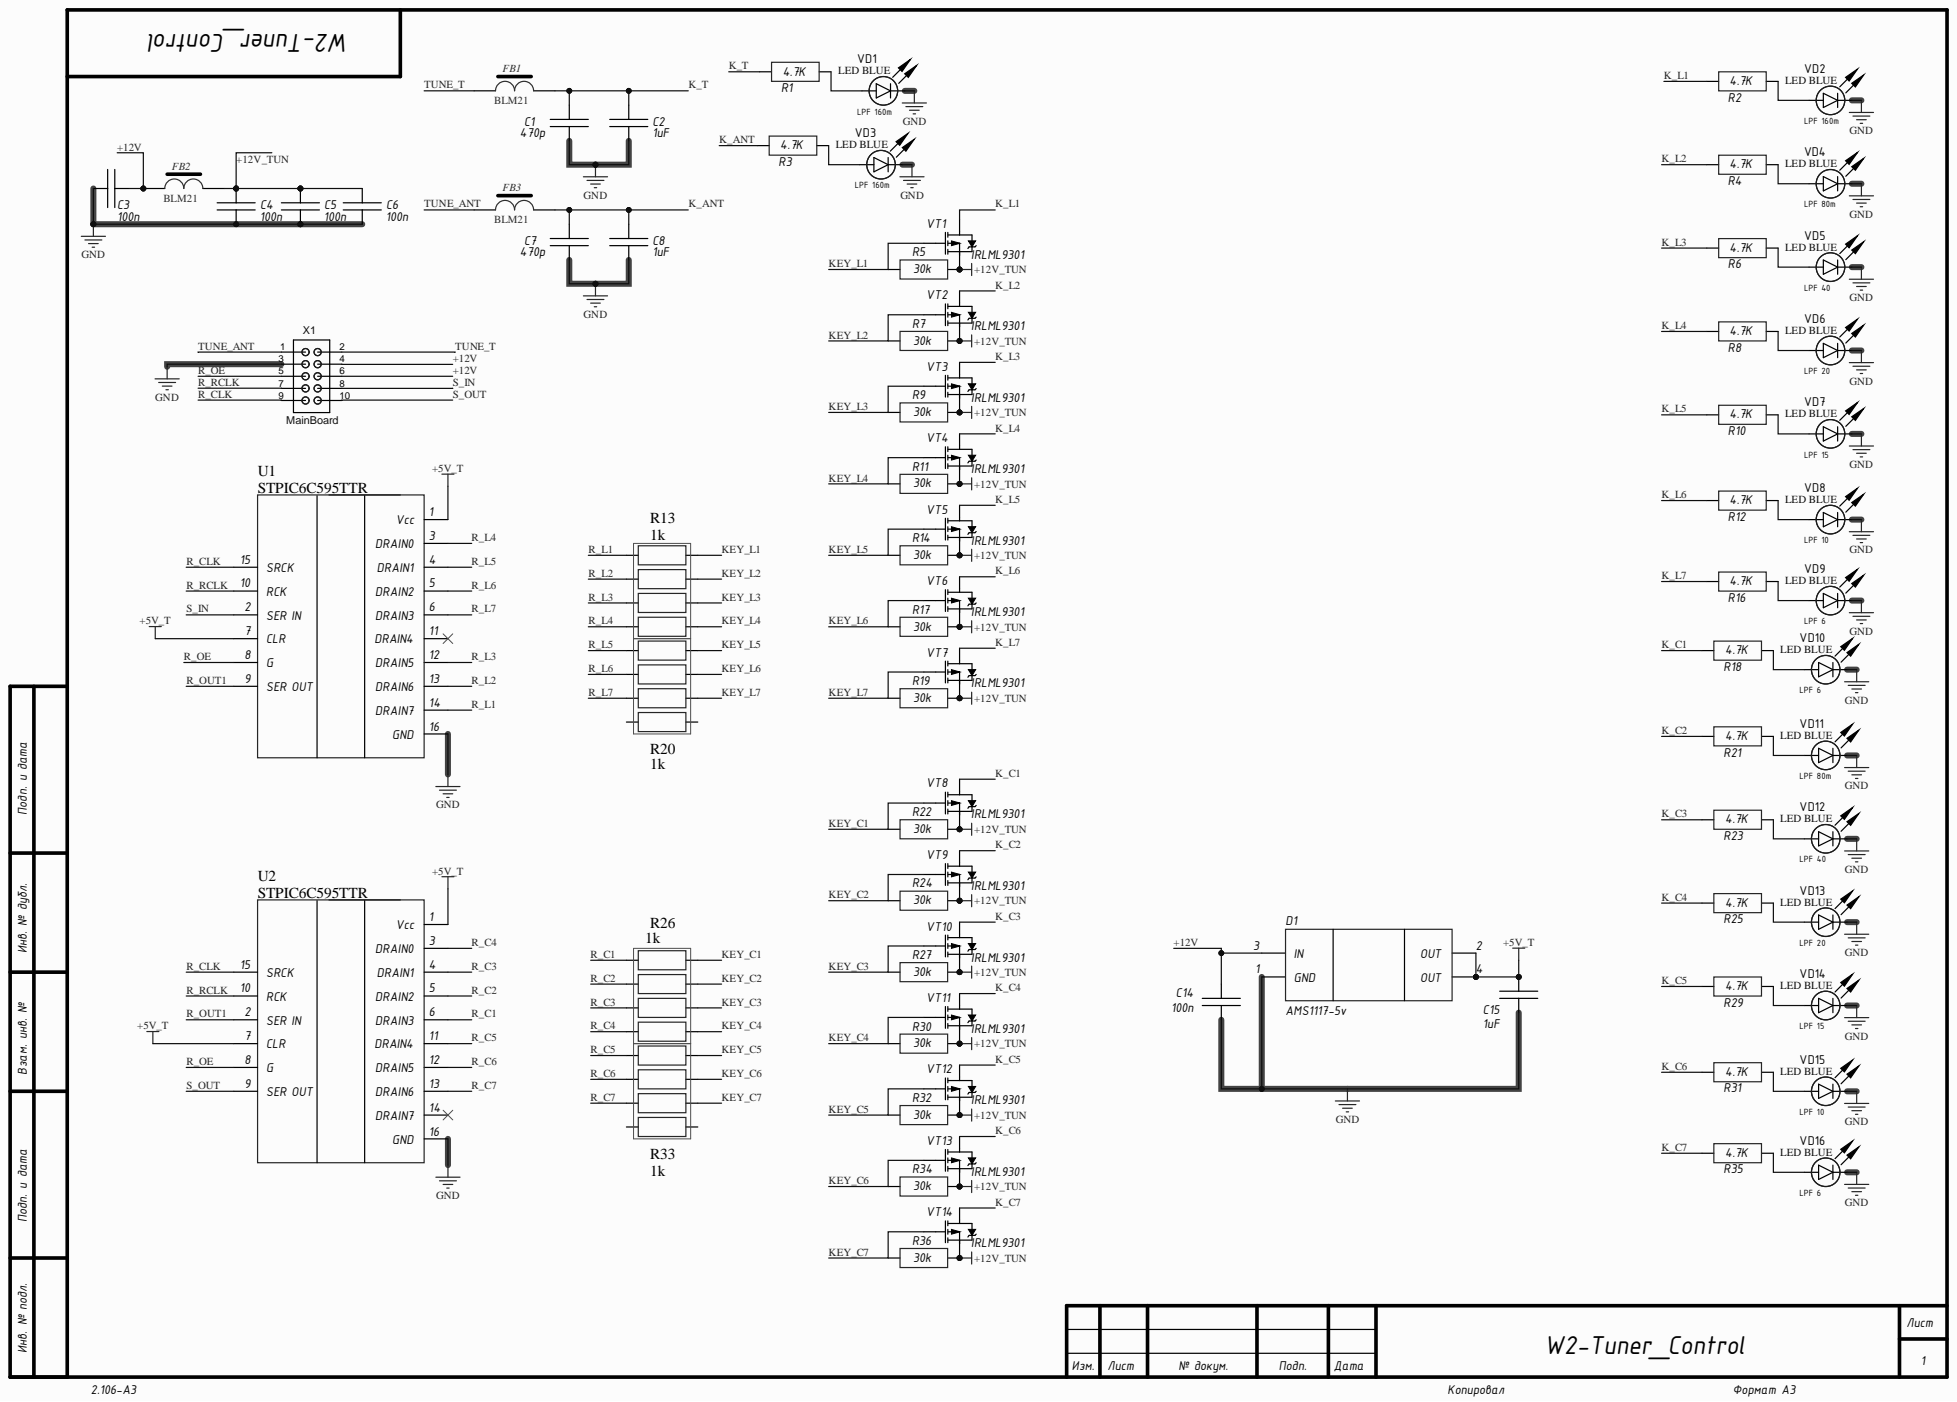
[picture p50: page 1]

Инв. № подл. Инв. № дубл. Подп. и дата Взам. инв. № Подп. и дата

W2-Tuner_Con t r o l | Лист1

Изм . | Лист | № докум . | Подп . | Да т а

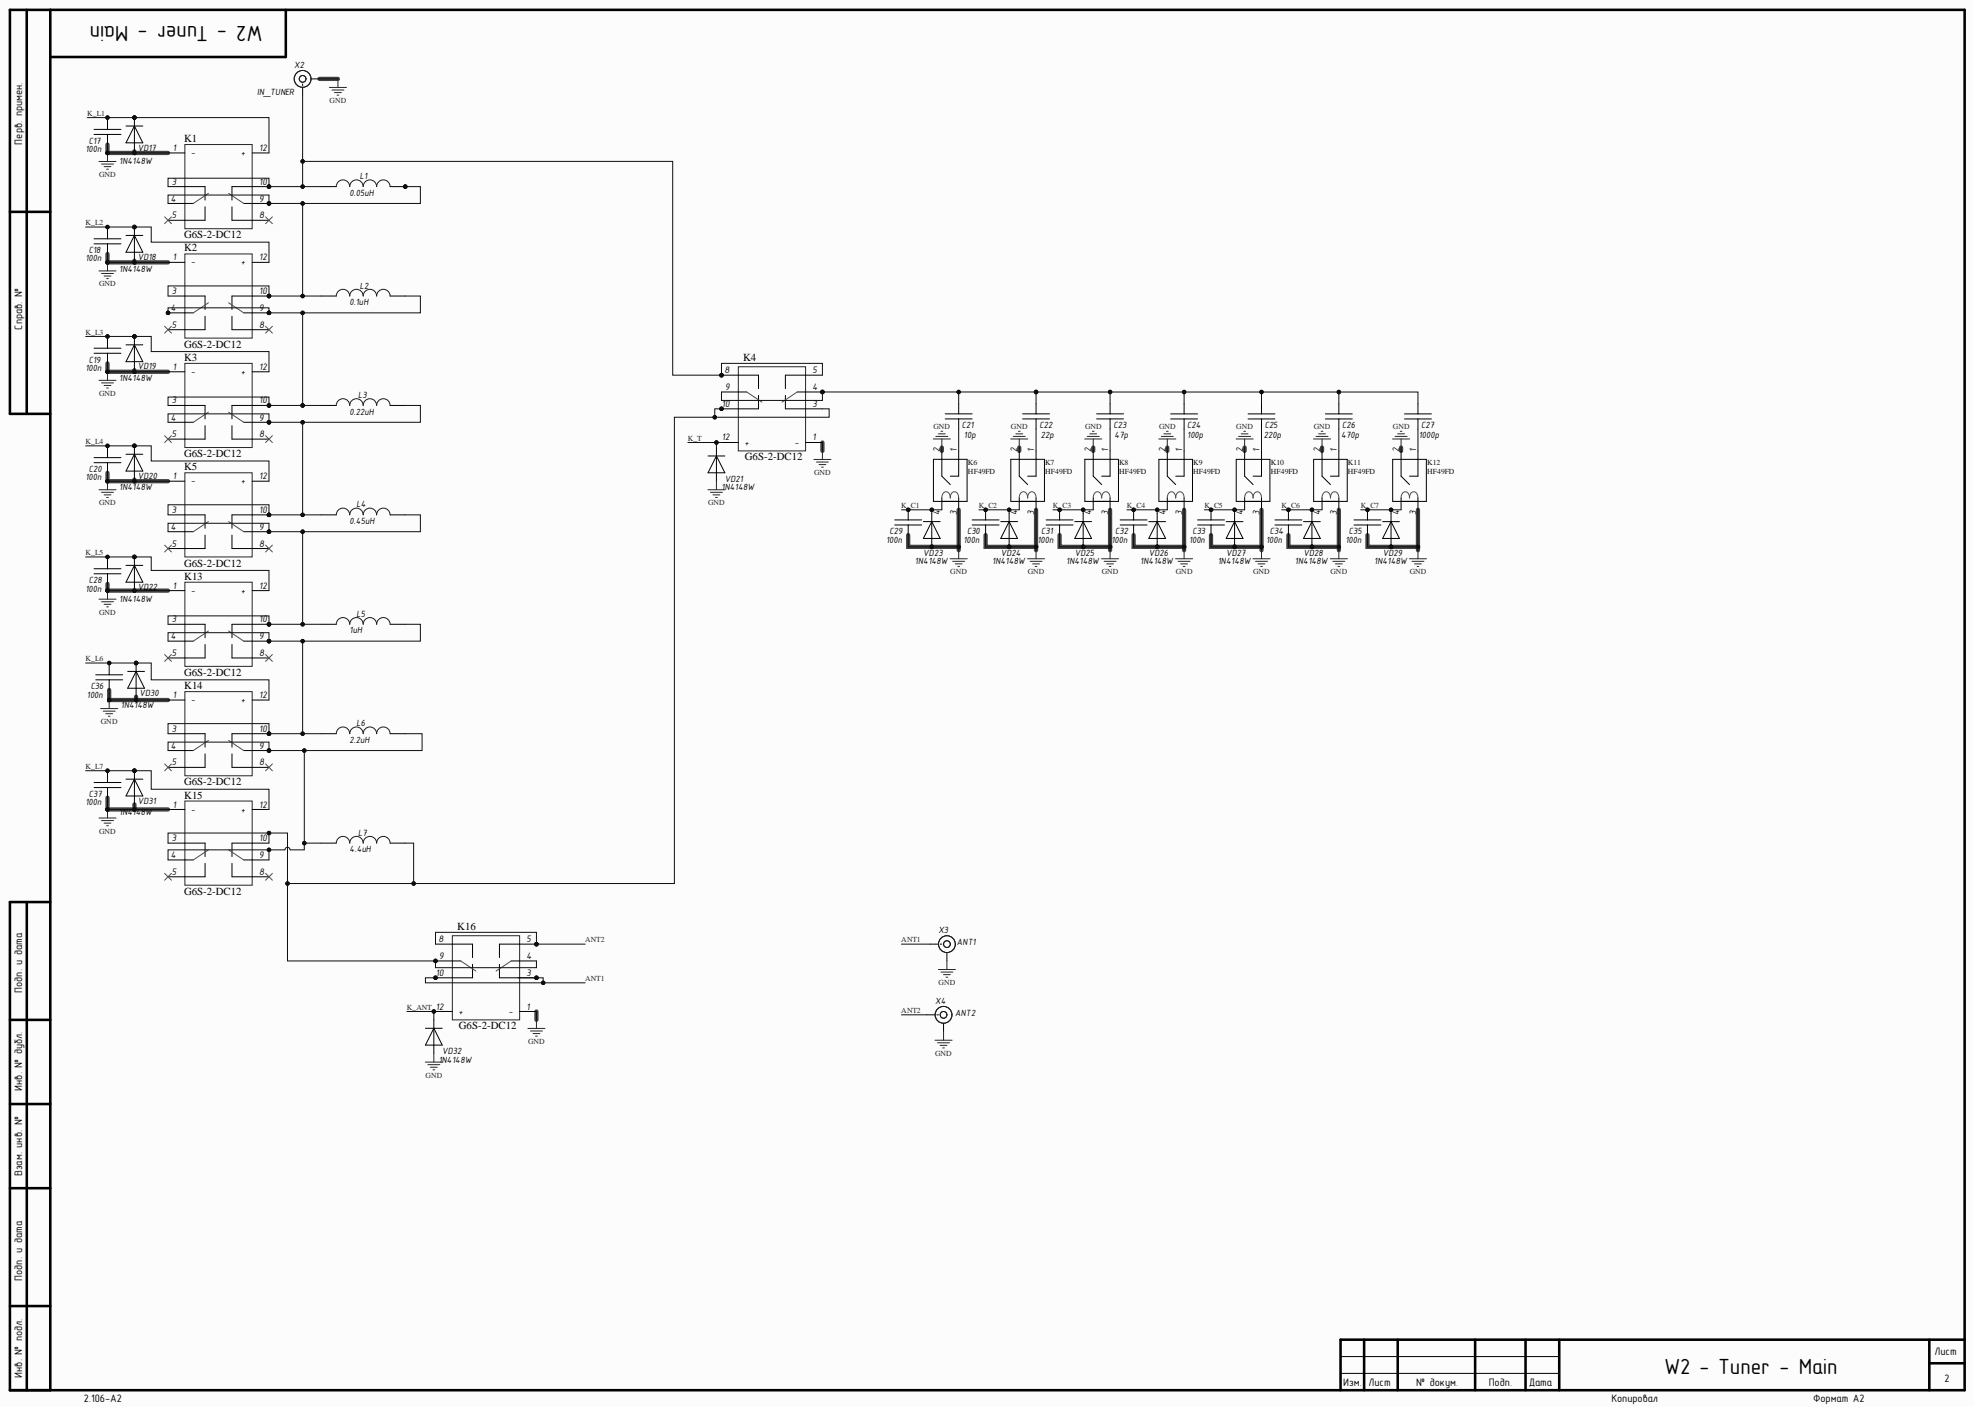
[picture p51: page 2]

Инв. № подл. Инв. № дубл. Подп. и дата Взам. инв. № Подп. и дата Перв. примен. Справ. №

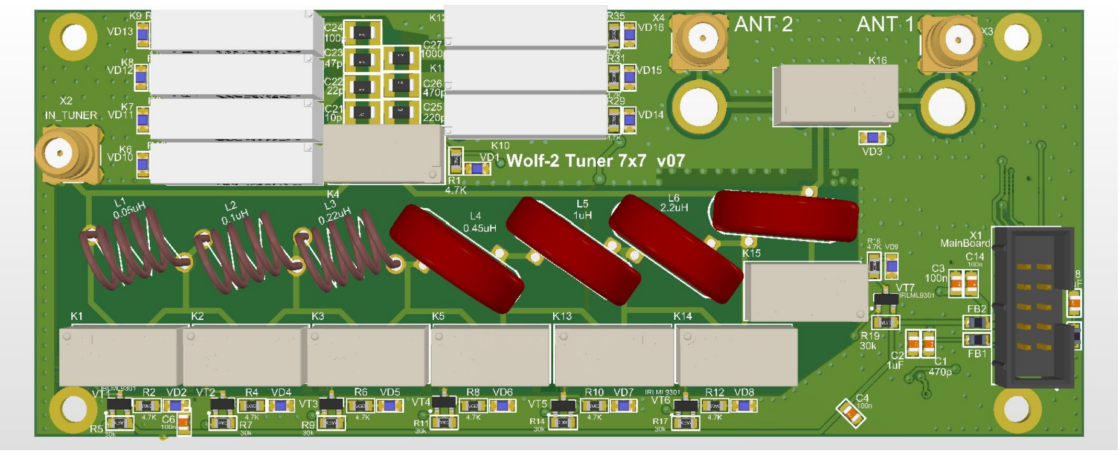
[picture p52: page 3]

Comment | Description | Designator | Footprint | LibRef | Quantity
470p | | C1, C7 | CH0805C | Capacitor | 2
1uF | | C2, C8, C15 | CH0805C | Capacitor | 3
100n | | C3, C4, C5, C6, C14, C17, C18, C19, C20, C28, C29, C30, C31, C32, C33, C34, C35, C36, C37 | CH0805C | Capacitor | 19
10p | | C21 | CH1206ATC | Capacitor | 1
22p | | C22 | CH1206ATC | Capacitor | 1
47p | | C23 | CH1206ATC | Capacitor | 1
100p | | C24 | CH1206ATC | Capacitor | 1
220p | | C25 | CH1206ATC | Capacitor | 1
470p | | C26 | CH1206ATC | Capacitor | 1
1000p | | C27 | CH1206ATC | Capacitor | 1
AMS1117-5v | LDO | D1 | SOT223 | NCP1117LPST50T3G | 1
BLM21 | | FB1, FB2, FB3 | CH0805L | FB-1 | 3
G6S-2-DC12 | | K1, K2, K3, K4, K5, K13, K14, K15, K16 | G6S-2-DC12 | G6S-2-12VDC | 9
HF49FD | | K6, K7, K8, K9, K10, K11, K12 | HF49FD | HF49FD 012-1H12 | 7
0.05uH | | L1 | DR1 | Inductor ring | 1
0.1uH | | L2 | DR1 | Inductor ring | 1
0.22uH | | L3 | DR1 | Inductor ring | 1
0.45uH | | L4 | T68-0 | Inductor ring | 1
1uH | | L5 | T68-0 | Inductor ring | 1
2.2uH | | L6 | T68-0 | Inductor ring | 1
4.4uH | | L7 | T68-0 | Inductor ring | 1
4.7K | | R1, R2, R3, R4, R6, R8, R10, R12, R16, R18, R21, R23, R25, R29, R31, R35 | CH0805R | Resistor | 16
30k | | R5, R7, R9, R11, R14, R17, R19, R22, R24, R27, R30, R32, R34, R36 | CH0805R | Resistor | 14
1k | | R13, R20, R26, R33 | CAT16 | CAT10-0804 | 4
STPIC6C595TTR | | U1, U2 | 16-TSOP | STPIC6C595TTR | 2
LED BLUE | | VD1, VD2, VD3, VD4, VD5, VD6, VD7, VD8, VD9, VD10, VD11, VD12, VD13, VD14, VD15, VD16 | LED: 0805B | LED_single | 16
1N4148W | | VD17, VD18, VD19, VD20, VD21, VD22, VD23, VD24, VD25, VD26, VD27, VD28, VD29, VD30, VD31, VD32 | SOD123 | Diod | 16
IRLML9301 | Mosfet | VT1, VT2, VT3, VT4, VT5, VT6, VT7, VT8, VT9, VT10, VT11, VT12, VT13, VT14 | SOT23_132 | IRLML9301 | 14
MainBoard | 2*5 Pin | X1 | CON: BH-10 | IDC10 | 1
IN_TUNER | RF | X2 | CON: SMA | SMA | 1
ANT1 | RF | X3 | CON: SMA | SMA | 1
ANT2 | RF | X4 | CON: SMA | SMA | 1

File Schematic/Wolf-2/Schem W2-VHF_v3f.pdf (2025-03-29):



*Thewires are asshort as possible.

Инв. № подл. Инв. № дубл. Подп. и дата Взам. инв. № Подп. и дата

Use external LM7805 on heat sink


Инв. № подл. Инв. № дубл. Подп. и дата Взам. инв. № Подп. и дата Перв. примен. Справ. №


Инв. № подл. Инв. № дубл. Подп. и дата Взам. инв. № Подп. и дата


Цеп ь | Конт .

Инв. № подл. Инв. № дубл. Подп. и дата Взам. инв. № Подп. и дата


Инв. № подл. Подп. и дата Инв. № дубл. Подп. и дата Взам. инв. №


Инв. № подл. Инв. № дубл. Подп. и дата Взам. инв. № Подп. и дата Перв. примен. Справ. №

*The wires are as short as possible.

*add 1.5k if autogeneration problems

Конт. | Цепь


*See C/I values in SAW datasheet

Инв. № подл. Инв. № дубл. Подп. и дата Взам. инв. № Подп. и дата


*The wires are as short as possible.

*add 1.5k if autogeneration problems

Конт. | Цепь


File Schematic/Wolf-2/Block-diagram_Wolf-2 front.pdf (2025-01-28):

## Font Panel PCB

U5


TFT Controller (DATA | CONTROL)
CODEC

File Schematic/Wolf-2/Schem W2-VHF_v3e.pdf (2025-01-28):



Инв. № подл. Инв. № дубл. Подп. и дата Взам. инв. № Подп. и дата


Инв. № подл. Инв. № дубл. Подп. и дата Взам. инв. № Подп. и дата Перв. примен. Справ. №


Инв. № подл. Инв. № дубл. Подп. и дата Взам. инв. № Подп. и дата

Изм. | Лист | № докум. | Подп. | Дата


Цеп ь | Конт .

Инв. № подл. Инв. № дубл. Подп. и дата Взам. инв. № Подп. и дата


Инв. № подл. Подп. и дата Инв. № дубл. Подп. и дата Взам. инв. №


Инв. № подл. Инв. № дубл. Подп. и дата Взам. инв. № Подп. и дата Перв. примен. Справ. №

Конт. | Цепь


*See C/I values in SAW datasheet

Инв. № подл. Инв. № дубл. Подп. и дата Взам. инв. № Подп. и дата

Изм. | Лист | № докум. | Подп. | Дата


Конт. | Цепь



Comment | Description | Designator | Footprint | LibRef | Quantity
0 | | A0, A1, R25, R26, R27,
R53, R57, R95, R99 | CH0805R | Resistor | 9
10uF | | C1 | CH1206C | Capacitor | | 1
1uF | | C2, C68, C74, C122, C131, C139 | CH0805C | Capacitor | | 6
12p | | C3, C8 | CH0805C | Capacitor | | 2
3p | | C4, C7, C47 | CH0805C | Capacitor | | 3
10p | | C5 | CH0805C | Capacitor | | 1
47uF | | C6 | CH1206C | Capacitor | | 1
100n | | C9, C16, C23, C39, C42, C45, C57, C58, C59, C60, C61, C62, C69, C75, C85, C86, C87, C88, C94, C97, C128, C133, C141, C143, C144, C145 | CH0805C | Capacitor | 26
1n | | C10, C20, C25, C38, C64, C134 | CH0805C | Capacitor | | 6
33pF | | C11, C15, C17 | CH0805C | Capacitor | | 3
100pF | | C12, C18, C21, C24, C26, C28, C30, C34 | CH0805C | Capacitor | | 8
470pF | | C13, C19, C31, C149 | CH0805C | Capacitor | | 4
10pF | | C14, C22, C27 | CH0805C | Capacitor | | 3
330pF | | C29, C32 | CH0805C | Capacitor | | 2
180pF | | C33 | CH0805C | Capacitor | | 1
10n | | C35, C37, C41, C92, C116, C123 | CH0805C | Capacitor | | 6
8p2 | | C36 | CH0805C | Capacitor | | 1
4.7uF | | C40, C89 | CH0805C | Capacitor | | 2
68p | | C43, C49, C104 | CH0805C | Capacitor | | 3
10uF | | C44, C96 | CH0805C | Capacitor | | 2
100p | | C46, C56, C66, C99, C119, C129, C130, C132, C148 | CH0805C | Capacitor | | 9
4.7n | | C48, C78, C110, C111, C120, C137 | CH0805C | Capacitor | | 6
33p | | C50, C51, C52, C53, C54, C55 | CH0603C | Capacitor | | 6
330p | | C63, C67 | CH0805C | Capacitor | | 2
2.2uF | | C65, C135 | CH0805C | Capacitor | | 2
47p | | C70, C72, C76 | CH0805C | Capacitor | | 3
20pF | | C71, C73 | CH0805C | Capacitor | | 2
4.7n | | C77, C121, C138 | CH1206C | Capacitor | | 3
22uF | | C79, C95, C105, C107, C124, C140 | CH1206C | Capacitor | | 6
470p | | C80 | CH1206C | Capacitor | | 1
30p | | C81 | CH1206C | Capacitor | | 1
36p | | C82 | CH1206C | Capacitor | | 1
47p | | C83 | CH1206C | Capacitor | | 1
22p | | C84 | CH1206C | Capacitor | | 1
33p/89p | | C90 | CH0805C | Capacitor | | 1
22p/78p | | C91 | CH0805C | Capacitor | | 1
100p | | C93, C112, C113, C115, C147 | CH0603C | Capacitor | | 5
15p | | C98, C101 | CH0805C | Capacitor | | 2
110p | | C100 | CH0805C | Capacitor | | 1
27p | | C102, C108 | CH0805C | Capacitor | | 2
15p | | C103, C106 | CH0603C | Capacitor | | 2
1uF | | C114 | CH0603C | Capacitor | | 1
1n | | C117 | CH0603C | Capacitor | | 1
2.2uF | | C118 | CH0603C | Capacitor | | 1
100p | | C125 | CH1210C | Capacitor | | 1
100n | | C126, C127 | CH0603C | Capacitor | | 2
220p | | C136 | CH0805C | Capacitor | | 1
470p | | C142 | CH1210C | Capacitor | | 1
PE42641 | | D1, D2 | 16-QFN (3x3) | PE42641 | | 2
BAV99 | | D3, D4, D5, D6 | SOT23_132 | BAV99 | | 4
AMS117-ADJ | | DA1, DA2, DA3 | SOT223 | AMS117 | | 3
BLM21PG121SN1D | | FB1, FB2, FB3 | CH0805L | FB-1 | | 3
BLM21 | | FB4, FB5, FB6 | CH0805L | FB-1 | | 3
IM06 | | K1 | IM06 | IM06-V1 | | 1
G6S-2_DUBL | | K2, K3, K4 | G6S-2_DUBL | G6S-2_DUBL | | 3
0.68uH | | L1, L2, L3 | L1210 | TRANS | | 3
1uH | | L4, L14, L19, L20, L24 | L1210 | TRANS, Inductor ring | | 5
1uH | | L5, L25 | katuhka | Inductor ring | | 2
12nH | | L6, L8 | katuhka | Inductor ring | | 2
10nH | | L7 | katuhka | Inductor ring | | 1
0.047uH | | L9, L10, L11 | L-FNC_V3 | TRANS-1 | | 3
92nH/8nH | | L12, L13 | L1210 | TRANS | | 2
180nH | | L15, L17 | L1210 | TRANS | | 2
22nH | | L16 | L1210 | TRANS | | 1
4.7nH | | L22 | L1210 | TRANS | | 1
1nH | | L23 | L1210 | TRANS | | 1
300 | | R1, R5 | CH1206R | Resistor | | 2
0 / 13.2к | | R2 | CH0805R | Resistor | | 1
NOE / 13.3к | | R3 | CH0805R | Resistor | | 1
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

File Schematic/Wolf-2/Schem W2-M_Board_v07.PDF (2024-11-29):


Инв. № подл. Инв. № дубл. Подп. и дата Взам. инв. № Подп. и дата Перв. примен. Справ. №

Конт. | Цепь

JTAG_9 | 7 | 8

24
25
26

Т.контр. | | Лист | Листов 7
* | | Wolf Teams

Н.контр.

Утв. | UA3REO


Инв. № подл. Инв. № дубл. Подп. и дата Взам. инв. № Подп. и дата Перв. примен. Справ. №

Column I/O 72 Column I/O 71 VCCINT 70 Column I/O 69 Column I/O 68 Column I/O 67 Column I/O 66 Column I/O VREFB4N0 65 Column I/O 64 GND 63 VCCIO4 62 VCCINT 61 Column I/O 60 Column I/O 59 Column I/O 58 GND 57 VCCIO4 56 Dedicated Clock 55 Dedicated Clock 54 Dedicated Clock 53 Dedicated Clock 52 Column I/O 51 Column I/O 50 Column I/O 49 GND 48 VCCIO3 47 Column I/O VREFB3N0 46 VCCINT 45 Column I/O 44 Column I/O 43 Column I/O 42 GND 41 VCCIO3 40 Column I/O 39 VCCINT 38 VCCD_PLL1 37

Wolf2 MainBoard FPGA

* | Лит. | Масса | Масштаб

Изм. | Лист | № докум. | Подп. | Дата

Разраб. | | RU4PN

Пров. | | UA3REO


Инв. № подл. Инв. № дубл. Подп. и дата Взам. инв. № Подп. и дата Перв. примен. Справ. №

ADJ/GND 1

GND

+3V3ATT C61 +3V3RF

Wolf2 MainBoard Power

* | Лит. | Масса | Масштаб

Изм. | Лист | № докум. | Подп. | Дата

Разраб. | | RU4PN

Пров. | | UA3REO


Инв. № подл. Инв. № дубл. Подп. и дата Взам. инв. № Подп. и дата Перв. примен. Справ. №

Vdd 15 | 4 3

Vdd 16 | 4 4

Vdd 17 | 4 5

U12 LTC6400IU V+ V+ I N | VOCM O U T O U T F O U T O U T F V-V-V-

Wolf2 MainBoard ADC

* | Лит . | Масса | Масшта б

. Лист Р азра б . | R U 4 P N

Изм . | № докум . | Подп . | Да т а

Пров . | UA3REO

Т .контр | | | | Лист | Листов

Н .контр .

Утв .


Инв. № подл. Инв. № дубл. Подп. и дата Взам. инв. № Подп. и дата Перв. примен. Справ. №

Wolf2 MainBoard DAC

* | Лит . | Масса | Масшта б

. Лист Р азра б . | R U 4 P N

Изм . | № докум . | Подп . | Да т а

Пров . | UA3REO

Т .контр | | | | Лист | Листов

Н .контр .

Утв .


Инв. № подл. Инв. № дубл. Подп. и дата Взам. инв. № Подп. и дата Перв. примен. Справ. №

Wolf2 MainBoard RF

* | Лит. | Масса | Масштаб

Изм. | Лист | № докум. | Подп. | Дата

Разраб. | | RU4PN

Пров. | | UA3REO


30k

Инв. № подл. Инв. № дубл. Подп. и дата Взам. инв. № Подп. и дата Перв. примен. Справ. №

. Лист Р азра б . | R U 4 P N

Изм . | № докум . | Подп . | Да т а

Пров . | UA3REO

Т .контр | | | | Лист | Листов

Н .контр .

Утв .

Comment | Description | Designator | Footprint | LibRef | Quantity
100n | [NoValue], CAP_0805
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

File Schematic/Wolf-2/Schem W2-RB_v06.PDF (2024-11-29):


Инв. № подл. Инв. № дубл. Подп. и дата Взам. инв. № Подп. и дата Перв. примен. Справ. №

X3 FR 12
Конт . | Цепь

X7 FR 12

R_BOARD - Connectors

* | Лит . | Масса | Масшта б

. Лист Р азра б . | | R U 4 P N

Изм . | | № докум . | Подп . | Да т а

Пров . | | *

Т .контр | | | | | Лист | Листов
* | | | | | Wolf-2

Н .контр .

Утв . | UA3REO


Инв. № подл. Инв. № дубл. Подп. и дата Взам. инв. № Подп. и дата Перв. примен. Справ. №

Конт. | Цепь

Alert 3

SCL 5

R_BOARD - Power

* | Лит. | Масса | Масштаб

Изм. | Лист | № докум. | Подп. | Дата

Пров. | *

Т.контр. | | Лист | Листов 3

Н.контр.

Wolf 2

Утв.


Инв. № подл. Инв. № дубл. Подп. и дата Взам. инв. № Подп. и дата Перв. примен. Справ. №

InR 9

AGND 8

R_BOARD - Audio

* | Лит. | Масса | Масштаб

Изм. | Лист | № докум. | Подп. | Дата

Разраб. | | RU4PN

Пров. | | *

Т.контр. | | | | | Лист | Листов 3

Н.контр.

Wolf 2

Утв.

Line # | Name | Description | Designator | Quantity | Manufacturer 1 | Manufacturer Part Number 1 | Manufacturer Lifecycle 1 | Supplier 1 | Supplier Part Number 1 | Supplier Unit Price 1 | Supplier Subtotal 1
| 1000uF 25v | | C1, C14, C19 | 3
| 100n | | C2, C3, C4, C6, C7, C8, C10, C12, C13, C20, C21, C25 | 12
| 1uF | | C5, C15, C18, C23, C24 | 5
| 10uF | | C9 | 1
| 22uF 25V | | C11 | 1
| 10uF 16v | | C16 | 1
| 100uF 16v | | C17 | 1
| 100uF 16v | | C22 | 1
| AMS1117-3.3v | LDO | D1 | 1
| INA226 | | DA1 | 1
| BLM21 | | FB1, FB2, FB3, FB4 | 4
| PJ-307 | KEY | J1 | 1
| PJ-307 | LIN | J2 | 1
| PJ-307 | OUT_SPEAKERS | J3 | 1
| PJ-307 | PTT_IN | J4 | 1
| PJ-307 | TX | J5 | 1
| HF49FD | | K1 | 1
| 5.6k | | R1, R20 | 2
| 24R | | R2, R3, R4, R5 | 4
| 1M / 0 | | R6 | 1
| NONE / 24R | | R7, R8 | 2
| | | R9 | 1
| 0 | | R10, R11 | 2
| 22R | | R12, R13 | 2
| 10k | | R14, R15, R16, R17, R30, R31 | 6
| 39k | | R18 | 1
| 1k | | R19 | 1
| 30k | | R21, R24, R37, R38 | 4
| 2k | | R22 | 1
| 0R / NONE | | R23 | 1
| 2.2k | | R25, R28 | 2
| 15k | | R26, R27, R35 | 3
| 5.1k | | R29, R32 | 2
| 43k | | R36 | 1
| "Connect" | 6x6mm | SB1 | 1
| ADUM4160BRWZ | Isolator USB | U1 | 1
| LD1117DT50TR | | U2 | 1
| TDA1519 | | U3 | 1
| Bluetoth AC20BP | | U4 | 1
| SMAJ5.0A-TR | | VD1, VD2, VD3, VD4, VD5, VD7 | 6
| 1N4148w | | VD6 | 1
| Blue | | VD8 | 1
| 1N4148W | | VD9 | 1
| NONE / BAT46JFILM | | VD10 | 1
| BSS123 | | VT1, VT2, VT4 | 3
| IRLML9301 | Mosfet | VT3, VT5 | 2
| USB Type-C-m12 | | X1 | 1
| FRONT_MAIN | | X2 | 1
| FRONT_LIN | | X3 | 1
| L_SPEAK | | X5 | 1
| R_SPEAK | | X6 | 1
| FRONT_AUDIO | | X7 | 1
| OUT_13.8V | | X8 | 1


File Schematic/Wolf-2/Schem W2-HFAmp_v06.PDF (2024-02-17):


Инв. № подл. Инв. № дубл. Подп. и дата Взам. инв. № Подп. и дата

Wolf2 - HF Amp - Control | Лист1

Изм . | Лист | № докум . | Подп . | Да т а


Инв. № подл. Инв. № дубл. Подп. и дата Взам. инв. № Подп. и дата

Wolf2 - HF Amp - Amp

Изм. | Лист | № докум. | Подп. | Дата


+LPF_ | 9

Инв. № подл. Инв. № дубл. Подп. и дата Взам. инв. № Подп. и дата

+LPF_ | 9 | | 43

100n GNDGN 9 | 43

W2 - HF AMP - LPF | Лист3

Изм . | № докум . | Подп . | Да т а


Comment | Description | Designator | Footprint | LibRef | Quantity
2000 uF 25v | | C1 | D13C5H20 | AlumCap | | 1
470p | | C2, C8, C13 | CH0805C | Capacitor | | 3
1uF | | C3, C9, C14, C46, C49 | CH0805C | Capacitor | | 5
100n | | C4, C5, C6, C7, C10, C11, C12, C19, C24, C31, C32, C33, C34, C35, C37, C38, C39, C44, C45, C47, C48, C67, C75, C82, C88, C94, C101, C107 | CH0805C | Capacitor | 28
10n | | C15, C29 | CH1210C | Capacitor | | 2
68p | | C16, C28 | CH0805C | Capacitor | | 2
4.7n | | C17 | CH0805C | Capacitor | | 1
1n | | C18, C23 | CH1210C | Capacitor | | 2
15n | | C20, C25 | CH1206C | Capacitor | | 2
100p* | | C21 | CH1210C | Capacitor | | 1
200p* | | C22 | CH1812C | Capacitor | | 1
27p | | C26 | CH0805C | Capacitor | | 1
2.2uF | | C27 | CH1206C | Capacitor | | 1
1n5 | | C30 | CH1206C | Capacitor | | 1
1n | | C36 | CH0805C | Capacitor | | 1
15n | | C40, C41, C42, C43 | CH0805C | Capacitor | | 4
68p* | | C50, C57 | CH1206ATC | Capacitor | | 2
100n | | C51, C58 | CH1210C | Capacitor | | 2
100p | | C52 | CH1812C | Capacitor | | 1
470p* | | C53 | CH1812C | Capacitor | | 1
470p | | C54 | CH1206C | Capacitor | | 1
10n | | C55 | CH1206C | Capacitor | | 1
100n | | C56, C59, C60, C73, C74, C81 | CH1206C | Capacitor | | 6
1n | | C61 | CH1206C | Capacitor | | 1
10p | | C62, C63 | CH1206ATC | Capacitor | | 2
22p | | C64, C66 | CH1206ATC | Capacitor | | 2
82p | | C65 | CH1206ATC | Capacitor | | 1
39p | | C68, C69, C84 | CH1206ATC | Capacitor | | 3
68p | | C70, C72 | CH1206ATC | Capacitor | | 2
180p | | C71, C85, C87 | CH1206ATC | Capacitor | | 3
33p | | C76, C77 | CH1206ATC | Capacitor | | 2
100p | | C78, C80, C89, C90 | CH1206ATC | Capacitor | | 4
240p | | C79 | CH1206ATC | Capacitor | | 1
15p | | C83 | CH1206ATC | Capacitor | | 1
390p | | C86, C91, C93, C99 | CH1206ATC | Capacitor | | 4
680p+82p | | C92 | CH1206ATC | Capacitor | | 1
150p | | C95, C96 | CH1206ATC | Capacitor | | 2
680p | | C97, C100 | CH1206ATC | Capacitor | | 2
1n | | C98 | CH1206ATC | Capacitor | | 1
220p | | C102 | CH1206ATC | Capacitor | | 1
270p | | C103 | CH1206ATC | Capacitor | | 1
820p | | C104, C106 | CH1206ATC | Capacitor | | 2
1n+1n | | C105 | CH1206ATC | Capacitor | | 1
BAV99 | | D1 | SOT23_132 | BAV99 | | 1
SN74LS145DR | | DA1 | 16-SOP | SN74LS145N | | 1
BLM21 | | FB1, FB2 | CH0805L | FB-1 | | 2
Jumper_2 | Jumper | JMP1, JMP2 | CON: JUMPER_2 | Jumper_2 | | 2
G6S-2-DC12 | | K1, K2, K3, K4, K5, K6, K7, K8, K9, K10, K11, K12, K13, K14, K15 | G6S-2-DC12 | G6S-2-12VDC | 15
0,022uH | | L1 | CH1210L | Inductor-2 | | 1
10uH | | L2, L3 | IND: R24 | Inductor ring | | 2
0.12uH | | L4, L5 | DR1 | Inductor ring | | 2
0.2uH | | L6, L7 | DR1 | Inductor ring | | 2
0.3uH | | L8, L9 | T68-0 | Inductor ring | | 2
0.65uH | | L10 | T68-0 | Inductor ring | | 1
0.6uH | | L11 | T68-0 | Inductor ring | | 1
1.15uH | | L12, L13 | T68-0 | Inductor ring | | 2
2.3uH | | L14, L15 | T68-0 | Inductor ring | | 2
4.5uH | | L16, L17 | T68-0 | Inductor ring | | 2
4.7K | | R1, R4, R9, R12, R15, R18, R21, R24 | CH0805R | Resistor | | 8
3K | | R2, R6, R10, R13, R16, R19, R22 | CH0805R | Resistor | | 7
30k | | R3, R7, R11, R14, R17, R20, R23 | CH0805R | Resistor | | 7
560 | | R5 | CAT16 | CAT10-0804 | | 1
1K KTY81/110 | | R8 | CON: PBS-2 | NTC | | 1
2K | | R25, R47 | CH2512R | Resistor | | 2
4.7 | | R26, R27, R42, R44, R50, R51, R54, R69, R71, R72 | CH2512R | Resistor | 10
100 | | R28, R43, R59, R61 | CH0805R | Resistor | | 4
47 | | R29, R31, R41, R45 | CH0805R | Resistor | | 4
750* | | R30, R37 | CH1206R | Resistor | | 2
10 | | R32, R75, R76 | CH0805R | Resistor | | 3
68 | | R33 | CH0805R | Resistor | | 1
1K | | R34, R36 | CH0805R | Resistor | | 2
100 | | R35 | CH2512R | Resistor | | 1
10K NTC | | R38 | CON: PBS-2 | NTC | | 1
91 | | R39, R40 | CH0805R | Resistor | | 2
10K | | R46, R55, R56, R57, R58 | RES: 3296W | ADJ resistor | | 5
330 | | R48, R49 | CH0805R | Resistor | | 2
750 | | R52, R53 | CH0805R | Resistor | | 2
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

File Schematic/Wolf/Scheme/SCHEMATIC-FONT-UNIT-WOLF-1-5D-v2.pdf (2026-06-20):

10 10 11 11 12 12 13 13 14 14 15 15 16 16 17 17 18 18 19 19 20 20 21 21 22 22 23 23 24 24 25 25 26 26 27 27 28 28 29 29 30 30 31 31 32 32 33 33 34 34 35 35 36 36 37 37 38 38 39 39 40 40 41 41 42 42 43 43 44 44 45


GND 26 SIFS1 27 SIFS0 28 KOUT3/GPIO3 29 KOUT2/GPIO2 30 KOUT1/GPIO1 31 KOUT0/GPIO0 32 KIN4/GPI4 33 KIN3/GPI3 34 KIN2/GPI2 35 KIN1/GPI1 36 KIN0/GPI0 37 CORE_VDD 38 GND 39 VDDP 40 SCS# 41 SDO 42 SDI 43 SCL 44 GPIX 45 GPOX 46 HSYNC 47 VSYNC 48 PCLK 49 DE 50 PDAT0 51 PDAT1 52 PDAT2 53 PDAT3 54 PDAT4 55 PDAT5 56 PDAT6 57 PDAT7 58 PDAT8 59 LDO_OUT 60 LDO_GND ⁶¹ VDDP ⁶² PDAT9 63 PDAT10 64 PDAT11 65 PDAT12 66 PDAT13 67 PDAT14 68 PDAT15 69 ADC_GND ⁷⁰ ADC_VREF 71 XN ⁷² YP ⁷³ YN ⁷⁴ XP ⁷⁵

Schematic | Schematic1 | Create at | 2026-05-15

Update at | 2026-05-26

Board | Board1 | Page | P1
Drawn | | W1-5.5_front
Reviewed

Version | Size | Page 1 Total 3
V1.0 | A4 | EasyEDA.com


CS#/SHDN 10 DIN 11 DOUT 12 CLK 13 AGND 14 VREF 15 VDD 16

Schematic | Schematic1 | Create at | 2026-05-26

Update at | 2026-05-26

Board | Board1 | Page | P2
Drawn | | W1-5.5_front
Reviewed


Schematic | Schematic1 | Create at | 2026-05-26

Update at | 2026-05-26

Board | Board1 | Page | P3
Drawn | | W1-5.5_front
Reviewed

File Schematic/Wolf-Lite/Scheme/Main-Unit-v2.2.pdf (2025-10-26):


Инв. № подл. Инв. № дубл. Подп. и дата Взам. инв. № Подп. и дата Перв. примен. Справ. №

Net_DAC9 OUT_TX Net_DAC-PD RX/TX | | Net_DAC9 Net_DAC-PD

LTC_ENABLE Net-bit7 Net-bit2 Net-bit10 Net-bit6 Net-bit4 Net-bit3 Net-bit1 Net-bit5 Net-bit9 Net-otr Net-bit8 Net-bit11 Net-Clock Net-bit12 FPG_CTRL LPF3 BPF_OE2 LPF1 BPF_A BPF_B LPF2 BPF_OE1

RX/TX | U_WL-ATT

MUTE SWR_FORW WM8731_BCLK SWR_BACKW WM8731_SCK WM8731_WS_LRC KEY_IN_DOT KEY_IN_DASH WM8731_DAC_SD WM8731_ADC_SD WM8731_SDA

Designator WL-CONNECT.SchDoc

Wolf-Lite

WOLF-LITE Схема электрическая принципиальная | Лит. | Масса | Масштаб

Изм. | Лист | № докум. | Подп. | Дата | | * | | | 1:1
Разраб. | | UA3REO/R7KBI
Пров. | | *
Т.контр. | * | | | | Лист | Листов 12

Н.контр. | *
Утв. | *


Инв. № подл. Инв. № дубл. Подп. и дата Взам. инв. № Подп. и дата Перв. примен. Справ. №

14 | 18
24 | 19

12 | 17
23 | 15
22 | 28
10 | 30
11 | 27
32 | 298
33


Инв. № подл. Инв. № дубл. Подп. и дата Взам. инв. № Подп. и дата Перв. примен. Справ. №

13579 | 108642 X2 Jtag | +3.3V | 2 | SO | HOLD | 7

nCE | | VDD

TDI TMS TDO TCK

VCC102 26
VCC103 40

VCC103 47
VCC104 56
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

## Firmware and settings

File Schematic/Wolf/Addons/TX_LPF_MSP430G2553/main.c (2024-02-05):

/*Control the addon QRP-LPF board in transceiver "Wolf"
 *
 *Autor: Tihomir Angelov
 *
 *Info:
 *From the transceiver are coming the 4 BAND signals and the PTT
 *the filter is selected only when the PTT is active to reduce the power consumption
 *
 *4 LPF bands are realized and 1 direct (for the VHF bands)
 *
 */


#include <msp430.h> 


/*
* DEFINE PINS
*/

//Inputs (BCD code)
#define BND_0 BIT0
#define BND_1 BIT1
#define BND_2 BIT2
#define BND_3 BIT3

//PTT input
#define PTT BIT4

//Outputs (to the relays)
#define Range1 BIT0
#define Range2 BIT1
#define Range3 BIT2
#define Range4 BIT3
#define Range5 BIT4



//Functions declarations
int Delay (int i);
void Init_Pins (void);


/**
 * main.c
 */
int main(void)
{
    char ReadData = 0;

	WDTCTL = WDTPW | WDTHOLD;	// stop watchdog timer
	
	Delay(100);

	Init_Pins ();                           //Initialize the pins



    while (1)
    {
       // read PORT 2 byte
        ReadData = 15 - (P2IN & 0xF);      // read PORT 2 byte and take in to acount only the lower 4 bits (band data coming from the transceiver)

        if (!(P2IN & PTT))                   //PTT is active
            {

            if (ReadData < 2)               //<80m - direct connection
                {
                P1OUT &= ~Range1; //Set range 1 LOW
                P1OUT &= ~Range2; //Set range 2 LOW
                P1OUT &= ~Range3; //Set range 3 LOW
                P1OUT &= ~Range4; //Set range 4 LOW
                P1OUT |= Range5;  //Set range 5 HIGH
                }
            else if (ReadData == 2)         //80m LPF
                {
                P1OUT |= Range1;  //Set range 1 HIGH
                P1OUT &= ~Range2; //Set range 2 LOW
                P1OUT &= ~Range3; //Set range 3 LOW
                P1OUT &= ~Range4; //Set range 4 LOW
                P1OUT &= ~Range5; //Set range 5 LOW
                }
            else if (ReadData == 4)          //40m LPF
                {
                P1OUT &= ~Range1; //Set range 1 LOW
                P1OUT |= Range2;  //Set range 2 HIGH
                P1OUT &= ~Range3; //Set range 3 LOW
                P1OUT &= ~Range4; //Set range 4 LOW
                P1OUT &= ~Range5; //Set range 5 LOW
                }
            else if  ((ReadData == 5)||(ReadData == 6))          //30m and 20m  LPF
                {
                P1OUT &= ~Range1; //Set range 1 LOW
                P1OUT &= ~Range2; //Set range 2 LOW
                P1OUT |= Range3;  //Set range 3 HIGH
                P1OUT &= ~Range4; //Set range 4 LOW
                P1OUT &= ~Range5; //Set range 5 LOW
                }
            else if  ((ReadData > 6)&&(ReadData < 12))          //17/15/12/10m LPF
                {
                P1OUT &= ~Range1; //Set range 1 LOW
                P1OUT &= ~Range2; //Set range 2 LOW
                P1OUT &= ~Range3; //Set range 3 LOW
                P1OUT |= Range4;  //Set range 4 HIGH
                P1OUT &= ~Range5; //Set range 5 LOW
                }
            else                                                // rest direct connection
                {
                P1OUT &= ~Range1; //Set range 1 LOW
                P1OUT &= ~Range2; //Set range 2 LOW
                P1OUT &= ~Range3; //Set range 3 LOW
                P1OUT &= ~Range4; //Set range 4 LOW
                P1OUT |= Range5;  //Set range 5 HIGH
                }
            }
        else                                                    //PTT is released
            {
            P1OUT &= ~Range1; //Set range 1 LOW
            P1OUT &= ~Range2; //Set range 2 LOW
            P1OUT &= ~Range3; //Set range 3 LOW
            P1OUT &= ~Range4; //Set range 4 LOW
            P1OUT &= ~Range5; //Set range 5 LOW
            }
    }


}

void Init_Pins (void)
{
    P1DIR |= Range1;  //Set as an Output pin
    P1DIR |= Range2;  //Set as an Output pin
    P1DIR |= Range3;  //Set as an Output pin
    P1DIR |= Range4;  //Set as an Output pin
    P1DIR |= Range5;  //Set as an Output pin

    P1OUT &= ~Range1; //Set LOW
    P1OUT &= ~Range2; //Set LOW
    P1OUT &= ~Range3; //Set LOW
    P1OUT &= ~Range4; //Set LOW
    P1OUT &= ~Range5; //Set LOW

    P2REN |= BND_0;                   // Enable internal pull-up/down resistors
    P2OUT |= BND_0;                    //Select pull-up mode

    P2REN |= BND_1;                   // Enable internal pull-up/down resistors
    P2OUT |= BND_1;                    //Select pull-up mode

    P2REN |= BND_2;                   // Enable internal pull-up/down resistors
    P2OUT |= BND_2;                    //Select pull-up mode

    P2REN |= BND_3;                   // Enable internal pull-up/down resistors
    P2OUT |= BND_3;                    //Select pull-up mode

    P2REN |= PTT;                   // Enable internal pull-up/down resistors
    P2OUT |= PTT;                    //Select pull-up mode

}

int Delay (int i)
{
    int Count;
    Count=i*100;            //
    while(Count>=0)
        {Count--;}
    return(1);
}

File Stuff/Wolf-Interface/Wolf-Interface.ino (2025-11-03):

/*
  Wolf Interface Example Project

  This sketch demonstrates basic functionality for develop user-space devices, which communicates with TRX Wolf

  https://github.com/XGudron/UA3REO-DDC-Transceiver
*/

#include "Wolf.h"

// the setup function runs once when you press reset or power the board
void setup() {
	Serial.begin(115200); // enable serial port for debugging

	WOLF_init(); // init TRX Wolf communication
}

// the loop function runs over and over again forever
void loop() {
	Serial.println("TRX Info:");
	Serial.println("Current VFO: " + String(TRX_WOLF.CurrentVFO == TRX_SELECTED_VFO_A ? "A" : "B"));
	Serial.println("VFO A Frequency: " + String(TRX_WOLF.VFO_A_Frequency));
	Serial.println("VFO A Mode: " + WOLF_modeToString(TRX_WOLF.VFO_A_Mode));
	Serial.println("VFO A Mode is CW? " + String(TRX_WOLF.VFO_A_Mode == TRX_MODE_CW ? "Yes" : "No"));
	Serial.println("VFO B Frequency: " + String(TRX_WOLF.VFO_B_Frequency));
	Serial.println("VFO B Mode: " + WOLF_modeToString(TRX_WOLF.VFO_B_Mode));
	Serial.println("In TX? " + String(TRX_WOLF.TX ? "Yes" : "No"));
	Serial.println("In Tune? " + String(TRX_WOLF.Tune ? "Yes" : "No"));

	String CAT_Answer = WOLF_catCommand("SM2"); // run CAT command and get answer
	Serial.println("CAT Answer (S-Meter dBm RX1): " + CAT_Answer);

	WOLF_setMessage("Hello World! " + String(millis()) + " " + CAT_Answer); // set message over FFT, may be disabled if not set

	Serial.println("---");

	delay(1000);
}

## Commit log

2024-02-05 9.4.0 version
    [16-SOIC_MCP3008-I_SL.x_t, 20mm_Main_Encoder.stl, 20mm_Sec_Encoder.stl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]
2024-02-14 New Wolf-Lite front panels
    [BOT-LITE.SLDPRT, BOT-LITE.STL, Front Lite V1.1.STL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]
2024-02-17 Update wolf-2 schematics
2024-02-26 Add motherboard heatsink
    [HeatSink.SLDPRT]
2024-04-20 Update W-Lite board
    [WL-AD9226.SchDoc, WL-CONNECT.SchDoc, WL-CPU-V1.0.SchDoc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]
2024-12-12 11.0.0 Release
    [DK-102_AD_DA_V01_240415.xls, DK-102_MB_V01_240415.xls, DK-102_PA_BOM_240821.xlsx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]
2024-12-13 Clean deprecated instructions
    [Front-Panel-3.5.xlsx]
2025-04-07 Update W-Lite files
    [WL-AD9226.SchDoc, WL-AUDIO.SchDoc, WL-CONTROL.SchDoc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]
2025-05-02 12.5.0 Release
    [WOLF MIAN 11-3 BOM.xls, WOLF_PA 11-3 BOM.xls]
2026-06-05 fix schematic files
2026-10-29 RX3PX BPF Board
